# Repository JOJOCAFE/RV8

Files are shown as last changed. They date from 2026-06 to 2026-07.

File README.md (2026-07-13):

# RV8 Project: Minimal 8-bit RISC-V Style CPU Family

Build real computers from 74HC chips. Run BASIC. Play games.

---

## The Family

| | **RV8** | **RV8-R** | **RV8-G** | **RV8-GR** |
|--|:---:|:---:|:---:|:---:|
| **Logic chips** | 28 | **49 FullHW** | **38** | **34** |
| **Total** | 31 | 53 | 40 | 36 |
| **MIPS @5MHz** | 1.25 | 1.0 | **2.5** | **0.33*** |
| **ISA** | Full target, not frozen | FullHW RV8-style surface | Full (35) | 18 instr |
| **Microcode** | Yes | Yes | **No** | **No** |
| **AND/OR/XOR** | ✅ | ✅ | ✅ | XOR only |
| **64K address** | ✅ | ✅ | ✅ | ✅ |
| **ROM-first boot** | ✅ | ✅ | ✅ | **✅** |
| **Games** | ✅ | ✅ | ✅ | ✅ |
| **Verilog verified** | ⚠️ behavioral only / benches need cleanup | ⚠️ old-map RTL pass; frozen-map pending | ⬜ | **✅** |

\* RV8-GR: official student baseline is 1 MHz breadboard. 0.33 MIPS @ 1 MHz.

---

## Which to build?

| Priority | Build |
|---|---|
| **Learn microcode / experimental reference** | **RV8** (28 chips target, not build-ready) |
| **Full RV8-style ISA with real TTL paths** | **RV8-R FullHW** (49 logic chips, KiCad/RTL proof pending) |
| **Full ISA + no microcode concept** | **RV8-G** (38 logic chips, no active folder) |
| **Student-friendly no-microcode build** | **RV8GR** (34 logic chips) |

### RV8GR Student Baseline

RV8GR is the active physical-build target.

- 34 logic chips + ROM + RAM = 36 packages.
- Components package mapping checked: 36 board packages resolve to 16
  board-used part types, all backed by current Components definitions and
  package-local test records.
- No microcode ROM.
- No hardware IRQ vector; IRQ is a polling latch only.
- Every instruction uses T0, T1, T2.
- Build one module, test it, then continue.
- Start with `RV8GR/doc/labs/README.md` for student labs.
- Use `RV8GR/doc/01_wiring_guide.md` as the official pin-level source.
- Latest lab/doc pass keeps U34 as the 74HC541 IRL-to-IBUS immediate buffer,
  ROM as `ROM1`, and RAM as `RAM1`.
- Physical speed/signoff is still blocked until real voltage, clock,
  bus-deadband, memory float/write timing, and scope evidence are logged.

### RV8 vs RV8-R Analysis

| Area | RV8 | RV8-R |
|---|-----|---|
| Current role | Exploratory microcoded reference | FullHW full-ISA TTL path candidate |
| Chip-count confidence | ⚠️ Docs disagree between 27/28/31 package claims | ✅ FullHW count documented as 49 logic / 53 total |
| ISA confidence | ⚠️ Full 35-instruction target, but generator contains simplified/skipped operations | ✅ FullHW gives real paths for ALU logic, stack, IRQ, and IRET; `SRL` remains software macro |
| Verification | ⚠️ Behavioral Verilog exists; microcode benches need cleanup before claiming pass | ⚠️ FullHW docs updated; RTL/testbench/microcode generator migration pending |
| Microcode tools | ⚠️ Generator exists but has simplified branch/addressing/logic paths | ⚠️ Existing generator is legacy 14-bit; FullHW needs 15-bit direct-control generator |
| Wiring | ⚠️ Pin-level guide exists but is tied to stale chip-count/control assumptions | ✅ FullHW wiring paths documented; Programmer/RV8-Bus pin audit still required |
| Build readiness | Not ready for student physical build | Not ready for physical build until KiCad/ERC and sim proof |

**Decision:** keep RV8 as a learning/reference branch, but do not present it as proven. Use RV8-R FullHW when the goal is to make the full RV8-style ISA real in TTL, and use RV8GR when the goal is a student-buildable physical CPU today.

---

## Project Structure

```
RV8/
├── RV8/            ← 28-chip target, hardware regs, microcode, IRQ (exploratory)
├── RV8R/           ← 49-chip FullHW target, RAM regs, microcode, IRQ (full RV8-style hardware)
├── RV8GR/          ← active 34-logic-chip student baseline, labs, wiring, sim, RTL
├── Programmer/     ← ESP32 board; per-CPU bus/pin audit required
├── Old_Design/     ← Archived
├── Reference/      ← Gigatron, SAP-1, Nand2Tetris
└── README.md
```

`RV8-G` is retained as a documented concept/history item, not as an active
folder in this checkout.

---

## Shared Across All

- **RV8-Bus**: 40-pin system bus target (A[15:0] + D[7:0] + CLK + /WR + /RD + /IRQ + /SLOT)
- **Programmer**: ESP32-WROOM-32 + TXS0108E (flash + terminal); compatibility must be checked per CPU wiring guide
- **Registers**: Variant-specific RAM window. RV8R freezes `r0-r7` at `$FFF8-$FFFF`; RV8GR uses its own data-page model.
- **RISC-V naming**: ADD, SUB, LB, SB, BEQ, J

---

## Status

| | RV8 | RV8-R | RV8-G | RV8-GR |
|--|:---:|:---:|:---:|:---:|
| Instruction trace | ✅ | ✅ | ⬜ | ✅ |
| Verilog | ⚠️ benches need cleanup | ⚠️ old-map RTL passed; FullHW RTL pending | ⬜ | ✅ (behavioral + chip-level TBs, 512 opcode sweep) |
| Wiring guide (pin-level) | ⚠️ stale assumptions | ✅ FullHW paths documented | ⬜ | ✅ |
| Module guide (Thai) | ✅ | ⬜ | ⬜ | ✅ |
| ISA reference | ⚠️ target ISA, not fully proven | ✅ FullHW encoding + hardware paths | ⬜ | ✅ |
| Assembler | ⬜ | ⬜ | ⬜ | ✅ (page-safe) |
| Test ROM | ⬜ | ⬜ | ⬜ | ✅ |
| Hardware Labs | ⬜ | ⬜ | ⬜ | ✅ (14 labs + student baseline contract) |
| KiCad modules | ⬜ | ⬜ | ⬜ | ✅ (6 modules) |
| Student build guardrails | ⬜ | ⬜ | ⬜ | ✅ |
| Components package mapping | ⬜ | ⬜ | ⬜ | ✅ (36 packages -> 16 part types) |
| Programmer | ⚠️ needs bus/pin audit | ⚠️ needs bus/pin audit | ⚠️ needs bus/pin audit | ✅ |
| Physical build | ⬜ | ⬜ | ⬜ | ⬜ |

### Latest RV8GR Checkpoint

As of 2026-07-12, RV8GR release gates fail hard on behavioral Verilog or
wiring mismatches. The full external Components run passes the 16 part-type,
36-package audit and the whole-system virtual fault screen with no pin-truth,
edge-polarity, bus-contention, or propagation-deadband findings. Hardware
timing claims still require physical measurements on the real board.

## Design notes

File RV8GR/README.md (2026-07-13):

# RV8-GR — No Microcode, Full 64K, IRQ (Stable)

**34 logic chips + ROM + RAM = 36 packages. Verilog verified.**

---

## Student Baseline Contract

This is the build target for RV8GR. Do not add future features while
building the baseline CPU.

- **34 logic chips + ROM + RAM = 36 packages**
- **No microcode ROM**
- **No hardware IRQ vector**: IRQ is a polling latch only
- **Every instruction is 3 phases**: T0 fetch opcode, T1 fetch operand, T2 execute
- **Only one IBUS driver may be active at a time**
- **Only one DBUS driver may be active at a time**
- **Build one module, test it, then continue**

Recommended reading order:

| Role | Start here | Use for |
|---|---|---|
| Student | `doc/labs/README.md` | Lab-by-lab physical build |
| Teacher | `doc/build_plan/01_student_incremental_build_plan.md` | Supervised stage plan |
| Wiring | `doc/01_wiring_guide.md` | Official pin-level source of truth |
| Debug | `doc/05_debug_plan.md` | Probe points and fault tracing |
| KiCad | `doc/06_kicad_modules.md` | Schematic sheet/module split |
| CPU logic test | `doc/08_cpu_logical_test_protocol.md` | Virtual CPU behavior and program regression |
| Equivalence | `doc/11_four_model_equivalence.md` | Why two Python sims and two Verilog models must agree |
| Doc audit | `doc/12_doc_integrity_audit.md` | Integrity check of every doc file against Python/Verilog truth |
| BASIC ROM test | `doc/13_basic_min_rom.md` | B-011 phase 1 BASIC-style ROM smoke test |

---

## Specs

| Spec | Value |
|---|---|
| Logic chips | 34 (74HC series, DIP) |
| Total packages | 36 (34 logic + ROM + RAM) |
| ISA | 18 instructions |
| Clock | 1 MHz breadboard baseline; 5 MHz PCB-only measured experiment |
| Speed | 333K instr/sec @ 1 MHz |
| Gate count | ~1,260 (logic only, excl. ROM/RAM) |
| Address | 64KB (ROM $0000-$7FFF, RAM $8000-$FFFF) |
| Bus | RV8-Bus 40-pin (A16+D8+control) |
| Registers | 8 in RAM ($8000-$8007 via DP=$80) |
| ALU | ADD, SUB, XOR |
| Jump | 16-bit (Page Register) |
| Execute RAM | Yes (PC ≥ $8000) |
| IRQ | v1.0: polling latch; hardware vector is future/unfrozen |

---

## ISA (18 instructions)

```
$00  NOP         $01  J addr       $02  BEQ addr
$04  SB addr     $08  EI           $10  ADDI imm
$18  ADD rs      $20  SETPG imm    $28  SETPG_R rs
$30  LI imm      $38  LB rs        $40  SETDP imm
$48  DI           $70  XORI imm    $78  XOR rs
$82  BNE addr    $90  SUBI imm     $98  SUB rs
```

Encoding: `[7]SUB [6]XOR [5]MUX [4]AC_WR [3]SRC [2]STR [1]BR [0]JMP`

Note: `$48 DI` is encoded as one of the 18 mnemonics, but is reserved/inert in v1.0; IE clears only on reset.

Assembler pseudo-instructions such as `NOT` do not add hardware opcodes. `NOT`
emits `XORI $FF` and is covered by Python and Verilog ROM tests.

---

## BOM — Complete Order List

### Logic (34 packages)

| Part | Qty | Package | Notes | Status |
|---|:---:|:---:|---|:---:|
| 74HC161 | 4 | 16DIP | PC counter | ✅ |
| 74HC574 | 5 | 20DIP | IR, AC, PG, DP | ✅ |
| 74HC245 | 1 | 20DIP | Bus buffer | ✅ |
| 74HC164 | 1 | 14DIP | Ring counter | ✅ |
| 74HC283 | 2 | 16DIP | Adder | ✅ |
| 74HC86 | 3 | 14DIP | XOR | ✅ |
| 74HC541 | 2 | 20DIP | AC buffer + IRL immediate buffer | ✅ |
| 74HC157 | 8 | 16DIP | Muxes | ✅ |
| 74HC74 | 2 | 14DIP | Z flag, IRQ | ✅ |
| 74HC688 | 1 | 20DIP | Zero detect | ✅ |
| 74HC04 | 1 | 14DIP | Inverters | ✅ |
| 74HC32 | 1 | 14DIP | OR gates | ✅ |
| 74HC00 | 2 | 14DIP | NAND gates | ✅ |
| 74HC21 | 1 | 14DIP | SETDP decode | ✅ |

### Memory

| Part | Qty | Notes | Status |
|---|:---:|---|:---:|
| AT28C256-70 or SST39SF010A-70 | 1 | ROM 32KB, 70ns | waiting |
| 62256-70 (or AS6C62256) | 1 | RAM 32KB, 70ns | waiting |

### Clock & Reset

| Part | Qty | Notes | Status |
|---|:---:|---|:---:|
| 1 MHz 5V CMOS oscillator module | 1 | Baseline breadboard clock | waiting |
| 5 MHz 5V CMOS oscillator module | optional | PCB/wire-wrap experiment only | waiting |
| 74HC14 Schmitt inverter | 1 | Clock/reset buffering | waiting |
| 10kΩ resistor | 1 | Reset pull-up | waiting |
| 10µF capacitor | 1 | Reset RC | waiting |
| Push button (NO) | 1 | Reset button | waiting |

### Passives & Debug

| Part | Qty | Notes | Status |
|---|:---:|---|:---:|
| 100nF capacitor (ceramic) | 35 | Bypass (1 per chip) | waiting |
| 10µF capacitor | 2 | Power filter | waiting |
| 330Ω resistor | 8 | LED current limit | waiting |
| LED 3mm green | 8 | Bus probe | waiting |
| LED 3mm red | 1 | Power | waiting |
| DIP switch 8-bit | 1 | Debug input | waiting |

### Breadboard & Wiring

| Part | Qty | Notes |
|---|:---:|---|
| Full-size breadboard (830pt) | 5 | Layout below |
| Jumper wire kit (M-M) | 1 | 65pc assorted |
| 22AWG solid wire (6 colors) | 1 set | Bus wiring |
| 40-pin IDC socket + ribbon | 1 | RV8-Bus |
| USB 5V breadboard PSU | 1 | Power supply |

---

## Breadboard Layout (5 boards)

```
Board 1: TIMING          Board 2: MEMORY         Board 3: ALU
┌──────────────────┐    ┌──────────────────┐    ┌──────────────────┐
│ U8  U24          │    │ U15 U16 U29 U30 │    │ U5 U6 U34 U14  │
│ U1  U2  U3  U4  │    │ ROM         RAM  │    │ U19 U20         │
│ Osc     Reset    │    │ U7               │    │ U12 U13         │
└──────────────────┘    └──────────────────┘    │ U10 U11         │
  6 chips                 7 chips               └──────────────────┘
                                                  9 chips

Board 4: CONTROL         Board 5: BUS + DEBUG
┌──────────────────┐    ┌──────────────────┐
│ U17 U18 U9      │    │ 40-pin IDC       │
│ U21 U22 U23     │    │ 8× LED probe     │
│ U25 U26 U27 U28│    │ DIP switch       │
│ U31 U32 U33     │    │ Power rails      │
└──────────────────┘    └──────────────────┘
  12 chips                Debug tools
```

### Wiring Color Convention

| Color | Signal |
|---|---|
| Red | VCC (+5V) |
| Black | GND |
| Yellow | DBUS D[7:0] |
| Blue | IBUS IB[7:0] |
| Green | ABUS A[15:0] |
| White | Control |
| Orange | Clock/Timing |

---

## Verification

Run these checks before using the docs for a build session. Python checks are
the student-friendly first pass because they catch wiring and behavior errors
without requiring HDL tools:

```bash
cd RV8GR

python3 -B sim/chip_sim.py
# ALL 8 CPU TESTS PASSED

python3 -B sim/components_chip_sim.py
# ALL 8 COMPONENTS-BACKED CPU TESTS PASSED

python3 -B sim/test_cpu_logical_protocol.py
# protocol unittest suite passes on both Python CPU simulators

python3 -B sim/test_basic_min.py
# B-011 BASIC-style ROM smoke passes on both Python CPU simulators

python3 -B tools/check_python_verilog_equivalence.py
# both Python CPU simulators match both Verilog CPU models on all_isa_equivalence.asm

python3 -B sim/verify_wiring.py
# ALL WIRING VERIFIED

python3 -B sim/soft_debug.py
# ALL TESTS PASSED

python3 -B tools/test_rv8gr_asm.py
# 11 passed

python3 -B sim/chips/test_chips.py
# ALL 14 CHIP TYPES VERIFIED

python3 -B sim/verify_components.py
# RV8GR Components verification passed: 16 part types, 36 packages
```

To verify against the current external Components library rather than the
vendored compatibility snapshot:

```bash
cd RV8GR
COMPONENTS_ROOT=/home/jo/kiro/Components python3 -B sim/verify_components.py
# RV8GR Components verification passed: 16 part types, 36 packages
```

Run the reusable Components virtual physical checker from the Components repo.
This checks the RV8GR whole-system virtual circuit for pin mistakes, active-low
mistakes, unsafe output-output wiring, and documented timing/noise risks:

```bash
cd /home/jo/kiro/Components
PYTHONPATH=python python3 -B -m chiplib.cli circuit-faults examples/circuits/RV8GR_WholeSystemChipLevelVirtual/circuit.json
# pass: no pin-truth, edge-polarity, output-contention, or deadband findings
```

This virtual check passed against the current external Components checkout on
2026-07-12. It is a model-level gate only; it does not replace physical-board
measurements for reset release, bus turnaround, memory timing, or voltage
margin.

Use Verilog as the secondary HDL/RTL comparison path:

```bash
cd RV8GR
COMPONENTS_ROOT=/home/jo/kiro/Components tools/run_all_verilog_tb.sh
# behavioral, opcode sweep, SETDP, task, IRQ, chip-level, and dual-compare
# benches pass; detected behavioral mismatches exit nonzero
```

The behavioral `rtl/rv8gr_cpu.v` benches are only a comparison path. RV8GR
Verilog signoff must include the TTL-chip system:

- `rtl/rv8gr_chip_level.v` is the chip-level netlist.
- `tools/run_chip_level_verilog.sh` and
  `tools/run_chip_level_full_verilog.sh` compile it with the Components
  `ttl_74hc*`, `62256`, and `at28c256` Verilog models.
- `tools/run_dual_verilog_compare.sh` runs `rv8gr_cpu.v` and
  `rv8gr_chip_level.v` on the same ROM program and compares architectural
  checkpoints: `PC`, `AC`, `Z`, `PG`, `DP`, `IE`, `IRQ_FF`, and key RAM
  writes. This dual bench covers every frozen ISA command at least once,
  including jump/branch, ALU, memory, page/data-page control, and IRQ polling.
- `programs/all_isa_equivalence.asm` is the shared all-ISA source for this
  comparison. Verilog assembles it to `.memh`; Python assembles the same source
  in memory through `tools/check_python_verilog_equivalence.py`.
- `tb_rv8gr_dual_compare.v` exports `VERILOG_CHECKPOINT` lines, and
  `tools/check_python_verilog_equivalence.py` verifies both Python CPU sims
  match that checkpoint stream, final state, and RAM checkpoints.
- `sim/components_chip_sim.py` is a Components-backed adapter runner for the
  same RV8GR Python CPU logic, not a separate net-level Python CPU algorithm.
- Do not replace this signoff with an optimized gate/behavioral model.

Generated Verilog artifacts default to `/tmp/rv8gr-verilog`. Set
`RV8GR_BUILD_DIR=/path/to/output` if you need a different generated-output
directory.

Virtual checks, Python simulation, and Verilog comparison are not physical
signoff. Physical signoff still requires the real board to show correct power
rails, reset, clock, bus ownership, ROM/RAM behavior, a 1 MHz baseline
full-system run, burn-in stability, and timing evidence from probes or a logic
analyzer. A 5 MHz result is optional PCB-only experiment evidence, never a
replacement for the 1 MHz breadboard baseline.

---

## Files

```
RV8GR/
├── rtl/
│   └── rv8gr_cpu.v             Verilog (all tests pass)
├── tb/
│   ├── tb_rv8gr_full.v         Full ISA testbench (127 cycles)
│   ├── tb_rv8gr_irq.v          IRQ testbench (6 tests)
│   ├── tb_rv8gr_tasks.v        Milestone tests
│   └── tb_rv8gr_asm.v          Assembled binary loader
├── tools/
│   ├── rv8gr_asm.py            Assembler
│   └── test_rv8gr_asm.py       Assembler tests
├── programs/
│   ├── test_all.asm            Full ISA test
│   ├── test_isa.asm            ISA subset test
│   ├── testrom.asm             Test ROM image
│   └── countdown.asm           Demo program
├── sim/
│   └── gate_sim.py             Python gate-level simulation
└── doc/
    ├── 00_design_isa.md        Design + ISA reference
    ├── 01_wiring_guide.md      SOURCE OF TRUTH (wiring)
    ├── 02_instruction_trace.md Pin-level traces
    ├── 03_bank_switch.md       Memory expansion
    ├── 04_understand_by_module.md  Thai tutorial
    ├── 05_debug_plan.md        Physical build debug steps
    ├── 06_kicad_modules.md     KiCad sheet/module split
    ├── 07_real_build_timing_log.md  Physical evidence log
    ├── 08_cpu_logical_test_protocol.md  CPU logical verification
    ├── 09_future_upgrades.md   Future-only feature parking lot
    ├── 10_netlist.md           Text netlist
    ├── 11_four_model_equivalence.md Student equivalence guide
    └── 12_doc_integrity_audit.md Maintainer doc audit
```

---

## Status

| Item | Status |
|---|:---:|
| Wiring guide (pin-level) | ✅ |
| Verilog (full ISA + IRQ) | ✅ |
| Assembler (Python) | ✅ |
| Test ROM (.bin) | ✅ |
| BOM (parts list) | ✅ |
| Programmer tools | ✅ |
| Physical build | ⬜ |

---

## Roadmap

| # | Task | Status |
|:-:|---|:---:|
| 1 | Assembler | ✅ |
| 2 | Test ROM | ✅ |
| 3 | Parts list | ✅ |
| 4 | Design sign-off | ✅ |
| 5 | Programmer tools | ✅ |
| 6 | Gate-level simulator | ✅ |
| 7 | Breadboard layout plan | ✅ |
| 8 | Order parts | ⬜ |
| 9 | Physical build (1 MHz) | ⬜ |
| 10 | Verify at 1-2 MHz | ⬜ |
| 11 | BASIC interpreter | ⬜ |
| 12 | Simple game | ⬜ |

### Task 6: Gate-Level Simulator ✅

All 36 chips simulated pin-by-pin. 8 CPU tests + 11K wiring checks pass.

```
sim/
├── chips/__init__.py       — 34 logic chip models + ROM/RAM
├── chips/test_chips.py     — 141 test vectors (14 chip types)
├── chip_sim.py             — Full CPU simulation + timing analysis
├── soft_debug.py           — High-level trace (4 tests)
├── gate_sim.py             — Simplified educational sim
├── verify_wiring.py        — Pin-level wiring checker (11K+ checks)
├── wiring.py               — 247 pin connections (01_wiring_guide)
└── sim_lab/lab01-14.py     — 14 step-by-step labs
```

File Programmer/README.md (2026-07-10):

# Programmer Board — ESP32-WROOM-32

**One board, two modes**: program ROM via RV8-Bus (in-system) OR via ZIF socket (standalone).

---

## Overview

```
                                           ┌─────────────────────┐
                                      ┌──→ │ RV8-Bus (40-pin)    │ → CPU Board
                                      │    └─────────────────────┘
PC ←USB→ [ESP32] ←→ [TXS ×2] ←→ [595 ×2]┤
                                      │    ┌─────────────────────┐
                                      └──→ │ AT28C256 (ZIF 28)   │ → ถอดไปเสียบบอร์ด
                                           └─────────────────────┘

Use ONE at a time: Bus cable OR ROM in ZIF (never both!)
```

---

## Two Modes

### Mode A: ZIF Direct (program bare ROM chip)

1. ❌ Disconnect Bus cable
2. Insert ROM into ZIF socket → lock
3. `python3 tools/rv8flash.py -w program.bin`
4. `python3 tools/rv8flash.py -v program.bin`
5. Remove ROM → plug into CPU board

### Mode B: RV8-Bus (program in-system)

1. ❌ ZIF empty (no ROM inserted)
2. Connect Bus cable to CPU board
3. Switch → PROG: `python3 tools/rv8flash.py -w program.bin`
4. Switch → RUN: `python3 tools/rv8term.py` (terminal)

---

## Hardware

| Part | Qty | Function |
|---|:---:|---|
| ESP32-WROOM-32 | 1 | Controller (USB-serial, GPIO) |
| TXS0108E module | 2 | Level shift 3.3V ↔ 5V |
| 74HC595 | 2 | Shift register → address A[14:0] |
| ZIF socket 28-pin | 1 | Insert/remove ROM |
| 40-pin IDC header | 1 | RV8-Bus connector |
| SPDT switch | 1 | PROG/RUN mode |
| 10K resistors | 3 | Pull-ups (/CE, /OE, TXS OE) |
| 100nF caps | 7 | Bypass |

---

## Bus Pinout (matches RV8GR)

```
pin 1-16:  A[0:15]
pin 17-24: D[0:7]
pin 25:    CLK
pin 26:    /RST
pin 27:    /WR
pin 28:    /RD
pin 29:    /IRQ
pin 30:    /SLOT1
pin 39:    VCC
pin 40:    GND
```

---

## Files

```
Programmer/
├── KICAD/              ← KiCad project (schematic + PCB)
├── RV8Programmer.pdf   ← schematic PDF export
├── RV8Programmer.svg   ← schematic SVG export
├── schematic.md        ← pin-level wiring (Thai, matches KiCad)
├── firmware/
│   ├── firmware.ino    ← ESP32 Arduino firmware
│   └── bootloader.asm  ← ROM bootloader (for RAM-boot mode)
└── tools/
    ├── rv8flash.py     ← flash/verify ROM
    ├── rv8term.py      ← UART terminal (RUN mode)
    └── rv8ram-boot.py  ← upload to RAM via bootloader
```

---

## Software Commands

```bash
# Flash ROM
python3 tools/rv8flash.py -w program.bin
python3 tools/rv8flash.py program program.bin --base 0x0000

# Verify ROM
python3 tools/rv8flash.py -v program.bin
python3 tools/rv8flash.py verify program.bin --base 0x0000

# Terminal (RUN mode)
python3 tools/rv8term.py

# Upload to RAM (requires bootloader in ROM)
python3 tools/rv8ram-boot.py program.bin
```

## Field Test Protocol

Before using the Programmer on real RV8GR hardware, run the field procedure in
`FIELD_TEST_PROTOCOL.md`. The current virtual preflight is 51 mock tests:

```bash
python3 -B tools/test_rv8flash.py
python3 -B tools/test_rv8term.py
python3 -B tools/test_rv8ram-boot.py
```

The field protocol separates ZIF Direct testing from RV8-Bus in-system testing
and records the evidence needed to close B-012.

---

## Safety

| ⚠️ Never connect BOTH Bus cable AND ROM in ZIF at the same time! |
|:---:|
| Data bus fight → chip damage |

During normal CPU runtime, ROM `/WE` must stay inactive. The Programmer may own
the ROM write path only in PROG mode with the CPU stopped, or when a bare ROM is
installed in the ZIF socket.

AT28C256 note: current firmware performs normal byte write cycles. Use ROM chips
with software data protection disabled, or add/enable an SDP unlock sequence
before relying on protected AT28C256 parts.

---

## Status

- ✅ KiCad schematic (verified, GPIO 16↔17 swap applied)
- ✅ Firmware (matches schematic pin assignments)
- ✅ Tools (protocol matches firmware)
- ✅ Schematic doc (Thai, Bus + ZIF, matches KiCad)
- ✅ Virtual preflight defined (51 mock tests passing on 2026-07-10)
- ⬜ Field-test evidence (see `FIELD_TEST_PROTOCOL.md`)
- ⬜ Physical build
- ⬜ PCB fabrication

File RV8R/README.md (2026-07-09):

# RV8-R — Minimal RISC-V with RAM Registers

**FullHW target: 49 logic chips. RV8-style ISA. 8 registers in RAM. Microcode ROM. 5 MHz.**

---

## Specs

| Spec | Value |
|---|---|
| Logic chips | 49 FullHW target |
| Total packages | 53 FullHW target (+ 2 microcode ROM + 1 program ROM + 1 RAM) |
| ISA | RV8-style full hardware surface; `SRL` remains software macro, `LUI` assembler pre-shift |
| Registers | 8 in RAM at `$FFF8-$FFFF` |
| Reset PC | `$0000` |
| Boot source | Program ROM first (`$0000-$7FFF`) |
| Clock | 5 MHz |
| Cycles/instr | 4-6 average |
| MIPS | 0.8-1.25 |
| Address space | 64KB (32K ROM + 32K RAM) |
| Execute from RAM | ✅ optional at `$8000-$FFFF` after ROM boot |
| Microcode | 2× ROM, 15-bit address with IRQ bank and 4-bit step |
| ALU | ADD, SUB, AND, OR, XOR, SLL, SLT/SLTI via carry/borrow path |
| Standalone boot | ✅ reset clears PC to `$0000`, first fetch is ROM |
| Programmable ISA | ✅ (change microcode ROM) |
| Interrupts | ✅ `/IRQ`, `EI`, `DI`, `IRET`, fixed vector `$7F00` in frozen architecture |
| Target | BASIC + video games |

---

## Roadmap (RV8-GR style)

| # | Task | Status |
|:-:|---|:---:|
| 1 | Architecture design | ✅ |
| 2 | ISA encoding (2-byte) | ✅ |
| 3 | Microcode format + control word | ✅ Frozen 15-bit address / 16-bit direct-control contract |
| 4 | Chip list + pin wiring | ✅ real FullHW paths documented; KiCad proof pending |
| 5 | Verilog model | ⚠️ needs migration to frozen ROM-low/RAM-high map |
| 6 | Testbench | ⚠️ old `$8000` reset map passed; frozen map test pending |
| 7 | Assembler (Python) | ⬜ |
| 8 | Microcode generator (Python) | ⚠️ legacy 14-bit prototype; FullHW 15-bit generator pending |
| 9 | Gate-level simulation (sim_lab) | ⬜ |
| 10 | Documentation (Thai tutorial) | ⬜ |
| 11 | Programmer integration | ⬜ needs RV8-Bus pin audit |
| 12 | Physical build | ⬜ |
| 13 | BASIC interpreter | ⬜ |
| 14 | Video game | ⬜ |

Task details are tracked in `doc/03_fullhw_task_plan.md`.

---

## Architecture (Prototype)

```
┌──────────────┐     ┌──────────────┐
│ Microcode ROM│     │ Program ROM  │
│ AT28C256     │     │ AT28C256     │
│ 70ns         │     │ 70ns         │
│              │     │              │
│ Addr={op,stp}│     │ Addr=PC      │
│ Data=ctrl_wd │     │ Data=instr   │
└──────┬───────┘     └──────┬───────┘
       │ control word        │ instruction
       ▼                     ▼
┌────────────────────────────────────┐
│              CPU Datapath           │
│                                    │
│  PC(161×4) → Addr Mux → ABUS      │
│  DBUS ←→ RAM(CY7C199) ← registers │
│  IR(574) ← DBUS                   │
│  ALU(283+86) ← IBUS               │
│  Step(161) → Microcode addr        │
└────────────────────────────────────┘
```

### Memory Map

```
Reset PC = $0000. The CPU always boots from Program ROM first.

$0000-$7FFF  Program ROM (boot, monitor, BASIC, game cartridge)
$7F00-$7FFF  ROM monitor / IRQ handler area
$8000-$FEFF  RAM data, buffers, optional RAM-loaded program
$FF00-$FFF5  RAM stack / fast page
$FFF6-$FFF7  RAM IRQ saved PC low/high
$FFF8-$FFFF  RAM registers r0-r7
```

### Microcode ROM Address

```
Address[14:0] = {irq_active, flag_C, flag_Z, step[3:0], opcode[7:0]}
Data[15:0] = direct control word from two microcode ROMs
```

### Key Design Decisions

1. **Registers in RAM** — saves 8 chips (no 574×8), costs 1-2 extra cycles
2. **3 ROM chips** — two microcode ROMs plus one program ROM (no time-mux needed)
3. **Same RAM as RV8-GR** — 62256 or CY7C199 (pin-compatible)
4. **RV8-Bus-like structure** — Programmer reuse is not frozen until pin audit
5. **ROM-first standalone boot** — reset clears PC to `$0000`; ROM occupies the lower half like RV8GR
6. **RV8-style ISA** — real FullHW paths for the full target surface; `SRL` stays a software macro
7. **Microcode in ROM** — programmable ISA, just swap ROM chip

### Chip List (FullHW Target)

| Module | Chips | Type |
|---|:-----:|---|
| PC + step | 5 | 4× 74HC161 PC, 1× 74HC161 step[3:0] |
| IR/latches/registers | 7 | opcode, operand, ALU_B, result, address low/high, halt |
| ALU arithmetic/logic | 12 | add/sub, AND, OR, XOR, result mux |
| Address/PC routing | 14 | address-source muxes, ABUS muxes, PC-to-IBUS buffers |
| Bus/memory bridge | 1 | 74HC245 |
| Flags/IRQ/SYS/gates | 10 | flags, IE/IRQ, SYS decode, r0 guard, enable gates |
| **Logic total** | **49** | |
| Microcode ROM | 2 | AT28C256-70 / SST39SF010 |
| Program ROM | 1 | AT28C256-70 |
| RAM | 1 | CY7C199-15PC (or 62256-70) |
| **Grand total** | **53 packages** | |

---

## Comparison

| | RV8 | **RV8-R** | RV8-GR |
|--|:---:|:---:|:---:|
| Logic chips | 27 | **49 FullHW** | 33 |
| Total packages | 31 | **53 FullHW** | 35 |
| ISA | 35 (RISC-V) | **RV8-style subset/prototype** | 18 (custom) |
| Registers | 8 hardware | **8 in high RAM** | 1 (AC) |
| Microcode | ✅ (Flash) | **✅ (ROM)** | ❌ |
| Clock | 5 MHz | **5 MHz** | 5 MHz |
| MIPS | 1.0-1.4 | **0.8-1.25** | 1.67 |
| Programmable ISA | ✅ | **✅** | ❌ |
| ROM-first boot | ✅ | **✅** | ✅ |
| BASIC + Games | ✅ | **✅** | ✅ |
| Fewest chips? | ❌ | ❌ FullHW favors real full-ISA paths | ❌ |

---

## Status

- ✅ Architecture concept and ISA encoding drafted
- ⚠️ Behavioral Verilog core + IRQ test passed on the previous `$8000` reset map; RTL/testbench migration to this frozen map is pending
- ⚠️ Legacy microcode generator still uses 14-bit prototype output; FullHW needs a 15-bit direct-control generator
- ✅ FullHW control word is frozen in `doc/00_design.md`; safe default is `0x028D`
- ✅ FullHW chip/pin paths are now concrete in `doc/02_wiring_guide.md`
- ⚠️ Chip count is now 49 logic / 53 packages for the full-ISA hardware path
- ✅ `SLT`, `SLTI`, `PUSH`, `POP`, IRQ, and IRET have real hardware paths in FullHW; RTL/KiCad proof is pending
- ⬜ Assembler, pin-level final wiring, gate-level sim, Programmer pin audit, Thai tutorial, and physical build

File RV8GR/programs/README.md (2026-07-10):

# RV8GR Example Programs

These examples are source-only `.asm` programs for the current RV8GR assembler.
They avoid unsupported pseudo devices and use only the existing accumulator,
RAM/register aliases, page registers, branches, and memory-mapped load/store.

Assemble from `RV8GR/`:

```bash
python3 tools/rv8gr_asm.py programs/blink.asm -o /tmp/rv8gr-blink.bin
python3 tools/rv8gr_asm.py programs/counter.asm -o /tmp/rv8gr-counter.bin
python3 tools/rv8gr_asm.py programs/echo.asm -o /tmp/rv8gr-echo.bin
python3 tools/rv8gr_asm.py programs/basic_min.asm -o /tmp/rv8gr-basic-min.bin
```

## Programs

| File | Purpose | Notes |
|---|---|---|
| `blink.asm` | Alternates `$55` and `$AA` on memory-mapped output `$FF10`. | Requires an external device on I/O slot 1 to make the pattern visible; otherwise it still exercises `SETDP`, `SB`, and branch delays. |
| `counter.asm` | Counts from `$00` to `$0F`, mirrors each value to RAM `$8010`, and writes the same value to `$FF10`. | Final count `$10` is stored at RAM `$8011` before halt. |
| `echo.asm` | Closest supported echo equivalent: seeds a RAM input buffer and copies it to a RAM output buffer. | RV8GR v1.0 has no UART instruction or indirect indexed addressing, so the copy is intentionally fixed-size and unrolled. |
| `basic_min.asm` | B-011 phase 1 BASIC-style ROM runtime smoke. | Non-interactive by design: writes PRINT transcript `1,2,3` to RAM `$8040-$8042`, pass marker `$42` to `$8043`, and mirrors PRINT values to `$FF10`. |

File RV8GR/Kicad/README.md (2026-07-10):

# RV8GR KiCad Project

Generated on 2026-07-09

## Files

| File | Description |
|---|---|
| RV8GR.kicad_pro | Project file |
| RV8GR.kicad_sch | Top-level schematic |
| CLK_RST.kicad_sch | Clock, Reset, Ring Counter (U8) |
| PC.kicad_sch | Program Counter (U1-U4) |
| ADDR_MEM.kicad_sch | Address Mux + ROM + RAM (U15-U16, U29-U30) |
| IR_BUF.kicad_sch | Instruction Register + Bus Buffers (U5-U7, U14, U34) |
| ALU_AC.kicad_sch | ALU + Accumulator + Z Flag (U9-U22) |
| CTRL.kicad_sch | Control Logic (U23-U28, U31-U33) |
| RV8GR.net | Current KiCad netlist generated from `gen_kicad.py` |
| RV8GR-CPU-paul.EDF | Current-baseline EDIF/EDF netlist generated from `gen_kicad.py` |
| RV8GR-CPU-paul.pdf | Current-baseline merged KiCad PDF export |

## Chip Summary

| Module | Chips | Count |
|---|---|---|
| CLK_RST | U8 (74HC164) | 1 |
| PC | U1-U4 (74HC161) | 4 |
| ADDR_MEM | U15, U16, U29, U30 (74HC157) + ROM + RAM | 6 |
| IR_BUF | U5, U6 (74HC574), U7 (74HC245), U14, U34 (74HC541) | 5 |
| ALU_AC | U9 (574), U10-U11 (283), U12-U13 (86), U17-U20 (157), U21 (74), U22 (688) | 11 |
| CTRL | U23 (574), U24 (04), U25 (32), U26-U27 (00), U28 (86), U31 (74), U32 (574), U33 (21) | 9 |
| **Total** | | **36** |

## ERC Status

`kicad-cli sch erc RV8GR.kicad_sch` currently reports 57 errors. They are all
expected dangling-label issues for this generated top-level scaffold:

1. **Unconnected pins** - All symbol pins need explicit net labels or wire connections
2. **Hierarchical label mismatch** - Top-level sheet symbols need to be created with matching pins
3. **Missing connections** - Internal wiring between chips not yet drawn

## Next Steps

To complete the schematic:

1. **Add hierarchical sheet symbols** on the top-level schematic
2. **Add net labels** to all chip pins according to the wiring guide
3. **Connect power pins** (VCC/GND) to power symbols
4. **Add bypass capacitors** near each chip's power pins
5. **Create the RV8-Bus connector** (40-pin IDC header)
6. **Run ERC again** and fix remaining issues

## Net Names (from wiring guide)

### Buses
- IBUS[7:0] - Internal data bus
- DBUS[7:0] - Memory data bus
- ABUS[15:0] - Address bus

### Control Signals
- CLK, /RST - System clock and reset
- T0, T1, T2 - Phase timing
- PC_INC, /PC_LD - Program counter control
- /ADDR_MODE - Address multiplexer select (LOW=data address, HIGH=PC)
- ACC_CLK - Accumulator clock
- /IRL_OE, /AC_BUF, BUF_OE_N, WR_DIR - Bus control

### Register Outputs
- PC[15:0] - Program counter
- IRL[7:0] - Instruction register low (operand)
- PG[7:0] - Page register
- DP[7:0] - Data page register
- AC[7:0] - Accumulator
- Z_flag - Zero flag

## Reference

See `doc/06_kicad_modules.md` for the six-sheet module split and
`doc/01_wiring_guide.md` for complete pin-level wiring truth.

## Current PDF/EDF Files

`RV8GR-CPU-paul.pdf` and `RV8GR-CPU-paul.EDF` now follow the current RV8GR
source-of-truth netlist: `U34` is the 74HC541 IRL-to-IBUS immediate buffer,
and memory is named `ROM1` and `RAM1`.

Regenerate the single-page top-level PDF from this directory with:

```bash
kicad-cli sch export pdf --black-and-white --output RV8GR-CPU-paul.pdf RV8GR.kicad_sch
```

The committed PDF is a merged export of the top-level page plus generated
module sheets.

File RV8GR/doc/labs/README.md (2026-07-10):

# RV8-GR Hardware Labs — สร้าง CPU จากศูนย์

**14 Lab sheets สำหรับน้อง ม.ต้น — ต่อวงจรทีละขั้น จนได้ CPU ที่ทำงานจริง**

---

## วิธีใช้

1. ทำทีละ Lab **ตามลำดับ** (ห้ามข้าม!)
2. ทุก Lab มี: อุปกรณ์ → ต่อวงจร → ทดสอบ → ✅ ผ่านแล้วค่อยไป Lab ถัดไป
3. ใช้ single-step clock (กดปุ่ม) ทดสอบ ก่อนใส่ oscillator module
4. ดู LED เพื่อเช็คว่าถูก

ใช้คู่กับเอกสารหลักเหล่านี้:

| เอกสาร | ใช้ทำอะไร |
|---|---|
| `../04_understand_by_module.md` | เข้าใจว่าแต่ละ module ทำหน้าที่อะไร |
| `../05_debug_plan.md` | ไล่ debug ตามจุดวัดและอาการเสีย |
| `../06_kicad_modules.md` | เทียบ Lab กับแผ่น KiCad/module |
| `../07_real_build_timing_log.md` | บันทึกผลวัดไฟ, clock, edge, bus race, propagation delay |
| `../build_plan/01_student_incremental_build_plan.md` | แผนครู/พี่เลี้ยงสำหรับ build ทีละ stage |

## ข้อตกลงของ baseline

- สร้างเฉพาะ baseline: 34 logic chips + ROM + RAM.
- ไม่มี microcode.
- ไม่มี hardware IRQ vector.
- IRQ เป็น polling latch เท่านั้น.
- ถ้าต่อสายทดลองชั่วคราวใน Lab ใด ต้องถอดออกก่อนต่อ Lab ถัดไป.

ถ้าอยากเพิ่ม feature เช่น hardware vector, ROM bank, RETI ให้ทำหลังจาก Lab
14 ผ่านแล้วเท่านั้น และต้องแยกเป็น upgrade document.

---

## Lab List

| Lab | ชื่อ | ชิป | ทดสอบอะไร |
|:---:|---|:---:|---|
| 01 | [ไฟเลี้ยง + นาฬิกา](lab01_power_clock.md) | — | VCC/GND, กดปุ่ม clock |
| 02 | [Ring Counter](lab02_ring_counter.md) | U8, U24 | T0→T1→T2 วน |
| 03 | [Program Counter](lab03_pc_counter.md) | U1-U4 | นับ 0,1,2,3... |
| 04 | [Address Mux](lab04_address_mux.md) | U15-U16, U29-U30 | เลือก PC หรือ IRL |
| 05 | [ROM อ่านค่า](lab05_rom_buffer.md) | ROM, U7 | อ่าน byte จาก ROM |
| 06 | [IR Latch](lab06_ir_latch.md) | U5, U6, U34 | จำคำสั่ง + เตรียม immediate buffer |
| 07 | [Adder/Subtractor](lab07_alu.md) | U10-U13 | บวก ลบ 8 บิต |
| 08 | [AC + Mux = Full ALU](lab08_accumulator.md) | U17-U20, U9, U14 | AC + XOR op |
| 09 | [Z Flag](lab09_z_flag.md) | U21, U22 | ตรวจจับ AC=0 |
| 10 | [Branch/Jump](lab10_branch_jump.md) | U24-U28 | J, BEQ, BNE |
| 11 | [Page Register](lab11_page_register.md) | U23 | SETPG + jump 16 บิต |
| 12 | [RAM + Data Page](lab12_ram_datapage.md) | 62256, U32, U33 | SB, LB |
| 13 | [Full System](lab13_full_system.md) | ทุกตัว | รันโปรแกรมจริง! |
| 14 | [IRQ + RV8-Bus](lab14_irq_bus.md) | U31, 40-pin IDC | Interrupt + bus |

---

## Chip Checklist (34 logic + ROM + RAM = 36 packages)

| Lab | ชิป | หน้าที่ |
|:---:|---|---|
| 01 | — | ไฟเลี้ยง + clock |
| 02 | U8 (74HC164), U24 (74HC04) | Ring counter T0/T1/T2 |
| 03 | U1-U4 (74HC161 ×4) | PC counter 16-bit |
| 04 | U15-U16, U29-U30 (74HC157 ×4) | Address mux |
| 05 | AT28C256 (ROM), U7 (74HC245) | Program ROM + bus buffer |
| 06 | U5, U6 (74HC574 ×2), U34 (74HC541) | IR latch + IRL immediate buffer |
| 07 | U10-U11 (74HC283 ×2), U12-U13 (74HC86 ×2) | Adder + B-invert |
| 08 | U9 (74HC574), U14 (74HC541), U17-U20 (74HC157 ×4) | AC + mux (Full ALU) |
| 09 | U21 (74HC74), U22 (74HC688) | Z flag |
| 10 | U25 (74HC32), U26-U27 (74HC00 ×2), U28 (74HC86) | Branch/Jump logic |
| 11 | U23 (74HC574) | Page register |
| 12 | 62256-70 (RAM), U32 (74HC574), U33 (74HC21) | RAM + data page |
| 13 | — (connect all) | Full integration |
| 14 | U31 (74HC74) | IRQ + RV8-Bus |

---

## ความสัมพันธ์กับ Debug Plan

Labs 01-14 ตรงกับ **ขั้นที่ 1-14** ใน `../05_debug_plan.md` ทุกประการ
และ map เข้ากับ module ใน `../06_kicad_modules.md`.

หลัง Lab 13-14 ผ่านบนบอร์ดจริง ให้บันทึกหลักฐาน timing/voltage ใน
`../07_real_build_timing_log.md` ก่อนถือว่า physical build ผ่านสมบูรณ์.

---

## เสร็จแล้วทำอะไรต่อ?

1. 🧪 ทดสอบทุก 18 คำสั่งด้วย test ROM
2. 📺 ต่อ 7-segment / LED array ที่ I/O slot
3. 🎮 เขียนเกม (นับเลข, ไฟวิ่ง, reaction timer)
4. 💻 ต่อ UART ผ่าน /SLOT1
5. รัน BASIC interpreter

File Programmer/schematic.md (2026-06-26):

# RV8 Programmer — Combined Schematic (Bus + Direct ROM)

**แนวคิด**: บอร์ดเดียว ใช้ได้ 2 แบบ — เสียบสาย Bus ไปยัง CPU board หรือเสียบ ROM ลง ZIF
**กฎ**: ใช้ทีละอย่าง — เสียบ Bus cable หรือ เสียบ ROM ใน ZIF (ไม่ใช้พร้อมกัน)

**KiCad project**: `KICAD/RV8Programmer.kicad_sch`
**PDF export**: `RV8Programmer.pdf`

---

## ภาพรวมระบบ

```
                                              ┌─────────────────────┐
                                         ┌──→ │  RV8-Bus (40-pin)   │ → CPU Board
                                         │    └─────────────────────┘
                                         │
PC ←USB→ [ESP32] ←→ [TXS ×2] ←→ [595 ×2]┤
                                         │
                                         │    ┌─────────────────────┐
                                         └──→ │  AT28C256 (ZIF 28)  │ → ถอดไปเสียบบอร์ด
                                              └─────────────────────┘

          เลือกใช้ทีละอย่าง: เสียบสาย Bus  หรือ  เสียบ ROM ใน ZIF
```

---

## 1. Power & Ground

```
ESP32 (3V3) ───→ TXS0108E ×2: V_A (พิน 1)
                 TXS0108E ×2: OE (พิน 10) — pull-up R1=10K เข้า 3.3V

ESP32 (5V)  ───→ TXS0108E ×2: V_B (พิน 20)
                 74HC595 ×2: VCC (พิน 16)
                 AT28C256: VCC (พิน 28)
                 Bus header: pin 39 (VCC)

ESP32 (GND) ───→ ทุก IC GND
                 AT28C256: GND (พิน 14)
                 Bus header: pin 40 (GND)
```

---

## 2. Control Signals (TXS0108E #2 = U4)

```
[ ESP32 ]         [ TXS #2 (U4) ]              [ ปลายทาง ×2 ]

GPIO 23 ──→ A1 ←═══→ B1 ──→ 595 #1 SER (พิน 14)
GPIO 18 ──→ A2 ←═══→ B2 ──→ 595 ×2 SRCLK (พิน 11)
GPIO 19 ──→ A3 ←═══→ B3 ──→ 595 ×2 RCLK (พิน 12)

GPIO 4  ──→ A4 ←═══→ B4 ──┬→ Bus pin 26 (/RST)
                           └→ ZIF ROM พิน 20 (/CE)

GPIO 16 ──→ A5 ←═══→ B5 ──┬→ Bus pin 27 (/WR)      ← ⚡ SWAP จาก KiCad เดิม
                           └→ ZIF ROM พิน 27 (/WE)

GPIO 17 ──→ A6 ←═══→ B6 ──┬→ Bus pin 28 (/RD)      ← ⚡ SWAP จาก KiCad เดิม
                           └→ ZIF ROM พิน 22 (/OE)

(A7/B7, A8/B8 ไม่ใช้)
```

### Pull-ups ที่ ZIF ROM (ป้องกัน glitch ตอน ESP32 boot)

```
R2 (10K): ZIF /OE (พิน 22) pull-up → +5V
R3 (10K): ZIF /CE (พิน 20) pull-up → +5V
```

---

## 3. Address Bus (74HC595 ×2 → Bus + ZIF)

```
📌 74HC595 ขาพิเศษ:
- พิน 10 (/SRCLR) → VCC
- พิน 13 (/OE)    → GND

📌 Daisy Chain:
- 595 #1 (U2) พิน 9 (QH') → 595 #2 (U3) พิน 14 (SER)

📌 595 #1 (U2) → A[7:0]:
  พิน 15 (QA) ──┬→ Bus pin 1  (A0)  └→ ZIF ROM พิน 10 (A0)
  พิน 1  (QB) ──┬→ Bus pin 2  (A1)  └→ ZIF ROM พิน 9  (A1)
  พิน 2  (QC) ──┬→ Bus pin 3  (A2)  └→ ZIF ROM พิน 8  (A2)
  พิน 3  (QD) ──┬→ Bus pin 4  (A3)  └→ ZIF ROM พิน 7  (A3)
  พิน 4  (QE) ──┬→ Bus pin 5  (A4)  └→ ZIF ROM พิน 6  (A4)
  พิน 5  (QF) ──┬→ Bus pin 6  (A5)  └→ ZIF ROM พิน 5  (A5)
  พิน 6  (QG) ──┬→ Bus pin 7  (A6)  └→ ZIF ROM พิน 4  (A6)
  พิน 7  (QH) ──┬→ Bus pin 8  (A7)  └→ ZIF ROM พิน 3  (A7)

📌 595 #2 (U3) → A[14:8]:
  พิน 15 (QA) ──┬→ Bus pin 9  (A8)  └→ ZIF ROM พิน 25 (A8)
  พิน 1  (QB) ──┬→ Bus pin 10 (A9)  └→ ZIF ROM พิน 24 (A9)
  พิน 2  (QC) ──┬→ Bus pin 11 (A10) └→ ZIF ROM พิน 21 (A10)
  พิน 3  (QD) ──┬→ Bus pin 12 (A11) └→ ZIF ROM พิน 23 (A11)
  พิน 4  (QE) ──┬→ Bus pin 13 (A12) └→ ZIF ROM พิน 2  (A12)
  พิน 5  (QF) ──┬→ Bus pin 14 (A13) └→ ZIF ROM พิน 26 (A13)
  พิน 6  (QG) ──┬→ Bus pin 15 (A14) └→ ZIF ROM พิน 1  (A14)
  พิน 7  (QH) ──  (ไม่ใช้)
```

---

## 4. Data Bus (TXS0108E #1 = U5 → Bus + ZIF)

```
[ ESP32 ]        [ TXS #1 (U5) ]         [ Bus + ZIF ]

GPIO 13 ──→ A1 ←═══→ B1 ──┬→ Bus pin 17 (D0)  └→ ZIF ROM พิน 11 (D0)
GPIO 12 ──→ A2 ←═══→ B2 ──┬→ Bus pin 18 (D1)  └→ ZIF ROM พิน 12 (D1)
GPIO 14 ──→ A3 ←═══→ B3 ──┬→ Bus pin 19 (D2)  └→ ZIF ROM พิน 13 (D2)
GPIO 27 ──→ A4 ←═══→ B4 ──┬→ Bus pin 20 (D3)  └→ ZIF ROM พิน 15 (D3)
GPIO 26 ──→ A5 ←═══→ B5 ──┬→ Bus pin 21 (D4)  └→ ZIF ROM พิน 16 (D4)
GPIO 25 ──→ A6 ←═══→ B6 ──┬→ Bus pin 22 (D5)  └→ ZIF ROM พิน 17 (D5)
GPIO 33 ──→ A7 ←═══→ B7 ──┬→ Bus pin 23 (D6)  └→ ZIF ROM พิน 18 (D6)
GPIO 32 ──→ A8 ←═══→ B8 ──┬→ Bus pin 24 (D7)  └→ ZIF ROM พิน 19 (D7)
```

---

## 5. Bus-only Signals (Input for RUN mode)

```
Bus pin 30 (/SLOT1) ──→ ESP32 GPIO 34
Bus pin 28 (/RD)    ──→ ESP32 GPIO 35  (sense)
Bus pin 27 (/WR)    ──→ ESP32 GPIO 36  (sense)
MODE switch         ──→ ESP32 GPIO 39  (LOW=PROG, HIGH=RUN)
```

เมื่อใช้ ZIF (ไม่ได้เสียบ Bus): GPIO 34/35/36 ลอย (input-only, ไม่มีผล)
GPIO 39: ต่อ pull-down 10K → GND (ค้าง PROG mode) หรือ ใช้สวิตช์เหมือนเดิม

---

## 6. Bypass Capacitors (C 104 = 0.1µF)

| Ref | IC |
|-----|-----|
| C1 | 74HC595 #1 (U2) |
| C2 | 74HC595 #2 (U3) |
| C3 | TXS0108E #1 (U5) — V_B side |
| C4 | TXS0108E #2 (U4) — V_A side |
| C5 | TXS0108E #2 (U4) — V_B side |
| C6 | TXS0108E #1 (U5) — V_A side |
| C7 | AT28C256 (U1) |

**รวม 7 ตัว**

---

## 7. BOM

| Part | Qty | หน้าที่ |
|---|:---:|---|
| ESP32-WROOM-32 | 1 | สมองหลัก |
| TXS0108E module | 2 | Level shift 3.3V↔5V |
| 74HC595 | 2 | Shift register → address |
| AT28C256 | (ใส่ใน ZIF เวลาใช้) | ROM |
| ZIF socket 28-pin wide | 1 | ใส่/ถอด ROM |
| 40-pin IDC header | 1 | Bus connector |
| 40-pin ribbon cable | 1 | ไป CPU board |
| R1 (10K) | 1 | TXS OE pull-up |
| R2 (10K) | 1 | ZIF /OE pull-up |
| R3 (10K) | 1 | ZIF /CE pull-up |
| C1-C7 (100nF) | 7 | Bypass |
| SPDT switch | 1 | PROG/RUN (Bus mode) |
| USB cable | 1 | PC → ESP32 |

---

## 8. ESP32 GPIO Summary

| GPIO | Function | Dir | ปลายทาง |
|:----:|---|:---:|---|
| 23 | SR_DATA | OUT | 595 SER |
| 18 | SR_CLK | OUT | 595 SRCLK |
| 19 | SR_LATCH | OUT | 595 RCLK |
| 4 | /RST + /CE | OUT | Bus /RST & ZIF /CE |
| 16 | /WR + /WE | OUT in PROG, released in RUN | Bus /WR & ZIF /WE |
| 17 | /RD + /OE | OUT in PROG, released in RUN | Bus /RD & ZIF /OE |
| 13 | D0 | BIDIR | Bus D0 & ZIF D0 |
| 12 | D1 | BIDIR | Bus D1 & ZIF D1 |
| 14 | D2 | BIDIR | Bus D2 & ZIF D2 |
| 27 | D3 | BIDIR | Bus D3 & ZIF D3 |
| 26 | D4 | BIDIR | Bus D4 & ZIF D4 |
| 25 | D5 | BIDIR | Bus D5 & ZIF D5 |
| 33 | D6 | BIDIR | Bus D6 & ZIF D6 |
| 32 | D7 | BIDIR | Bus D7 & ZIF D7 |
| 34 | /SLOT1 | IN | Bus pin 30 (RUN mode) |
| 35 | /RD sense | IN | Bus pin 28 (RUN mode) |
| 36 | /WR sense | IN | Bus pin 27 (RUN mode) |
| 39 | MODE | IN | Switch (PROG/RUN) |

**Total: 18 GPIO**

---

## 9. วิธีใช้

### ใช้กับ ZIF (โปรแกรม ROM เปล่า)

1. ❌ ถอดสาย Bus ออก (ถ้ามี)
2. เสียบ ROM ลง ZIF → ล็อค
3. สวิตช์ → PROG (หรือ ground GPIO 39)
4. `python3 rv8flash.py -w program.bin`
5. `python3 rv8flash.py -v program.bin`
6. ปลดล็อค ZIF → ถอด ROM ไปเสียบ CPU board

### ใช้กับ Bus (โปรแกรม in-system)

1. ❌ ZIF ว่าง (ไม่เสียบ ROM)
2. เสียบสาย Bus ไป CPU board
3. สวิตช์ → PROG → flash
4. สวิตช์ → RUN → terminal (`rv8term.py`)

---

## 10. ทำไมปลอดภัย (ไม่ conflict)

| สถานการณ์ | เกิดอะไร |
|---|---|
| ZIF มี ROM + Bus ไม่ได้เสียบ | Bus header ลอย, ไม่มีอะไรขับสาย ✅ |
| Bus เสียบ + ZIF ว่าง | ZIF ไม่มี chip, /CE pull-up HIGH, ไม่ตอบ ✅ |
| ⚠️ ทั้ง 2 เสียบพร้อมกัน | **ห้าม!** data bus fight → ชิปพัง |

---

*ตรงกับ KiCad schematic หลัง swap GPIO 16↔17*
*Firmware ไม่ต้องแก้*
*เขียนสำหรับน้อง ๆ ม.ต้น — ถ้าติดตรงไหนถามพี่ได้เลย!*

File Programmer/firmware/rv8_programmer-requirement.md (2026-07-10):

# ESP32 Programmer Firmware — Requirements

**Target**: ESP32-WROOM-32 with Arduino framework
**File**: `firmware.ino` (single file)
**Purpose**: Flash/read/verify ROM on CPU board via RV8-Bus

---

## Connection

```
PC ←USB→ ESP32 ←TXS0108E×2→ RV8-Bus (40-pin) → ROM on target board
```

Two scenarios:
- **A (bare ROM)**: ROM wired directly to bus connector
- **B (full CPU)**: Hold /RST to stop CPU, then access ROM via bus

---

## Pin Configuration

```cpp
// Data bus D[7:0] (via TXS0108E #2 → Bus pin 17-24)
const uint8_t DATA_PINS[] = {13, 12, 14, 27, 26, 25, 33, 32};

// Address via 74HC595 ×2 (via TXS0108E #1 → Bus pin 1-16)
#define PIN_SR_DATA   23   // SER
#define PIN_SR_CLK    18   // SRCLK
#define PIN_SR_LATCH  19   // RCLK

// Control (via TXS0108E #1 → RV8-Bus)
#define PIN_nRST  4    // → Bus pin 26 (/RST)
#define PIN_nWR   16   // → Bus pin 27 (/WR)
#define PIN_nRD_O 17   // → Bus pin 28 (/RD, output in PROG mode)

// Input (from RV8-Bus, RUN mode sensing)
#define PIN_nSLOT1 34  // ← Bus pin 30
#define PIN_nRD_S  35  // ← Bus pin 28
#define PIN_nWR_S  36  // ← Bus pin 27
#define PIN_MODE   39  // PROG/RUN switch

#define SERIAL_BAUD 115200
```

---

## Protocol (PROG mode)

| PC → ESP32 | ESP32 → PC | Notes |
|---|---|---|
| `?` | `Connected\n` | Connection check |
| `F` + len_hi + len_lo | `K\n`, then receive data, then `D\n` | Flash ROM |
| `V` | 32768 raw bytes | Read entire ROM |
| `R` | `K\n` | Pulse /RST |

### Flash sequence
1. PC sends `F` + 2-byte big-endian length
2. ESP32 replies `K\n` (ready)
3. PC sends `length` bytes
4. ESP32 writes each byte: set address (595), set data, pulse /WR
5. ESP32 replies `D\n` (done)

### Read sequence
1. PC sends `V`
2. ESP32 reads 32768 bytes: set address, pulse /RD, read data bus
3. ESP32 sends all 32768 bytes raw

---

## ROM Access via Bus

**Write**: A15=0 (595 bit15) → ROM /CE active. In PROG mode only, pulse /WR
so ROM latches data.
**Read**: A15=0 → ROM /CE active. Pulse /RD → ROM outputs data (/OE).
**CPU isolation**: /RST=LOW keeps CPU in reset, tri-states its bus drivers.
**Runtime rule**: during normal CPU runtime, ROM /WE must stay inactive. The
Programmer write path owns ROM /WE only while intentionally programming.

---

## Modes

| Mode | PIN_MODE | Behavior |
|---|---|---|
| PROG | LOW | Serial commands, drives bus |
| RUN | HIGH | Releases bus, UART bridge via /SLOT1 |

### PROG mode
- `/RST` held LOW (CPU stopped)
- `/RD_O` set as OUTPUT (drives ROM /OE)
- Responds to serial protocol commands

### RUN mode
- `/RST` released HIGH (CPU runs)
- `/WR` set as INPUT (CPU drives /WR)
- `/RD_O` set as INPUT (CPU drives /RD)
- Listens for `/SLOT1` activity for UART bridging

---

## Error Responses

| Response | Meaning |
|---|---|
| `K\n` | ACK / success |
| `D\n` | Operation complete |
| `E:timeout\n` | Serial timeout waiting for data |
| `E:len\n` | Invalid length (0 or >32768) |

---

## Timing

| Parameter | Value |
|---|---|
| Baud rate | 115200 |
| /WR pulse | 1 µs |
| /RD setup | 1 µs (before reading data bus) |
| Page write delay | 10 ms (every 64 bytes) |
| Boot delay | ~2s (ESP32 prints boot messages) |

---

## Post-Coding Checklist

- [x] Single file `firmware.ino`
- [x] Pin config at top
- [x] 74HC595 shift register for A[14:0] (A15 always 0)
- [x] Data bus bidirectional (set input for read, output for write)
- [x] `?` → `Connected\n`
- [x] `F` → ACK + receive + done
- [x] `V` → drives /RD per byte, sends 32KB
- [x] `R` → pulse /RST
- [x] MODE switch selects PROG/RUN
- [x] RUN mode releases /WR and /RD_O as inputs
- [x] PROG mode reclaims /RD_O as output
- [x] Compiles clean (286KB)
- [x] 51 Python mock tests pass across flash, terminal, and RAM boot tools

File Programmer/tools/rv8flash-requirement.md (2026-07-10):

# rv8flash.py — Requirements

**Purpose**: Flash, read, and verify AT28C256 ROM via ESP32 Programmer on RV8-Bus
**Platform**: Python 3.6+ with `pyserial`
**Usage**: `python3 rv8flash.py [options]`

---

## VirtualESP32 Board Definition

```python
class VirtualESP32:
    NAME = "RV8 Programmer ESP32"
    BAUD_RATE = 115200
    TIMEOUT = 5

    DATA_PINS = [13, 12, 14, 27, 26, 25, 33, 32]  # D0-D7, TXS#2 → Bus pin 17-24
    SR_DATA_PIN = 23   # SER
    SR_CLK_PIN = 18    # SRCLK
    SR_LATCH_PIN = 19  # RCLK

    # Control signals (via TXS0108E #1 → RV8-Bus)
    PIN_nRST = 4       # → Bus pin 26 (/RST)
    PIN_nWR = 16       # → Bus pin 27 (/WR)
    PIN_nRD_O = 17     # → Bus pin 28 (/RD, output in PROG mode)

    # Input-only pins (from RV8-Bus)
    PIN_nSLOT = 34     # ← Bus pin 30 (/SLOT1)
    PIN_nRD = 35       # ← Bus pin 28 (/RD sense)
    PIN_nWR_S = 36     # ← Bus pin 27 (/WR sense)
    PIN_MODE = 39      # PROG/RUN switch
```

---

## CLI Options

| Option | Description |
|---|---|
| `-h` | Show help |
| `-pl` | List available ports |
| `-p N` | Use port N (default: 0) |
| `-c` | Check connection and exit |
| `-w FILE` | Write FILE to ROM |
| `-r FILE` | Read ROM to FILE |
| `-v FILE` | Verify ROM against FILE |
| `program FILE --base 0x0000` | RV8GR documented alias for write |
| `verify FILE --base 0x0000` | RV8GR documented alias for verify |
| `--base ADDR` | Base address compatibility option; current firmware supports only `0x0000` |
| `-d` | Debug (show serial traffic) |
| `-q` | Quiet (minimal output) |
| `-t N` | Retry N times (default: 3) |
| `-R` | Pulse /RST after flash |

---

## Serial Protocol

| PC → ESP32 | ESP32 → PC | Notes |
|---|---|---|
| `?` | `Connected\n` | Connection check |
| `F` + len_hi + len_lo | `K\n` (ACK), receive data, `D\n` | Flash |
| `V` | 32768 raw bytes | Read ROM |
| `R` | `K\n` | Pulse /RST |

---

## Output Examples

```bash
$ python3 rv8flash.py -c
Port: /dev/ttyUSB0 @ 115200 baud
Programmer: Connected

$ python3 rv8flash.py -w testrom.bin
Port: /dev/ttyUSB0 @ 115200 baud
Programmer: Connected
Flashing testrom.bin (32768 bytes)...
[██████████] 100%
Done. 32768 bytes written.

$ python3 rv8flash.py -v testrom.bin
Port: /dev/ttyUSB0 @ 115200 baud
Programmer: Connected
Verifying...
[██████████] 100%
Verified

$ python3 rv8flash.py program testrom.bin --base 0x0000
# same as -w testrom.bin
```

---

## Error Handling

| Exit | Meaning |
|:----:|---|
| 0 | Success |
| 1 | Error (message printed to stderr) |

Errors: no port, programmer not responding, timeout, file not found, file too large (>32KB), verify mismatch.
Nonzero `--base` is rejected because the current serial protocol always starts
at ROM address `$0000`.

AT28C256 note: current firmware performs normal byte write cycles. Use chips with
software data protection disabled, or add/enable an SDP unlock sequence before
relying on protected parts.

---

## Boot Delay

ESP32 resets when serial port opens (DTR). Tool waits 2s + drains buffer before sending commands.

---

## File Structure

```
tools/
├── rv8flash.py              # Implementation
├── test_rv8flash.py         # 19 tests (all passing)
└── rv8flash-requirement.md  # This document
```

---

## Checklist ✅

- [x] VirtualESP32 at top (bus-based pins)
- [x] SerialPort context manager with boot delay
- [x] Connection check (`?` → `Connected\n`)
- [x] Flash (`F` + len + data → `K\n` + `D\n`)
- [x] Read (`V` → 32768 bytes)
- [x] Verify (read + compare)
- [x] Port + baud display before operations
- [x] RV8GR `program/verify --base 0x0000` compatibility aliases

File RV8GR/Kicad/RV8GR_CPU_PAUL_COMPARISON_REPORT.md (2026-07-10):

# RV8GR KiCad vs Original Paul PDF Comparison Report

Date: 2026-07-09

Update: `RV8GR-CPU-paul.pdf` has since been regenerated from the current KiCad
schematic sheets. The mismatch notes below describe the original Paul PDF
before that rewrite.

## Scope

Compared:

- Original reference PDF: `RV8GR-CPU-paul.pdf` before the rewrite
- Updated PDF file: `RV8GR-CPU-paul.pdf`
- Updated EDIF/EDF file: `RV8GR-CPU-paul.EDF`
- Current generated KiCad source: `RV8GR.kicad_pro`, `RV8GR.kicad_sch`, `RV8GR.net`, and module sheets
- Current source-of-truth docs: `../doc/01_wiring_guide.md` and `../doc/10_netlist.md`

## Method

- Extracted PDF text with `pdftotext -layout`.
- Rendered the PDF page and visually checked the schematic.
- Parsed `RV8GR.net` component references and values.
- Searched current KiCad/doc files for matching designators, bus names, and chip values.

Limit: `RV8GR-CPU-paul.pdf` is a graphical schematic print, not a KiCad netlist. This report can confirm visible designator/value/name mismatches, but it cannot prove every drawn wire connection automatically.

## Summary

The current generated KiCad project did **not** fully match the original
`RV8GR-CPU-paul.pdf`.

The largest mismatch is design intent/version: Paul's PDF appears to be a one-page schematic using memory designators `U34` and `U35`, while the current RV8GR generated KiCad/netlist follows the newer 34-logic-chip baseline where `U34` is a 74HC541 IRL-to-IBUS immediate buffer and memory parts are named `ROM1` and `RAM1`.

`RV8GR-CPU-paul.EDF` has been regenerated from `gen_kicad.py` so it now follows
the current RV8GR baseline, not the older PDF designators.

`RV8GR-CPU-paul.pdf` has also been regenerated with `kicad-cli sch export pdf`
from the current KiCad schematic sheets, so the current file is a
current-baseline KiCad PDF export rather than the older Paul one-page
schematic.

## Confirmed Matches

| Area | Match |
|---|---|
| Core PC counters | PDF uses U1-U4 74HC161; current KiCad uses U1-U4 74HC161 |
| IR registers | PDF uses U5/U6 74HC574; current KiCad uses U5/U6 74HC574 |
| Bus transceiver | PDF uses U7 74HC245; current KiCad uses U7 74HC245 |
| Ring counter | PDF uses U8 74HC164; current KiCad uses U8 74HC164 |
| Accumulator | PDF uses U9 74HC574; current KiCad uses U9 74HC574 |
| Adders/XOR/muxes | PDF uses 74HC283/74HC86/74HC157 blocks; current KiCad uses the same families for U10-U20 |
| Z detect | PDF uses U21 74HC74 and U22 74HC688; current KiCad uses U21 74HC74 and U22 74HC688 |
| Page/Data page registers | PDF uses U23/U32 74HC574; current KiCad uses U23/U32 74HC574 |
| Control glue | PDF uses U24 74HC04, U25 74HC32, U28 74HC86, U33 74HC21; current KiCad uses the same designators/families |
| Bus names | PDF visibly uses address/data/internal-style buses such as `A[0..15]`, `D[0..7]`, `I[0..7]`, `AC[0..7]`, `DP[0..7]`; current KiCad/netlist has equivalent ABUS, DBUS, IBUS, AC, DP nets |

## Confirmed Mismatches

| # | Area | PDF `RV8GR-CPU-paul.pdf` | Current KiCad/netlist | Impact |
|---|---|---|---|---|
| 1 | U34 designator | `U34` is the 28C256 ROM | `U34` is 74HC541 IRL-to-IBUS immediate buffer | Major designator conflict. A BOM or wiring guide using U34 from the PDF will not match current RV8GR docs/netlist. |
| 2 | RAM designator | `U35` is 62256 RAM | RAM is `RAM1`; no `U35` component exists | Major designator conflict. |
| 3 | ROM designator | ROM is `U34` and value text is `28C256` | ROM is `ROM1` and value is `AT28C256` | Same part family intent, different reference naming. |
| 4 | Immediate buffer | No visible separate U34 74HC541 immediate buffer in the PDF | Current design has U34 74HC541 controlled by `/IRL_OE` and connected IRL -> IBUS | Major baseline-version mismatch. Current RV8GR uses U34 to avoid immediate/IBUS ownership ambiguity. |
| 5 | RV8-Bus connector | PDF has `P1` labeled RV8Bus with A0-A15, D0-D7, CLK/RST/WRn/RDn/IRQn/SLT pins | Current generated KiCad netlist has no `P1` component; RV8-Bus pins are documented in `doc/10_netlist.md` but not instantiated in `RV8GR.net` | Schematic capture mismatch. A physical KiCad schematic should add P1 if it is meant to match the PDF. |
| 6 | NAND family label | PDF labels several NAND gates as `74AHC00` | Current KiCad uses `74HC00` for U26/U27 | Family mismatch. Check whether Paul intended AHC for timing or this is a symbol/library label choice. |
| 7 | Control signal naming | PDF uses names such as `IRLoe`, `ACbuff`, `BUFFoeN`, `WRDIR`/`WRDIRn`, `WRn`, `RDn`, `IRQn` | Current docs/netlist use `/IRL_OE`, `/AC_BUF`, `BUF_OE_N`, `WR_DIR`, `/WR`, `/RD`, `/IRQ` | Naming mismatch only if electrical polarity is equivalent. Needs a net-name mapping table before manual schematic reconciliation. |
| 8 | Schematic organization | PDF is a complete one-page schematic with symbols and drawn wiring | Current generated KiCad top sheet is a generated scaffold/global-label view plus separate module sheets and machine-readable netlist | Form mismatch. Current KiCad is not a hand-drawn one-page schematic matching Paul’s PDF layout. |

## Current KiCad Netlist Facts

Parsed from `RV8GR.net`:

- Nets: 159
- Components/packages: 36
- Pin connections: 598
- `P1`: absent
- `U34`: 74HC541
- `U35`: absent
- `ROM1`: AT28C256
- `RAM1`: 62256
- `U26`: 74HC00
- `U27`: 74HC00

## Recommended Fix Path

Choose one direction before editing KiCad:

1. **Keep current RV8GR baseline as source of truth**
   Treat Paul’s PDF as an older/reference schematic. Keep `U34 = 74HC541`, `ROM1`, `RAM1`, and add a clear note that the PDF is not pin/designator-compatible with current RV8GR.

2. **Make KiCad visually match Paul’s PDF**
   Rename current `U34` immediate buffer to a new logic designator, rename memory to `U34`/`U35`, instantiate `P1`, and update every doc/netlist/sim/RTL reference. This is a large migration and risks breaking the current verified 34-logic-chip baseline.

3. **Create a compatibility mapping sheet**
   Keep current netlist naming, but add a manual `PDF_TO_CURRENT_KICAD_MAP.md` that maps PDF names (`I[0..7]`, `WRn`, `U34 ROM`, `U35 RAM`, `P1`) to current RV8GR names (`IBUS`, `/WR`, `ROM1`, `RAM1`, documented RV8-Bus pins).

## Recommendation

Use option 1 or 3. The current RV8GR docs, simulator, chip-level Verilog, and netlist have already converged on the newer baseline with `U34` as the immediate buffer. Reverting to Paul’s PDF designators would require a broad renumbering pass and fresh verification.

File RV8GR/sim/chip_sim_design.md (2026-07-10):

# RV8-GR Gate-Level Simulator — Design Document

## Purpose

Pin-accurate simulation of 34 logic chips plus ROM/RAM. Verify wiring from 01_wiring_guide.md.
Probe any pin like attaching an LED. Step one clock at a time.

The Python simulator is the preferred cross-check for RV8GR system behavior.
Use it before the shared Verilog component models when checking chip behavior,
pin wiring, bus ownership, instruction execution, and propagation-delay timing.
Use Verilog as a secondary HDL-equivalence path or when the task is explicitly
about RTL/FPGA-oriented verification.

---

## Architecture

```
┌─────────────┐     ┌──────────┐     ┌──────────┐
│  Chip Class │────▶│  Wire    │────▶│ Simulator│
│  (per type) │     │  Net     │     │  Engine  │
└─────────────┘     └──────────┘     └──────────┘
```

---

## Chip Base Class

```python
class Chip:
    """Base class for all 74HC chips."""
    def __init__(self, name: str, pin_count: int):
        self.name = name                    # e.g. "U5"
        self.pins = [None] * (pin_count+1)  # pins[1..N], index 0 unused
        self.pin_names = {}                 # {pin_num: "name"}

    def set_pin(self, pin: int, value: int):
        """Set input pin value (0 or 1 for single bit, 0-255 for bus)."""

    def get_pin(self, pin: int) -> int:
        """Read output pin value."""

    def update(self):
        """Recalculate outputs from inputs (combinational)."""

    def clock_edge(self):
        """Handle rising edge (for sequential chips)."""
```

---

## Chip Types

### Sequential (edge-triggered)

| Class | Chip | Instances | Key Behavior |
|---|---|---|---|
| HC574 | 74HC574 | U5,U6,U9,U23,U32 | 8-bit D latch, rising edge CLK, /OE |
| HC161 | 74HC161 | U1,U2,U3,U4 | 4-bit counter, sync load, enable |
| HC164 | 74HC164 | U8 | 8-bit shift register, serial in |
| HC74 | 74HC74 | U21,U31 | Dual D flip-flop, /PR, /CLR |

### Combinational (instant propagation)

| Class | Chip | Instances | Key Behavior |
|---|---|---|---|
| HC245 | 74HC245 | U7 | 8-bit bidirectional buffer, DIR, /OE |
| HC541 | 74HC541 | U14 | 8-bit buffer, /OE1, /OE2 |
| HC283 | 74HC283 | U10,U11 | 4-bit full adder, Cin, Cout |
| HC86 | 74HC86 | U12,U13,U28 | Quad 2-input XOR |
| HC157 | 74HC157 | U15-U20,U29,U30 | Quad 2-to-1 mux, SEL, /E |
| HC688 | 74HC688 | U22 | 8-bit comparator, /OE, /P=Q |
| HC04 | 74HC04 | U24 | Hex inverter |
| HC32 | 74HC32 | U25 | Quad 2-input OR |
| HC00 | 74HC00 | U26,U27 | Quad 2-input NAND |
| HC21 | 74HC21 | U33 | Dual 4-input AND |

### Memory

| Class | Chip | Instances | Key Behavior |
|---|---|---|---|
| ROM | AT28C256 | ROM | 32KB read, /CE, /OE |
| RAM | 62256 | RAM | 32KB read/write, /CE, /OE, /WE |

---

## Bus Architecture (matches 01_wiring_guide)

### Note: "Bus" = shared wires, not physical backplane

In 01_wiring_guide, DBUS/IBUS/ABUS are **naming conventions** for groups of wires
that connect multiple chip pins together. They are NOT a separate bus backplane.

In the simulator, a "bus" is simply a **set of wire nets** that multiple chips share.
The tristate logic determines which chip drives the shared wires at any given time.

### Wire Groups (named as buses for clarity)

```
DBUS[7:0]  — 8 wires shared between: ROM data pins, RAM data pins, U7 A-side pins
IBUS[7:0]  — 8 wires shared between: U7 B-side, U6 Q*, U14 Y*, U12/U13 A, U5 D, U23 D, U32 D
ABUS[15:0] — 16 wires from mux outputs (U15/U16/U29/U30 Y) to ROM/RAM address pins
```

### Simulation Model: Shared Wire with Tristate

```python
class SharedWire:
    """A wire that multiple chip pins connect to.
    Only one chip may drive it at a time (tristate control).
    Others are high-impedance (reading).
    """
    def __init__(self, name: str):
        self.name = name
        self.value = 0          # current logic level on the wire
        self.drivers = {}       # {chip_pin: (value, output_enabled)}

    def drive(self, chip_pin: str, value: int, output_enabled: bool):
        """Chip asserts or releases the wire."""
        self.drivers[chip_pin] = (value, output_enabled)

    def resolve(self) -> int:
        """Determine wire value from active driver(s)."""
        active = [(k, v) for k, (v, en) in self.drivers.items() if en]
        if len(active) == 0:
            return 0  # no driver = floating (pulled low or undefined)
        if len(active) == 1:
            self.value = active[0][1]
            return self.value
        # Multiple drivers = BUS CONFLICT (hardware damage risk!)
        raise BusConflictError(
            f"Wire {self.name}: conflict between {[k for k,v in active]}")
```

### IBUS — 8 shared wires with 3 tristate drivers

```python
# Each IBUS0-IBUS7 is a SharedWire
# Connected pins (from 01_wiring_guide):
#
# IBUS0 wire connects to: U7-2, U34-18, U14-18, U12-1, U23-2, U5-2, U6-2, U32-2
#   Drivers (tristate):
#     U7-2   enabled when BUF_OE_N=0 (U24-12=0) — reads from DBUS
#     U34-18 enabled when /IRL_OE=0 (U26-3=0) — immediate operand
#     U14-18 enabled when /AC_BUF=0 (U26-8=0) — AC value for store
#   Readers (always connected, high-impedance input):
#     U12-1, U23-2, U5-2, U6-2, U32-2
```

### DBUS — 8 shared wires

```python
# D0 wire connects to: ROM-D0, RAM-D0, U7-18
#   Drivers:
#     ROM-D0  enabled when ROM /CE=0 and /OE=0 (A15=0)
#     RAM-D0  enabled when RAM /CE=0 and /OE=0 and /WE=1 (A15=1, read)
#     U7-18   enabled when DIR=1 and BUF_OE_N=0 (write from IBUS to DBUS)
```

### ABUS — 16 wires (single driver, no tristate)

```python
# A0 wire: driven by U15-4 (mux output, always active)
# A15 wire: driven by U30-12 (mux output, always active)
# No tristate needed — mux always drives
```

### In the simulator

```python
class WireGroup:
    """Group of SharedWire instances (convenience for 8/16-bit buses)."""
    def __init__(self, prefix: str, width: int):
        self.wires = [SharedWire(f"{prefix}{i}") for i in range(width)]

    def read(self) -> int:
        """Read all wires as integer value."""
        val = 0
        for i, w in enumerate(self.wires):
            val |= (w.resolve() & 1) << i
        return val

    def drive_byte(self, chip: str, value: int, enabled: bool):
        """Drive all 8 wires from one chip."""
        for i, w in enumerate(self.wires):
            w.drive(chip, (value >> i) & 1, enabled)
```

---

## Wire Net

```python
class Net:
    """A named wire connecting chip pins."""
    def __init__(self, name: str):
        self.name = name
        self.value = 0          # current logic level
        self.driver = None      # (chip, pin) that drives this net
        self.listeners = []     # [(chip, pin), ...] that read this net
```

---

## Simulator Engine

```python
class Simulator:
    def __init__(self):
        self.chips = {}         # {"U5": Chip, "U6": Chip, ...}
        self.nets = {}          # {"T0": Net, "IBUS0": Net, ...}
        self.clock = 0

    def wire(self, net_name: str, driver: tuple, listeners: list):
        """Connect driver (chip,pin) to listeners [(chip,pin), ...]"""

    def step(self):
        """One clock cycle: propagate combinational, then clock edge."""

    def probe(self, chip_name: str, pin: int) -> int:
        """Read a pin value (like LED)."""

    def probe_bus(self, net_prefix: str, width: int) -> int:
        """Read multi-bit bus (e.g. 'IBUS', 8)."""

    def inject(self, chip_name: str, pin: int, value: int):
        """Force a pin value (like DIP switch)."""
```

---

## Simulation Loop

```python
def step(self):
    # 1. Drive clock HIGH
    self.nets['CLK'].value = 1

    # 2. Sequential chips latch on rising edge
    for chip in self.sequential_chips:
        chip.clock_edge()

    # 3. Propagate combinational (iterate until stable)
    for _ in range(10):  # max iterations
        changed = False
        for chip in self.combinational_chips:
            old = chip.outputs()
            chip.update()
            if chip.outputs() != old:
                changed = True
        if not changed:
            break

    # 4. Update all nets from chip outputs
    self.propagate_nets()
    self.clock += 1
```

---

## Wiring (from 01_wiring_guide.md)

Wiring defined as connection list:

```python
def wire_cpu(sim):
    # CLK → U1-2, U2-2, U3-2, U4-2, U8-8
    sim.wire('CLK', source=('OSC', 1), sinks=[
        ('U1', 2), ('U2', 2), ('U3', 2), ('U4', 2), ('U8', 8)
    ])

    # T0 (U8-3) → U5-11, U25-4, U24-1
    sim.wire('T0', source=('U8', 3), sinks=[
        ('U5', 11), ('U25', 4), ('U24', 1)
    ])

    # IBUS0: U7-2, U34-18*, U14-18*, U12-1, U23-2, U5-2, U6-2, U32-2
    sim.wire('IBUS0', source=None, sinks=[  # tristate - multiple potential drivers
        ('U7', 2), ('U34', 18), ('U14', 18),
        ('U12', 1), ('U23', 2), ('U5', 2), ('U6', 2), ('U32', 2)
    ])
    # ... (all connections from 01_wiring_guide.md)
```

---

## Probe Interface

```python
# Probe like LED
sim.probe('U9', 19)          # AC bit 0
sim.probe_bus('AC', 8)       # Full AC value

# Probe bus
sim.probe_bus('ABUS', 16)    # Address bus
sim.probe_bus('DBUS', 8)     # Data bus
sim.probe_bus('IBUS', 8)     # Internal bus

# Inject like DIP switch
sim.inject('ROM', 'data', 0x30)  # Force ROM output
```

---

## Test Strategy

```python
# Step 1: Power on, check reset state
sim.reset()
assert sim.probe_bus('PC', 16) == 0x0000
assert sim.probe('U8', 3) == 1  # T0

# Step 2: Single step, check ROM fetch
sim.step()
assert sim.probe_bus('ABUS', 16) == 0x0000
assert sim.probe_bus('DBUS', 8) == rom_data[0]

# Step 3: Verify each instruction type
```

---

## Timing Analysis (auto-calculated by propagation engine)

The simulator tracks cumulative delay along each signal path per phase.
After each instruction, it reports:

```python
class TimingReport:
    """Generated after each instruction execution."""
    def __init__(self):
        self.paths = {}          # {path_name: total_delay_ns}
        self.longest_path = ""   # name of critical path
        self.longest_delay = 0   # ns
        self.max_safe_freq = 0   # MHz (= 1000 / longest_delay)

    def add_path(self, name, chips_in_path):
        """Sum propagation delays along a chip chain."""
        total = sum(chip.prop_delay for chip in chips_in_path)
        self.paths[name] = total
        if total > self.longest_delay:
            self.longest_delay = total
            self.longest_path = name
        self.max_safe_freq = 1000.0 / self.longest_delay if self.longest_delay > 0 else 999

    def report(self):
        print(f"  Critical path: {self.longest_path} = {self.longest_delay}ns")
        print(f"  Max safe clock: {self.max_safe_freq:.1f} MHz")
        print(f"  At 5 MHz (200ns): margin = {200 - self.longest_delay}ns")
```

### Pre-calculated Critical Paths

| Path | Chips | Delay | Max Clock |
|---|---|:-----:|:---:|
| ALU (8-bit add) | XOR→U10→U11→Mux | 103ns | 9.7 MHz |
| Fetch (ROM) | Mux→ROM→U7 | 100ns | 10.0 MHz |
| Branch decide | XOR→NAND→NAND→NAND | 51ns | 19.6 MHz |
| Store | NAND→U14→U7 | 36ns | 27.8 MHz |

**System max = 9.7 MHz** (limited by ALU 8-bit carry propagation)

---

## File Structure (actual)

```
sim/
├── chip_sim.py             # Gate-level CPU sim + 8 tests
├── soft_debug.py           # High-level trace sim + 4 tests
├── gate_sim.py             # Simplified gate model (educational)
├── verify_wiring.py        # Wiring correctness checker
├── wiring.py               # 247 pin connections from 01_wiring_guide
├── chips/
│   ├── __init__.py         # 34 logic chip classes plus ROM/RAM models
│   └── test_chips.py       # Unit tests for each chip type (141 vectors)
├── sim_lab/
│   ├── __init__.py         # Lab index
│   └── lab01-14_*.py       # Per-lab simulation scripts
└── chip_sim_design.md      # This document
```

---

## Implementation Order

1. `base.py` — Chip, Net, Simulator classes
2. `sequential.py` — HC574 first (most used)
3. `combinational.py` — HC04, HC00, HC32, HC86 first (simple gates)
4. `memory.py` — ROM, RAM
5. `wiring.py` — Connect everything per 01_wiring_guide
6. `chip_sim.py` — Main entry point + tests

---

## Acceptance Criteria

- [x] All 34 logic chip objects plus ROM/RAM created with correct pin count
- [x] All pins wired according to 01_wiring_guide.md (247 connections)
- [x] `LI $42` executes correctly (3 clocks)
- [x] `ADDI $05` gives correct AC
- [x] `SB` writes RAM correctly
- [x] `SETDP + LB` reads correct page
- [x] Probe any pin returns correct value
- [x] Step-by-step matches soft_debug.py output
- [x] Critical path timing reported per instruction
- [x] Max safe clock speed calculated automatically (9.7 MHz)
- [x] verify_wiring.py passes clean (11K+ checks)

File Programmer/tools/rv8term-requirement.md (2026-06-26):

# rv8term.py — Requirements

**Purpose**: Terminal bridge — send/receive bytes between PC and RV8 CPU via I/O slot
**Platform**: Python 3.6+ with `pyserial`
**Usage**: `python3 rv8term.py [options]`

---

## VirtualESP32 Board Definition

```python
class VirtualESP32:
    NAME = "RV8 Programmer ESP32"
    BAUD_RATE = 115200
    TIMEOUT = 5

    DATA_PINS = [13, 12, 14, 27, 26, 25, 33, 32]  # D0-D7, TXS#2 → Bus pin 17-24
    SR_DATA_PIN = 23   # SER
    SR_CLK_PIN = 18    # SRCLK
    SR_LATCH_PIN = 19  # RCLK

    # Control signals (via TXS0108E #1 → RV8-Bus)
    PIN_nRST = 4       # → Bus pin 26 (/RST)
    PIN_nWR = 16       # → Bus pin 27 (/WR)
    PIN_nRD_O = 17     # → Bus pin 28 (/RD, output in PROG mode)

    # Input-only pins (from RV8-Bus)
    PIN_nSLOT = 34     # ← Bus pin 30 (/SLOT1)
    PIN_nRD = 35       # ← Bus pin 28 (/RD sense)
    PIN_nWR_S = 36     # ← Bus pin 27 (/WR sense)
    PIN_MODE = 39      # PROG/RUN switch
```

---

## CLI Options

| Option | Description |
|---|---|
| `-h` | Show help |
| `-pl` | List available ports |
| `-p N` | Use port N (default: 0) |
| `-c` | Check connection and exit |
| `-b N` | Baud rate (default: 115200) |
| `-d` | Debug (show serial traffic) |
| `-q` | Quiet (no banner) |

---

## Behavior

1. Open serial port (2s boot delay + buffer drain)
2. If `-c`: send `?`, expect `Connected\n`, print status, and exit. Use this only with the board in PROG mode.
3. Otherwise enter terminal mode directly with the board switched to RUN: bidirectional byte bridge (PC ↔ CPU via /SLOT1)
4. Ctrl+C to exit

---

## Output Examples

```bash
$ python3 rv8term.py -c
Port: /dev/ttyUSB0 @ 115200 baud
Programmer: Connected

$ python3 rv8term.py
Port: /dev/ttyUSB0 @ 115200 baud
Terminal mode. Press Ctrl+C to exit.
---
RV8 BASIC 1.0
> 

$ python3 rv8term.py -b 9600
Port: /dev/ttyUSB0 @ 9600 baud
Terminal mode. Press Ctrl+C to exit.
---
```

---

## Error Handling

| Exit | Meaning |
|:----:|---|
| 0 | Normal exit (Ctrl+C) |
| 1 | Error (no port, not responding, timeout) |

---

## Boot Delay

ESP32 resets when serial port opens (DTR). Tool waits 2s + drains buffer before either running the PROG-mode `-c` check or entering terminal mode.

---

## File Structure

```
tools/
├── rv8term.py              # Implementation
├── test_rv8term.py         # 15 tests (all passing)
└── rv8term-requirement.md  # This document
```

---

## Checklist ✅

- [x] VirtualESP32 at top (bus-based pins)
- [x] SerialPort context manager with boot delay
- [x] Optional PROG-mode connection check (`-c`, `?` → `Connected\n`)
- [x] `-c` option (check and exit)
- [x] Port + baud display before operations
- [x] Terminal mode (bidirectional bridge)
- [x] Ctrl+C to exit cleanly
- [x] Follows rv8flash.py patterns
- [x] 15/15 tests passing

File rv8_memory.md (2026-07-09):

# RV8 Project — Memory

**Last updated**: 2026-06-26

## Focus: RV8GR student build + RV8-R FullHW investigation

### Active folders:
- `RV8GR/` — active CPU design (33 logic + ROM + RAM = 36 packages, student baseline contract, labs, Verilog benches, gate-level sim passing)
- `Programmer/` — ESP32 board (dual ZIF/RV8-Bus mode, firmware+tools verified, 36 current tests)
- `RV8/` — microcode variant (28 chips, Verilog 8/8, reference)
- `RV8R/` — FullHW RAM-register variant (49 logic + 4 ROM/RAM = 53 packages, full RV8-style TTL hardware path, RTL/KiCad/generator migration pending)
- `RV8G/` — full ISA no-microcode variant (38 chips, concept)

### Current version: v4.2

### What was done today (2026-06-26):
1. Added RV8GR student build guardrails:
   - Student Baseline Contract in README and build plan
   - clear reading order for students, teachers, debug, wiring, and KiCad work
   - temporary-wire removal checkpoints in the incremental build plan
   - probe-point map in the physical debug plan
   - future-only warnings for hardware IRQ vectoring and ROM banking
2. Cleaned RV8GR generated artifacts:
   - removed VCD/VVP traces, Python caches, and Zone.Identifier metadata
   - updated `.gitignore` for `*.pyc` and `*:Zone.Identifier*`
3. Verified RV8GR:
   - assembler tests: 11 pass
   - Python chip sim: 8 CPU tests pass
   - wiring verifier: all wiring verified
   - RTL benches: full, IRQ, SETDP, tasks, assembler ROM, opcode sweep all pass
   - opcode sweep: 512 cases pass

4. Hardened Programmer/RV8GR integration:
   - confirmed dual ZIF-direct and RV8-Bus in-system programming paths
   - fixed RUN-mode bus release and terminal handshake boundary
   - added RV8GR `program/verify --base 0x0000` CLI aliases
   - regenerated Programmer KiCad PDF/SVG exports with KiCad 10.0.4
   - documented ROM `/WE -> /WR` final wiring and AT28C256 SDP limitation
5. Verified integration:
   - Programmer tests: 36 pass
   - RV8GR wiring verifier: all wiring verified
   - RV8GR assembler tests: 11 pass
6. Promoted RV8-R to FullHW:
   - old 19-chip reduced sketch is now legacy design history
   - FullHW target is 49 logic chips + 2 microcode ROM + 1 program ROM + 1 RAM = 53 packages
   - full-ISA hardware paths are real in docs for PC load/save, ALU logic, register addressing, fast page, stack, IRQ entry, and IRET
   - control is now 16-bit direct-control microcode with 15-bit address `{IRQ_ACTIVE,C,Z,step[3:0],opcode[7:0]}`
   - existing `RV8R/tools/microcode_gen.py` is legacy 14-bit prototype; FullHW generator, RTL, and KiCad proof are pending

### Key design facts:
#### RV8GR student baseline
- 33 logic chips + ROM + RAM = 36 packages
- 18 instructions, 3-cycle (T0/T1/T2), no microcode
- Clock: 1 MHz breadboard (official), 4 MHz PCB
- Horizontal control: opcode = control word directly
- IRQ is polling-only in V2; no hardware vector
- ISA frozen, design signed off, ready for physical build

#### RV8-R FullHW investigation
- 49 logic chips + 4 ROM/RAM packages = 53 total
- ROM-low boot: Program ROM `$0000-$7FFF`, RAM `$8000-$FFFF`
- registers live in high RAM at `$FFF8-$FFFF`
- fast page is `$FF00+imm8`, with `$FFF6-$FFFF` reserved for IRQ save slots and registers
- FullHW uses 2 microcode ROMs, 16-bit direct-control word, 15-bit microcode address
- `SRL` remains software macro; `LUI` is assembler pre-shift
- not ready for physical build until FullHW microcode generator, RTL/testbench, KiCad/ERC, and Programmer/RV8-Bus pin audit are done

### RV8-Bus pinout (40-pin):
```
pin 1-16: A[0:15], pin 17-24: D[0:7]
pin 25: CLK, pin 26: /RST, pin 27: /WR, pin 28: /RD
pin 29: /IRQ, pin 30: /SLOT1, pin 31: /SLOT2, pin 32: T2
pin 39: VCC, pin 40: GND
```

### Programmer board:
- ESP32-WROOM-32 + 2× TXS0108E + 2× 74HC595
- Dual mode, use exactly one at a time:
  - ZIF direct: insert bare AT28C256 in Programmer ZIF, disconnect RV8-Bus
  - RV8-Bus in-system: leave ZIF empty, connect Programmer to RV8GR bus, hold CPU reset during flash
- GPIO: 23(SR_DATA), 18(SR_CLK), 19(SR_LATCH), 4(/RST), 16(/WR), 17(/RD)
- Data: GPIO {13,12,14,27,26,25,33,32} = D[7:0]
- RUN mode releases `/WR` and `/RD`; `rv8term.py` terminal mode does not use the PROG-only `?` handshake
- `rv8flash.py` accepts both legacy flags and RV8GR aliases: `program FILE --base 0x0000`, `verify FILE --base 0x0000`
- AT28C256 caveat: current firmware performs normal byte write cycles; use SDP-disabled chips or add SDP unlock support before protected parts

### Next steps:
- Build RV8GR physically from `RV8GR/doc/labs/README.md`
- Use `RV8GR/doc/06_debug_plan.md` probe map during bring-up
- Create KiCad schematics from `RV8GR/doc/10_kicad_modules.md` (6 sheets)
- Order parts for physical build
- RV8-R FullHW task list is now `RV8R/doc/03_fullhw_task_plan.md`
- RV8-R FullHW immediate task: freeze the exact 16-bit direct-control word before writing the 15-bit microcode generator
- RV8-R FullHW next sequence: control word -> microcode generator -> RTL/testbench -> KiCad/ERC -> Programmer/RV8-Bus audit

### Resume update (2026-07-09):
- Obsolete `RV8GR-V1/` reference snapshot was removed; use `RV8GR/` as the only RV8GR folder.
- RV8-R FullHW Task 1 is done: the 16-bit direct-control word is frozen in `RV8R/doc/00_design.md` and mirrored in `RV8R/doc/02_wiring_guide.md`.
- Frozen safe default word is `0x028D`.
- Next immediate task is now Task 2: replace `RV8R/tools/microcode_gen.py` with the 15-bit address / 16-bit output FullHW generator.
- The new generator must emit the safe default for unused states and reject illegal IBUS owner combinations.

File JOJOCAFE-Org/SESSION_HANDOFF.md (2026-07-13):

# Session Handoff

Updated: 2026-07-12

## Current State

- RV8 `team-setup` is clean and pushed through `1351bf9 Document RV8GR release
  gate checkpoint`; the preceding `3dc9c38` makes behavioral Verilog and
  `sim/verify_wiring.py` fail nonzero on detected mismatches.
- Components `main` is clean and pushed through `498f684 Save team skills
  checkpoint`.
- The current external Components run passes `sim/verify_components.py` for 16
  part types and 36 packages, and the whole-system virtual fault screen has no
  pin-truth, edge-polarity, output-contention, or deadband findings.
- Reset is now explicit everywhere: U8 is `000` while `/RST` is LOW; the first
  active clock after reset release establishes T0 and begins opcode fetch.
- B-007 remains non-physical. Start physical Stage 1 next: board/BOM check,
  ROM programming verification, rails, reset/clock capture, then 100 manual
  T0/T1/T2 ticks recorded in `RV8GR/doc/07_real_build_timing_log.md`.
- B-010 example ASM programs are implemented and assembler-verified.
- B-011 is phase 1 only: `RV8GR/programs/basic_min.asm` is a BASIC-style ROM
  smoke test with `sim/test_basic_min.py`; it is not an interactive BASIC
  interpreter yet.
- Components remote: `git@github.com:JOJOCAFE/Components.git`, branch `main`.
- RV8 remote: `git@github.com:JOJOCAFE/RV8.git`, branch `team-setup`.
- RV8 team/skill updates are in this repo under `JOJOCAFE-Org/`; current work merges the latest Components skill/status into the RV8 team operating docs.
- RV8GR verification tooling now writes Verilog `.vvp/.vcd` artifacts to `RV8GR_BUILD_DIR` or `/tmp/rv8gr-verilog`, so source folders stay clean while testbenches still support manual local VCD names.
- RV8GR Python chip behavior tests now run from repo root with `python3 -B RV8GR/sim/chips/test_chips.py`.
- RV8GR now separates CPU logical tests from Components virtual physical tests. CPU logic is documented in `RV8GR/doc/08_cpu_logical_test_protocol.md`; Components remains responsible for pin/bus/edge/delay/noise screens.
- `RV8GR/doc/11_four_model_equivalence.md` is the student-facing guide explaining why RV8GR has two Python sims, two Verilog models, and one shared all-ISA equivalence source.
- `RV8GR/doc/12_doc_integrity_audit.md` records the doc-by-doc integrity pass against Python/Verilog truth. No packaged doc zip is used for now; Markdown files remain the source of truth.
- `RV8GR/doc/00_design_isa.md`, `02_instruction_trace.md`, `03_bank_switch.md`, and `04_understand_by_module.md` were carefully checked and corrected against the wiring guide, chip-level Verilog, Python sims, and four-model equivalence stream.
- RV8 team skills were refreshed so future agents preserve current v1.0 truth: 36 packages, 18 instructions, `SETDP`, ROM `/WE` runtime-inactive, `DI` inert, polling IRQ only, `/IRQ` release/rising-edge latch, and student docs derived from `00_design_isa.md` + `01_wiring_guide.md`.
- `RV8GR/sim/components_chip_sim.py` is the standalone Components-backed Python CPU runner using vendored `chiplib` chip definitions.
- `RV8GR/sim/test_cpu_logical_protocol.py` is the executable protocol test suite. It assembles directed CPU programs and scoreboards both `CPUSim` and `ComponentsCPUSim`.
- RV8GR Verilog signoff rule: behavioral `rtl/rv8gr_cpu.v` benches are comparison only. Shipping confidence must include `rtl/rv8gr_chip_level.v` compiled with Components TTL-chip Verilog models (`ttl_74hc*`, `62256`, `at28c256`) through the chip-level runner scripts.
- `RV8GR/tools/run_dual_verilog_compare.sh` is now part of signoff. It runs behavioral and chip-level Verilog together on `RV8GR/programs/all_isa_equivalence.asm` and scoreboards `PC`, `AC`, `Z`, `PG`, `DP`, `IE`, `IRQ_FF`, and key RAM writes. The current dual run covers every frozen ISA command at least once.
- `RV8GR/tb/tb_rv8gr_dual_compare.v` exports `VERILOG_CHECKPOINT` lines. `RV8GR/tools/check_python_verilog_equivalence.py` assembles the same `all_isa_equivalence.asm` source and verifies both Python CPU sims (`CPUSim`, `ComponentsCPUSim`) match the 55-checkpoint Verilog stream, final state, and RAM checkpoints.
- Programmer B-012 is prepared for field testing in `Programmer/FIELD_TEST_PROTOCOL.md`. Current virtual preflight is 51 mock tests across `rv8flash`, `rv8term`, and `rv8ram-boot`; physical ZIF Direct and RV8-Bus evidence is still required before B-012 is DONE.
- `Programmer/KICAD/.history` is clean at its nested `master` checkout.
- `RV8GR/doc/07_real_build_timing_log.md` is now part of the saved RV8GR physical timing/bus-race/edge/propagation-delay protocol. Use it during real build evidence capture and mirror reusable chip/circuit findings into Components.
- Current RV8GR baseline sync pass fixed ROM map wording, U34 immediate-buffer
  ownership, `/ADDR_MODE` polarity notes, buildable oscillator-module clock
  wording, canonical BOM quantities, DI inert status, and ROM `/WE` ownership
  checks stayed consistent with CPU-runtime inactive/programmer-only ownership.
- `NOT` is now an assembler pseudo-instruction only. It emits `XORI $FF` and is
  covered by assembler, Python, and Verilog ROM tests through
  `RV8GR/tb/tb_rv8gr_not.v`.
- `RV8GR/rtl/rv8gr_cpu.v` now has explicit `` `timescale 1ns/1ps``; the previous
  Icarus Verilog timescale warnings are gone.

## Components Library Facts

- Shared library path: `/home/jo/kiro/Components`.
- Python package path: `/home/jo/kiro/Components/python`.
- Student guide: `/home/jo/kiro/Components/docs/STUDENT_GUIDE.md`.
- Service/CLI/API contract: `/home/jo/kiro/Components/docs/SERVICE_CONTRACT.md`.
- Python simulator uses DIP-style pin number/name access and propagation-delay scheduling.
- `StimulusController` default channels: 64 inputs (`IN0..IN63`) and 8 clocks (`CLK0..CLK7`).
- Clock stimulus is physical-pin and edge aware:
  - default rising edge
  - 74HC73 and 74HC112 use falling-edge `CP`
  - 74HC74 sections, 74HC595 `SRCLK`/`RCLK`, and 74HC593 `RCK`/`CCK` are pin-specific
- `chiplib.loader` preloads `.bin`, Intel HEX, or text-hex data into ROM/RAM `.data`.
- Python and Verilog component behavior must remain compatible.
- Python schematic backend now supports buses, pull-up/pull-down style normal states, probes/test logic, simple JSON-friendly schematics, and netlist/Verilog export paths for RV8GR-style chip-level work.
- Virtual physical checker command:
  `PYTHONPATH=python python3 -B -m chiplib.cli circuit-faults examples/circuits/RV8GR_WholeSystemChipLevelVirtual/circuit.json`
- Checker focus: pin-number/name/active-low mistakes, unsafe output-output wiring, missing edge polarity statements, and timing/noise risk on shared or stress nets.
- Virtual R/C and delay-noise checks are early-risk instruments; physical build still needs real voltage, frequency, wiring, scope/logic-analyzer, and timing evidence.

## Verification Evidence

Last green checks:

```sh
cd /home/jo/kiro/RV8
python3 -B RV8GR/sim/chip_sim.py
python3 -B RV8GR/sim/components_chip_sim.py
python3 -B RV8GR/sim/test_cpu_logical_protocol.py
python3 -B RV8GR/sim/test_basic_min.py
python3 -B RV8GR/tools/check_python_verilog_equivalence.py
python3 -B RV8GR/sim/verify_wiring.py
python3 -B RV8GR/sim/soft_debug.py
python3 -B RV8GR/tools/test_rv8gr_asm.py
python3 -B RV8GR/sim/chips/test_chips.py
python3 -B RV8GR/sim/verify_components.py
python3 -B Programmer/tools/test_rv8flash.py
python3 -B Programmer/tools/test_rv8term.py
python3 -B Programmer/tools/test_rv8ram-boot.py
cd /home/jo/kiro/RV8/RV8GR
tools/run_dual_verilog_compare.sh
tools/run_all_verilog_tb.sh

cd /home/jo/kiro/Components
PYTHONPATH=python python3 -B -m chiplib.cli validate examples/circuits/nand.json
PYTHONPATH=python python3 -B -m chiplib.cli run examples/circuits/nand.json
PYTHONPATH=python python3 -B -m chiplib.cli circuit-faults examples/circuits/RV8GR_WholeSystemChipLevelVirtual/circuit.json
PYTHONPATH=python python3 -B -m chiplib.api --stdio
PYTHONPATH=python python3 -B -m tests.test_cli
PYTHONPATH=python python3 -B -m tests.test_api
PYTHONPATH=python python3 -B -m tests.test_contracts
git diff --check
```

Expected pass markers:

- RV8GR Python, chip behavior, Components package coverage, behavioral Verilog benches, TTL-chip Components Verilog system benches, and all-ISA dual Verilog scoreboard pass.
- Current four-model equivalence marker: `Verilog checkpoint stream: 55 checkpoints`; both Python sims match Verilog checkpoints, final state, and RAM checkpoints.
- CLI/API tests pass.
- `circuit-faults` accepts the RV8GR whole-system virtual circuit with zero pin, bus-contention, edge-polarity, or propagation-delay/deadband findings.
- `git diff --check` reports no whitespace errors.

## Next Session

1. Start RV8GR physical Stage 1: board/BOM photo, ROM program-and-verify
   transcript, rail/decoupling check, reset/clock scope capture, and 100 manual
   ring-counter ticks. Record each result in `RV8GR/doc/07_real_build_timing_log.md`.
2. Keep physical B-007 blocked until hardware photos/logs/test output exist; cite the non-physical report separately.
3. Use B-010 example ASM programs for ROM/programmer prep once the physical ROM workflow is ready.
4. Treat B-011 as a test ROM only until RV8-Bus I/O and a runtime model are chosen.
5. When Programmer hardware exists, execute `Programmer/FIELD_TEST_PROTOCOL.md` and record command transcripts, readback hashes, and PROG/RUN bus-release evidence.
6. Continue remaining Components full-catalog mappings only after checking module ports and pin docs.
7. Keep RV8GR physical-build docs and lab scripts aligned with `RV8GR/doc/01_wiring_guide.md`.
8. When editing student docs, keep them explanatory: do not let `04_understand_by_module.md` override `00_design_isa.md` or `01_wiring_guide.md`; mention bus contention, active-low polarity, edge-trigger timing, and physical-vs-virtual limits explicitly.
9. Use Components schematic backend and `circuit-faults` as the reusable Python-first path for future UI/block/JSON/netlist work.
10. When chip behavior changes, verify with Components Python tests first, run Verilog smoke tests and `tools/run_dual_verilog_compare.sh` when RTL behavior is touched, and rerun virtual physical checks before circuit/system signoff.
11. Later Components task: review chip JSON/component definition output for student readability and document system wiring commands.
12. For RV8, do not stage unrelated dirty files unless Jo explicitly asks.

## Known Follow-Ups

- `74HC150` and `74HC260` were removed from the active Components catalog because manufacturer-verified HC-family DIP evidence was not available.
- SST39SF010A Python/Verilog write-trigger semantics are aligned for the simplified flash model: write occurs on the falling edge of `/WE` while selected with `/OE` high.
- RV8GR KiCad project files were kept under `RV8GR/Kicad/`; accidental root report/output files and duplicate `XCPU (1).pdf` were removed.
- `RV8GR/.gitignore` now ignores generated KiCad local artifacts such as `.kicad_prl`, backup folders, lock files, reports, EDF output, and Python cache.
- RV8GR canonical folder is `RV8GR/`; `RV8GR-V2/` was renamed and docs/tool paths were cleaned.
- Top-level `README.md` now treats `RV8-G` as a concept/history item, not an active folder in this checkout.
- Do not stage unrelated RV8 dirty files unless Jo explicitly asks.

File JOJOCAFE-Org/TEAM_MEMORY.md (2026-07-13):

# Team Memory

Shared knowledge for all agents. Update when significant facts change.

## Project: RV8 CPU Family

- **Ownership**: Team JOJOCAFE owns the entire RV8 project
- **Main focus**: RV8-GR (34 logic chips, architecture frozen v1.0)
- Target: minimal 8-bit CPUs students can build on breadboards
- Language: Thai docs, English code/comments
- Repository: /home/jo/kiro/RV8

## Variants (all under our care)

| Variant | Status | Priority |
|---|---|---|
| RV8-GR | **Active focus** — frozen, ready for physical build | 🔴 Now |
| RV8-R FullHW | Queued — 49 logic / 53 total packages, full RV8-style ISA hardware path | 🟢 Future |
| RV8-G | Concept/history — full ISA, no microcode, 38 logic chips, no active folder | 🟢 Future |
| RV8 | Reference/exploratory only | 🟢 Archive |

## Architecture Quick Reference

- 8-bit data, 16-bit address, 64KB (ROM $0000-$7FFF, RAM $8000-$FFFF)
- Accumulator-based, 18 instructions, 3-cycle (T0/T1/T2)
- Horizontal control: opcode byte = control word, no decoder
- Encoding: [7]SUB [6]XOR [5]MUX [4]AC_WR [3]SRC [2]STR [1]BR [0]JMP
- Chips: 34 logic (U1-U34) + AT28C256 ROM + 62256 RAM
- Clock: 1 MHz breadboard signoff; 2 MHz optional breadboard stress; 5 MHz
  optional PCB-only experiment

## Verification Status

- Verilog: aggregate behavioral/chip-level suite passes, including 512-opcode
  sweep and 55-checkpoint dual comparison; behavioral mismatch paths fail hard
- External Components: 16 part types / 36 packages and whole-system virtual
  fault screen pass with zero findings
- Gate-level: chip_sim.py 8/8, soft_debug.py 4/4
- Physical: NOT YET BUILT

## File Paths (source of truth)

| What | Where |
|---|---|
| ISA + design | `doc/00_design_isa.md` |
| Wiring (pin-level) | `doc/01_wiring_guide.md` |
| Verilog CPU | `rtl/rv8gr_cpu.v` |
| Testbenches | `tb/tb_rv8gr_*.v` |
| Gate sim | `sim/chip_sim.py` |
| Assembler | `tools/rv8gr_asm.py` |
| Labs (Thai) | `doc/labs/` |

## Shared Components Library

- Local path: `/home/jo/kiro/Components`
- GitHub: `git@github.com:JOJOCAFE/Components.git`
- Branch: `main`
- Initial pushed commit: `f674250 Initial shared component library`
- Latest known pushed commit: `498f684 Save team skills checkpoint`
- Contents: canonical chip definitions, reusable 74HC Verilog models, memory models, DIP/PDIP pinout docs, circuit libraries, student docs, CLI/API contract docs, smoke tests, virtual physical-system checkers, and retained manufacturer datasheet evidence.
- Python library: `/home/jo/kiro/Components/python`, pin-level DIP-style chip models, ROM/RAM image loader, 64 input stimulus channels (`IN0..IN63`), 8 clocks (`CLK0..CLK7`), propagation-delay simulation, edge-aware clock dispatch, JSON-friendly schematics, buses, pull defaults, probes/test logic, netlist generation, Verilog export, and CLI/API workflows.
- Student guide: `/home/jo/kiro/Components/docs/STUDENT_GUIDE.md` explains Components for CLI and API use.
- Responsibility: Pim routes; Bank owns package/service/circuit-library boundaries and virtual checker architecture; Ohm owns physical pinout, DIP package evidence, and breadboard realism; Mint owns reusable Verilog models/tests and RTL edge compatibility; Bam owns Python backend, CLI/API, schematic JSON, and virtual test instruments; Fern verifies package evidence, source references, tests, bus-race/timing/edge proofs, and release confidence; Noon owns beginner clarity, student examples, and learner-facing docs.
- `74HC150` and `74HC260` were removed from the active Components catalog because no manufacturer-verified HC-family DIP evidence was available.
- Rule: pinout docs are physical wiring artifacts; do not create pin tables from memory. Require manufacturer datasheet evidence and explicit DIP/PDIP or equivalent through-hole package proof.
- Rule: Python and Verilog component behavior must remain compatible for observable controls, output polarity, tri-state behavior, async controls, memory behavior, and rising/falling clock edges.
- Python schematic backend supports buses, pull-up/pull-down style default states, probes/test logic, JSON-friendly script mapping, netlist generation, and Verilog export for chip-level workflows.
- SST39SF010A Python/Verilog write-trigger semantics are aligned: the simplified flash model writes on the falling edge of `/WE` while selected with `/OE` high.
- Virtual physical checker command:
  `PYTHONPATH=python python3 -B -m chiplib.cli circuit-faults examples/circuits/RV8GR_WholeSystemChipLevelVirtual/circuit.json`
- The checker must catch four common AI/circuit mistakes before circuit/system-level work: wrong pin number/name/active-low marker; output-output wiring without bus/enable proof; missing positive/negative or rising/falling edge statement for edge-sensitive chips; and shared-bus or stress-net timing without R/C, delay-noise, setup/hold, float, or deadband coverage.
- Virtual R/C and delay-noise components are test instruments for finding risk early. They do not replace physical voltage, frequency, scope/logic-analyzer, or breadboard wiring tests at 4.5 V, 5.0 V, 5.5 V and target clock rates.
- Future Components lane: review chip JSON/component definition output for student readability and document the system wiring commands used by Components.

### Datasheet Access Notes

- Prefer direct manufacturer PDFs when they prove the required package.
- Use AllDatasheet only as locator/download helper when direct manufacturer access is hard.
- AllDatasheet reliable route: search `https://www.alldatasheet.com/view.jsp?Searchword=<part>`, open exact result, open `/datasheet-pdf/view/<id>/<maker>/<part>.html`, parse the PDF.js iframe `file=` URL ending in `/datasheet.pdf`, download it, and confirm `%PDF`.
- Alternate AllDatasheet route: open `/datasheet-pdf/download/<id>/<maker>/<part>.html`, parse the visible 5-digit code and hidden `tmpinfo1aa`, POST `innum=<code>&tmpinfo1aa=<token>`, then confirm `%PDF`.
- Keep only the final cited manufacturer PDF in `Components/source`; remove failed downloads, duplicates, HTML dumps, and `Zone.Identifier` files.

## Current Sprint

- [ ] Order parts for physical build
- [ ] Build labs 01-14 on breadboard (1 MHz)
- [ ] Write example programs (.asm collection)

## Queued Projects

- RV8-R FullHW: 49 logic / 53 total packages, full RV8-style ISA hardware path
- RV8-G: 38 logic chips, full ISA, no microcode concept/history item

## Critical Rules (all agents must know)

- RV8GR baseline is 34 logic chips + ROM + RAM = 36 packages. No additions without architect approval.
- 64 forbidden opcodes: (opcode & $0C) == $0C (SRC+STR bus fight)
- A15 chip select: ROM active when A15=0, RAM active when A15=1
- Architecture frozen v1.0 — no design changes until physical build validates
- Shared component pinouts must cite manufacturer sources and DIP/PDIP evidence before breadboard use.
- Shared Components simulator backend must remain frontend-agnostic for future JS/web or Python UI use.
- RV8GR virtual physical checks must run before treating Components-derived chip/circuit/system behavior as ready for physical build steps.

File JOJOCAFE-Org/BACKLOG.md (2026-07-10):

# Project Backlog

Last updated: 2026-07-10

## Priority Legend
- 🔴 P0 — Must do now (blocks physical build)
- 🟠 P1 — Should do this sprint
- 🟡 P2 — Next sprint
- 🟢 P3 — Queued / future

---

## 🔴 P0 — Physical Build (RV8-GR)

| # | Task | Owner | Status |
|---|---|---|---|
| B-001 | Order parts (BOM finalized) | Boss (Jo) | ⬜ TODO |
| B-002 | Build Lab 01-03 on breadboard (clock, reset, ROM) | Ohm + Noon | ⬜ TODO |
| B-003 | Build Lab 04-07 (fetch, AC, ALU, store) | Ohm | ⬜ TODO |
| B-004 | Build Lab 08-10 (branch, jump, Z-flag) | Ohm | ⬜ TODO |
| B-005 | Build Lab 11-14 (SETDP, IRQ, full integration) | Ohm | ⬜ TODO |
| B-006 | Flash test ROM via Programmer board | Bam + Ohm | ⬜ TODO |
| B-007 | Run full ISA test on physical hardware | Fern | ⛔ BLOCKED — non-physical report available; hardware evidence still required |

## 🟠 P1 — Sprint Support

| # | Task | Owner | Status |
|---|---|---|---|
| B-010 | Write example .asm programs (blink, counter, echo) | Bam | ✅ DONE — assembler-verified |
| B-011 | Write BASIC interpreter ROM (minimal) | Bam | 🟡 PHASE 1 — `programs/basic_min.asm` runtime smoke + Python regression; interactive interpreter needs I/O/runtime design |
| B-012 | Programmer field test protocol and hardware evidence | Bam + Fern | 🟡 READY FOR FIELD TEST — 51 mock tests pass; physical evidence required |
| B-013 | Gate-level sim: add remaining .bin coverage | Mint + Fern | ✅ DONE — replaced by all-ISA dual Verilog scoreboard plus existing opcode sweep |
| B-014 | Update wiring guide if physical build reveals discrepancies | Ohm + Noon | ⬜ TODO |

## 🟡 P2 — Post-Build / Polish

| # | Task | Owner | Status |
|---|---|---|---|
| B-020 | PCB layout (4 MHz version) | Ohm | ⬜ TODO |
| B-021 | RV8-Bus connector finalization | Bank + Ohm | ⬜ TODO |
| B-022 | Video/photo documentation of physical build | Noon | ⬜ TODO |
| B-023 | Student workshop dry run (labs 01-14) | Noon + Pim | ⬜ TODO |
| B-024 | Game ROM (simple Snake or Pong) | Bam | ⬜ TODO |

## 🟢 P3 — Future Projects

| # | Task | Owner | Status |
|---|---|---|---|
| B-030 | RV8-R FullHW architecture continuation (49 logic / 53 total packages) | Bank | ⬜ TODO |
| B-031 | RV8-R microcode generator (15-bit direct-control) | Mint + Bank | ⬜ TODO |
| B-032 | RV8-R Verilog model + testbenches | Mint + Fern | ⬜ TODO |
| B-033 | RV8-G architecture exploration (38 chips, no microcode) | Bank | ⬜ TODO |
| B-034 | KiCad schematic for RV8-R | Ohm | ⬜ TODO |

---

## Completed

| # | Task | Completed | By |
|---|---|---|-----|
| — | Architecture frozen v1.0 | 2026-06-14 | Bank |
| — | Programmer design finalized | 2026-06-14 | Ohm |
| — | 14 hardware labs written | 2026-06-15 | Noon |
| — | 5 Verilog TBs pass + 512-opcode sweep | 2026-06-14 | Mint + Fern |
| — | Gate-level sim 8/8 pass | 2026-06-14 | Mint |
| — | Assembler (page-safe, 18 opcodes + macros) | 2026-06-14 | Bam |
| — | Memory map swap (ROM $0000, RAM $8000) | 2026-06-15 | Bank |
| B-010 | Example ASM programs: blink, counter, echo | 2026-07-09 | Bam + Fern |
| B-013 | All-ISA dual Verilog scoreboard: behavioral vs TTL chip-level | 2026-07-10 | Mint + Fern |

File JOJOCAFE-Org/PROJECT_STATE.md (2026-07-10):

# Project State

## Owner: Team JOJOCAFE-Org

The team owns the entire RV8 project. All variants, all deliverables.

## Active Target: RV8-GR (Student Baseline)

- **Status**: Architecture frozen v1.0 — ready for physical build
- **Chips**: 34 logic + ROM + RAM = 36 packages
- **ISA**: 18 instructions (17 + SETDP), all verified
- **Verification**: behavioral + chip-level Verilog TBs pass, all-ISA dual Verilog scoreboard pass, 512-opcode sweep, gate-level sim 8/8
- **ROM tests**: `NOT` pseudo-instruction ROM test and B-011 `basic_min.asm`
  BASIC-style smoke ROM pass in current regression
- **Labs**: 14 hardware labs written (Thai, middle school level)
- **Clock**: 1 MHz breadboard target

## Current Sprint & Backlog

- **Backlog**: see `BACKLOG.md` (19 items, prioritized P0-P3)
- **Sprint 1**: see `SPRINT.md` (Physical Build Kickoff, individual task lists)

### Sprint 1 Summary
- [ ] Order parts for physical build
- [ ] Build Labs 01-14 on breadboard (sequential, verify each)
- [ ] Flash test ROM via Programmer
- [x] Write example .asm programs (B-010 implemented and assembler-verified)
- [x] B-011 phase 1 BASIC-style ROM smoke test implemented
- [ ] Full ISA test on physical hardware (B-007 blocked until hardware evidence exists; non-physical report available)

## Next Projects (queued)

- RV8-R FullHW: 49 logic chips / 53 total packages, full RV8-style ISA investigation path
- RV8-G: 38 logic chips, full ISA, no microcode concept/history item

## Recent Decisions

| Date | Decision | By |
|---|---|----|
| 2026-07-09 | Shared Components repo created and pushed to `git@github.com:JOJOCAFE/Components.git`; component-library skill added for agent ownership and datasheet workflow | Pim |
| 2026-07-09 | Components Python simulator added/updated with DIP pin models, ROM/RAM image loading, 64 input stimulus channels, 8 clocks, and edge-aware clock dispatch; pushed through `f4ea985` | Pim |
| 2026-07-09 | Components Python schematic backend, buses, pull defaults, probes/test logic, netlist, and Verilog export path added; pushed through `6bc7ee0` | Pim |
| 2026-07-09 | RV8GR canonical rename/docs/labs cleanup and top-level README status fixes pushed through `1470963` | Pim |
| 2026-07-09 | B-010 example ASM programs implemented and assembler-verified; B-007 non-physical verification report available while physical B-007 remains blocked for hardware evidence; Components netlist mappings verified and pushed through `a2ee62c` | Pim |
| 2026-07-10 | Components latest student guide, CLI/API contract, `circuit-faults` virtual physical checker, and future student-friendly chip JSON/wiring-command lane merged into RV8 team operating docs; Components pushed through `87bcfdc` | Pim |
| 2026-07-10 | RV8GR all-ISA dual Verilog scoreboard added; behavioral `rv8gr_cpu.v` and chip-level `rv8gr_chip_level.v` now compare `PC`, `AC`, `Z`, `PG`, `DP`, `IE`, `IRQ_FF`, and key RAM writes; pushed through `622e41a` | Pim |
| 2026-07-10 | RV8GR source-of-truth doc pass completed for design ISA, instruction trace, bank switch, and module-understanding docs; team skills refreshed to prevent stale IRQ/DI/bus/ROM assumptions; packaged doc zip removed for now | Pim |
| 2026-07-11 | RV8GR baseline sync and test-ROM checkpoint: U34/BOM/clock docs aligned, `NOT` pseudo-instruction covered by Python/Verilog ROM tests, B-011 phase 1 BASIC-style ROM smoke added, and Verilog timescale warnings removed | Pim |
| 2026-06-15 | Memory map swapped: ROM $0000-$7FFF, RAM $8000-$FFFF | architect |
| 2026-06-14 | Architecture frozen v1.0 — no more changes until physical build | architect |
| 2026-06-14 | Programmer design finalized (ESP32 + TXS0108E + 74HC595) | hw-coder |

## Known Issues

No RV8-GR design blockers. Physical B-007 verification is blocked until
hardware evidence exists; a non-physical B-007 verification report is available.
Non-physical Verilog confidence now includes the all-ISA dual scoreboard, but
that still does not replace measured physical build evidence.
B-011 is currently a non-interactive test ROM only; a real BASIC interpreter
still needs an RV8-Bus I/O device and runtime model decision.
Shared Components removed `74hc150` and `74hc260`
from the active catalog because manufacturer-verified HC-family DIP evidence
was not available.

Shared Components known follow-ups:

- Keep Components Python schematic backend compatible with future UI/block/JSON editing and RV8GR chip-level netlist/Verilog export.
- Components student guide and virtual physical checker handoff is verified and pushed through `87bcfdc`.
- Use `circuit-faults` before treating Components-derived RV8GR chip/circuit/system behavior as ready for physical build steps.
- Later Components cleanup: review chip JSON/component definition output for student readability and document system wiring commands.
- SST39SF010A Python/Verilog write-trigger semantics are now aligned for the simplified flash model: write occurs on the falling edge of `/WE` while selected with `/OE` high.

Documentation follow-ups:

- Treat `RV8GR/doc/00_design_isa.md` and `RV8GR/doc/01_wiring_guide.md` as source of truth. `04_understand_by_module.md` is a student explanation only.
- Do not use `RV8GR/doc/RV8GR-Doc.zip` for now; keep Markdown docs as the live source of truth.

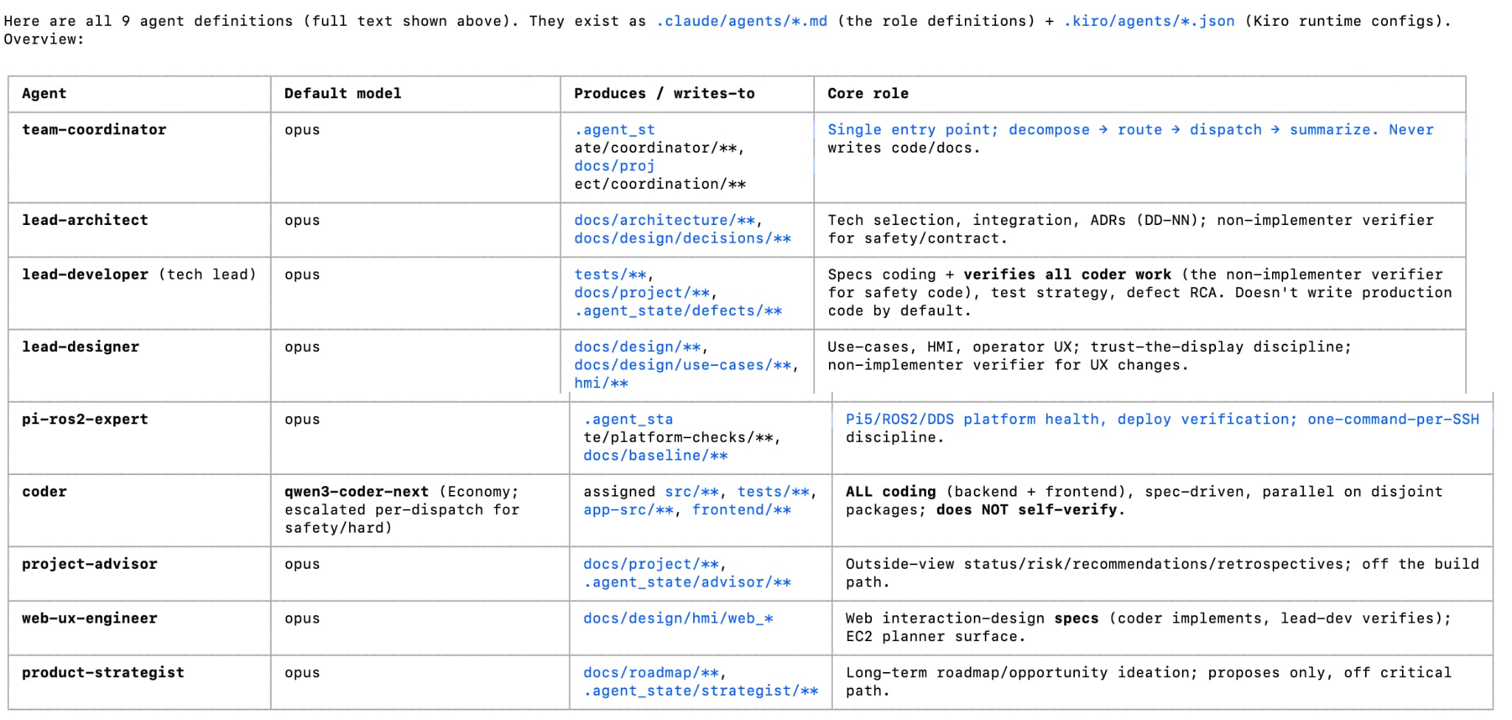
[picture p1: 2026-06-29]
AIRole.jpg

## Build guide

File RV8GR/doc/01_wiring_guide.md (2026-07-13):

# RV8-GR — Wiring Guide (Official)

**34 logic chips + ROM + RAM = 36 packages. Source of truth for physical build.**

---

## Memory Map

```
$0000-$7EFF  ROM application area
$7F00-$7FFF  ROM reserved/available page  ## ********* For Future Use in Rom Switch*##
$8000-$FEFF  RAM application/register/data area (registers at $8000-$8007)
$FF00-$FF0F  RAM (available; future vector area)
$FF10-$FF1F  I/O Slot 1 (/SLOT1 on bus)
$FF20-$FF2F  I/O Slot 2 (/SLOT2 on bus)
$FF30-$FFFF  RAM: available
Reset → $0000
```

> 📌 **Boot Requirements (first 3 instructions in ROM):**
>
> ```asm
> $0000: SETDP $80       ; DP → RAM (registers at $8000-$8007)
> $0002: SETPG $00       ; PG → page 0 (safe jumps)
> $0004: LI $00          ; AC = 0, Z = 1
> ```
>
> Why: PG, DP, AC have no hardware reset (74HC574 has no /CLR pin).
> These 3 instructions don't use SRC/STR, so random DP/PG values are harmless.
>
> **DP ranges:** $80-$FF = RAM (read/write) · $00-$7F = ROM (read only, SB ignored)

---

## Timing Note — Official Clock Target: 1 MHz

### Summary

| Clock | ROM | Status |
|:-----:|:---:|:---:|
| **1 MHz** | 70ns or 150ns | ✅ **Official target** — works with any ROM |
| 2 MHz | 70ns | ✅ Achievable on short-wire breadboard |
| 5 MHz | 70ns | ⚠️ PCB only (experimental) |

### The Worst Case: Fetch After Memory-Access Instruction

After LB/SB/ADD/SUB/XOR/SETPG_R (/ADDR_MODE=0 during T2), the address mux switches from {DP,IRL} back to PC at the T2→T0 boundary. ROM then needs access time before U5 can latch valid data.

**Timing chain** (worst case — fetch after LB/SB):
```
T2→T0 edge (ring counter shifts)
  → /ADDR_MODE returns HIGH (U26 propagation: ~15ns)
    → Mux switches to PC (U15/U29 propagation: ~15ns)
      → ROM sees new address (access time: 70-150ns)
        → U7 buffer (12ns)
          → Data valid on IBUS
            → U5 latches at NEXT T0 rising edge
```

**Time available** = one full clock period (T0 phase duration):

| Clock | Phase period | Worst path (150ns ROM) | Margin |
|:-----:|:---:|:---:|:---:|
| 1 MHz | 1000ns | 15+15+150+12 = 192ns | **+808ns ✅** |
| 2 MHz | 500ns | 192ns | **+308ns ✅** |
| 5 MHz | 200ns | 192ns | **+8ns ⚠️** |

**Why 1 MHz is completely safe**: Even with 150ns ROM + breadboard stray capacitance (~50ns extra), total worst path ≈ 242ns. At 1 MHz each phase is 1000ns — over 700ns margin.

**Why 5 MHz is risky**: 200ns per phase, worst path 192ns on paper. Zero margin for breadboard capacitance. PCB-only.

### Critical Path: ALU (separate concern)

The ALU path (IR → XOR → Adder → AC mux → AC setup) is internal to T2 and does NOT involve ROM timing:

| Stage | Chip | Typ ns |
|---|---|:---:|
| XOR B-mux | 74HC157 | 15 |
| XOR array | 74HC86 | 12 |
| Adder 8-bit ripple | 74HC283 ×2 | 40 |
| AC input mux | 74HC157 | 15 |
| AC setup time | 74HC574 | 10 |
| **Total** | | **~92ns** |

This fits easily within 1 phase at 1 MHz (1000ns).

### Critical Timing Paths (PCB v1.1 Reference)

| Path | Chips | Typ ns | Critical? |
|---|---|:---:|:---:|
| ROM → U7 → U5 (fetch) | ROM + 74HC245 + 74HC574 | 70+12+5 = 87 | **Yes** |
| RAM → U7 → AC (load) | RAM + 74HC245 + mux + 574 | 70+12+15+5 = 102 | **Yes** |
| IR → ALU → AC (execute) | 74HC157+86+283×2+157+574 | 15+12+40+15+5 = 87 | **Yes** |
| Z → Branch → PC (BEQ) | 74HC86 + 00 + 161 | 12+12+15 = 39 | Medium |
| PG → PC load (J) | 74HC574 → 161 D-inputs | 0 (static) | Low |
| DP → Addr mux (SRC) | 74HC574 → 157 | 0+15 = 15 | Low |

> 📌 **PCB layout priority**: Place ROM/RAM/U7/U5 close together (fetch path).
> ALU cluster (U12-U13, U10-U11, U17-U18, U9) as second priority.
> Branch logic (U21, U28, U26) is fast — placement less critical.

### Conclusion

**1 MHz = no timing risk.** Use AT28C256-70ns or even 150ns ROM.
Start breadboard at 1 MHz. Test up to 2 MHz if desired. 5 MHz = PCB/wire-wrap only.

> 📌 **ROM/RAM recommendation: 70ns** (AT28C256-70, 62256-70 or CY7C199-15)
> This gives maximum headroom for future clock increase.
> 150ns parts work fine at 1-2 MHz.

### Master Timing Table (one instruction = 3 phases)

| Phase | Action | Signals Asserted | Data Flow |
|:-----:|---|---|---|
| T0 | Fetch opcode | PC_INC=1, U5 CLK↑ | PC→ABUS→ROM→DBUS→U7→IBUS→U5 |
| T1 | Fetch operand | PC_INC=1, U6 CLK↑ | PC→ABUS→ROM→DBUS→U7→IBUS→U6 |
| T2 | Execute | (depends on instruction) | See below |

**T2 actions by instruction type:**

| Type | Key Signals at T2 | What happens |
|---|---|---|
| ADDI/SUBI | ACC_CLK↑, /IRL_OE=LOW | U34 drives IRL→IBUS→XOR→Adder→mux→AC |
| ADD/SUB/LB | ACC_CLK↑, /ADDR_MODE=LOW | IRL→ABUS→RAM→DBUS→U7→IBUS→ALU→AC |
| XORI | ACC_CLK↑, /IRL_OE=LOW | U34 drives IRL→IBUS→XOR(with AC)→mux→AC |
| LI | ACC_CLK↑, /IRL_OE=LOW | U34 drives IRL→IBUS→XOR(pass)→mux→AC |
| SB | /AC_BUF=LOW, /ADDR_MODE=LOW | AC→U14→IBUS→U7→DBUS→RAM |
| J/BEQ/BNE | /PC_LD=LOW | {PG,IRL}→PC D-inputs→PC loads |
| SETPG | PG_CLK↑ | IBUS→U23 (PG register) |
| SETDP | DP_Load↑ | IBUS→U32 (DP register) |
| EI | EI_decode↑ | U31 IE=1 |
| DI | no v1.0 state change | Software marker; reset clears IE |
| NOP | (nothing) | PC already incremented |

**Key rule**: Only ONE IBUS driver active at T2:
- SRC=0, STR=0 → U34 (immediate from IRL)
- SRC=1 → U7 (RAM data)
- STR=1 → U14 (AC value for store)

### T0/T1/T2 Timing Diagram

```
CLK     __|‾‾|__|‾‾|__|‾‾|__|‾‾|__|‾‾|__|‾‾|__|‾‾|__|‾‾|__|‾‾|__
         1    2    3    4    5    6    7    8    9

T0      ‾‾‾|___________________________________|‾‾‾‾‾‾‾‾‾‾‾‾‾‾‾‾‾
T1      ‾‾‾‾‾‾‾‾‾‾‾‾|_________________________|‾‾‾‾‾‾‾‾‾‾‾‾‾‾‾‾‾
T2      ‾‾‾‾‾‾‾‾‾‾‾‾‾‾‾‾‾‾‾‾‾‾‾|_____________|‾‾‾‾‾‾‾‾‾‾‾‾‾‾‾‾‾
              ↑fetch op    ↑fetch imm    ↑execute
              U5 CLK       U6 CLK        ACC_CLK/PG_CLK/DP_Load
```

(Ring counter U8: shift register cycles T0→T1→T2→T0)

### Bus Ownership (who drives DBUS/IBUS per phase)

| Phase | ABUS driven by | DBUS driven by | IBUS driven by |
|:-----:|:---:|:---:|:---:|
| T0 | PC (U1-U4 via mux) | ROM (data out) | U7 (DBUS→IBUS) |
| T1 | PC (U1-U4 via mux) | ROM (data out) | U7 (DBUS→IBUS) |
| T2, SRC=0 STR=0 | PC (unchanged) | ROM (stale) | **U34** (IRL→IBUS) |
| T2, SRC=1 | DP:IRL (via mux) | RAM (data out) | **U7** (DBUS→IBUS) |
| T2, STR=1 | DP:IRL (via mux) | **U7** (IBUS→DBUS) | **U14** (AC→IBUS) |

Note: During T2+STR, U7 reverses direction (WR_DIR=1) to write DBUS from IBUS.

### Reset & Standalone Boot (boots from ROM at $0000)

**Circuit**: RC (10kΩ + 10µF) → 74HC14 Schmitt → /RST LOW ~100ms at power-on.

**Wiring**:
```
U1 (PC 0-3):   /CLR ← /RST,   /LD ← /PC_LD (U26-11)
U2 (PC 4-7):   /CLR ← /RST,   /LD ← /PC_LD (U26-11)
U3 (PC 8-11):  /CLR ← /RST,   /LD ← /PC_LD (U26-11)
U4 (PC 12-15): /CLR ← /RST,   /LD ← /PC_LD (U26-11)
U8:  /CLR ← /RST
U31: /CLR1,/CLR2 ← /RST
```

**How it works**:
1. Power on: /RST=LOW for ~100ms (RC circuit)
2. U1-U4: /CLR=LOW → PC[15:0] = $0000 (async, immediate)
3. /RST releases → normal mode. PC = $0000 ✅
4. CPU fetches first instruction from ROM!

**Normal jump operation**: /PC_LD=LOW → loads {PG, IRL} into PC.
U3-U4 D-inputs connect to PG (U23 outputs).

**FINAL DECISION for v1.0:**

```
U1-U4: ALL /CLR ← /RST, ALL /LD ← /PC_LD (standard, no diodes)
PC resets to $0000. ROM is at $0000-$7FFF. Boots directly from ROM.
TRUE standalone boot supported — no Programmer needed at power-on.
```

**Register states after reset:**

| Register | Value | How |
|---|:-----:|-----|
| PC | $0000 | /CLR resets all counters to 0 |
| PG | ? | 74HC574 has no /CLR — indeterminate |
| DP | ? | 74HC574 has no /CLR — indeterminate |
| AC | ? | 74HC574 has no /CLR — indeterminate |
| Z | ? | 74HC74 /CLR not connected to /RST |
| IE | 0 | /CLR ← /RST |
| IRQ_FF | 0 | /CLR ← /RST |

> 📌 **Standalone boot is native in v1.0.**
> PC resets to $0000 which is in ROM space. No boot stub needed.
> While reset is asserted U8 is cleared to `000`. The first active clock after
> reset release establishes T0 and begins the first ROM opcode fetch; the
> instruction completes after its normal T0, T1, T2 sequence.

> 📌 **PG, DP, AC are indeterminate at power-on** (74HC574 has no /CLR).
> Boot sequence handles this — see "Boot Requirements" above.
> No hardware fix needed (74HC273 resets to $00, but we need DP=$80).
> - ต้องการ DP=$80 (bit7=1) → ต้อง preset ซึ่งซับซ้อนเกิน
> - Software init (`SETDP $80`) ง่ายกว่า + ไม่เพิ่ม hardware

### Placement Notes (breadboard)

```
U21 (Z flag) and U22 (comparator): place adjacent — minimize /PR wire length.
U10-U11 (adder): place adjacent — carry chain is timing-critical.
U12-U13 (XOR) near U10-U11: minimize ALU path delay.
U5-U6 (IR) near ROM/U7: minimize fetch path delay.
Bypass caps: one per chip, as close to VCC/GND pins as possible.
```

---

## RV8-Bus (40-pin System Bus)

CPU board ↔ Expansion/Programmer ผ่าน 40-pin IDC connector

```
┌──────────────────────────────────────────────────────────┐
│                   RV8-Bus (40 pins)                        │
├──────────────────────────────────────────────────────────┤
│ Pin  Signal    Dir   │ Pin  Signal    Dir                 │
│  1   A0        out   │  2   A1        out                 │
│  3   A2        out   │  4   A3        out                 │
│  5   A4        out   │  6   A5        out                 │
│  7   A6        out   │  8   A7        out                 │
│  9   A8        out   │ 10   A9        out                 │
│ 11   A10       out   │ 12   A11       out                 │
│ 13   A12       out   │ 14   A13       out                 │
│ 15   A14       out   │ 16   A15       out                 │
│ 17   D0        bidir │ 18   D1        bidir               │
│ 19   D2        bidir │ 20   D3        bidir               │
│ 21   D4        bidir │ 22   D5        bidir               │
│ 23   D6        bidir │ 24   D7        bidir               │
│ 25   CLK       out   │ 26   /RST      out                 │
│ 27   /WR       out   │ 28   /RD       out                 │
│ 29   /IRQ      in    │ 30   /SLOT1    out                 │
│ 31   /SLOT2    out   │ 32   T2        out                 │
│ 33   A15       out   │ 34   (reserved)                    │
│ 35   (reserved)      │ 36   (reserved)                    │
│ 37   (reserved)      │ 38   (reserved)                    │
│ 39   VCC (+5V)       │ 40   GND                           │
└──────────────────────────────────────────────────────────┘
```

### Signal Description

| Pin | Signal | Dir | Source | Description |
|:---:|---|:---:|---|---|
| 1-16 | A[15:0] | out | Addr Mux | 16-bit address bus |
| 17-24 | D[7:0] | bidir | U7/ROM/RAM | 8-bit data bus |
| 25 | CLK | out | Oscillator | System clock (1 MHz breadboard target; 5 MHz PCB-only experiment) |
| 26 | /RST | out | RC+button | Active-low reset |
| 27 | /WR | out | /AC_BUF (U26-8) | Write strobe (LOW during T2+STORE) |
| 28 | /RD | out | /T2 or fetch | Read strobe |
| 29 | /IRQ | in | Peripheral | Active-low IRQ request; U31 latches on release/rising edge |
| 30 | /SLOT1 | out | Address decode | I/O slot 1 select |
| 31 | /SLOT2 | out | Address decode | I/O slot 2 select |
| 32 | T2 | out | U8-5 | Execute phase (for expansion timing) |
| 33 | A15 | out | U30-12 | Duplicate for chip select |
| 39 | VCC | — | Power | +5V |
| 40 | GND | — | Power | Ground |

### Bus Timing

```
        ┌───┐   ┌───┐   ┌───┐   ┌───┐
CLK:  ──┘   └───┘   └───┘   └───┘   └──
        T0       T1       T2       T0
A[15:0]: ←── PC ──→←── PC ──→←─ IRL ─→←── PC ──→
D[7:0]:  ←─ ctrl ─→←─ oper ─→←─ data ─→←─ ctrl ─→
/WR:   ─────────────────────┐       ┌───────────
                             └───────┘ (T2+STORE only)
```

---

## Virtual Internal Net Names

These names are wiring labels for the existing physical nets. They do not add
chips or extra buses. Use them on the schematic and breadboard labels so every
module can be wired and debugged without tracing long source/destination notes.

### External RV8-Bus vs Internal Nets

| Name | Scope | Meaning |
|---|---|---|
| RV8_A0..RV8_A15 | 40-pin connector | External address pins. Same physical nets as `ABUS0..ABUS15`. |
| RV8_D0..RV8_D7 | 40-pin connector | External data pins. Same physical nets as `DBUS0..DBUS7`. |
| RV8_CLK, RV8_/RST, RV8_/WR, RV8_/RD, RV8_/IRQ | 40-pin connector | External control pins. |
| PC0..PC15 | CPU internal | Program counter register outputs. |
| IRL0..IRL7 | CPU internal | Operand register outputs from U6. Also feed PC load and address mux. |
| PG0..PG7 | CPU internal | Code page register outputs from U23. Feed PC high load inputs. |
| DP0..DP7 | CPU internal | Data page register outputs from U32. Feed address mux high A inputs. |
| AC0..AC7 | CPU internal | Accumulator outputs from U9. Feed ALU, zero detect, and U14 store buffer. |
| IBUS0..IBUS7 | CPU internal | Internal data bus. Used for instruction fetch, immediates, ALU input, SETPG/SETDP, and store source. |
| DBUS0..DBUS7 | Memory/RV8-Bus | Memory data bus shared by ROM, RAM, U7, and RV8 data pins. |
| ABUS0..ABUS15 | Memory/RV8-Bus | Address mux outputs shared by ROM, RAM, decode, and RV8 address pins. |
| SUM0..SUM7 | CPU internal | 74HC283 adder outputs. |
| XOR_Y0..XOR_Y7 | CPU internal | XOR array outputs. |

Naming rules:
- Bit 0 is always the least significant bit.
- A leading `/` means active-low (`/RST`, `/PC_LD`, `/IRL_OE`).
- A `_N` suffix also means active-low when `/` is awkward in labels (`BUF_OE_N`).
- A `*` after a pin in the bus tables means that chip only drives the bus when
  its output enable is active.

---

## Virtual Internal Buses

### DBUS0..DBUS7 — Memory/RV8 Data Bus

DBUS is the real bidirectional memory data bus. It is also exported as RV8-Bus
pins 17-24 (`RV8_D0..RV8_D7`).

```
DBUS0 ←→ ROM D0, RAM D0, U7-18, RV8_D0 (pin 17)
DBUS1 ←→ ROM D1, RAM D1, U7-17, RV8_D1 (pin 18)
DBUS2 ←→ ROM D2, RAM D2, U7-16, RV8_D2 (pin 19)
DBUS3 ←→ ROM D3, RAM D3, U7-15, RV8_D3 (pin 20)
DBUS4 ←→ ROM D4, RAM D4, U7-14, RV8_D4 (pin 21)
DBUS5 ←→ ROM D5, RAM D5, U7-13, RV8_D5 (pin 22)
DBUS6 ←→ ROM D6, RAM D6, U7-12, RV8_D6 (pin 23)
DBUS7 ←→ ROM D7, RAM D7, U7-11, RV8_D7 (pin 24)
```

### IBUS0..IBUS7 — CPU Internal Data Bus

Drivers (tri-state, only one active in normal operation):
- U7 drives `DBUS -> IBUS` during fetch/load/read paths.
- U34 drives `IRL -> IBUS` for immediate/operand execution paths.
- U14 drives `AC -> IBUS` only during store.

```
IBUS0 ←→ U7-2, U34-18*, U14-18*, U12-1,  U23-2, U32-2, U5-2, U6-2
IBUS1 ←→ U7-3, U34-17*, U14-17*, U12-4,  U23-3, U32-3, U5-3, U6-3
IBUS2 ←→ U7-4, U34-16*, U14-16*, U12-9,  U23-4, U32-4, U5-4, U6-4
IBUS3 ←→ U7-5, U34-15*, U14-15*, U12-12, U23-5, U32-5, U5-5, U6-5
IBUS4 ←→ U7-6, U34-14*, U14-14*, U13-1,  U23-6, U32-6, U5-6, U6-6
IBUS5 ←→ U7-7, U34-13*, U14-13*, U13-4,  U23-7, U32-7, U5-7, U6-7
IBUS6 ←→ U7-8, U34-12*, U14-12*, U13-9,  U23-8, U32-8, U5-8, U6-8
IBUS7 ←→ U7-9, U34-11*, U14-11*, U13-12, U23-9, U32-9, U5-9, U6-9
```

### ABUS0..ABUS15 — Address Mux Output Bus

ABUS is the final address after the PC/IRL/DP muxes. It is also exported as
RV8-Bus pins 1-16 and duplicated on pin 33 for `ABUS15`.

```
ABUS0  ← U15-4     ABUS8  ← U29-4
ABUS1  ← U15-7     ABUS9  ← U29-7
ABUS2  ← U15-9     ABUS10 ← U29-9
ABUS3  ← U15-12    ABUS11 ← U29-12
ABUS4  ← U16-4     ABUS12 ← U30-4
ABUS5  ← U16-7     ABUS13 ← U30-7
ABUS6  ← U16-9     ABUS14 ← U30-9
ABUS7  ← U16-12    ABUS15 ← U30-12
```

### Register Output Nets

```
PC0..PC15   ← U1-U4 Q outputs
IRL0..IRL7 ← U6 Q outputs
PG0..PG7   ← U23 Q outputs
DP0..DP7   ← U32 Q outputs
AC0..AC7   ← U9 Q outputs
SUM0..SUM7 ← U10-U11 sum outputs
XOR_Y0..7  ← U12-U13 XOR outputs
```

---

## Critical Nets Summary

Key control signals — source chip/pin and all destinations. Verify these first during debug.

| Signal | Source | Destinations |
|---|---|---|
| PC_INC | U25-6 (T0 OR T1) | U1-7, U1-10, U2-7, U3-7, U4-7 (ENP/ENT) |
| /PC_LD | U26-11 | U1-9, U2-9, U3-9, U4-9 (/LD) |
| ACC_CLK | U27-11 (NAND T2,AC_WR) | U9-11 (AC CLK), U21-3 (Z CLK) |
| ADDR_REQ | U25-3 (SRC OR STR) | U26-4 |
| /ADDR_MODE | U26-6 (NAND ADDR_REQ,T2) | U15-1, U16-1, U29-1, U30-1, U26-2, U33-4 |
| BUF_OE_N | U24-12 (NOT /IRL_OE) | U7-19 (/OE) |
| WR_DIR | U28-8 (XOR gate) | U7-1 (DIR), ROM /OE |
| /AC_BUF | U26-8 (NAND T2,STR) | U14-1, U14-19 (/OE), RAM /WE |
| /IRL_OE | U26-3 (NAND T2,/ADDR_MODE) | U34-1, U34-19, U24-13 |
| DP_Load | U33-6 (AND gate 1) | U32-11 (CLK) |
| PG_CLK | U25-11 (/T2 OR /PG_cond) | U23-11 (CLK) |
| /RST | Reset circuit (RC+Schmitt) | U1-1, U2-1, U3-1, U4-1, U8-9, U31-1, U31-13 |
| CLK | Oscillator | U1-2, U2-2, U3-2, U4-2, U8-8, RV8_CLK |

> 📌 If a signal is wrong, check: (1) source chip output, (2) each destination pin, (3) solder/wire continuity.
> These 12 nets account for >80% of debug issues on breadboard builds.

---

## Chip Pin Wiring

### U1-U2 74HC161 — PC Low (bits 0-7)

```
U1: PC bits 0-3
U1-1  (/CLR) ← /RST          U1-2  (CLK)  ← CLK
U1-3  (D0)   ← IRL0          U1-4  (D1)   ← IRL1
U1-5  (D2)   ← IRL2          U1-6  (D3)   ← IRL3
U1-7  (ENP)  ← PC_INC (U25-6)
U1-8  (GND)  → GND
U1-9  (/LD)  ← /PC_LD (U26-11)
U1-10 (ENT)  ← PC_INC (U25-6)
U1-11 (QD)   → PC3 → U15-14
U1-12 (QC)   → PC2 → U15-11
U1-13 (QB)   → PC1 → U15-5
U1-14 (QA)   → PC0 → U15-2
U1-15 (RCO)  → U2-10
U1-16 (VCC)  → VCC

U2: PC bits 4-7
U2-1  (/CLR) ← /RST          U2-2  (CLK)  ← CLK
U2-3  (D0)   ← IRL4          U2-4  (D1)   ← IRL5
U2-5  (D2)   ← IRL6          U2-6  (D3)   ← IRL7
U2-7  (ENP)  ← PC_INC (U25-6)
U2-8  (GND)  → GND
U2-9  (/LD)  ← /PC_LD (U26-11)
U2-10 (ENT)  ← U1-15 (RCO)
U2-11 (QD)   → PC7 → U16-14
U2-12 (QC)   → PC6 → U16-11
U2-13 (QB)   → PC5 → U16-5
U2-14 (QA)   → PC4 → U16-2
U2-15 (RCO)  → U3-10
U2-16 (VCC)  → VCC
```

### U3-U4 74HC161 — PC High (bits 8-15)

```
U3: PC bits 8-11
U3-1  (/CLR) ← /RST          U3-2  (CLK)  ← CLK
U3-3  (D0)   ← PG0           U3-4  (D1)   ← PG1
U3-5  (D2)   ← PG2           U3-6  (D3)   ← PG3
U3-7  (ENP)  ← PC_INC (U25-6)
U3-8  (GND)  → GND
U3-9  (/LD)  ← /PC_LD (U26-11)
U3-10 (ENT)  ← U2-15 (RCO)
U3-11 (QD)   → PC11 → U29-14
U3-12 (QC)   → PC10 → U29-11
U3-13 (QB)   → PC9  → U29-5
U3-14 (QA)   → PC8  → U29-2
U3-15 (RCO)  → U4-10
U3-16 (VCC)  → VCC

U4: PC bits 12-15
U4-1  (/CLR) ← /RST          U4-2  (CLK)  ← CLK
U4-3  (D0)   ← PG4           U4-4  (D1)   ← PG5
U4-5  (D2)   ← PG6           U4-6  (D3)   ← PG7
U4-7  (ENP)  ← PC_INC (U25-6)
U4-8  (GND)  → GND
U4-9  (/LD)  ← /PC_LD (U26-11)
U4-10 (ENT)  ← U3-15 (RCO)
U4-11 (QD)   → PC15 → U30-14
U4-12 (QC)   → PC14 → U30-11
U4-13 (QB)   → PC13 → U30-5
U4-14 (QA)   → PC12 → U30-2
U4-15 (RCO)  → NC
U4-16 (VCC)  → VCC
```

### U5 74HC574 — IR_HIGH (Control Byte)

```
U5-1  (/OE) → GND
U5-2  (D1)  ← IBUS0           U5-3  (D2)  ← IBUS1
U5-4  (D3)  ← IBUS2           U5-5  (D4)  ← IBUS3
U5-6  (D5)  ← IBUS4           U5-7  (D6)  ← IBUS5
U5-8  (D7)  ← IBUS6           U5-9  (D8)  ← IBUS7
U5-10 (GND) → GND
U5-11 (CLK) ← T0 (U8-3)
U5-12 (Q8)  → ALU_SUB (bit7)
U5-13 (Q7)  → XOR_MODE (bit6)
U5-14 (Q6)  → MUX_SEL (bit5)
U5-15 (Q5)  → AC_WR (bit4)
U5-16 (Q4)  → SOURCE_TYPE (bit3)
U5-17 (Q3)  → STORE (bit2)
U5-18 (Q2)  → BRANCH (bit1)
U5-19 (Q1)  → JUMP (bit0)
U5-20 (VCC) → VCC
```

### U6 74HC574 — IR_LOW (Operand)

```
U6-1  (/OE) → GND (IRL outputs always available to PC load and address/U34 inputs)
U6-2  (D1)  ← IBUS0           U6-3  (D2)  ← IBUS1
U6-4  (D3)  ← IBUS2           U6-5  (D4)  ← IBUS3
U6-6  (D5)  ← IBUS4           U6-7  (D6)  ← IBUS5
U6-8  (D7)  ← IBUS6           U6-9  (D8)  ← IBUS7
U6-10 (GND) → GND
U6-11 (CLK) ← T1 (U8-4)
U6-12 (Q8)  → IRL7 → U16-14, U2-6, U34-9
U6-13 (Q7)  → IRL6 → U16-11, U2-5, U34-8
U6-14 (Q6)  → IRL5 → U16-5,  U2-4, U34-7
U6-15 (Q5)  → IRL4 → U16-2,  U2-3, U34-6
U6-16 (Q4)  → IRL3 → U15-14, U1-6, U34-5
U6-17 (Q3)  → IRL2 → U15-11, U1-5, U34-4
U6-18 (Q2)  → IRL1 → U15-5,  U1-4, U34-3
U6-19 (Q1)  → IRL0 → U15-2,  U1-3, U34-2
U6-20 (VCC) → VCC
```

### U34 74HC541 — IRL-to-IBUS Immediate Buffer

```
U34-1  (/OE1) ← /IRL_OE (U26-3)
U34-2  (A1)   ← IRL0           U34-18 (Y1) → IBUS0
U34-3  (A2)   ← IRL1           U34-17 (Y2) → IBUS1
U34-4  (A3)   ← IRL2           U34-16 (Y3) → IBUS2
U34-5  (A4)   ← IRL3           U34-15 (Y4) → IBUS3
U34-6  (A5)   ← IRL4           U34-14 (Y5) → IBUS4
U34-7  (A6)   ← IRL5           U34-13 (Y6) → IBUS5
U34-8  (A7)   ← IRL6           U34-12 (Y7) → IBUS6
U34-9  (A8)   ← IRL7           U34-11 (Y8) → IBUS7
U34-10 (GND)  → GND
U34-19 (/OE2) ← /IRL_OE (U26-3)
U34-20 (VCC)  → VCC
```

### U7 74HC245 — Bus Buffer (DBUS↔IBUS)

```
U7-1  (DIR) ← WR_DIR (U28-8)
U7-2  (A1)  ←→ IBUS0          U7-18 (B1)  ←→ DBUS0
U7-3  (A2)  ←→ IBUS1          U7-17 (B2)  ←→ DBUS1
U7-4  (A3)  ←→ IBUS2          U7-16 (B3)  ←→ DBUS2
U7-5  (A4)  ←→ IBUS3          U7-15 (B4)  ←→ DBUS3
U7-6  (A5)  ←→ IBUS4          U7-14 (B5)  ←→ DBUS4
U7-7  (A6)  ←→ IBUS5          U7-13 (B6)  ←→ DBUS5
U7-8  (A7)  ←→ IBUS6          U7-12 (B7)  ←→ DBUS6
U7-9  (A8)  ←→ IBUS7          U7-11 (B8)  ←→ DBUS7
U7-10 (GND) → GND
U7-19 (/OE) ← BUF_OE_N (U24-12)
U7-20 (VCC) → VCC

Direction (real 74HC245 datasheet):
  DIR=0 (WR_DIR=0): B→A = DBUS→IBUS (READ)
  DIR=1 (WR_DIR=1): A→B = IBUS→DBUS (WRITE/STORE)
```

### U8 74HC164 — Ring Counter (T0/T1/T2)

```
U8-1  (A)    ← NOT(Q0) (U24-2)
U8-2  (B)    ← NOT(Q1) (U24-4)
U8-3  (Q0)   → T0
U8-4  (Q1)   → T1
U8-5  (Q2)   → T2
U8-6  (Q3)   → NC
U8-7  (GND)  → GND
U8-8  (CLK)  ← CLK
U8-9  (/CLR) ← /RST
U8-10..13    → NC
U8-14 (VCC)  → VCC
```

### U9 74HC574 — Accumulator

```
U9-1  (/OE) → GND
U9-2  (D1)  ← U17-4 (Y0)     U9-3  (D2)  ← U17-7 (Y1)
U9-4  (D3)  ← U17-9 (Y2)     U9-5  (D4)  ← U17-12 (Y3)
U9-6  (D5)  ← U18-4 (Y4)     U9-7  (D6)  ← U18-7 (Y5)
U9-8  (D7)  ← U18-9 (Y6)     U9-9  (D8)  ← U18-12 (Y7)
U9-10 (GND) → GND
U9-11 (CLK) ← ACC_CLK (U27-11)
U9-12 (Q8)  → AC7 → U11-12, U20-13, U14-9, U22-17
U9-13 (Q7)  → AC6 → U11-14, U20-10, U14-8, U22-15
U9-14 (Q6)  → AC5 → U11-3, U20-6, U14-7, U22-13
U9-15 (Q5)  → AC4 → U11-5, U20-3, U14-6, U22-11
U9-16 (Q4)  → AC3 → U10-12, U19-13, U14-5, U22-8
U9-17 (Q3)  → AC2 → U10-14, U19-10, U14-4, U22-6
U9-18 (Q2)  → AC1 → U10-3, U19-6, U14-3, U22-4
U9-19 (Q1)  → AC0 → U10-5, U19-3, U14-2, U22-2
U9-20 (VCC) → VCC
```

### U10-U11 74HC283 — ALU Adder

```
U10: bits 0-3
U10-5 (A0) ← AC0    U10-6 (B0) ← XOR_Y0 (U12-3)
U10-3 (A1) ← AC1    U10-2 (B1) ← XOR_Y1 (U12-6)
U10-14(A2) ← AC2    U10-15(B2) ← XOR_Y2 (U12-8)
U10-12(A3) ← AC3    U10-11(B3) ← XOR_Y3 (U12-11)
U10-7 (Cin) ← ALU_SUB (U5-12)
U10-4 (S0) → SUM0 → U17-2     U10-1 (S1) → SUM1 → U17-5
U10-13(S2) → SUM2 → U17-11    U10-10(S3) → SUM3 → U17-14
U10-9 (Cout) → U11-7
U10-8 (GND) → GND   U10-16(VCC) → VCC

U11: bits 4-7
U11-5 (A0) ← AC4    U11-6 (B0) ← XOR_Y4 (U13-3)
U11-3 (A1) ← AC5    U11-2 (B1) ← XOR_Y5 (U13-6)
U11-14(A2) ← AC6    U11-15(B2) ← XOR_Y6 (U13-8)
U11-12(A3) ← AC7    U11-11(B3) ← XOR_Y7 (U13-11)
U11-7 (Cin) ← U10-9 (Cout)
U11-4 (S0) → SUM4 → U18-2     U11-1 (S1) → SUM5 → U18-5
U11-13(S2) → SUM6 → U18-11    U11-10(S3) → SUM7 → U18-14
U11-9 (Cout) → NC
U11-8 (GND) → GND   U11-16(VCC) → VCC
```

### U12-U13 74HC86 — XOR Array

```
U12: bits 0-3 (A=IBUS, B=mux output)
U12-1 (A1) ← IBUS0  U12-2 (B1) ← U19-4    U12-3 (Y1) → XOR_Y0 → U10-6, U17-3
U12-4 (A2) ← IBUS1  U12-5 (B2) ← U19-7    U12-6 (Y2) → XOR_Y1 → U10-2, U17-6
U12-9 (A3) ← IBUS2  U12-10(B3) ← U19-9    U12-8 (Y3) → XOR_Y2 → U10-15, U17-10
U12-12(A4) ← IBUS3  U12-13(B4) ← U19-12   U12-11(Y4) → XOR_Y3 → U10-11, U17-13
U12-7 (GND) → GND   U12-14(VCC) → VCC

U13: bits 4-7
U13-1 (A1) ← IBUS4  U13-2 (B1) ← U20-4    U13-3 (Y1) → XOR_Y4 → U11-6, U18-3
U13-4 (A2) ← IBUS5  U13-5 (B2) ← U20-7    U13-6 (Y2) → XOR_Y5 → U11-2, U18-6
U13-9 (A3) ← IBUS6  U13-10(B3) ← U20-9    U13-8 (Y3) → XOR_Y6 → U11-15, U18-10
U13-12(A4) ← IBUS7  U13-13(B4) ← U20-12   U13-11(Y4) → XOR_Y7 → U11-11, U18-13
U13-7 (GND) → GND   U13-14(VCC) → VCC
```

### U14 74HC541 — AC Output Buffer

```
U14-1 (/OE1) ← /AC_BUF (U26-8)
U14-2  (A1) ← AC0    U14-18 (Y1) → IBUS0
U14-3  (A2) ← AC1    U14-17 (Y2) → IBUS1
U14-4  (A3) ← AC2    U14-16 (Y3) → IBUS2
U14-5  (A4) ← AC3    U14-15 (Y4) → IBUS3
U14-6  (A5) ← AC4    U14-14 (Y5) → IBUS4
U14-7  (A6) ← AC5    U14-13 (Y6) → IBUS5
U14-8  (A7) ← AC6    U14-12 (Y7) → IBUS6
U14-9  (A8) ← AC7    U14-11 (Y8) → IBUS7
U14-10 (GND) → GND
U14-19 (/OE2) ← /AC_BUF (U26-8)
U14-20 (VCC) → VCC
```

### U15-U16 74HC157 — Address Mux A[7:0] (PC vs IRL)

```
SEL=0: IRL, SEL=1: PC

U15-1 (SEL) ← /ADDR_MODE (U26-6)    U15-15(/E) → GND
U15-2 (1A) ← IRL0  U15-3 (1B) ← PC0    U15-4 (1Y) → ABUS0
U15-5 (2A) ← IRL1  U15-6 (2B) ← PC1    U15-7 (2Y) → ABUS1
U15-11(3A) ← IRL2  U15-10(3B) ← PC2    U15-9 (3Y) → ABUS2
U15-14(4A) ← IRL3  U15-13(4B) ← PC3    U15-12(4Y) → ABUS3
U15-8 (GND) → GND  U15-16(VCC) → VCC

U16-1 (SEL) ← /ADDR_MODE             U16-15(/E) → GND
U16-2 (1A) ← IRL4  U16-3 (1B) ← PC4    U16-4 (1Y) → ABUS4
U16-5 (2A) ← IRL5  U16-6 (2B) ← PC5    U16-7 (2Y) → ABUS5
U16-11(3A) ← IRL6  U16-10(3B) ← PC6    U16-9 (3Y) → ABUS6
U16-14(4A) ← IRL7  U16-13(4B) ← PC7    U16-12(4Y) → ABUS7
U16-8 (GND) → GND  U16-16(VCC) → VCC
```

### U17-U18 74HC157 — AC Input Mux (Adder vs XOR)

```
SEL=0: Adder SUM, SEL=1: XOR output

U17-1 (SEL) ← MUX_SEL (U5-14)      U17-15(/E) → GND
U17-2 (1A) ← SUM0   U17-3 (1B) ← XOR_Y0   U17-4 (1Y) → U9-2
U17-5 (2A) ← SUM1   U17-6 (2B) ← XOR_Y1   U17-7 (2Y) → U9-3
U17-11(3A) ← SUM2   U17-10(3B) ← XOR_Y2   U17-9 (3Y) → U9-4
U17-14(4A) ← SUM3   U17-13(4B) ← XOR_Y3   U17-12(4Y) → U9-5
U17-8 (GND) → GND   U17-16(VCC) → VCC

U18-1 (SEL) ← MUX_SEL (U5-14)      U18-15(/E) → GND
U18-2 (1A) ← SUM4   U18-3 (1B) ← XOR_Y4   U18-4 (1Y) → U9-6
U18-5 (2A) ← SUM5   U18-6 (2B) ← XOR_Y5   U18-7 (2Y) → U9-7
U18-11(3A) ← SUM6   U18-10(3B) ← XOR_Y6   U18-9 (3Y) → U9-8
U18-14(4A) ← SUM7   U18-13(4B) ← XOR_Y7   U18-12(4Y) → U9-9
U18-8 (GND) → GND   U18-16(VCC) → VCC
```

### U19-U20 74HC157 — XOR B-Input Mux (SUB vs AC)

```
SEL=0: ALU_SUB (for ADD/SUB), SEL=1: AC bits (for XOR instr)

U19-1 (SEL) ← XOR_MODE (U5-13)     U19-15(/E) → GND
U19-2 (1A) ← SUB   U19-3 (1B) ← AC0   U19-4 (1Y) → U12-2
U19-5 (2A) ← SUB   U19-6 (2B) ← AC1   U19-7 (2Y) → U12-5
U19-11(3A) ← SUB   U19-10(3B) ← AC2   U19-9 (3Y) → U12-10
U19-14(4A) ← SUB   U19-13(4B) ← AC3   U19-12(4Y) → U12-13
U19-8 (GND) → GND  U19-16(VCC) → VCC

U20-1 (SEL) ← XOR_MODE (U5-13)     U20-15(/E) → GND
U20-2 (1A) ← SUB   U20-3 (1B) ← AC4   U20-4 (1Y) → U13-2
U20-5 (2A) ← SUB   U20-6 (2B) ← AC5   U20-7 (2Y) → U13-5
U20-11(3A) ← SUB   U20-10(3B) ← AC6   U20-9 (3Y) → U13-10
U20-14(4A) ← SUB   U20-13(4B) ← AC7   U20-12(4Y) → U13-13
U20-8 (GND) → GND  U20-16(VCC) → VCC
```

### U21 74HC74 — Z Flag

```
U21-1 (/CLR1) → VCC
U21-2 (D1)    → GND
U21-3 (CLK1)  ← ACC_CLK (U27-11)
U21-4 (/PR1)  ← U22-19 (/P=Q)
U21-5 (Q1)    → Z_flag → U28-1
U21-6 (/Q1)   → NC
U21-7 (GND)   → GND
U21-8 (/Q2)   → NC
U21-9 (Q2)    → NC
U21-10(/PR2)  → VCC
U21-11(CLK2)  → GND
U21-12(D2)    → GND
U21-13(/CLR2) → VCC
U21-14(VCC)   → VCC
```

> 📌 **Z flag uses async preset** — U22 /P=Q drives U21 /PR.
> Place U21 and U22 physically adjacent on breadboard (minimize wire delay).
> Works reliably at 1 MHz. For PCB v2.0: consider synchronous Z update.

### U22 74HC688 — Zero Detect

```
U22-1 (/OE) → GND
U22-2 (P0) ← AC0   U22-3 (Q0) → GND
U22-4 (P1) ← AC1   U22-5 (Q1) → GND
U22-6 (P2) ← AC2   U22-7 (Q2) → GND
U22-8 (P3) ← AC3   U22-9 (Q3) → GND
U22-10(GND) → GND
U22-11(P4) ← AC4   U22-12(Q4) → GND
U22-13(P5) ← AC5   U22-14(Q5) → GND
U22-15(P6) ← AC6   U22-16(Q6) → GND
U22-17(P7) ← AC7   U22-18(Q7) → GND
U22-19(/P=Q) → U21-4
U22-20(VCC) → VCC
```

### U23 74HC574 — Page Register

> 📌 **74HC574 = positive-edge triggered.** U23/U32 latch data on CLK **rising edge** (LOW→HIGH).
> Do NOT treat CLK as active-low enable. PG_CLK and DP_Load must provide a clean LOW→HIGH transition.

**PG_CLK timing (SETPG instruction):**
```
         T0       T1       T2       T0 (next)
CLK   __|‾‾|__|‾‾|__|‾‾|__|‾‾|__
T2    ____________|‾‾‾‾‾‾|________
PG_cond __________| HIGH |________   (MUX_SEL=1 AND /AC_WR=1)
/T2   ‾‾‾‾‾‾‾‾‾‾‾‾|_____|‾‾‾‾‾‾‾
/PG_cond ‾‾‾‾‾‾‾‾‾‾|_____|‾‾‾‾‾‾‾
PG_CLK ‾‾‾‾‾‾‾‾‾‾‾‾|_____|‾‾‾‾‾‾‾   = /T2 OR /PG_cond
                           ↑
                     RISING EDGE = U23 latches IBUS!
```
PG_CLK = HIGH normally. Goes LOW only during T2 of SETPG. Returns HIGH at T2→T0 transition = latch point.

PG_CLK truth table:

| T2 | PG_cond (MUX & /AC_WR) | /T2 | /PG_cond | PG_CLK (/T2 OR /PG_cond) | Edge? |
|:--:|:---:|:---:|:---:|:---:|:-----:|
| 0 | X | 1 | X | 1 | — |
| 1 | 0 | 0 | 1 | 1 | — |
| 1 | 1 (SETPG!) | 0 | 0 | **0** | — |
| 0 (T2 ends) | 1→0 | 1 | 0→1 | **1** | **↑ LATCH!** |

```
U23-1 (/OE) → GND
U23-2 (D1) ← IBUS0   U23-3 (D2) ← IBUS1
U23-4 (D3) ← IBUS2   U23-5 (D4) ← IBUS3
U23-6 (D5) ← IBUS4   U23-7 (D6) ← IBUS5
U23-8 (D7) ← IBUS6   U23-9 (D8) ← IBUS7
U23-10(GND) → GND
U23-11(CLK) ← PG_CLK (U25-11)
U23-12(Q8) → PG7 → U4-6     U23-13(Q7) → PG6 → U4-5
U23-14(Q6) → PG5 → U4-4     U23-15(Q5) → PG4 → U4-3
U23-16(Q4) → PG3 → U3-6     U23-17(Q3) → PG2 → U3-5
U23-18(Q2) → PG1 → U3-4     U23-19(Q1) → PG0 → U3-3
U23-20(VCC) → VCC
```

### U24 74HC04 — Inverters

```
U24-1 (1A) ← T0 (U8-3)         U24-2 (1Y) → NOT(Q0) → U8-1
U24-3 (2A) ← T1 (U8-4)         U24-4 (2Y) → NOT(Q1) → U8-2
U24-5 (3A) ← ABUS15            U24-6 (3Y) → /A15 → RAM /CE
U24-7 (GND) → GND
U24-9 (4A) ← JUMP (U5-19)      U24-8 (4Y) → /JUMP → U27-4
U24-11(5A) ← AC_WR (U5-15)     U24-10(5Y) → /AC_WR → U27-10
U24-13(6A) ← /IRL_OE (U26-3)   U24-12(6Y) → BUF_OE_N → U7-19
U24-14(VCC) → VCC
```

### U25 74HC32 — OR Gates

```
U25-1 (1A) ← SRC (U5-16)   U25-2 (1B) ← STR (U5-17)   U25-3 (1Y) → ADDR_REQ
U25-4 (2A) ← T0 (U8-3)     U25-5 (2B) ← T1 (U8-4)     U25-6 (2Y) → PC_INC
U25-7 (GND) → GND
U25 gate 3 spare: tie U25-9 and U25-10 to GND; U25-8 → NC
U25-12(4A) ← /T2 (U28-6)   U25-13(4B) ← /PG_cond(U27-8) U25-11(4Y) → PG_CLK → U23-11
U25-14(VCC) → VCC
```

### U26 74HC00 — NAND #1

```
Gate A: /IRL_OE = NAND(T2, /ADDR_MODE)
U26-1 ← T2 (U8-5)   U26-2 ← /ADDR_MODE (U26-6)   U26-3 → /IRL_OE → U34-1/19, U24-13

Gate B: /ADDR_MODE = NAND(ADDR_REQ, T2)
U26-4 ← ADDR_REQ (U25-3)   U26-5 ← T2 (U8-5)   U26-6 → /ADDR_MODE → U15/16/29/30-1, U26-2, U33-4

Gate C: /AC_BUF = NAND(T2, STORE)
U26-9 ← T2 (U8-5)   U26-10 ← STR (U5-17)   U26-8 → /AC_BUF → U14-1/19, RAM /WE, U28-9

Gate D: /PC_LD = NAND(T2, PC_LOAD_COND)
U26-12 ← T2 (U8-5)   U26-13 ← PC_LOAD_COND (U27-6)   U26-11 → /PC_LD → U1-9..U4-9

U26-7 (GND) → GND   U26-14(VCC) → VCC
```

### U27 74HC00 — NAND #2

```
Gate A: /BR_TAKEN = NAND(BRANCH, Z_match)
U27-1 ← BR (U5-18)   U27-2 ← Z_match (U28-3)   U27-3 → /BR_TAKEN → U27-5

Gate B: PC_LOAD_COND = NAND(/JUMP, /BR_TAKEN) = JUMP OR BR_TAKEN
U27-4 ← /JUMP (U24-8)   U27-5 ← /BR_TAKEN (U27-3)   U27-6 → PC_LOAD_COND → U26-13

Gate C: /PG_cond = NAND(MUX_SEL, /AC_WR)
U27-9 ← MUX (U5-14)   U27-10 ← /AC_WR (U24-10)   U27-8 → /PG_cond → U25-12

Gate D: ACC_CLK = NAND(T2, AC_WR)
U27-12 ← T2 (U8-5)   U27-13 ← AC_WR (U5-15)   U27-11 → ACC_CLK → U9-11, U21-3

U27-7 (GND) → GND   U27-14(VCC) → VCC
```

### U28 74HC86 — XOR (Misc)

```
Gate A: Z_match = Z_flag XOR ALU_SUB
U28-1 ← Z_flag (U21-5)   U28-2 ← SUB (U5-12)   U28-3 → Z_match → U27-2

Gate B: /T2 = T2 XOR 1 = NOT(T2)
U28-4 ← T2 (U8-5)   U28-5 → VCC   U28-6 → /T2 → U25-11

Gate C: WR_DIR = /AC_BUF XOR 1 = NOT(/AC_BUF)
U28-9 ← /AC_BUF (U26-8)   U28-10 → VCC   U28-8 → WR_DIR → U7-1, ROM /OE

Gate D: /XOR_MODE = XOR_MODE XOR 1 = NOT(XOR_MODE)
U28-12 ← XOR_MODE (U5-13)   U28-13 ← VCC   U28-11 → /XOR_MODE → U33-12

U28-7 (GND) → GND   U28-14(VCC) → VCC
```

### U29-U30 74HC157 — Address Mux A[15:8] (PC high vs Data Page)

```
SEL=0: Data Page Register (U32 Q outputs), SEL=1: PC high

U29-1 (SEL) ← /ADDR_MODE        U29-15(/E) → GND
U29-2 (1A) ← DP0    U29-3 (1B) ← PC8    U29-4 (1Y) → ABUS8
U29-5 (2A) ← DP1    U29-6 (2B) ← PC9    U29-7 (2Y) → ABUS9
U29-11(3A) ← DP2    U29-10(3B) ← PC10   U29-9 (3Y) → ABUS10
U29-14(4A) ← DP3    U29-13(4B) ← PC11   U29-12(4Y) → ABUS11
U29-8 (GND) → GND   U29-16(VCC) → VCC

U30-1 (SEL) ← /ADDR_MODE        U30-15(/E) → GND
U30-2 (1A) ← DP4    U30-3 (1B) ← PC12   U30-4 (1Y) → ABUS12
U30-5 (2A) ← DP5    U30-6 (2B) ← PC13   U30-7 (2Y) → ABUS13
U30-11(3A) ← DP6    U30-10(3B) ← PC14   U30-9 (3Y) → ABUS14
U30-14(4A) ← DP7    U30-13(4B) ← PC15   U30-12(4Y) → ABUS15 → ROM /CE, U24-5, RV8_A15
U30-8 (GND) → GND   U30-16(VCC) → VCC
```

### U31 74HC74 — IRQ Latch + IE Flag (v1.0 Polling)

```
FF-A: IE flag (Interrupt Enable)
U31-1 (/CLR1) ← /RST (clear on reset → IE=0 at boot)
U31-2 (D1)    → VCC (D=1 always)
U31-3 (CLK1)  ← EI_decode (U33-8, rising edge sets IE=1)
U31-4 (/PR1)  → VCC
U31-5 (Q1)    → IE flag → LED
U31-6 (/Q1)   → NC

FF-B: IRQ latch
U31-7 (GND)   → GND
U31-8 (/Q2)   → NC
U31-9 (Q2)    → IRQ_FF → LED/test point; optional external /SLOT device may expose it to software
U31-10(/PR2)  → VCC
U31-11(CLK2)  ← /IRQ (external, active-low from peripheral)
U31-12(D2)    → VCC (D=1 always)
U31-13(/CLR2) ← /RST (clear on reset)
U31-14(VCC)   → VCC
```

> 📌 **IRQ latches on /IRQ rising edge** (device releases line).
> v1.0 uses level-triggered protocol: device holds /IRQ LOW until software acknowledges.
> For edge-detect: add inverter on /IRQ input (future option).

### v1.0 IRQ Operation: Software Polling

```
1. External device pulls /IRQ LOW, then releases it HIGH → IRQ_FF = 1 on the rising edge
2. Main loop reads IRQ_FF only if an external /SLOT status device exposes it
3. If IRQ_FF=1 AND IE=1: branch to handler subroutine
4. Handler processes event (IRQ_FF remains set until /RST in v1.0)
5. Software ignores further events unless it intentionally calls `EI` again

No hardware vector. No PC forcing. No bus override.
No IRQ_ack gate needed. No extra chips beyond U31+U33.
v1.0: IRQ_FF cleared only by /RST. Hardware vector/ack is not part of v1.0.
```

### Future Upgrade: Hardware Vector $FF00 (not frozen)

```
Do not build this from the v1.0 wiring guide.

Required functions:
- PC input mux: normal {PG,IRL} vs vector constant $FF00
- /PC_LD assertion during IRQ acknowledge
- Safe IRQ_ack generation: T2 AND IE AND IRQ_FF AND NOT(PC_LOAD_COND)
- Active-low clear generation for U31 if auto-clear is kept
- Timing review for conflicts with branch/jump and reset
```

> 📌 **$FF00 is in RAM** — a future hardware vector may jump here.
> Must load ISR code before enabling hardware interrupts:
> `SETDP $FF` → write ISR via SB → `SETDP $80` → enable.
> v1.0 (polling) does not jump to $FF00 automatically.

### EI Decode (v1.0)

```
EI opcode = $08 = 00001000 (SRC=1, XOR=0, AC_WR=0)

EI_decode: U33 gate 2 (74HC21, 4-input AND)
  U33-9  ← T2 (U8-5)
  U33-10 ← SRC (U5-16)
  U33-12 ← /XOR_MODE (U28-11)
  U33-13 ← /AC_WR (U24-10)
  U33-8  → EI_decode → U31-3 (CLK1, rising edge sets IE=1)

IE_D:
  U31-2 (D1) ← VCC

Decode safety check (only $08 clocks IE):
  $08: SRC=1, XOR=0, AC_WR=0 → T2 & 1 & 1 & 1 = 1 ✅
  $18: SRC=1, XOR=0, AC_WR=1 → /AC_WR=0 → blocked ✅
  $38: SRC=1, XOR=0, AC_WR=1 → /AC_WR=0 → blocked ✅
  $48: SRC=1, XOR=1, AC_WR=0 → /XOR=0 → blocked ✅
  $78: SRC=1, XOR=1, AC_WR=1 → both blocked ✅

DI ($48) has no v1.0 hardware effect. IE clears only via `/RST`.
```

---

### U32 74HC574 — Data Page Register

```
U32-1 (/OE) → GND
U32-2 (D1) ← IBUS0   U32-3 (D2) ← IBUS1
U32-4 (D3) ← IBUS2   U32-5 (D4) ← IBUS3
U32-6 (D5) ← IBUS4   U32-7 (D6) ← IBUS5
U32-8 (D7) ← IBUS6   U32-9 (D8) ← IBUS7
U32-10(GND) → GND
U32-11(CLK) ← DP_Load (decode: T2 AND SETDP)
U32-12(Q8) → DP7 → U30-14 (ABUS15 A-input: when DP7=1, ABUS15=1 → selects RAM)
U32-13(Q7) → DP6 → U30-11 (ABUS14 A-input)
U32-14(Q6) → DP5 → U30-5 (ABUS13 A-input)
U32-15(Q5) → DP4 → U30-2 (ABUS12 A-input)
U32-16(Q4) → DP3 → U29-14 (ABUS11 A-input)
U32-17(Q3) → DP2 → U29-11 (ABUS10 A-input)
U32-18(Q2) → DP1 → U29-5 (ABUS9 A-input)
U32-19(Q1) → DP0 → U29-2 (ABUS8 A-input)
U32-20(VCC) → VCC
```

### U33 74HC21 — SETDP Decode (dual 4-input AND)

```
U33-1  (1A) ← T2 (U8-5)
U33-2  (1B) ← XOR_MODE (U5-13)
U33-3  (NC)
U33-4  (1C) ← /ADDR_MODE (U26-6)
U33-5  (1D) ← /AC_WR (U24-10)
U33-6  (1Y) → DP_Load → U32-11
U33-7  (GND) → GND
U33-8  (2Y) → EI_decode → U31-3
U33-9  (2A) ← T2 (U8-5)
U33-10 (2B) ← SRC (U5-16)
U33-11 (NC)
U33-12 (2C) ← /XOR_MODE (U28-11)
U33-13 (2D) ← /AC_WR (U24-10)
U33-14 (VCC) → VCC
```

Decode verification:
| Opcode | T2 | XOR | /ADDR | /AC_WR | DP_Load |
|:---:|:--:|:---:|:-----:|:---:|:---:|
| SETDP $40 | 1 | 1 | 1 | 1 | **1** ✓ |
| DI $48 | 1 | 1 | 0 | 1 | 0 ✓ |
| XORI $70 | 1 | 1 | 1 | 0 | 0 ✓ |
| SETPG $20 | 1 | 0 | 1 | 1 | 0 ✓ |
| $C0 (SUB+XOR) | 1 | 1 | 1 | 1 | **1** (= SETDP alias, harmless) |

Note: $C0 triggers DP_Load but is equivalent to SETDP (SUB bit has no effect when AC_WR=0).

---

## ROM & RAM

```
ROM (AT28C256 / SST39SF010A)
  A[0:7]  ← ABUS0..ABUS7
  A[8:14] ← ABUS8..ABUS14
  D[0:7]  → DBUS0..DBUS7
  /CE     ← ABUS15
  /OE     ← WR_DIR (U28-8; disables ROM output during CPU store)
  /WE     → VCC during CPU runtime (inactive)

Runtime rule: CPU STORE never writes ROM. The structural chip-level Verilog
ties ROM `/WE` inactive, and the physical build should hold the ROM write pin
HIGH during normal CPU operation. A programmer may drive ROM `/WE` only when it
has explicit ownership of the ROM/programmer path and the CPU is stopped.
SETDP <$80 + LB = read from ROM (lookup tables, safe).
SETDP <$80 + SB = no ROM write in normal CPU runtime.

RAM (62256)
  A[0:7]  ← ABUS0..ABUS7
  A[8:14] ← ABUS8..ABUS14
  D[0:7]  ←→ DBUS0..DBUS7
  /CE     ← /A15 (U24-6)
  /OE     → GND (output always enabled when /CE active)
  /WE     ← /AC_BUF (U26-8)
```

> 📌 **RAM output permanently enabled** — relies on mutually-exclusive chip selects.
> ABUS15=0 → ROM /CE=LOW (ROM drives DBUS). ABUS15=1 → RAM /CE=LOW (RAM drives DBUS).
> No bus fight possible as long as A15 decode is correct.
> During STORE: RAM /WE=LOW disables output drivers automatically (62256 datasheet).

---

## Control Signal Summary

| Signal | Source | Destinations | Active |
|---|---|---|:---:|
| CLK | Oscillator | U1-2, U2-2, U3-2, U4-2, U8-8 | ↑edge |
| /RST | RC+button | U1-1, U2-1, U3-1, U4-1, U8-9, U31-1, U31-13 | LOW |
| T0 | U8-3 | U5-11, U25-4, U24-1 | HIGH |
| T1 | U8-4 | U6-11, U25-5, U24-3 | HIGH |
| T2 | U8-5 | U26-1, U26-9, U26-12, U27-12, U28-4, U33-1, U33-9 | HIGH |
| ALU_SUB | U5-12 | U10-7, U19-2/5/11/14, U20-2/5/11/14, U28-2 | HIGH |
| XOR_MODE | U5-13 | U19-1, U20-1, U33-2, U28-12 | HIGH |
| MUX_SEL | U5-14 | U17-1, U18-1, U27-9 | HIGH |
| AC_WR | U5-15 | U24-11, U27-13 | HIGH |
| SRC | U5-16 | U25-1, U33-10 | HIGH |
| STR | U5-17 | U25-2, U26-10 | HIGH |
| BR | U5-18 | U27-1 | HIGH |
| JMP | U5-19 | U24-9 | HIGH |
| ADDR_REQ | U25-3 | U26-4 | HIGH when SRC or STR |
| /ADDR_MODE | U26-6 | U15-1, U16-1, U29-1, U30-1, U26-2, U33-4 | LOW selects data address |
| PC_INC | U25-6 | U1-7/10, U2-7, U3-7, U4-7 | HIGH |
| /PC_LD | U26-11 | U1-9, U2-9, U3-9, U4-9 | LOW |
| /AC_BUF | U26-8 | U14-1/19, RAM /WE, U28-9 | LOW |
| ACC_CLK | U27-11 | U9-11, U21-3 | ↑edge |
| BUF_OE_N | U24-12 | U7-19 | LOW enables U7 |
| WR_DIR | U28-8 | U7-1, ROM /OE | HIGH=write and ROM output disabled |
| A15 | U30-12 | ROM /CE, U24-5 | — |
| PG_CLK | U25-11 | U23-11 | ↑edge |
| DP_Load | U33-6 | U32-11 | ↑edge |
| EI_decode | U33-8 | U31-3 | ↑edge |

---

## Power

| Package | VCC | GND | Bypass |
|---|:---:|:---:|:---:|
| 74HC161 (U1-U4) | 16 | 8 | 100nF |
| 74HC574 (U5,U6,U9,U23,U32) | 20 | 10 | 100nF |
| 74HC21 (U33) | 14 | 7 | 100nF |
| 74HC245 (U7) | 20 | 10 | 100nF |
| 74HC164 (U8) | 14 | 7 | 100nF |
| 74HC283 (U10-U11) | 16 | 8 | 100nF |
| 74HC86 (U12,U13,U28) | 14 | 7 | 100nF |
| 74HC541 (U14,U34) | 20 | 10 | 100nF |
| 74HC157 (U15-U20,U29-U30) | 16 | 8 | 100nF |
| 74HC74 (U21,U31) | 14 | 7 | 100nF |
| 74HC688 (U22) | 20 | 10 | 100nF |
| 74HC04 (U24) | 14 | 7 | 100nF |
| 74HC32 (U25) | 14 | 7 | 100nF |
| 74HC00 (U26-U27) | 14 | 7 | 100nF |

---

## Forbidden Bus States

The following states must NEVER occur — they cause electrical bus contention:

| Bus | Conflict | Prevention |
|-----|---|---|
| IBUS | U34 + U14 driving simultaneously | /IRL_OE and /AC_BUF mutually exclusive (NAND gates) |
| IBUS | U7 + U14 driving simultaneously | Not a conflict in store: U14 drives IBUS, U7 is DIR=write and drives DBUS |
| IBUS | U34 + U7 driving simultaneously | /IRL_OE=0 only when /ADDR_MODE=1 (immediate); U7 enabled during fetch/load when U34 is disabled |
| DBUS | ROM + U7(write) simultaneously | ROM /OE=WR_DIR disables ROM output during CPU store |
| DBUS | RAM + U7(write) simultaneously | RAM /WE=0 disables RAM output automatically |
| chip select | ROM + RAM both /CE=0 | Impossible: ROM /CE=A15, RAM /CE=/A15 (complementary) |

If any of these occur during debug → check /ADDR_MODE, BUF_OE_N, WR_DIR, or ABUS15 decode.

---

## Revision History

| Version | Date | Changes |
|:---:|:----:|---|
| v1.0 | 2026-06-15 | Initial freeze. 34 logic + ROM + RAM. 18 instructions. 1 MHz target. Software polling IRQ. |
| v1.1 | (reserved) | Optional software IRQ_FF clear via I/O, if wanted |
| v2.0 | (future) | Hardware vector/save-PC/RTI after full logic design |

---

## Appendix A: IRQ Hardware Vector (v2.0 — FUTURE)

> **NOT part of v1.0 build.** Requires +2-3 chips beyond the 36-package design.

### Hardware Save-PC (v2.0 concept)

During IRQ-ack, a v2.0 CPU would:
1. Write PC[7:0] to RAM[$800E]
2. Write PC[15:8] to RAM[$800F]
3. Force PC = $FF00

```
Cycle 1 — Save PC low:
  Force /ADDR_MODE=0, address=$0E, DP=$80
  Force AC buffer to drive PC[7:0] onto IBUS (override U14 input)
  RAM /WE pulse → RAM[$800E] = PC[7:0]

Cycle 2 — Save PC high:
  Force address=$0F, DP=$80
  Drive PC[15:8] onto IBUS
  RAM /WE pulse → RAM[$800F] = PC[15:8]
```

**Required chips**: 74HC157 ×2 (PC mux) + additional state logic.
Not included in v1.0 BOM.

---

## Appendix B: Canonical Opcode → Control Bits Table

| Hex | Mnemonic | SUB | XOR | MUX | AC_WR | SRC | STR | BR | JMP |
|:---:|---|:---:|:---:|:---:|:-----:|:---:|:---:|:--:|:---:|
| $00 | NOP | 0 | 0 | 0 | 0 | 0 | 0 | 0 | 0 |
| $01 | J | 0 | 0 | 0 | 0 | 0 | 0 | 0 | 1 |
| $02 | BEQ | 0 | 0 | 0 | 0 | 0 | 0 | 1 | 0 |
| $04 | SB | 0 | 0 | 0 | 0 | 0 | 1 | 0 | 0 |
| $08 | EI | 0 | 0 | 0 | 0 | 1 | 0 | 0 | 0 |
| $10 | ADDI | 0 | 0 | 0 | 1 | 0 | 0 | 0 | 0 |
| $18 | ADD | 0 | 0 | 0 | 1 | 1 | 0 | 0 | 0 |
| $20 | SETPG | 0 | 0 | 1 | 0 | 0 | 0 | 0 | 0 |
| $28 | SETPG_R  | 0 | 0 | 1 | 0 | 1 | 0 | 0 | 0 |
| $30 | LI | 0 | 0 | 1 | 1 | 0 | 0 | 0 | 0 |
| $38 | LB | 0 | 0 | 1 | 1 | 1 | 0 | 0 | 0 |
| $40 | SETDP | 0 | 1 | 0 | 0 | 0 | 0 | 0 | 0 |
| $48 | DI | 0 | 1 | 0 | 0 | 1 | 0 | 0 | 0 |
| $70 | XORI | 0 | 1 | 1 | 1 | 0 | 0 | 0 | 0 |
| $78 | XOR | 0 | 1 | 1 | 1 | 1 | 0 | 0 | 0 |
| $82 | BNE | 1 | 0 | 0 | 0 | 0 | 0 | 1 | 0 |
| $90 | SUBI | 1 | 0 | 0 | 1 | 0 | 0 | 0 | 0 |
| $98 | SUB | 1 | 0 | 0 | 1 | 1 | 0 | 0 | 0 |

**Alias**: $C0 = SETDP (SUB bit ignored by U33 decode)

**Reserved**: Any opcode with SRC+STR both set (bit3+bit2 = 11) is store-dominant and electrically safe, but not part of the ISA.
Pattern: `(opcode & $0C) == $0C` → 64 reserved mixed opcodes.

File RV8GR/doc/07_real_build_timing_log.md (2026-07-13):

# RV8GR Real Build Timing Log

Purpose: record timing, bus-race, edge-trigger, and propagation-delay findings
from the physical RV8GR build. This file is the main CPU project record. If a
finding changes reusable chip/circuit proof, mirror it into
`/home/jo/kiro/Components`.

This file is an **evidence log**, not a build tutorial and not a wiring source:

- Use `01_wiring_guide.md` for official pin-level wiring and timing estimates.
- Use `05_debug_plan.md` for the student-facing step-by-step physical tests.
- Use `08_cpu_logical_test_protocol.md` and `11_four_model_equivalence.md` for
  virtual CPU logic signoff.
- Use this file to record measured real-board results, failures, fixes, and
  retest evidence.

Keep this file separate from the debug plan. Merging real build entries into the
student debug instructions would make the instructions noisy and would make it
harder to see which physical board actually passed which test.

## Current Rule

Do not accept a whole-system hardware result until these four hazards are
checked at the relevant build stage:

1. Timing margin
2. Bus racing
3. Positive/negative edge trigger behavior
4. Propagation delay into the destination latch or control input

Software simulation can prepare the test. Physical timing signoff needs real
evidence from the build.

## Required Evidence Matrix

Record these conditions when each stage is ready for timing qualification:

| Condition | Required evidence |
|---|---|
| 100-tick push switch | One clean state advance per press; no skipped T-state |
| 50 kHz | Slow electronic clock pass before MHz testing |
| 1 MHz | Official target pass |
| 2 MHz | Breadboard stress pass/fail with notes |
| 5 MHz | PCB/short-wire experiment only; record as pass/fail, not baseline |
| 4.5 V | Low-voltage margin observation |
| 5.0 V | Nominal-voltage result |
| 5.5 V | High-voltage margin observation |

For each voltage/frequency run, record at least: build stage, clock source,
observed pass/fail state, worst suspicious signal, instrument used, and any
change made before rerun.

## Build Stage Checklist

### 1. Clock, Reset, And Ring Counter

- Signals: `CLK`, `/RST`, `T0`, `T1`, `T2`
- Edge focus: one clean active clock edge per step. While `/RST` is LOW, U8
  must read `000`; reset release must not double-trigger, and the first active
  clock after release must establish T0 (`001`).
- Bus-race focus: none yet.
- Propagation focus: ring feedback settles before the next active clock.
- Pass evidence: one-hot `T0/T1/T2` for at least 100 ticks.
- If failed, update: `doc/05_debug_plan.md`, lab 01/02 docs, KiCad clock/reset
  wiring, and Components `RV8GR_ResetClockBringup` or `RV8GR_RingCounter`.

### 2. Program Counter And Branch/Jump Load

- Signals: `CLK`, `/RST`, `PC_INC`, `/PC_LD`, `PC0..PC15`, `PG0..PG7`,
  `IRL0..IRL7`
- Edge focus: `74HC161` samples on the expected clock edge; `/PC_LD` is active
  LOW before that edge.
- Bus-race focus: none, unless PC outputs fight address mux wiring.
- Propagation focus: branch/jump control to `/PC_LD`; RCO cascade to the next
  nibble.
- Pass evidence: count, hold, load, BEQ/BNE/J all happen on the correct edge.
- If failed, update: `doc/01_wiring_guide.md`, lab 03/10 docs, RTL/KiCad if
  wiring changed, and Components `RV8GR_PC16` or `RV8GR_BranchJumpControl`.

### 3. ROM/RAM, DBUS, IBUS, And Address Mux

- Signals: `ABUS0..15`, `A15`, ROM `/CE`, ROM `/OE`, RAM `/CE`, RAM `/OE` or
  `/WE`, `U7 /OE`, `U7 DIR`, `IBUS0..7`, `DBUS0..7`
- Edge focus: memory read data is stable before the destination latch edge.
- Bus-race focus: ROM, RAM, U7, U14, and U34 must never create two active
  drivers on the same bus.
- Propagation focus: address mux to chip select, memory output to DBUS, U7 to
  IBUS.
- Pass evidence: no overlap between old bus driver disable and new driver
  enable; selected memory speed grade is recorded.
- If failed, update: `doc/01_wiring_guide.md`, lab 04/05/12 docs, KiCad, RTL
  if generated wiring changed, and Components `RV8GR_AddressMux16`,
  `RV8GR_BusOwnership`, `RV8GR_RomDbusRead`, `RV8GR_StorePath`, or
  `RV8GR_DataPageMemory`.

### 4. Instruction Register, ALU, AC, And Z

- Signals: `T0`, `T1`, `T2`, `/IRL_OE`, `ACC_CLK`, `AC0..7`, `Z_flag`,
  ALU intermediate outputs if available
- Edge focus: U5 captures only on T0, U6 only on T1, AC/Z only on `ACC_CLK`.
- Bus-race focus: U34, U7, and U14 are mutually exclusive IBUS drivers.
- Propagation focus: IBUS/AC through XOR, adders, mux, then AC setup; AC to Z
  settle before branch use.
- Pass evidence: LI/ADDI/SUBI/XORI and branch-after-Z tests pass by
  single-step.
- If failed, update: `doc/01_wiring_guide.md`, lab 06-09 docs, RTL/KiCad if
  wiring changed, and Components `RV8GR_InstructionLatch` or
  `RV8GR_AluAccumulator`.

### 5. Page Registers, Store/Load, And Full System

- Signals: `PG_CLK`, `DP_Load`, `/ADDR_MODE`, `/AC_BUF`, `WR_DIR`, RAM `/WE`,
  `PC`, `AC`, `PG`, `DP`
- Edge focus: SETPG and SETDP latch on the intended edge only; store `/WE`
  happens after data is valid.
- Bus-race focus: store direction must disable ROM/RAM output before U7 writes
  DBUS.
- Propagation focus: page register output to jump target; store data to RAM
  setup before `/WE`; RAM read to AC setup.
- Pass evidence: boot sequence, Lab 13 `$AA` marker, RAM read/write marker,
  and page jump marker all pass.
- If failed, update: `doc/02_instruction_trace.md`, lab 11-13 docs, RTL/KiCad
  if wiring changed, and Components `RV8GR_PageDataRegisters`,
  `RV8GR_PageJumpTrace`, `RV8GR_StoreLoadBranchTrace`, or relevant lower-level
  package.

### 6. IRQ And RV8-Bus

- Signals: `EI_decode`, `/IRQ`, `IE`, `IRQ_FF`, RV8-Bus `CLK`, `/RST`, `/WR`,
  `/IRQ`, address/data pins
- Edge focus: EI rising sets IE; `/IRQ` LOW holds; `/IRQ` release HIGH latches
  IRQ_FF.
- Bus-race focus: external RV8-Bus devices must not drive DBUS while CPU or
  memory drives it.
- Propagation focus: IRQ_FF is visible for polling/debug, but v1.0 has no PC
  force path.
- Pass evidence: IRQ LED/latch behavior passes and PC does not auto-jump.
- If failed, update: lab 14 docs, bus wiring docs, KiCad, and Components
  `RV8GR_IRQLatch` or `RV8GR_InterruptTrace`.

## Bug / Change Entry Template

```text
Date:
Build stage:
Hazard: timing_margin | bus_race | edge_trigger_polarity | propagation_delay
Module/circuit:
Signal(s):
Voltage:
Clock/frequency:
Instrument:
Expected:
Observed:
Root cause:
Fix in RV8GR:
Fix in Components:
Verification rerun:
Remaining risk:
```

## Entries

Add newest entries below this line.

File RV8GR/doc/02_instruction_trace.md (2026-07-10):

# RV8-GR — Instruction Trace (Golden Debug Trace)

**Pin-level traces for key instructions. Based on 01_wiring_guide.md (36 packages).**

Use this file when single-stepping the real CPU or comparing simulator logs.
It is not the ISA source of truth; `00_design_isa.md` owns the architecture and
`01_wiring_guide.md` owns physical pin wiring. This file shows what students
should expect to see on buses, control lines, and LEDs during important
instructions.

---

## Trace 1: ADDI $05 ($10, $05) — AC=$10 → AC=$15

### T0: Fetch control byte
```
ABUS = PC = $0000, ROM /CE=0, DBUS=$10
U7 enabled (DIR=0, D→IB), IBUS=$10
U5 latches $10 on T0 edge → AC_WR=1, rest=0
PC → $0001
```

### T1: Fetch operand
```
ABUS = $0001, ROM outputs $05, IBUS=$05
U6 latches $05 on T1 edge
PC → $0002
```

### T2: Execute
```
/IRL_OE = NAND(1,1)=0 → U34 drives IBUS=$05
XOR_MODE=0 → XOR B-mux=SUB=0 → XOR out = $05 XOR $00 = $05
Adder: AC($10) + XOR($05) + Cin(0) = $15
MUX_SEL=0 → AC mux = adder = $15
ACC_CLK = NAND(T2=1, AC_WR=1) = 0 during T2
At T2→T0 edge: ACC_CLK rises → U9 latches $15 and U21 updates Z
```
**Result: AC = $15 ✓**

---

## Trace 2: SB $03 ($04, $03) — RAM[$03] = AC

### T2: Execute (AC=$AA)
```
IR=$04: STR=1, /ADDR_MODE=0
Addr mux = IRL=$03, A[15:8]=DP=$80 → addr=$8003
A15=1 → /A15=0 → RAM selected
/AC_BUF = NAND(T2=1, STR=1) = 0 → U14 drives IBUS=AC=$AA
WR_DIR = NOT(0) = 1 → U7 DIR=1 (IB→D)
DBUS=$AA, RAM /WE=0 → RAM[$8003]=$AA
```
**Result: RAM[$8003] = $AA ✓**

---

## Trace 3: XORI $55 ($70, $55) — AC=$FF → AC=$AA

### T2: Execute
```
IR=$70: XOR_MODE=1, MUX_SEL=1, AC_WR=1
/IRL_OE=0 → IBUS=$55
XOR_MODE=1 → XOR B-mux=AC=$FF
XOR: $55 ^ $FF = $AA
MUX_SEL=1 → AC mux = XOR output = $AA
At T2→T0 edge: ACC_CLK rises → AC latches $AA
```
**Result: AC = $AA ✓**

---

## Trace 4: BEQ $20 ($02, $20) — Z=1, branch taken

### T2: Execute
```
IR=$02: BR=1, JMP=0
Z_match = Z_flag(1) XOR SUB(0) = 1
/BR_TAKEN = NAND(BR=1, Z_match=1) = 0
PC_LOAD_COND = NAND(/JUMP=1, /BR_TAKEN=0) = 1
/PC_LD = NAND(T2=1, 1) = 0 → PC loads
PC D[7:0]=IRL=$20, D[15:8]=PG=$00 → PC=$0020
```
**Result: PC = $0020 ✓**

---

## Trace 5: SETPG $90 ($20, $90) — PG=$90

### T2: Execute
```
IR=$20: MUX_SEL=1, AC_WR=0
/IRL_OE=0 → IBUS=$90
/PG_cond = NAND(MUX_SEL=1, /AC_WR=1) = 0
PG_CLK = OR(/T2=0, /PG_cond=0) = 0
At T2→T0 edge: PG_CLK rises → U23 latches $90
```
**Result: PG = $90 ✓**

---

## Trace 6: J $00 ($01, $00) — PC=$9000

### T2: Execute (PG=$90)
```
IR=$01: JMP=1
/JUMP = NOT(1) = 0
PC_LOAD_COND = NAND(0, x) = 1
/PC_LD = NAND(1, 1) = 0 → PC loads
PC = {PG=$90, IRL=$00} = $9000
```
**Result: PC = $9000 ✓**

---

## Trace 7: LB $03 ($38, $03) — AC=RAM[$8003]

### T2: Execute (RAM[$8003]=$AA)
```
IR=$38: MUX_SEL=1, AC_WR=1, SRC=1
/ADDR_MODE=0 → addr mux=IRL=$03, A[15:8]=DP=$80
A15=1 → /A15=0 → RAM selected
BUF_OE_N=0 → U7 enabled (DBUS→IBUS)
U7 reads RAM → IBUS=$AA
XOR_MODE=0 → XOR out = IBUS = $AA
MUX_SEL=1 → AC mux = XOR out = $AA
At T2→T0 edge: ACC_CLK rises → AC latches $AA
```
**Result: AC = $AA ✓**

---

## Trace 8: SETDP $80 ($40, $80) — DP=$80

### T2: Execute
```
IR=$40: XOR_MODE=1, MUX_SEL=0, AC_WR=0, SRC=0, STR=0
ADDR_REQ = SRC|STR = 0
/IRL_OE = NAND(T2=1, /ADDR_MODE=1) = 0 → U34 drives IBUS=$80
DP_Load = T2(1) AND XOR_MODE(1) AND /ADDR_MODE(1) AND /AC_WR(1) = 1
At T2 start: DP_Load rises after U33 delay → U32 latches $80 on rising edge

Bus: ABUS=PC, IBUS=U34($80), DBUS=ROM(stale)
Check: ✓ PG_CLK stays HIGH (MUX=0) ✓ AC unchanged (AC_WR=0)
```
**Result: DP = $80 ✓**

---

## Trace 9: BNE $20 ($82, $20) — Z=0, branch taken

### T2: Execute
```
IR=$82: SUB=1, BR=1, JMP=0, AC_WR=0, SRC=0, STR=0
Z_match = Z_flag(0) XOR SUB(1) = 1
/BR_TAKEN = NAND(BR=1, Z_match=1) = 0
PC_LOAD_COND = NAND(/JUMP=1, /BR_TAKEN=0) = 1
/PC_LD = NAND(T2=1, 1) = 0 → PC loads
PC = {PG=$00, IRL=$20} = $0020

Bus: ABUS=PC, IBUS=U34($20), DBUS=ROM(stale)
Check: ✓ Same hardware as BEQ — SUB bit flips Z_match polarity
```
**Result: PC = $0020 ✓ (BNE reuses BEQ hardware via Z XOR SUB)**

---

## Trace 10: Mixed Opcode $0C — Store-Dominant Bus Direction

### T2: Execute (hypothetical — opcode $0C has SRC=1, STR=1)
```
IR=$0C: SRC=1, STR=1, /ADDR_MODE=0
Addr mux = {DP,IRL} → ABUS = data address
/AC_BUF = NAND(T2=1, STR=1) = 0 → U14 drives IBUS = AC

U7 /OE = BUF_OE_N = 0 → U7 enabled
WR_DIR=1 → U7 direction is IBUS→DBUS
ROM /OE=WR_DIR=1 → ROM output tri-stated during write direction

Result: U14 drives IBUS, U7 writes that value to DBUS, RAM write proceeds if A15=1
No bus contention. Store executes. RAM gets AC value.
```
**Result: Store path is electrically safe ✓**

> 📌 64 opcodes where (opcode & $0C) == $0C are reserved — none are in the ISA.
> Store direction is deterministic even if executed accidentally.

---

## Trace 11: Boot Sequence (SETDP $80 → SETPG $00 → LI $00)

Power-on state: PC=$0000, PG=??, DP=??, AC=??, Z=??

### Instruction 1: SETDP $80 ($40, $80) at $0000
```
T0: PC=$0000, ABUS=$0000, A15=0 → ROM selected
    DBUS=$40, U7→IBUS=$40, U5 latches $40. PC→$0001
T1: PC=$0001, DBUS=$80, U6 latches $80. PC→$0002
T2: IR=$40: XOR_MODE=1, /ADDR_MODE=1, AC_WR=0
    /IRL_OE=0 → U34 drives IBUS=$80
    DP_Load rises after U33 delay near T2 start → U32 latches $80
    ✓ ABUS=PC (no data access) — DP=?? is harmless
```
**Result: DP = $80 ✓ (RAM page selected for registers)**

### Instruction 2: SETPG $00 ($20, $00) at $0002
```
T0: PC=$0002, DBUS=$20, U5 latches $20. PC→$0003
T1: PC=$0003, DBUS=$00, U6 latches $00. PC→$0004
T2: IR=$20: MUX_SEL=1, AC_WR=0, /ADDR_MODE=1
    /IRL_OE=0 → IBUS=$00
    PG_CLK: 0→1 at T2→T0 edge → U23 latches $00
    ✓ ABUS=PC — PG=?? is harmless (no jump yet)
```
**Result: PG = $00 ✓ (page 0 for safe jumps)**

### Instruction 3: LI $00 ($30, $00) at $0004
```
T0: PC=$0004, DBUS=$30, U5 latches $30. PC→$0005
T1: PC=$0005, DBUS=$00, U6 latches $00. PC→$0006
T2: IR=$30: MUX_SEL=1, AC_WR=1, XOR_MODE=0
    /IRL_OE=0 → IBUS=$00
    XOR out = $00 XOR $00 = $00
    MUX_SEL=1 → AC mux = XOR out = $00
    ACC_CLK rises at T2→T0 edge → AC=$00, Z=1
```
**Result: AC=$00, Z=1 ✓ (all architectural state now defined)**

> 📌 After 3 instructions (9 clocks): PC=$0006, DP=$80, PG=$00, AC=$00, Z=1.
> Safe to use SRC/STR/J/BEQ from this point onward.

---

## Summary

| # | Instruction | Opcode | Key Signal | Result |
|:-:|---|:---:|---|---|
| 1 | ADDI | $10 | AC_WR, adder | AC = AC + imm |
| 2 | SB | $04 | STR, /AC_BUF, WR_DIR | RAM ← AC |
| 3 | XORI | $70 | XOR_MODE, MUX_SEL | AC = AC ^ imm |
| 4 | BEQ | $02 | BR, Z_match, /PC_LD | PC loads if Z=1 |
| 5 | SETPG | $20 | MUX_SEL, PG_CLK | PG ← IBUS |
| 6 | J | $01 | JMP, /PC_LD | PC = {PG, addr} |
| 7 | LB | $38 | SRC, /ADDR_MODE, BUF_OE_N | AC = RAM[{DP,rs}] |
| 8 | SETDP | $40 | XOR_MODE, DP_Load | DP ← operand |
| 9 | BNE | $82 | SUB, BR, Z_match | PC loads if Z=0 |
| 10 | Mixed SRC+STR | $0C | WR_DIR=1, ROM /OE=1 | Store wins, no conflict |
| 11 | Boot Seq | $40→$20→$30 | DP_Load, PG_CLK, AC_WR | All state defined |

All 11 traces verified pin-by-pin against 01_wiring_guide.md. ✓

---

## Bus Ownership Quick Reference

| Trace | ABUS | IBUS driver | DBUS driver |
|:-----:|:----:|:---:|:---:|
| ADDI (T2) | PC | U34 (immediate) | ROM (stale) |
| SB (T2) | {DP,IRL} | U14 (AC) | U7 (write) |
| XORI (T2) | PC | U34 (immediate) | ROM (stale) |
| BEQ (T2) | PC | U34 (immediate) | ROM (stale) |
| SETPG (T2) | PC | U34 (immediate) | ROM (stale) |
| J (T2) | PC | U34 (immediate) | ROM (stale) |
| LB (T2) | {DP,IRL} | U7 (RAM read) | RAM |
| SETDP (T2) | PC | U34 (immediate) | ROM (stale) |
| BNE (T2) | PC | U34 (immediate) | ROM (stale) |
| Mixed SRC+STR (T2) | {DP,IRL} | U14 (AC) | U7 (write), ROM disabled |
| Boot: SETDP (T2) | PC | U34 (immediate) | ROM (stale) |
| Boot: SETPG (T2) | PC | U34 (immediate) | ROM (stale) |
| Boot: LI (T2) | PC | U34 (immediate) | ROM (stale) |

---

## Golden Trace (Regression Reference)

Program: `LI $42 → ADDI $01 → SUBI $43 → BEQ target`

ROM contents: `$30 $42 $10 $01 $90 $43 $02 $08`

All simulators must produce this exact output (after boot: DP=$80, PG=$00, AC=$00, Z=1):

```
Cycle  Phase  PC    ABUS  IRH  IRL  Mnemonic  AC  Z  PG  DP  Notes
-----  -----  ----  ----  ---  ---  --------  --  -  --  --  -----
1      T0     0000  0000  30   --   --        00  1  00  80  fetch ctrl
2      T1     0001  0001  30   42   --        00  1  00  80  fetch operand
3      T2     0002  0002  30   42   LI        42  0  00  80  AC=$42
4      T0     0002  0002  10   --   --        42  0  00  80  fetch ctrl
5      T1     0003  0003  10   01   --        42  0  00  80  fetch operand
6      T2     0004  0004  10   01   ADDI      43  0  00  80  AC=$42+$01=$43
7      T0     0004  0004  90   --   --        43  0  00  80  fetch ctrl
8      T1     0005  0005  90   43   --        43  0  00  80  fetch operand
9      T2     0006  0006  90   43   SUBI      00  1  00  80  AC=$43-$43=$00
10     T0     0006  0006  02   --   --        00  1  00  80  fetch ctrl
11     T1     0007  0007  02   08   --        00  1  00  80  fetch operand
12     T2     0008  0008  02   08   BEQ       00  1  00  80  Z=1→branch taken, PC=$0008
```

**Expected final state**: PC=$0008, AC=$00, Z=1, PG=$00, DP=$80

> 📌 Any simulator or testbench that does NOT produce this exact sequence has a bug.
> Use this as the first regression check after any code change.

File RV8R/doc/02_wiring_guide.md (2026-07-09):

{
// ═══════════════════════════════════════════════════════════════
// RV8-R CPU — WiringGuide (Bus-Centric, draft)
// FullHW revision: 49 logic chips + 4 ROM/RAM packages = 53 packages
// = RV8 minus hardware registers, registers live in RAM $FFF8-$FFFF
//
// RV8-style 35-slot programmer ISA surface
// Native/macro/prototype status is defined in doc/00_design.md
// Full ISA pin trace status: REAL HARDWARE PATHS DEFINED; RTL/KiCad proof pending
// Microcode address includes IRQ_ACTIVE + flags + step[3:0] + opcode
// Reset PC = $0000: Program ROM boots first, high RAM holds registers/data
// Fewer chips: no 8× register 574s, no 2× decode 138s
//
// TWO BUSES:
//   RV8-Bus (external 40-pin): A[15:0] + D[7:0] → ROM, RAM
//   IBUS (internal 8-bit): ALU, IR, result latch, bus buffer
// ═══════════════════════════════════════════════════════════════

Project: RV8-R,

RV8_Bus:{
    "A[15:0]": "PC (fetch) or address latches (register/memory access)",
    "D[7:0]":  "ROM/RAM ↔ U12 (245) ↔ IBUS",
    "/RD":     "from microcode",
    "/WR":     "from microcode",
    "/IRQ":    "external active-low interrupt request into U22 IRQ_PENDING latch",
    pinout:    "Same 40-pin as all RV8 variants"
},

IBUS:{
    width: 8,
    drivers: [
        "U2 (IR operand, /OE controlled)",
        "U12 (245 bus buffer, read mode)",
        "U15 (ALU result latch, /OE controlled)"
    ],
    consumers: [
        "U1 (IR opcode, CLK=IR_CLK)",
        "U2 (IR operand, CLK=OPR_CLK)",
        "U3 (ALU B latch, CLK=ALUB_CLK)",
        "U10 (addr latch low, CLK=ADDR_LO_CLK)",
        "U11 (addr latch high, CLK=ADDR_HI_CLK)",
        "U12 (245 bus buffer, write mode)",
        "U6-U7 (XOR → adder B inputs)"
    ],
    rule: "One driver at a time (microcode controls /OE and BUF_OE)"
},

Legacy_19Chip_Sketch_Do_Not_Build:{
    note:"Kept only to show the old low-chip idea. It does not meet the full ISA. Build from FullHW_Part below.",
    // ═══════════════════════════════════════════
    // IR — 74HC574 ×2 (U1-U2)
    // ═══════════════════════════════════════════

    U1:{type:74HC574, bus:IBUS, function:"IR opcode",
        1:GND, 11:IR_CLK, "2-9":IBUS, "12-19":"→Flash addr A[7:0]",
        10:GND, 20:VCC},
    // /OE=GND (always outputs to Flash address)

    U2:{type:74HC574, bus:IBUS, function:"IR operand (also drives IBUS for immediate)",
        1:OPR_OE, 11:OPR_CLK, "2-9":IBUS, "12-19":"IBUS + addr_mux(U18)",
        10:GND, 20:VCC},
    // /OE controlled by microcode (drives IBUS when loading ALU B with immediate)

    // ═══════════════════════════════════════════
    // ALU — 74HC574 + 74HC283 ×2 + 74HC86 ×2 + 74HC574 (U3-U7, U15)
    // ═══════════════════════════════════════════

    U3:{type:74HC574, bus:IBUS, function:"ALU B latch",
        1:VCC, 11:ALUB_CLK, "2-9":IBUS, "12-19":"→U6-U7 XOR A inputs",
        10:GND, 20:VCC},
    // /OE=VCC (never drives IBUS). Outputs → XOR chips.

    U4:{type:74HC283, bus:internal, function:"ALU adder low nibble",
        5:"IBUS0", 3:"IBUS1", 14:"IBUS2", 12:"IBUS3",
        6:"U6.Y0", 2:"U6.Y1", 15:"U6.Y2", 11:"U6.Y3",
        7:ALU_SUB, 9:"→U5.C0",
        4:"S0→U15.D0", 1:"S1→U15.D1", 13:"S2→U15.D2", 10:"S3→U15.D3",
        8:GND, 16:VCC},
    // A inputs from IBUS (register value from RAM during execute)
    // B inputs from XOR output (operand or register, inverted for SUB)

    U5:{type:74HC283, bus:internal, function:"ALU adder high nibble",
        5:"IBUS4", 3:"IBUS5", 14:"IBUS6", 12:"IBUS7",
        6:"U7.Y0", 2:"U7.Y1", 15:"U7.Y2", 11:"U7.Y3",
        7:"U4.C4", 9:"CARRY_OUT→U14.D2",
        4:"S4→U15.D4", 1:"S5→U15.D5", 13:"S6→U15.D6", 10:"S7→U15.D7",
        8:GND, 16:VCC},

    U6:{type:74HC86, bus:internal, function:"XOR low (SUB invert bits 0-3)",
        1:"U3.Q0", 2:ALU_SUB, 3:"→U4.B1",
        4:"U3.Q1", 5:ALU_SUB, 6:"→U4.B2",
        9:"U3.Q2", 10:ALU_SUB, 8:"→U4.B3",
        12:"U3.Q3", 13:ALU_SUB, 11:"→U4.B4",
        7:GND, 14:VCC},

    U7:{type:74HC86, bus:internal, function:"XOR high (SUB invert bits 4-7)",
        1:"U3.Q4", 2:ALU_SUB, 3:"→U5.B1",
        4:"U3.Q5", 5:ALU_SUB, 6:"→U5.B2",
        9:"U3.Q6", 10:ALU_SUB, 8:"→U5.B3",
        12:"U3.Q7", 13:ALU_SUB, 11:"→U5.B4",
        7:GND, 14:VCC},

    U15:{type:74HC574, bus:IBUS, function:"ALU result latch (drives IBUS for write-back)",
        1:ALUR_OE, 11:ALUR_CLK, "2-9":"adder S[7:0]", "12-19":IBUS,
        10:GND, 20:VCC},
    // /OE=ALUR_OE (drives IBUS when writing result to RAM)
    // CLK=ALUR_CLK (latches adder output)

    // ═══════════════════════════════════════════
    // PC — 74HC574 ×2 (U8-U9) — has /OE
    // ═══════════════════════════════════════════

    U8:{type:74HC574, bus:RV8_Bus_addr, function:"PC low (A[7:0] during fetch)",
        1:PC_ADDR_n, 11:PC_LO_CLK, "2-9":"ALU_R (from U15)", "12-19":"A[7:0]",
        10:GND, 20:VCC},
    // /OE=PC_ADDR_n (LOW during fetch, HIGH during data access)

    U9:{type:74HC574, bus:RV8_Bus_addr, function:"PC high (A[15:8] during fetch)",
        1:PC_ADDR_n, 11:PC_HI_CLK, "2-9":"ALU_R (from U15)", "12-19":"A[15:8]",
        10:GND, 20:VCC},

    // ═══════════════════════════════════════════
    // ADDRESS LATCHES — 74HC574 ×2 (U10-U11)
    // ═══════════════════════════════════════════

    U10:{type:74HC574, bus:RV8_Bus_addr, function:"Addr latch low (A[7:0] during data access)",
        1:PC_ADDR, 11:ADDR_LO_CLK,
        "2-4":"from U18 mux (normal addr bits or opcode[2:0])",
        "5-9":"from U18/force network (normal addr bits or VCC for $FFF8-$FFFF)",
        "12-19":"A[7:0]",
        10:GND, 20:VCC},
    // /OE=PC_ADDR (LOW during data access, HIGH during fetch)
    // D inputs from U18/force network: normal address or $F8+opcode[2:0] for register access

    U11:{type:74HC574, bus:RV8_Bus_addr, function:"Addr latch high (A[15:8] during data access)",
        1:PC_ADDR, 11:ADDR_HI_CLK, "2-9":"IBUS or $FF force in REG_ADDR_MODE", "12-19":"A[15:8]",
        10:GND, 20:VCC},

    // ═══════════════════════════════════════════
    // REGISTER ADDRESS MUX / FORCE NETWORK — 74HC157 (U18)
    // Selects normal memory address vs forced $FFF8+reg address
    // ═══════════════════════════════════════════

    U18:{type:74HC157, bus:internal, function:"Addr latch input mux/force (normal addr vs $FFF8+reg)",
        1:REG_ADDR_MODE,
        2:"IBUS0", 3:"U1.Q0 (opcode bit 0)", 4:"→U10.D0",
        5:"IBUS1", 6:"U1.Q1 (opcode bit 1)", 7:"→U10.D1",
        11:"IBUS2", 10:"U1.Q2 (opcode bit 2)", 9:"→U10.D2",
        14:"IBUS3", 13:VCC, 12:"→U10.D3",
        8:GND, 15:GND, 16:VCC},
    // S=REG_ADDR_MODE: 0=normal address, 1=register address $FFF8+opcode[2:0]
    // B inputs: opcode[2:0] for bits 0-2, VCC for bit 3. Remaining low-byte bits and high byte
    // must be forced high in REG_ADDR_MODE. This is the frozen concept; pin-level proof pending.

    // ═══════════════════════════════════════════
    // BUS BUFFER — 74HC245 (U12)
    // ═══════════════════════════════════════════

    U12:{type:74HC245, bus:both, function:"Bridge: IBUS ↔ RV8-Bus D[7:0]",
        1:BUF_DIR, 19:BUF_OE_n, "2-9":IBUS, "11-18":"D[7:0]",
        10:GND, 20:VCC},

    // ═══════════════════════════════════════════
    // CONTROL — Flash ×2 + step counter + flags + IRQ
    // ═══════════════════════════════════════════

    U13:{type:SST39SF010A, bus:control, function:"Microcode Flash #1 (low byte)",
        "addr":"IRQ_ACTIVE + flag_C + flag_Z + step[2:0] + opcode[7:0] = 14 bits",
        "data":"D[7:0] = BUF_OE, BUF_DIR, PC_ADDR, ADDR_CLK, PC_INC, IR_CLK, OPR_CLK, STEP_RST"},

    U17:{type:SST39SF010A, bus:control, function:"Microcode Flash #2 (high byte)",
        "addr":"same as U13",
        "data":"D[7:0] = REG_ADDR_MODE, ALUB_CLK, ALUR_CLK, ALUR_OE, ALU_SUB, FLAGS_CLK, PC_LOAD, ADDR_HI_CLK"},

    U14:{type:74HC74, bus:control, function:"Flags (Z, C)",
        "FF1":"D=alu_zero, CLK=FLAGS_CLK, Q=flag_z → Flash addr",
        "FF2":"D=carry_out, CLK=FLAGS_CLK, Q=flag_c → Flash addr",
        1:"/RST", 7:GND, 13:"/RST", 14:VCC},

    U22:{type:74HC74, bus:control, function:"Interrupt state (IE, IRQ_PENDING)",
        "FF1":"IE: set by SYS 2/EI, clear by SYS 3/DI or IRQ_ACK or /RST, Q=IE",
        "FF2":"IRQ_PENDING: clocked by falling /IRQ, clear by IRQ_ACK or /RST",
        "IRQ_ACTIVE":"IE AND IRQ_PENDING → Flash addr A13",
        "entry":"save PC to RAM[$FFF6/$FFF7], clear IE+IRQ_PENDING, PC=$7F00",
        1:"/RST", 7:GND, 13:"/RST", 14:VCC},

    U16:{type:74HC161, bus:control, function:"Step counter",
        2:CLK, 1:STEP_RST_n, "Q[2:0]":"→Flash addr A[10:8]",
        7:VCC, 10:VCC, 8:GND, 16:VCC},

    // ═══════════════════════════════════════════
    // MEMORY
    // ═══════════════════════════════════════════

    ROM:{type:AT28C256, bus:RV8_Bus, function:"Program ROM",
        "range":"$0000-$7FFF, first fetch after reset",
        "/CE":"A15 active-low select for lower 32KB", "/OE":"/RD", "/WE":VCC},
    RAM:{type:62256, bus:RV8_Bus, function:"RAM (registers $FFF8-$FFFF + data)",
        "range":"$8000-$FFFF, high RAM",
        "/CE":"NOT(A15) active-low select for upper 32KB", "/OE":"/RD", "/WE":"/WR"},

    // ═══════════════════════════════════════════
    // SUPPORT
    // ═══════════════════════════════════════════
    OSC:{type:"Crystal 5MHz", output:CLK},
    R1:{type:"10K", 1:VCC, 2:"/RST"},
    SW:{type:"Pushbutton", 1:"/RST", 2:GND},
    C1:{type:"100nF", 1:"/RST", 2:GND},

    RV8_Bus_connector:{type:"40-pin IDC", pinout:"Same as all RV8 variants"}
},

// ═══════════════════════════════════════════════════════════════
// FULLHW PART LIST — REAL FULL-ISA HARDWARE PATHS
// ═══════════════════════════════════════════════════════════════

FullHW_Part:{
    goal:"Make every RV8-R ISA feature a real TTL path, even if chip count rises.",
    package_count:{
        logic:49,
        memory:4,
        total:53,
        note:"2x AT28C256/SST39SF010 microcode ROM + 1x AT28C256 program ROM + 1x 62256 RAM are counted as memory/program packages."
    },

    buses:{
        IBUS:"internal 8-bit data bus: one active driver only",
        ABUS:"external 16-bit address bus to Program ROM and RAM",
        DBUS:"external 8-bit memory data bus",
        PCQ:"16-bit PC counter outputs",
        ARQ:"16-bit address register outputs",
        ALU_A:"IBUS direct into ALU A inputs",
        ALU_B:"U3 ALU_B latch outputs",
        ALU_R:"selected ALU result into U15"
    },

    pc_real:{
        U8_U11:"4x74HC161, 16-bit PC counter, Q=PCQ[15:0]",
        pins:"CLK=CPU_CLK, /CLR=/RST so reset PC=$0000, ENP/ENT=PC_INC, /LOAD=PC_LOAD_n, D[15:0]=ARQ[15:0]",
        fetch:"PCQ drives ABUS through U40-U43 when ADDR_OWNER=PC",
        branch_jump_irq_iret:"microcode first loads ARQ with target, then asserts PC_LOAD_n low for one clock",
        pc_to_ibus:"U44 drives PC_LO to IBUS, U45 drives PC_HI to IBUS for JAL and IRQ save"
    },

    address_real:{
        U20_U21:"2x74HC574 address registers, Q=ARQ[15:0]",
        U30_U37:"8x74HC157 two-stage address-source muxes feeding U20/U21 D[15:0]",
        source_00:"NORMAL: IBUS byte into selected low/high address register",
        source_01:"REG: $FFF8 + REG_SEL, where REG_SEL can be rd, rs, or r7",
        source_10:"FAST/IRQ: $FF00 + OPR for LBfp/SBfp, or $FFF6/$FFF7 for IRQ save/IRET",
        source_11:"VECTOR/CONST: $7F00 IRQ vector, $0000 reset/test, or PC_HI:ALU_LO for same-page relative branch",
        abus_select:"U40-U43 4x74HC157 select ABUS = PCQ or ARQ; no tri-state fight on address bus"
    },

    alu_real:{
        U3:"74HC574 ALU_B latch, D=IBUS, Q=ALU_B",
        U4_U5:"2x74HC283 adder, A=IBUS, B=ALU_B xor SUB, C0=ALU_CIN",
        U6_U7:"2x74HC86 B invert bank for SUB/SBC-style operations",
        U50_U51:"2x74HC08 AND result, Y=IBUS & ALU_B",
        U52_U53:"2x74HC32 OR result, Y=IBUS | ALU_B",
        U54_U55:"2x74HC86 XOR result, Y=IBUS ^ ALU_B",
        U56_U59:"4x74HC157 ALU result mux, selects ADD/SUB, AND, OR, XOR into U15.D[7:0]",
        U15:"74HC574 ALU result latch, Q drives IBUS only when ALUR_OE_n=0",
        constants:"U60 74HC244 drives $00 or $01 to IBUS for SLT/SLTI writeback and zero-B loads",
        sign_extend:"U61 74HC244 drives sext(OPR[4:0]) to IBUS for branch and off(rs) address math"
    },

    memory_real:{
        U12:"74HC245 bridge, IBUS <-> DBUS, BUF_DIR selects read/write, BUF_OE_n enables",
        ROM:"AT28C256 Program ROM, /CE=A15 active-low, /OE=/RD, /WE=VCC, range $0000-$7FFF",
        RAM:"62256 SRAM, /CE=NOT(A15) active-low, /OE=/RD, /WE=/WR, range $8000-$FFFF",
        fast_page:"LBfp/SBfp force address $FF00+OPR; $FFF6-$FFFF reserved by software and control tests",
        registers:"REG address source forces $FFF8+reg for r0-r7",
        r0_guard:"U62 gates RAM_WE off when REG_WRITE and REG_SEL=000"
    },

    control_real:{
        U13_U17:"2x AT28C256/SST39SF010 microcode ROMs, 16-bit direct control word",
        microcode_address:"{IRQ_ACTIVE, flag_C, flag_Z, step[3:0], opcode[7:0]} = 15 bits, exactly fills 32KB",
        frozen_control_word:{
            default_safe:"0x028D",
            "bit0":"BUF_OE_n, active low, enables U12",
            "bit1":"BUF_DIR, 0=DBUS to IBUS read, 1=IBUS to DBUS write",
            "bit2":"OPR_OE_n, active low, enables U2 operand onto IBUS",
            "bit3":"ALUR_OE_n, active low, enables U15 ALU result onto IBUS",
            "bit4":"ALUB_CLK, active high clock, loads U3 from IBUS",
            "bit5":"ALUR_CLK, active high clock, loads U15 from selected ALU result",
            "bit6":"FLAGS_CLK, active high clock, loads Z/C flags",
            "bit7":"RAM_WE_n, active low, writes RAM when guards allow it",
            "bit8":"PC_INC, active high clock enable for the PC counters",
            "bit9":"PC_LOAD_n, active low load for the PC counters from ARQ",
            "bit10":"AR_LO_CLK, active high clock for address low register",
            "bit11":"AR_HI_CLK, active high clock for address high register",
            "bits12_13":"ADDR_SRC: 00=NORMAL, 01=REG $FFF8+REG_SEL, 10=FAST/IRQ, 11=VECTOR/PC",
            "bits14_15":"ALU_SEL: 00=ADD/SUB, 01=AND, 10=OR, 11=XOR"
        },
        derived_controls:"IR_CLK, OPR_CLK, /RD, /WR, STEP_RST, ALU_SUB, ALU_CIN, CONST_OE, SEXT_OE, PC_LO_OE, PC_HI_OE, REG_SEL, SYS_EI, SYS_DI, SYS_IRET, IRQ_ACK, and HALT_SET are deterministic decode from opcode/operand/flags/step plus the control word; they are not extra ROM output bits",
        bus_rule:"IBUS may have exactly one owner: U12 memory read, U2 operand, U15 ALU result, U60 constant, U61 sign extension, U44 PC low, or U45 PC high",
        U16:"74HC161 step counter uses Q[3:0], allowing 16 micro-steps so PUSH/POP are real",
        U14:"74HC74 flags, Z and C/borrow latch into microcode address",
        U63:"74HC138 SYS decoder enabled only for opcode class SYS and OPR[2:0]",
        U22:"74HC74 IE and IRQ_PENDING",
        U64:"74HC74 HALT latch; SYS 1 sets HALT, /RST clears it, HALT gates CPU_CLK",
        misc:"U65-U66 74HC00/74HC08 gates for IRQ_ACTIVE, IRQ_ACK, IE_SET, IE_CLR, RAM_WE guard, mutually-exclusive bus enables"
    },

    real_feature_paths:[
        "Fetch: PCQ -> ABUS -> ROM -> DBUS -> U12 -> IBUS -> U1/U2",
        "Register read/write: address mux forces $FFF8+rd/rs/r7 -> RAM -> U12 -> IBUS, and U15 -> IBUS -> U12 -> RAM for writeback",
        "ALU ADD/SUB/AND/OR/XOR/SLL: RAM or OPR -> ALU_B; RAM[rd] on IBUS -> ALU_A; selected result -> U15 -> RAM[rd]",
        "SLT/SLTI: subtract sets C/borrow; next micro-step writes $01 or $00 from U60 to RAM[rd]",
        "LB/SB off(rs): RAM[rs] + sext(off5) -> AR_LO, AR_HI policy from microcode -> RAM data transfer",
        "LBfp/SBfp: address mux forces $FF00+OPR -> RAM data transfer",
        "PUSH/POP: REG_SEL=r7 reads/writes SP at $FFFF; ALU +/-1 updates SP; AR uses SP address; data moves through U12",
        "BEQ/BNE/BLT/BGE/J: compare or unconditional path computes same-page PC_LO target in ALU, loads AR={PC_HI,target_lo}, then PC_LOAD",
        "JAL: PC_LO from U44 -> RAM[rd], then same-page relative target through AR -> PC_LOAD",
        "JALR/RET: RAM[rs] -> AR_LO, PC_HI -> AR_HI, PC_LOAD; JALR is same-page indirect by hardware contract",
        "IRQ entry: U44/U45 write PC_LO/PC_HI to $FFF6/$FFF7, address mux loads AR=$7F00, PC_LOAD, IRQ_ACK clears pending and IE",
        "IRET: RAM[$FFF6] -> AR_LO, RAM[$FFF7] -> AR_HI, PC_LOAD, IE_SET"
    ]
},

// ═══════════════════════════════════════════════════════════════
// FULL ISA PIN TRACE
// ═══════════════════════════════════════════════════════════════
//
// Purpose:
//   Preserve the old 19-chip failure trace so we remember why FullHW was added.
//   Do not use this legacy block for schematic capture; use FullHW_Part above.

Legacy_19Chip_Blocker_Trace:{
    verdict:"SUPERSEDED: old 19-chip sketch is blocked; FullHW_Part above replaces it with real hardware",

    chip_pin_audit:[
        {
            chip:"U1 74HC574 opcode IR",
            pins:"2-9=IBUS in, 11=IR_CLK, 12-19=opcode out, 1=/OE tied active",
            trace:"Fetch opcode; opcode[7:0] feeds microcode address; opcode[2:0] is rd for register address.",
            status:"PASS for opcode fetch and rd visibility"
        },
        {
            chip:"U2 74HC574 operand IR",
            pins:"2-9=IBUS in, 11=OPR_CLK, 12-19=operand out, 1=OPR_OE",
            trace:"Immediate/offset byte; may drive IBUS for immediate ALU input.",
            status:"PARTIAL: operand[7:5] source-register path to the address-force network is not pinned"
        },
        {
            chip:"U3 74HC574 ALU B latch",
            pins:"2-9=IBUS in, 11=ALUB_CLK, 12-19=B operand out, 1=/OE disabled",
            trace:"Holds immediate or source register for ADD/SUB/address math.",
            status:"PASS for ADD/SUB/SLL/address-add"
        },
        {
            chip:"U4/U5 74HC283 adders",
            pins:"A inputs=IBUS[7:0], B inputs=U6/U7 outputs, C0=ALU_SUB or carry-in, S[7:0]=U15.D",
            trace:"ADD, SUB, SLL, address add, PC relative add if PC path exists.",
            status:"PARTIAL: no proven carry-in control for SLT/SLTI and no PC-to-ALU path is pinned"
        },
        {
            chip:"U6/U7 74HC86 XOR bank",
            pins:"one input=U3.Q, other input=ALU_SUB, output=adder B",
            trace:"Inverts B for SUB.",
            status:"BLOCKED: this is not enough for ISA XOR; AND/OR are also physically missing"
        },
        {
            chip:"U8/U9 PC registers",
            pins:"current guide says 74HC574, 1=PC_ADDR_n, 11=PC_CLK, 12-19=A bus",
            trace:"Fetch address, PC increment, branch/jump target, IRQ vector, IRET restore.",
            status:"BLOCKED: docs elsewhere say 74HC161 PC; current 574 wiring has no complete increment/reset/load/save path"
        },
        {
            chip:"U10/U11 address latches",
            pins:"1=PC_ADDR, 11=ADDR_LO/HI_CLK, 12-19=A bus",
            trace:"Data memory address, register window address, fast-page address, IRQ save slots.",
            status:"BLOCKED: full A[15:0] source selection is not pinned"
        },
        {
            chip:"U12 74HC245 data bridge",
            pins:"1=BUF_DIR, 19=BUF_OE_n, 2-9=IBUS, 11-18=D bus",
            trace:"ROM/RAM read to IBUS and IBUS write to RAM.",
            status:"PASS if microcode guarantees U2, U12, and U15 are mutually exclusive IBUS drivers"
        },
        {
            chip:"U13/U17 microcode ROM outputs",
            pins:"addr={IRQ_ACTIVE,C,Z,step[2:0],opcode[7:0]}, data=control",
            trace:"Generates all step control signals.",
            status:"BLOCKED: guide mixes an 8-bit group-encoded control word with two direct-control ROM bytes"
        },
        {
            chip:"U14 74HC74 flags",
            pins:"D=zero/carry, CLK=FLAGS_CLK, Q=flag_z/flag_c to microcode address",
            trace:"BEQ/BNE and unsigned BLT/BGE/SLT decision source.",
            status:"PARTIAL: Z is straightforward; C/borrow convention for BLT/BGE/SLT must be frozen and tested"
        },
        {
            chip:"U16 74HC161 step counter",
            pins:"2=CLK, 1=STEP_RST_n, Q[2:0]=microcode address A[10:8]",
            trace:"Instruction sequencing.",
            status:"PASS for up to 8 micro-steps; instructions listed as 9 cycles need proof or a wider step sequence"
        },
        {
            chip:"U18 74HC157 register-address mux",
            pins:"1=REG_ADDR_MODE, selected low-nibble inputs go to U10.D[3:0]",
            trace:"Generate RAM register address $FFF8+reg.",
            status:"BLOCKED: one 157 only handles 4 bits; A[7:4] and A[15:8] force/mux path is not pin-proven"
        },
        {
            chip:"U22 74HC74 interrupt state",
            pins:"IE FF and IRQ_PENDING FF",
            trace:"EI, DI, IRQ latch, IRQ_ACTIVE to microcode A13.",
            status:"BLOCKED: SYS set/clear pins, IRQ edge polarity, IRQ_ACK clear, and IRET re-enable path are not pinned"
        }
    ],

    isa_feature_trace:[
        {
            feature:"Fetch/reset",
            required_path:"/RST -> PC=$0000; PC -> A[15:0]; ROM -> D bus -> U12 -> IBUS -> U1/U2",
            status:"BLOCKED by PC implementation conflict"
        },
        {
            feature:"LI/ADDI/SUBI/SLL and ADD/SUB",
            required_path:"U2 or RAM[reg] -> IBUS -> U3/adder -> U15 -> IBUS -> U12 -> RAM[$FFF8+rd]",
            status:"PARTIAL: path exists conceptually, but register address force and PC/fetch must be fixed"
        },
        {
            feature:"AND/OR/XOR/NOT",
            required_path:"A and B must feed real logic gates and an ALU result mux before U15",
            status:"BLOCKED: current physical ALU only routes adder result"
        },
        {
            feature:"SLT/SLTI/BLT/BGE",
            required_path:"subtract -> C/borrow flag -> microcode conditional write 0/1 or branch",
            status:"BLOCKED until carry-in/borrow convention and constant 0/1 write path are pinned"
        },
        {
            feature:"LB/SB off(rs)",
            required_path:"RAM[$FFF8+rs] -> ALU A; sign-extend off5 -> ALU B; result -> ADDR; RAM read/write",
            status:"BLOCKED: sign extension and address-high behavior are not pin-proven"
        },
        {
            feature:"LBfp/SBfp",
            required_path:"frozen memory map needs RAM fast-page address $FF00+imm8, with $FFF6-$FFFF reserved",
            status:"BLOCKED: fast-page high-byte force and reserved-slot protection are not pin-proven"
        },
        {
            feature:"PUSH/POP and LBsp/SBsp",
            required_path:"r7 SP at $FFFF -> increment/decrement -> write back SP -> use SP as address",
            status:"BLOCKED: needs SP update, address latch, and stack-page policy proof"
        },
        {
            feature:"BEQ/BNE/J",
            required_path:"compare registers or unconditional path -> PC += signed offset",
            status:"BLOCKED until PC add/load path is pinned"
        },
        {
            feature:"JAL/JALR/RET",
            required_path:"save PC low to rd; load PC from relative target or register/page target",
            status:"BLOCKED: no complete PC save/load/high-byte path"
        },
        {
            feature:"SYS NOP/HLT/EI/DI/IRET",
            required_path:"operand subdecode controls halt, U22, and PC restore from $FFF6/$FFF7",
            status:"BLOCKED except NOP; HLT gate, EI/DI pins, and IRET PC restore are not pinned"
        },
        {
            feature:"IRQ entry",
            required_path:"IRQ_ACTIVE -> save PC_LO/HI to RAM[$FFF6/$FFF7] -> PC=$7F00 -> clear IRQ state",
            status:"BLOCKED: no PC-to-data path, fixed IRQ save-address path, or vector-load path is pinned"
        }
    ],

    required_fixes_before_build:[
        "Freeze PC hardware: choose either 4x74HC161 counter PC with a real address mux/buffer, or 2x74HC574 ALU-loaded PC with a proven PC increment/reset/read path. Update all docs to one choice.",
        "Freeze control style: either keep 8-bit group-encoded control and add a decoder table, or document two direct-control ROM bytes. Do not mix both.",
        "Add or remove physical ALU logic ops. Full ISA needs AND/OR/XOR result generation and a result mux; otherwise reduce ISA to ADD/SUB/SLL plus macros.",
        "Replace the partial U18 address mux with a full address-source network for normal address, register $FFF8+reg, fast page, IRQ save slots, and vector/PC load support.",
        "Resolve fast-page hardware: with ROM at $0000-$7FFF, LBfp/SBfp must generate $FF00+imm8 and protect reserved $FFF6-$FFFF.",
        "Pin PC save/restore: JAL, IRQ entry, and IRET need PC low/high paths to and from RAM.",
        "Pin U22 interrupt controls: EI set, DI clear, IRQ edge capture, IRQ_ACK clear, and IRET re-enable.",
        "After fixes, regenerate this trace as PASS/PARTIAL/BLOCKED and only then produce KiCad-ready pin tables."
    ]
},

// ═══════════════════════════════════════════════════════════════
// VERIFICATION
// ═══════════════════════════════════════════════════════════════
//
// Bus conflicts: REAL FULLHW OWNERSHIP DEFINED
//   IBUS drivers: U2(OPR), U12(memory read), U15(ALU result), U44/U45(PC byte),
//                 U60(constant), U61(sign-extend). Microcode must assert only one.
//   ABUS source: U40-U43 select PCQ or ARQ; PC and AR never directly share ABUS.
//   DBUS source: ROM/RAM during read, U12 during write. ROM /WE is tied inactive.
//
// Register access path (real FullHW):
//   Read: ADDR_SRC=REG forces $FFF8+reg_id through U30-U37 into AR, U40-U43 select ARQ
//         → RAM outputs register value → U12 → IBUS → adder A
//   Write: U15 (result) drives IBUS → U12 → RAM[register addr] via /WR pulse
//   Status: real hardware path defined; KiCad/ERC and sim proof pending
//
// PC increment: U8-U11 74HC161 PC counts when PC_INC is asserted during fetch.
// Reset/boot: PC clears to $0000, so A15=0 selects Program ROM for the first fetch.
// RAM remains at $8000-$FFFF for data, optional RAM-loaded code, stack, IRQ save slots, and $FFF8-$FFFF registers.
//
// CHIP COUNT: FullHW target
//   Logic: 49 packages
//   Memory/control ROM: 2 microcode ROM + 1 program ROM + 1 RAM = 4 packages
//   Total: 53 packages
}

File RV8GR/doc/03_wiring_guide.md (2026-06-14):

# RV8-GR — Wiring Guide (Official)

**33 logic chips + ROM + RAM = 35 packages. Source of truth for physical build.**

---

## Memory Map

```
$0000-$7FFF  RAM 32KB (registers $00-$07, data, executable)
$8000-$FEFF  ROM 32KB (bankable to 128KB)
$FF00-$FF0F  ROM: IRQ vector + ISR entry
$FF10-$FF1F  I/O Slot 1 (/SLOT1 on bus)
$FF20-$FF2F  I/O Slot 2 (/SLOT2 on bus)
$FF30-$FFFF  ROM: ISR code
Reset → $8000
```

---

## Timing Note (Critical for ROM Selection)

**U5/U6 latch on rising edge of T0/T1** (= CLK edge that creates the phase).

ROM access window depends on when ADDR_MODE returns to 0 (PC on ABUS):

| Previous Instruction | ADDR_MODE during T2 | ROM access time available |
|---|:---:|:---:|
| LI, ADDI, SUBI, XORI, J, BEQ, BNE, SETPG, SETDP, EI, DI, NOP | 0 (PC on ABUS) | T2 + prop delay = ~115ns |
| LB, ADD, SUB, XOR, SETPG_R, SB | 1 (IRL on ABUS) | prop delay only = ~15ns ❌ |

**Issue**: After a data-access instruction (SRC=1 or STR=1), the address mux switches from IRL back to PC at T2→T0 transition. ROM then needs 150ns from new address — but U5 latches ~15ns later!

**Resolution**: The PC address was already on ABUS during T0+T1 of the CURRENT instruction. The ROM at that address was read and latched into U5/U6. For the NEXT instruction, PC has been incremented and the NEW address appears only after T2→T0 switch.

**Actually the correct model**: 
- U5 latches at T0↑ = captures data that ROM output during PREVIOUS T2/T0 overlap
- The design relies on: PC doesn't change during T2 (PC_INC=0), so ROM address stays valid

**Safe ROM timing**:
- AT28C256-150ns: works if ADDR_MODE=0 during previous T2 (most cases)
- After LB/SB/ADD/SUB/XOR: address switches late → may need extra cycle or faster ROM

**Recommendation**: Use **70ns ROM/RAM** + start at **5 MHz**.
70ns parts work reliably at 5 MHz (130ns margin).
Use 5 MHz crystal for the physical build.

---

## RV8-Bus (40-pin System Bus)

CPU board ↔ Expansion/Programmer ผ่าน 40-pin IDC connector

```
┌──────────────────────────────────────────────────────────┐
│                   RV8-Bus (40 pins)                        │
├──────────────────────────────────────────────────────────┤
│ Pin  Signal    Dir   │ Pin  Signal    Dir                 │
│  1   A0        out   │  2   A1        out                 │
│  3   A2        out   │  4   A3        out                 │
│  5   A4        out   │  6   A5        out                 │
│  7   A6        out   │  8   A7        out                 │
│  9   A8        out   │ 10   A9        out                 │
│ 11   A10       out   │ 12   A11       out                 │
│ 13   A12       out   │ 14   A13       out                 │
│ 15   A14       out   │ 16   A15       out                 │
│ 17   D0        bidir │ 18   D1        bidir               │
│ 19   D2        bidir │ 20   D3        bidir               │
│ 21   D4        bidir │ 22   D5        bidir               │
│ 23   D6        bidir │ 24   D7        bidir               │
│ 25   CLK       out   │ 26   /RST      out                 │
│ 27   /WR       out   │ 28   /RD       out                 │
│ 29   /IRQ      in    │ 30   /SLOT1    out                 │
│ 31   /SLOT2    out   │ 32   T2        out                 │
│ 33   A15       out   │ 34   (reserved)                    │
│ 35   (reserved)      │ 36   (reserved)                    │
│ 37   (reserved)      │ 38   (reserved)                    │
│ 39   VCC (+5V)       │ 40   GND                           │
└──────────────────────────────────────────────────────────┘
```

### Signal Description

| Pin | Signal | Dir | Source | Description |
|:---:|---|:---:|---|---|
| 1-16 | A[15:0] | out | Addr Mux | 16-bit address bus |
| 17-24 | D[7:0] | bidir | U7/ROM/RAM | 8-bit data bus |
| 25 | CLK | out | Oscillator | System clock (5 MHz) |
| 26 | /RST | out | RC+button | Active-low reset |
| 27 | /WR | out | /AC_BUF (U26-8) | Write strobe (LOW during T2+STORE) |
| 28 | /RD | out | /T2 or fetch | Read strobe |
| 29 | /IRQ | in | Peripheral | Interrupt request (falling edge) |
| 30 | /SLOT1 | out | Address decode | I/O slot 1 select |
| 31 | /SLOT2 | out | Address decode | I/O slot 2 select |
| 32 | T2 | out | U8-5 | Execute phase (for expansion timing) |
| 33 | A15 | out | U30-12 | Duplicate for chip select |
| 39 | VCC | — | Power | +5V |
| 40 | GND | — | Power | Ground |

### Bus Timing

```
        ┌───┐   ┌───┐   ┌───┐   ┌───┐
CLK:  ──┘   └───┘   └───┘   └───┘   └──
        T0       T1       T2       T0
A[15:0]: ←── PC ──→←── PC ──→←─ IRL ─→←── PC ──→
D[7:0]:  ←─ ctrl ─→←─ oper ─→←─ data ─→←─ ctrl ─→
/WR:   ─────────────────────┐       ┌───────────
                             └───────┘ (T2+STORE only)
```

---

## Buses

### DBUS — External Data Bus (D0-D7)

```
D0 ←→ ROM D0, RAM D0, U7-18
D1 ←→ ROM D1, RAM D1, U7-17
D2 ←→ ROM D2, RAM D2, U7-16
D3 ←→ ROM D3, RAM D3, U7-15
D4 ←→ ROM D4, RAM D4, U7-14
D5 ←→ ROM D5, RAM D5, U7-13
D6 ←→ ROM D6, RAM D6, U7-12
D7 ←→ ROM D7, RAM D7, U7-11
```

### IBUS — Internal Bus (IB0-IB7)

Drivers (tristate, only ONE active at T2):
- U7: ROM/RAM data (fetch or register read)
- U6: IRL immediate (SRC=0, STR=0)
- U14: AC value (STR=1)

```
IB0 ←→ U7-2, U6-19*, U14-18*, U12-1, U23-2, U5-2
IB1 ←→ U7-3, U6-18*, U14-17*, U12-4, U23-3, U5-3
IB2 ←→ U7-4, U6-17*, U14-16*, U12-9, U23-4, U5-4
IB3 ←→ U7-5, U6-16*, U14-15*, U12-12, U23-5, U5-5
IB4 ←→ U7-6, U6-15*, U14-14*, U13-1, U23-6, U5-6
IB5 ←→ U7-7, U6-14*, U14-13*, U13-4, U23-7, U5-7
IB6 ←→ U7-8, U6-13*, U14-12*, U13-9, U23-8, U5-8
IB7 ←→ U7-9, U6-12*, U14-11*, U13-12, U23-9, U5-9
```

### ABUS — Address Bus (A0-A15)

```
A0  ← U15-4     A8  ← U29-4
A1  ← U15-7     A9  ← U29-7
A2  ← U15-9     A10 ← U29-9
A3  ← U15-12    A11 ← U29-12
A4  ← U16-4     A12 ← U30-4
A5  ← U16-7     A13 ← U30-7
A6  ← U16-9     A14 ← U30-9
A7  ← U16-12    A15 ← U30-12
```

---

## Chip Pin Wiring

### U1-U2 74HC161 — PC Low (bits 0-7)

```
U1: PC bits 0-3
U1-1  (/CLR) ← /RST          U1-2  (CLK)  ← CLK
U1-3  (D0)   ← IRL0 (U6-19)  U1-4  (D1)   ← IRL1 (U6-18)
U1-5  (D2)   ← IRL2 (U6-17)  U1-6  (D3)   ← IRL3 (U6-16)
U1-7  (ENP)  ← PC_INC (U25-6)
U1-8  (GND)  → GND
U1-9  (/LD)  ← /PC_LD (U26-11)
U1-10 (ENT)  ← PC_INC (U25-6)
U1-11 (QD)   → PC3 → U15-14
U1-12 (QC)   → PC2 → U15-11
U1-13 (QB)   → PC1 → U15-5
U1-14 (QA)   → PC0 → U15-2
U1-15 (RCO)  → U2-10
U1-16 (VCC)  → VCC

U2: PC bits 4-7
U2-1  (/CLR) ← /RST          U2-2  (CLK)  ← CLK
U2-3  (D0)   ← IRL4 (U6-15)  U2-4  (D1)   ← IRL5 (U6-14)
U2-5  (D2)   ← IRL6 (U6-13)  U2-6  (D3)   ← IRL7 (U6-12)
U2-7  (ENP)  ← PC_INC (U25-6)
U2-8  (GND)  → GND
U2-9  (/LD)  ← /PC_LD (U26-11)
U2-10 (ENT)  ← U1-15 (RCO)
U2-11 (QD)   → PC7 → U16-14
U2-12 (QC)   → PC6 → U16-11
U2-13 (QB)   → PC5 → U16-5
U2-14 (QA)   → PC4 → U16-2
U2-15 (RCO)  → U3-10
U2-16 (VCC)  → VCC
```

### U3-U4 74HC161 — PC High (bits 8-15)

```
U3: PC bits 8-11
U3-1  (/CLR) ← /RST          U3-2  (CLK)  ← CLK
U3-3  (D0)   ← PG0 (U23-19)  U3-4  (D1)   ← PG1 (U23-18)
U3-5  (D2)   ← PG2 (U23-17)  U3-6  (D3)   ← PG3 (U23-16)
U3-7  (ENP)  ← PC_INC (U25-6)
U3-8  (GND)  → GND
U3-9  (/LD)  ← /PC_LD (U26-11)
U3-10 (ENT)  ← U2-15 (RCO)
U3-11 (QD)   → PC11 → U29-14
U3-12 (QC)   → PC10 → U29-11
U3-13 (QB)   → PC9  → U29-5
U3-14 (QA)   → PC8  → U29-2
U3-15 (RCO)  → U4-10
U3-16 (VCC)  → VCC

U4: PC bits 12-15
U4-1  (/CLR) ← /RST          U4-2  (CLK)  ← CLK
U4-3  (D0)   ← PG4 (U23-15)  U4-4  (D1)   ← PG5 (U23-14)
U4-5  (D2)   ← PG6 (U23-13)  U4-6  (D3)   ← PG7 (U23-12)
U4-7  (ENP)  ← PC_INC (U25-6)
U4-8  (GND)  → GND
U4-9  (/LD)  ← /PC_LD (U26-11)
U4-10 (ENT)  ← U3-15 (RCO)
U4-11 (QD)   → PC15 → U30-14
U4-12 (QC)   → PC14 → U30-11
U4-13 (QB)   → PC13 → U30-5
U4-14 (QA)   → PC12 → U30-2
U4-15 (RCO)  → NC
U4-16 (VCC)  → VCC
```

### U5 74HC574 — IR_HIGH (Control Byte)

```
U5-1  (/OE) → GND
U5-2  (D1)  ← IB0             U5-3  (D2)  ← IB1
U5-4  (D3)  ← IB2             U5-5  (D4)  ← IB3
U5-6  (D5)  ← IB4             U5-7  (D6)  ← IB5
U5-8  (D7)  ← IB6             U5-9  (D8)  ← IB7
U5-10 (GND) → GND
U5-11 (CLK) ← T0 (U8-3)
U5-12 (Q8)  → ALU_SUB (bit7)
U5-13 (Q7)  → XOR_MODE (bit6)
U5-14 (Q6)  → MUX_SEL (bit5)
U5-15 (Q5)  → AC_WR (bit4)
U5-16 (Q4)  → SOURCE_TYPE (bit3)
U5-17 (Q3)  → STORE (bit2)
U5-18 (Q2)  → BRANCH (bit1)
U5-19 (Q1)  → JUMP (bit0)
U5-20 (VCC) → VCC
```

### U6 74HC574 — IR_LOW (Operand)

```
U6-1  (/OE) ← /IRL_OE (U26-3)
U6-2  (D1)  ← IB0             U6-3  (D2)  ← IB1
U6-4  (D3)  ← IB2             U6-5  (D4)  ← IB3
U6-6  (D5)  ← IB4             U6-7  (D6)  ← IB5
U6-8  (D7)  ← IB6             U6-9  (D8)  ← IB7
U6-10 (GND) → GND
U6-11 (CLK) ← T1 (U8-4)
U6-12 (Q8)  → IRL7 → U16-13, U2-6, IB7*
U6-13 (Q7)  → IRL6 → U16-10, U2-5, IB6*
U6-14 (Q6)  → IRL5 → U16-6, U2-4, IB5*
U6-15 (Q5)  → IRL4 → U16-3, U2-3, IB4*
U6-16 (Q4)  → IRL3 → U15-13, U1-6, IB3*
U6-17 (Q3)  → IRL2 → U15-10, U1-5, IB2*
U6-18 (Q2)  → IRL1 → U15-6, U1-4, IB1*
U6-19 (Q1)  → IRL0 → U15-3, U1-3, IB0*
U6-20 (VCC) → VCC
```

### U7 74HC245 — Bus Buffer (DBUS↔IBUS)

```
U7-1  (DIR) ← WR_DIR (U28-8)
U7-2  (A1)  ←→ IB0            U7-18 (B1)  ←→ D0
U7-3  (A2)  ←→ IB1            U7-17 (B2)  ←→ D1
U7-4  (A3)  ←→ IB2            U7-16 (B3)  ←→ D2
U7-5  (A4)  ←→ IB3            U7-15 (B4)  ←→ D3
U7-6  (A5)  ←→ IB4            U7-14 (B5)  ←→ D4
U7-7  (A6)  ←→ IB5            U7-13 (B6)  ←→ D5
U7-8  (A7)  ←→ IB6            U7-12 (B7)  ←→ D6
U7-9  (A8)  ←→ IB7            U7-11 (B8)  ←→ D7
U7-10 (GND) → GND
U7-19 (/OE) ← BUF_OE_SAFE (U25-8)
U7-20 (VCC) → VCC

Direction (real 74HC245 datasheet):
  DIR=0 (WR_DIR=0): B→A = DBUS→IBUS (READ)
  DIR=1 (WR_DIR=1): A→B = IBUS→DBUS (WRITE/STORE)
```

### U8 74HC164 — Ring Counter (T0/T1/T2)

```
U8-1  (A)    ← NOT(Q0) (U24-2)
U8-2  (B)    ← NOT(Q1) (U24-4)
U8-3  (Q0)   → T0
U8-4  (Q1)   → T1
U8-5  (Q2)   → T2
U8-6  (Q3)   → NC
U8-7  (GND)  → GND
U8-8  (CLK)  ← CLK
U8-9  (/CLR) ← /RST
U8-10..13    → NC
U8-14 (VCC)  → VCC
```

### U9 74HC574 — Accumulator

```
U9-1  (/OE) → GND
U9-2  (D1)  ← U17-4 (Y0)     U9-3  (D2)  ← U17-7 (Y1)
U9-4  (D3)  ← U17-9 (Y2)     U9-5  (D4)  ← U17-12 (Y3)
U9-6  (D5)  ← U18-4 (Y4)     U9-7  (D6)  ← U18-7 (Y5)
U9-8  (D7)  ← U18-9 (Y6)     U9-9  (D8)  ← U18-12 (Y7)
U9-10 (GND) → GND
U9-11 (CLK) ← Acc_Load_N (U27-11)
U9-12 (Q8)  → AC7 → U11-12, U20-13, U14-9, U22-18
U9-13 (Q7)  → AC6 → U11-14, U20-10, U14-8, U22-16
U9-14 (Q6)  → AC5 → U11-3, U20-6, U14-7, U22-14
U9-15 (Q5)  → AC4 → U11-5, U20-3, U14-6, U22-12
U9-16 (Q4)  → AC3 → U10-12, U19-13, U14-5, U22-8
U9-17 (Q3)  → AC2 → U10-14, U19-10, U14-4, U22-6
U9-18 (Q2)  → AC1 → U10-3, U19-6, U14-3, U22-4
U9-19 (Q1)  → AC0 → U10-5, U19-3, U14-2, U22-2
U9-20 (VCC) → VCC
```

### U10-U11 74HC283 — ALU Adder

```
U10: bits 0-3
U10-5 (A0) ← AC0    U10-6 (B0) ← XOR_Y0 (U12-3)
U10-3 (A1) ← AC1    U10-2 (B1) ← XOR_Y1 (U12-6)
U10-14(A2) ← AC2    U10-15(B2) ← XOR_Y2 (U12-8)
U10-12(A3) ← AC3    U10-11(B3) ← XOR_Y3 (U12-11)
U10-7 (Cin) ← ALU_SUB (U5-12)
U10-4 (S0) → SUM0 → U17-2     U10-1 (S1) → SUM1 → U17-5
U10-13(S2) → SUM2 → U17-11    U10-10(S3) → SUM3 → U17-14
U10-9 (Cout) → U11-7
U10-8 (GND) → GND   U10-16(VCC) → VCC

U11: bits 4-7
U11-5 (A0) ← AC4    U11-6 (B0) ← XOR_Y4 (U13-3)
U11-3 (A1) ← AC5    U11-2 (B1) ← XOR_Y5 (U13-6)
U11-14(A2) ← AC6    U11-15(B2) ← XOR_Y6 (U13-8)
U11-12(A3) ← AC7    U11-11(B3) ← XOR_Y7 (U13-11)
U11-7 (Cin) ← U10-9 (Cout)
U11-4 (S0) → SUM4 → U18-2     U11-1 (S1) → SUM5 → U18-5
U11-13(S2) → SUM6 → U18-11    U11-10(S3) → SUM7 → U18-14
U11-9 (Cout) → NC
U11-8 (GND) → GND   U11-16(VCC) → VCC
```

### U12-U13 74HC86 — XOR Array

```
U12: bits 0-3 (A=IBUS, B=mux output)
U12-1 (A1) ← IB0    U12-2 (B1) ← U19-4    U12-3 (Y1) → XOR_Y0 → U10-6, U17-3
U12-4 (A2) ← IB1    U12-5 (B2) ← U19-7    U12-6 (Y2) → XOR_Y1 → U10-2, U17-6
U12-9 (A3) ← IB2    U12-10(B3) ← U19-9    U12-8 (Y3) → XOR_Y2 → U10-15, U17-10
U12-12(A4) ← IB3    U12-13(B4) ← U19-12   U12-11(Y4) → XOR_Y3 → U10-11, U17-13
U12-7 (GND) → GND   U12-14(VCC) → VCC

U13: bits 4-7
U13-1 (A1) ← IB4    U13-2 (B1) ← U20-4    U13-3 (Y1) → XOR_Y4 → U11-6, U18-3
U13-4 (A2) ← IB5    U13-5 (B2) ← U20-7    U13-6 (Y2) → XOR_Y5 → U11-2, U18-6
U13-9 (A3) ← IB6    U13-10(B3) ← U20-9    U13-8 (Y3) → XOR_Y6 → U11-15, U18-10
U13-12(A4) ← IB7    U13-13(B4) ← U20-12   U13-11(Y4) → XOR_Y7 → U11-11, U18-13
U13-7 (GND) → GND   U13-14(VCC) → VCC
```

### U14 74HC541 — AC Output Buffer

```
U14-1 (/OE1) ← /AC_BUF (U26-8)
U14-2  (A1) ← AC0    U14-18 (Y1) → IB0
U14-3  (A2) ← AC1    U14-17 (Y2) → IB1
U14-4  (A3) ← AC2    U14-16 (Y3) → IB2
U14-5  (A4) ← AC3    U14-15 (Y4) → IB3
U14-6  (A5) ← AC4    U14-14 (Y5) → IB4
U14-7  (A6) ← AC5    U14-13 (Y6) → IB5
U14-8  (A7) ← AC6    U14-12 (Y7) → IB6
U14-9  (A8) ← AC7    U14-11 (Y8) → IB7
U14-10 (GND) → GND
U14-19 (/OE2) ← /AC_BUF (U26-8)
U14-20 (VCC) → VCC
```

### U15-U16 74HC157 — Address Mux A[7:0] (PC vs IRL)

```
SEL=0: PC, SEL=1: IRL

U15-1 (SEL) ← ADDR_MODE (U25-3)    U15-15(/E) → GND
U15-2 (1A) ← PC0   U15-3 (1B) ← IRL0   U15-4 (1Y) → A0
U15-5 (2A) ← PC1   U15-6 (2B) ← IRL1   U15-7 (2Y) → A1
U15-11(3A) ← PC2   U15-10(3B) ← IRL2   U15-9 (3Y) → A2
U15-14(4A) ← PC3   U15-13(4B) ← IRL3   U15-12(4Y) → A3
U15-8 (GND) → GND  U15-16(VCC) → VCC

U16-1 (SEL) ← ADDR_MODE             U16-15(/E) → GND
U16-2 (1A) ← PC4   U16-3 (1B) ← IRL4   U16-4 (1Y) → A4
U16-5 (2A) ← PC5   U16-6 (2B) ← IRL5   U16-7 (2Y) → A5
U16-11(3A) ← PC6   U16-10(3B) ← IRL6   U16-9 (3Y) → A6
U16-14(4A) ← PC7   U16-13(4B) ← IRL7   U16-12(4Y) → A7
U16-8 (GND) → GND  U16-16(VCC) → VCC
```

### U17-U18 74HC157 — AC Input Mux (Adder vs XOR)

```
SEL=0: Adder SUM, SEL=1: XOR output

U17-1 (SEL) ← MUX_SEL (U5-14)      U17-15(/E) → GND
U17-2 (1A) ← SUM0   U17-3 (1B) ← XOR_Y0   U17-4 (1Y) → U9-2
U17-5 (2A) ← SUM1   U17-6 (2B) ← XOR_Y1   U17-7 (2Y) → U9-3
U17-11(3A) ← SUM2   U17-10(3B) ← XOR_Y2   U17-9 (3Y) → U9-4
U17-14(4A) ← SUM3   U17-13(4B) ← XOR_Y3   U17-12(4Y) → U9-5
U17-8 (GND) → GND   U17-16(VCC) → VCC

U18-1 (SEL) ← MUX_SEL (U5-14)      U18-15(/E) → GND
U18-2 (1A) ← SUM4   U18-3 (1B) ← XOR_Y4   U18-4 (1Y) → U9-6
U18-5 (2A) ← SUM5   U18-6 (2B) ← XOR_Y5   U18-7 (2Y) → U9-7
U18-11(3A) ← SUM6   U18-10(3B) ← XOR_Y6   U18-9 (3Y) → U9-8
U18-14(4A) ← SUM7   U18-13(4B) ← XOR_Y7   U18-12(4Y) → U9-9
U18-8 (GND) → GND   U18-16(VCC) → VCC
```

### U19-U20 74HC157 — XOR B-Input Mux (SUB vs AC)

```
SEL=0: ALU_SUB (for ADD/SUB), SEL=1: AC bits (for XOR instr)

U19-1 (SEL) ← XOR_MODE (U5-13)     U19-15(/E) → GND
U19-2 (1A) ← SUB   U19-3 (1B) ← AC0   U19-4 (1Y) → U12-2
U19-5 (2A) ← SUB   U19-6 (2B) ← AC1   U19-7 (2Y) → U12-5
U19-11(3A) ← SUB   U19-10(3B) ← AC2   U19-9 (3Y) → U12-10
U19-14(4A) ← SUB   U19-13(4B) ← AC3   U19-12(4Y) → U12-13
U19-8 (GND) → GND  U19-16(VCC) → VCC

U20-1 (SEL) ← XOR_MODE (U5-13)     U20-15(/E) → GND
U20-2 (1A) ← SUB   U20-3 (1B) ← AC4   U20-4 (1Y) → U13-2
U20-5 (2A) ← SUB   U20-6 (2B) ← AC5   U20-7 (2Y) → U13-5
U20-11(3A) ← SUB   U20-10(3B) ← AC6   U20-9 (3Y) → U13-10
U20-14(4A) ← SUB   U20-13(4B) ← AC7   U20-12(4Y) → U13-13
U20-8 (GND) → GND  U20-16(VCC) → VCC
```

### U21 74HC74 — Z Flag

```
U21-1 (/CLR1) → VCC
U21-2 (D1)    → GND
U21-3 (CLK1)  ← Acc_Load_N (U27-11)
U21-4 (/PR1)  ← U22-19 (/P=Q)
U21-5 (Q1)    → Z_flag → U28-1
U21-6 (/Q1)   → NC
U21-7 (GND)   → GND
U21-8..13     → FF2 unused (CLK2=GND, /PR2=VCC, /CLR2=VCC, D2=GND)
U21-14(VCC)   → VCC
```

### U22 74HC688 — Zero Detect

```
U22-1 (/OE) → GND
U22-2 (P0) ← AC0   U22-3 (Q0) → GND
U22-4 (P1) ← AC1   U22-5 (Q1) → GND
U22-6 (P2) ← AC2   U22-7 (Q2) → GND
U22-8 (P3) ← AC3   U22-9 (Q3) → GND
U22-10(GND) → GND
U22-11(Q4) → GND   U22-12(P4) ← AC4
U22-13(Q5) → GND   U22-14(P5) ← AC5
U22-15(Q6) → GND   U22-16(P6) ← AC6
U22-17(Q7) → GND   U22-18(P7) ← AC7
U22-19(/P=Q) → U21-4
U22-20(VCC) → VCC
```

### U23 74HC574 — Page Register

```
U23-1 (/OE) → GND
U23-2 (D1) ← IB0   U23-3 (D2) ← IB1
U23-4 (D3) ← IB2   U23-5 (D4) ← IB3
U23-6 (D5) ← IB4   U23-7 (D6) ← IB5
U23-8 (D7) ← IB6   U23-9 (D8) ← IB7
U23-10(GND) → GND
U23-11(CLK) ← PG_Load_N (U25-13)
U23-12(Q8) → PG7 → U4-6     U23-13(Q7) → PG6 → U4-5
U23-14(Q6) → PG5 → U4-4     U23-15(Q5) → PG4 → U4-3
U23-16(Q4) → PG3 → U3-6     U23-17(Q3) → PG2 → U3-5
U23-18(Q2) → PG1 → U3-4     U23-19(Q1) → PG0 → U3-3
U23-20(VCC) → VCC
```

### U24 74HC04 — Inverters

```
U24-1 (1A) ← T0 (U8-3)         U24-2 (1Y) → NOT(Q0) → U8-1
U24-3 (2A) ← T1 (U8-4)         U24-4 (2Y) → NOT(Q1) → U8-2
U24-5 (3A) ← A15 (U30-12)      U24-6 (3Y) → /A15 → ROM /CE
U24-7 (GND) → GND
U24-9 (4A) ← JUMP (U5-19)      U24-8 (4Y) → /JUMP → U27-4
U24-11(5A) ← AC_WR (U5-15)     U24-10(5Y) → /AC_WR → U27-10
U24-13(6A) ← /IRL_OE (U26-3)   U24-12(6Y) → BUF_OE_N → U25-9
U24-14(VCC) → VCC
```

### U25 74HC32 — OR Gates

```
U25-1 (1A) ← SRC (U5-16)   U25-2 (1B) ← STR (U5-17)   U25-3 (1Y) → ADDR_MODE
U25-4 (2A) ← T0 (U8-3)     U25-5 (2B) ← T1 (U8-4)     U25-6 (2Y) → PC_INC
U25-7 (GND) → GND
U25-9 (3A) ← BUF_OE_N (U24-12)  U25-10(3B) ← STR (U5-17)  U25-8 (3Y) → BUF_OE_SAFE → U7-19
U25-11(4A) ← /T2 (U28-6)   U25-12(4B) ← /PG_cond(U27-8) U25-13(4Y) → PG_Load_N → U23-11
U25-14(VCC) → VCC
```

### U26 74HC00 — NAND #1

```
Gate A: /IRL_OE = NAND(T2, /ADDR_MODE)
U26-1 ← T2 (U8-5)   U26-2 ← /ADDR_MODE (U26-6)   U26-3 → /IRL_OE → U6-1, U24-13

Gate B: /ADDR_MODE = NAND(ADDR_MODE, ADDR_MODE) = NOT
U26-4 ← ADDR_MODE   U26-5 ← ADDR_MODE   U26-6 → /ADDR_MODE → U26-2

Gate C: /AC_BUF = NAND(T2, STORE)
U26-9 ← T2 (U8-5)   U26-10 ← STR (U5-17)   U26-8 → /AC_BUF → U14-1/19, RAM /WE, U28-9

Gate D: /PC_LD = NAND(T2, PC_LOAD_COND)
U26-12 ← T2 (U8-5)   U26-13 ← PC_LOAD_COND (U27-6)   U26-11 → /PC_LD → U1-9..U4-9

U26-7 (GND) → GND   U26-14(VCC) → VCC
```

### U27 74HC00 — NAND #2

```
Gate A: /BR_TAKEN = NAND(BRANCH, Z_match)
U27-1 ← BR (U5-18)   U27-2 ← Z_match (U28-3)   U27-3 → /BR_TAKEN → U27-5

Gate B: PC_LOAD_COND = NAND(/JUMP, /BR_TAKEN) = JUMP OR BR_TAKEN
U27-4 ← /JUMP (U24-8)   U27-5 ← /BR_TAKEN (U27-3)   U27-6 → PC_LOAD_COND → U26-13

Gate C: /PG_cond = NAND(MUX_SEL, /AC_WR)
U27-9 ← MUX (U5-14)   U27-10 ← /AC_WR (U24-10)   U27-8 → /PG_cond → U25-12

Gate D: Acc_Load_N = NAND(T2, AC_WR)
U27-12 ← T2 (U8-5)   U27-13 ← AC_WR (U5-15)   U27-11 → Acc_Load_N → U9-11, U21-3

U27-7 (GND) → GND   U27-14(VCC) → VCC
```

### U28 74HC86 — XOR (Misc)

```
Gate A: Z_match = Z_flag XOR ALU_SUB
U28-1 ← Z_flag (U21-5)   U28-2 ← SUB (U5-12)   U28-3 → Z_match → U27-2

Gate B: /T2 = T2 XOR 1 = NOT(T2)
U28-4 ← T2 (U8-5)   U28-5 → VCC   U28-6 → /T2 → U25-11

Gate C: WR_DIR = /AC_BUF XOR 1 = NOT(/AC_BUF)
U28-9 ← /AC_BUF (U26-8)   U28-10 → VCC   U28-8 → WR_DIR → U7-1

Gate D: spare
U28-12 → NC   U28-13 → NC   U28-11 → NC

U28-7 (GND) → GND   U28-14(VCC) → VCC
```

### U29-U30 74HC157 — Address Mux A[15:8] (PC high vs Data Page)

```
SEL=0: PC high, SEL=1: Data Page Register (U32 Q outputs)

U29-1 (SEL) ← ADDR_MODE        U29-15(/E) → GND
U29-2 (1A) ← PC8    U29-3 (1B) ← DP0 (U32-19)   U29-4 (1Y) → A8
U29-5 (2A) ← PC9    U29-6 (2B) ← DP1 (U32-18)   U29-7 (2Y) → A9
U29-11(3A) ← PC10   U29-10(3B) ← DP2 (U32-17)   U29-9 (3Y) → A10
U29-14(4A) ← PC11   U29-13(4B) ← DP3 (U32-16)   U29-12(4Y) → A11
U29-8 (GND) → GND   U29-16(VCC) → VCC

U30-1 (SEL) ← ADDR_MODE        U30-15(/E) → GND
U30-2 (1A) ← PC12   U30-3 (1B) ← DP4 (U32-15)   U30-4 (1Y) → A12
U30-5 (2A) ← PC13   U30-6 (2B) ← DP5 (U32-14)   U30-7 (2Y) → A13
U30-11(3A) ← PC14   U30-10(3B) ← DP6 (U32-13)   U30-9 (3Y) → A14
U30-14(4A) ← PC15   U30-13(4B) ← DP7 (U32-12)    U30-12(4Y) → A15 → RAM /CE, U24-5
U30-8 (GND) → GND   U30-16(VCC) → VCC
```

### U31 74HC74 — IRQ (IE_FF + IRQ_FF)

```
FF-A: IE flag
U31-1 (/CLR1) ← DI_decode OR IRQ_ack
U31-2 (D1)    → VCC
U31-3 (CLK1)  ← EI_decode (T2 AND ir_high=$08)
U31-4 (/PR1)  → VCC
U31-5 (Q1)    → IE → IRQ-ack gate
U31-6 (/Q1)   → NC

FF-B: IRQ latch
U31-7 (GND)   → GND
U31-8 (/CLR2) ← IRQ_ack
U31-9 (D2)    → VCC
U31-10(CLK2)  ← /IRQ (external, falling edge)
U31-11(/PR2)  → VCC
U31-12(Q2)    → IRQ_FF → IRQ-ack gate
U31-13(/Q2)   → NC
U31-14(VCC)   → VCC

IRQ_ack = T2 AND IE(U31-5) AND IRQ_FF(U31-12) AND NOT(PC_LOAD_COND(U27-6))
// NOT(PC_LOAD_COND) = NOT( JMP | (BR & Z_match) )
// = CPU is NOT jumping/branching this cycle
// ≠ /PC_LD signal (which is NAND(T2, PC_LOAD_COND))
// IRQ_ack uses the raw combinational PC_LOAD_COND, inverted
On ack: force PG=$FF, IRL=$00, assert /PC_LD → PC=$FF00, clear IE+IRQ_FF
PC save: software (v1.0) or hardware (v2.0, see IRQ Save-PC section below)
```

---

### U32 74HC574 — Data Page Register

```
U32-1 (/OE) → GND
U32-2 (D1) ← IB0   U32-3 (D2) ← IB1
U32-4 (D3) ← IB2   U32-5 (D4) ← IB3
U32-6 (D5) ← IB4   U32-7 (D6) ← IB5
U32-8 (D7) ← IB6   U32-9 (D8) ← IB7
U32-10(GND) → GND
U32-11(CLK) ← DP_Load (decode: T2 AND SETDP)
U32-12(Q8) → DP7 → U30-13 (A15 B-input, enables ROM read)
U32-13(Q7) → DP6 → U30-10 (A14 B-input)
U32-14(Q6) → DP5 → U30-6 (A13 B-input)
U32-15(Q5) → DP4 → U30-3 (A12 B-input)
U32-16(Q4) → DP3 → U29-13 (A11 B-input)
U32-17(Q3) → DP2 → U29-10 (A10 B-input)
U32-18(Q2) → DP1 → U29-6 (A9 B-input)
U32-19(Q1) → DP0 → U29-3 (A8 B-input)
U32-20(VCC) → VCC

### U33 74HC21 — SETDP Decode (dual 4-input AND)

```
U33-1  (1A) ← T2 (U8-5)
U33-2  (1B) ← XOR_MODE (U5-13)
U33-3  (NC)
U33-4  (1C) ← /ADDR_MODE (U26-6)
U33-5  (1D) ← /AC_WR (U24-10)
U33-6  (1Y) → DP_Load → U32-11
U33-7  (GND) → GND
U33-8  (2Y) → NC
U33-9  (2A) → VCC (unused gate, tie inputs high)
U33-10 (2B) → VCC
U33-11 (NC)
U33-12 (2C) → VCC
U33-13 (2D) → VCC
U33-14 (VCC) → VCC
```

Decode verification:
| Opcode | T2 | XOR | /ADDR | /AC_WR | DP_Load |
|:------:|:--:|:---:|:-----:|:------:|:-------:|
| SETDP $40 | 1 | 1 | 1 | 1 | **1** ✓ |
| DI $48 | 1 | 1 | 0 | 1 | 0 ✓ |
| XORI $70 | 1 | 1 | 1 | 0 | 0 ✓ |
| SETPG $20 | 1 | 0 | 1 | 1 | 0 ✓ |
| $C0 (SUB+XOR) | 1 | 1 | 1 | 1 | **1** (= SETDP alias, harmless) |

Note: $C0 triggers DP_Load but is equivalent to SETDP (SUB bit has no effect when AC_WR=0).

---

### IRQ Save-PC Logic (Pin-Level)

During IRQ-ack, CPU must:
1. Write PC[7:0] to RAM[$0E]
2. Write PC[15:8] to RAM[$0F]
3. Force PC = $FF00

**Implementation**: IRQ-ack reuses existing STORE path with forced address.

```
IRQ_ack = T2(U8-5) AND IRQ_FF(U31-12) AND IE(U31-5) AND NOT(PC_LOAD_COND(U27-6))

Note: NOT(PC_LOAD_COND) means the instruction is NOT a jump/branch.
This is NOT the same as /PC_LD (which = NAND(T2, PC_LOAD_COND)).
IRQ_ack needs the raw PC_LOAD_COND inverted:
  PC_LOAD_COND=0 → NOT=1 → IRQ can fire
  PC_LOAD_COND=1 → NOT=0 → IRQ deferred (jump in progress)

During IRQ-ack (extra 2 cycles inserted by hardware):

Cycle 1 — Save PC low:
  Force ADDR_MODE=1, address=$0E
  Force AC buffer to drive PC[7:0] onto IBUS (override U14 input)
  RAM /WE pulse → RAM[$0E] = PC[7:0]

Cycle 2 — Save PC high:
  Force address=$0F
  Drive PC[15:8] onto IBUS
  RAM /WE pulse → RAM[$0F] = PC[15:8]

Then:
  Force page_reg = $FF, ir_low = $00
  Assert /PC_LD → PC loads $FF00
  Clear IE (U31 /CLR1)
  Clear IRQ_FF (U31 /CLR2)
```

**Hardware complexity note**:
The IRQ save-PC requires additional multiplexing to:
- Drive PC bytes onto IBUS (normally only AC goes to IBUS via U14)
- Force address $0E/$0F (normally IRL provides address)

**Options for physical build**:

| Approach | Extra Chips | Complexity |
|----------|:-----------:|:----------:|
| A: Software save (ISR reads PC from known location) | 0 | Simple |
| B: Dedicated save circuit (mux PC onto bus) | 2-3 chips | Complex |
| C: Use return address register (like CALL) | 1 chip | Medium |

**Recommended for v1.0 build: Option A (software ISR)**

In practice, the Verilog model handles save-PC in behavioral code.
For physical build v1.0, the ISR at $FF00 can use a fixed return point
or the programmer can store return address before enabling interrupts.

Future v2.0: Add dedicated PC-save hardware if needed.

Note: A15 from U32 bit 7 → allows data access to both ROM and RAM (full 64KB).

---

## ROM & RAM

```
ROM (AT28C256 / SST39SF010A)
  A[0:7]  ← ABUS A[0:7]
  A[8:14] ← ABUS A[8:14]
  D[0:7]  → DBUS
  /CE     ← /A15 (U24-6)
  /OE     → GND
  /WE     → VCC

RAM (62256)
  A[0:7]  ← ABUS A[0:7]
  A[8:14] ← ABUS A[8:14]
  D[0:7]  ←→ DBUS
  /CE     ← A15 (U30-12)
  /OE     → GND
  /WE     ← /AC_BUF (U26-8)
```

---

## Control Signal Summary

| Signal | Source | Destinations |
|--------|--------|-------------|
| CLK | Oscillator | U1-2, U2-2, U3-2, U4-2, U8-8 |
| /RST | RC+button | U1-1, U2-1, U3-1, U4-1, U8-9 |
| T0 | U8-3 | U5-11, U25-4, U24-1 |
| T1 | U8-4 | U6-11, U25-5, U24-3 |
| T2 | U8-5 | U26-1, U26-9, U26-12, U27-12, U28-4 |
| ALU_SUB | U5-12 | U10-7, U19-2/5/11/14, U20-2/5/11/14, U28-2 |
| XOR_MODE | U5-13 | U19-1, U20-1 |
| MUX_SEL | U5-14 | U17-1, U18-1, U27-9 |
| AC_WR | U5-15 | U24-11, U27-13 |
| SRC | U5-16 | U25-1 |
| STR | U5-17 | U25-2, U26-10 |
| BR | U5-18 | U25-10, U27-1 |
| JMP | U5-19 | U24-9, U25-9 |
| ADDR_MODE | U25-3 | U15-1, U16-1, U29-1, U30-1, U26-4/5 |
| PC_INC | U25-6 | U1-7/10, U2-7, U3-7, U4-7 |
| /PC_LD | U26-11 | U1-9, U2-9, U3-9, U4-9 |
| /AC_BUF | U26-8 | U14-1/19, RAM /WE, U28-9 |
| Acc_Load_N | U27-11 | U9-11, U21-3 |
| BUF_OE_N | U24-12 | U25-9 |
| BUF_OE_SAFE | U25-8 | U7-19 |
| WR_DIR | U28-8 | U7-1 |
| A15 | U30-12 | RAM /CE, U24-5 |
| PG_Load_N | U25-13 | U23-11 |
| DP_Load | U33-6 | U32-11 |

---

## Power

| Package | VCC | GND | Bypass |
|---------|:---:|:---:|:------:|
| 74HC161 (U1-U4) | 16 | 8 | 100nF |
| 74HC574 (U5,U6,U9,U23,U32) | 20 | 10 | 100nF |
| 74HC21 (U33) | 14 | 7 | 100nF |
| 74HC245 (U7) | 20 | 10 | 100nF |
| 74HC164 (U8) | 14 | 7 | 100nF |
| 74HC283 (U10-U11) | 16 | 8 | 100nF |
| 74HC86 (U12,U13,U28) | 14 | 7 | 100nF |
| 74HC541 (U14) | 20 | 10 | 100nF |
| 74HC157 (U15-U20,U29-U30) | 16 | 8 | 100nF |
| 74HC74 (U21,U31) | 14 | 7 | 100nF |
| 74HC688 (U22) | 20 | 10 | 100nF |
| 74HC04 (U24) | 14 | 7 | 100nF |
| 74HC32 (U25) | 14 | 7 | 100nF |
| 74HC00 (U26-U27) | 14 | 7 | 100nF |

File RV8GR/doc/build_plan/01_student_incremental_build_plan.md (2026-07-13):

# RV8-GR Student Incremental Build Plan

Build the CPU in small modules. Test each module before adding the next one.
The goal is to reduce mistakes: fewer chips powered at once, fewer wires to
debug, and one clear pass condition per stage.

This plan follows the v1.0 34-logic-chip wiring guide:
- IRQ is polling-only. No hardware vector.
- DI has no hardware effect.
- U7 `/OE` is `BUF_OE_N` from U24-12.
- ROM `/OE` is `WR_DIR` from U28-8.
- U31 IRQ latch uses Q2 on U31-9 and `/IRQ` clock on U31-11.

Use this document with:
- `doc/01_wiring_guide.md` for exact pin wiring.
- `doc/05_debug_plan.md` for deeper fault checks.
- `doc/06_kicad_modules.md` for KiCad sheet/module names.
- `doc/07_real_build_timing_log.md` for voltage, clock, bus-race, edge, and
  propagation-delay evidence after the staged build works.
- `doc/build_plan/02_student_worksheet.md` for student-facing stage cards.

Recommended software checks before a class or build session:

```bash
cd /home/jo/kiro/RV8/RV8GR
python3 -B sim/chip_sim.py
python3 -B sim/verify_wiring.py
python3 -B sim/soft_debug.py
python3 -B tools/test_rv8gr_asm.py
python3 -B sim/chips/test_chips.py
python3 -B sim/verify_components.py

cd /home/jo/kiro/Components
PYTHONPATH=python python3 -B -m chiplib.cli circuit-faults examples/circuits/RV8GR_WholeSystemChipLevelVirtual/circuit.json
```

These are virtual checks. They help find model, wiring-table, pin, active-low,
and bus-owner mistakes before students touch hardware. They do not replace
physical signoff on the real build.

---

## Student Baseline Contract

Build only this baseline before attempting any upgrade:

- 34 logic chips + ROM + RAM = 36 packages.
- No microcode ROM.
- No hardware IRQ vector.
- Every instruction uses T0, T1, T2.
- Only one IBUS driver may be active.
- Only one DBUS driver may be active.
- Each stage must pass before the next stage starts.

Future features such as hardware IRQ vectoring, ROM banking hardware, RETI,
and automatic PC save/restore are not part of this build plan.

---

## Build Rules

1. Build only one stage at a time.
2. Add power and 100nF bypass capacitor to every IC as soon as it is placed.
3. Keep a slow single-step clock until the full system test passes.
4. Put LEDs on the signal listed in each stage.
5. Do not continue if the stage does not pass.
6. When a stage fails, check power, ground, pin numbers, then signal polarity.

Recommended debug tools:
- 8 LED probe board for buses.
- 1 LED for single control signals.
- Logic probe or multimeter.
- Single-step clock button with debounce.
- Known ROM bytes for tests.

---

## Stage 0: Power, Clock, Reset

**Chips added**: none of the CPU logic yet.

**Build**
- 5V power rails.
- Ground rails.
- Reset circuit generating `/RST`.
- Single-step clock or slow 555 clock.
- LED on `CLK`.

**Test**
- VCC is 4.8V to 5.2V at the far end of the breadboard.
- GND continuity is good everywhere.
- Press clock once: exactly one pulse.
- Press reset: `/RST` goes LOW, then returns HIGH.

**Pass**
- Clock is clean.
- Reset is clean.
- No chips are hot.

**Do not continue if**
- Clock bounces.
- VCC drops below 4.8V.
- Reset floats.

---

## Stage 1: Ring Counter

**Chips added**: U8, U24 gates 1-2.

**Chip count in this stage**: 2 packages placed, but U24 is shared later.

**Build**
- U8 74HC164.
- U24 gates:
  - U24-1 <- T0, U24-2 -> U8-1.
  - U24-3 <- T1, U24-4 -> U8-2.
- U8-8 <- CLK.
- U8-9 <- `/RST`.
- LEDs on:
  - T0 = U8-3.
  - T1 = U8-4.
  - T2 = U8-5.

**Test**
- Reset.
- Single-step clock.

**Expected**
```text
Reset asserted: T0=0 T1=0 T2=0
Clock 1 after reset release: T0=1 T1=0 T2=0
Clock 2: T0=0 T1=1 T2=0
Clock 3: T0=0 T1=0 T2=1
Clock 4: T0=1 T1=0 T2=0
```

**Pass**
- T0, T1, T2 rotate cleanly and repeat.

**Common mistakes**
- U24 inverter inputs/outputs swapped.
- U8 A/B inputs not both connected to feedback.
- Clock bounce makes the ring skip states.

---

## Stage 2: Program Counter Low Byte

**Chips added**: U1, U2.

**Total logic chips now**: 4 packages placed including U8/U24.

**Build**
- U1-U2 74HC161.
- U1-2, U2-2 <- CLK.
- U1-1, U2-1 <- `/RST`.
- Temporarily tie `PC_INC` HIGH for this isolated test:
  - U1-7, U1-10, U2-7 <- VCC.
- U2-10 <- U1-15.
- Tie `/LD` HIGH for count test:
  - U1-9, U2-9 <- VCC.
- LEDs on PC0-PC7:
  - U1 QA-QD = PC0-PC3.
  - U2 QA-QD = PC4-PC7.

**Test**
- Reset.
- Single-step 20 clocks.

**Expected**
```text
Reset: PC low = $00
Clock 1: $01
Clock 2: $02
...
Clock 15: $0F
Clock 16: $10
```

**Pass**
- U1 counts 0-15.
- U2 increments when U1 rolls over.

**Before continuing**
- Remove temporary VCC from `PC_INC`.
- Later `PC_INC` will come from U25-6.

**Remove temporary wiring**
- `PC_INC=HIGH` test jumper.
- `/LD=HIGH` test jumper.

---

## Stage 3: Full Program Counter

**Chips added**: U3, U4.

**Total logic chips now**: 6 packages placed.

**Build**
- U3-U4 74HC161.
- U3-2, U4-2 <- CLK.
- U3-1, U4-1 <- `/RST`.
- U3-10 <- U2-15.
- U4-10 <- U3-15.
- Temporarily tie:
  - U3-7, U4-7 <- VCC.
  - U3-9, U4-9 <- VCC.
- LEDs on at least PC0-PC7. If possible also PC8-PC15.

**Test**
- Reset.
- Step enough clocks to prove carry moves upward.

**Pass**
- PC counts upward without stuck bits.
- Reset always returns PC to `$0000`.

**Do not continue if**
- A bit is inverted or swapped.
- U2/U3/U4 never receive carry.

---

## Stage 4: Address Mux Low Byte

**Chips added**: U15, U16.

**Total logic chips now**: 8 packages placed.

**Build**
- U15-U16 74HC157.
- U15/U16 `SEL` temporarily switchable:
  - `/ADDR_MODE=1`: PC low.
  - `/ADDR_MODE=0`: IRL low test value from DIP switches.
- U15/U16 `/E` -> GND.
- LEDs on A0-A7.

**Test**
- With `/ADDR_MODE=1`, A0-A7 follow PC0-PC7.
- With `/ADDR_MODE=0`, A0-A7 follow DIP-switch IRL0-IRL7.

**Pass**
- All 8 address bits follow the selected source.

**Common mistakes**
- 74HC157 A/B inputs reversed.
- Output pins 4,7,9,12 confused with input pins.

---

## Stage 5: Address Mux High Byte

**Chips added**: U29, U30.

**Total logic chips now**: 10 packages placed.

**Build**
- U29-U30 74HC157.
- `SEL` tied to same temporary `/ADDR_MODE` as Stage 4.
- A input = temporary DP0-DP7 from DIP switches.
- B input = PC8-PC15.
- U30-12 is A15.
- LED on A15 at minimum. Better: LEDs on A8-A15.

**Test**
- `/ADDR_MODE=1`: A8-A15 follow PC high.
- `/ADDR_MODE=0`: A8-A15 follow DIP-switch DP.
- Set DP=$80: A15 should be HIGH.
- Set DP=$00: A15 should be LOW.

**Pass**
- High address mux selects PC or DP correctly.
- A15 is correct.

**Remove temporary wiring**
- Temporary `SEL` switch when real `/ADDR_MODE` is connected in Stage 9.
- Temporary DP DIP-switch wires when real DP outputs are connected in Stage 16.

---

## Stage 6: ROM Read

**Chips added**: ROM.

**Total packages now**: 10 logic + ROM.

**Build**
- ROM address A0-A14 <- ABUS A0-A14.
- ROM D0-D7 -> DBUS.
- ROM `/CE` <- A15.
- ROM `/OE` temporarily -> GND for this isolated fetch test.
- ROM `/WE` -> HIGH during CPU runtime. Connect the programmer write path only
  when the CPU is held reset in PROG isolation.

**Test ROM bytes**
```text
$0000 = $30
$0001 = $42
$0002 = $01
$0003 = $00
```

**Test**
- PC=$0000, A15=0: DBUS should be `$30`.
- PC=$0001: DBUS should be `$42`.
- Force A15=1: ROM output should be off.

**Pass**
- DBUS shows the programmed bytes.

**Before full CPU wiring**
- Remove the temporary ROM `/OE` to GND wire and connect ROM `/OE` to
  `WR_DIR` from U28-8.
- This is required so ROM turns off during STORE direction.

**Remove temporary wiring**
- ROM `/OE` to GND test wire before STORE testing.

---

## Stage 7: U7 Bus Bridge

**Chips added**: U7.

**Total logic chips now**: 11 + ROM.

**Build**
- U7 74HC245.
- Physical wiring:
  - U7 A side pins 2-9 -> IBUS.
  - U7 B side pins 18-11 -> DBUS.
- U7-1 DIR <- temporary switch for now.
- U7-19 `/OE` <- temporary switch for now.

**Test Read Direction**
- Set U7-1 DIR=0.
- Set U7-19 `/OE`=0.
- ROM drives DBUS.
- IBUS should equal ROM byte.

**Test Disabled**
- Set U7-19 `/OE`=1.
- IBUS should not be driven by U7.

**Pass**
- U7 passes DBUS to IBUS when enabled and DIR=0.
- U7 releases bus when `/OE`=1.

**Remove temporary wiring**
- U7-1 temporary DIR switch before connecting `WR_DIR`.
- U7-19 temporary `/OE` switch before connecting `BUF_OE_N`.

**Common mistakes**
- A/B sides swapped.
- DIR polarity misunderstood:
  - Real 74HC245 with A=IBUS and B=DBUS:
  - DIR=0 means B->A, DBUS->IBUS.
  - DIR=1 means A->B, IBUS->DBUS.

---

## Stage 8: Instruction Registers

**Chips added**: U5, U6.

**Total logic chips now**: 13 + ROM.

**Build**
- U5 74HC574 IR_HIGH.
- U6 74HC574 IR_LOW.
- U5/U6 D inputs <- IBUS.
- U5 CLK <- T0.
- U6 CLK <- T1.
- U5 `/OE` -> GND.
- U6 `/OE` -> GND. Use LEDs/probes on IRL outputs when testing operand latch.

**Test**
- ROM at `$0000=$30`, `$0001=$42`.
- Reset PC.
- Clock T0: U5 should latch `$30`.
- Clock T1: U6 should latch `$42`.

**Expected U5 outputs for `$30`**
```text
MUX_SEL=1
AC_WR=1
all others 0
```

**Pass**
- U5 holds control byte.
- U6 holds operand byte.
- PC advanced twice.

**Remove temporary wiring**
- Temporary LEDs/probes on IRL outputs after U34 is added.

---

## Stage 9: Basic Control for Fetch and Immediate

**Chips added**: U34, U25 gate 1-2, U26 gate 1-2, U24 gate 6.

**Total packages now**: U24/U25/U26 are added, but some gates remain unused.

**Build**
- U25-1 <- SRC, U25-2 <- STR, U25-3 -> ADDR_REQ.
- U25-4 <- T0, U25-5 <- T1, U25-6 -> PC_INC.
- U26 gate 2 makes `/ADDR_MODE`.
- U26 gate 1 makes `/IRL_OE`.
- U24 gate 6 makes `BUF_OE_N`.
- U34 74HC541 immediate buffer:
  - A inputs <- IRL0-IRL7.
  - Y outputs -> IBUS0-IBUS7.
  - `/OE1` and `/OE2` <- `/IRL_OE`.
- Connect:
  - PC_INC -> U1/U2/U3/U4 enable pins.
  - /ADDR_MODE -> U15/U16/U29/U30 SEL.
  - `/IRL_OE` -> U34-1 and U34-19.
  - `BUF_OE_N` -> U7-19.

**Test**
- During T0 and T1:
  - PC_INC=1.
  - U7-19 LOW.
  - U34-1/19 HIGH.
- During T2 immediate instruction:
  - PC_INC=0.
  - U7-19 HIGH.
  - U34-1/19 LOW.

**Pass**
- Fetch path and immediate path alternate correctly.

**Remove temporary wiring**
- Any remaining manual `PC_INC`, `/ADDR_MODE`, `/IRL_OE`, or `BUF_OE_N`
  controls. These are now generated by U24/U25/U26.

---

## Stage 10: ALU Core

**Chips added**: U10, U11, U12, U13, U19, U20.

**Total logic chips now**: about 21 + ROM.

**Build**
- U19/U20 choose XOR B input:
  - XOR_MODE=0: ALU_SUB copied to all B bits.
  - XOR_MODE=1: AC bits.
- U12/U13 XOR IBUS with selected B.
- U10/U11 add AC + XOR result + ALU_SUB.

**Isolated Tests**
- Set AC=$10, IBUS=$05, ALU_SUB=0, XOR_MODE=0:
  - sum should be `$15`.
- Set AC=$10, IBUS=$05, ALU_SUB=1, XOR_MODE=0:
  - subtract path should compute `$0B`.
- Set AC=$AA, IBUS=$0F, XOR_MODE=1:
  - XOR output should be `$A5`.

**Pass**
- Low nibble and high nibble both correct.
- Carry from U10 to U11 works.

---

## Stage 11: AC Mux and Accumulator

**Chips added**: U17, U18, U9.

**Total logic chips now**: about 24 + ROM.

**Build**
- U17/U18 select adder sum or XOR output.
- U9 latches mux output.
- U9 CLK will later be ACC_CLK. For isolated test use manual pulse.
- U9 `/OE` -> GND.

**Test LI-like Path**
- Put `$42` on IBUS.
- MUX_SEL=1.
- XOR_MODE=0.
- ALU_SUB=0.
- Pulse U9 CLK.
- AC should become `$42`.

**Test ADDI-like Path**
- AC=`$42`.
- IBUS=`$01`.
- MUX_SEL=0.
- Pulse U9 CLK.
- AC should become `$43`.

**Pass**
- AC changes only when clocked.
- Mux select works.

**Remove temporary wiring**
- Manual U9 clock pulse before connecting `ACC_CLK` in the integrated CPU.

---

## Stage 12: AC Output Buffer and Store Direction

**Chips added**: U14 if not already placed with IR_BUF.

**Build**
- U14 inputs <- AC0-AC7.
- U14 outputs -> IBUS.
- U14 `/OE1` and `/OE2` <- `/AC_BUF`.
- U7 DIR <- WR_DIR.
- ROM `/OE` <- WR_DIR.

**Test Store Contract**
- Force T2 store condition:
  - `/AC_BUF=0`.
  - WR_DIR=1.
  - `BUF_OE_N=0`.
- Check:
  - U14 drives IBUS.
  - U7-19 LOW.
  - U7-1 HIGH.
  - DBUS equals AC.
  - ROM `/OE` HIGH.

**Pass**
- Store drives AC to DBUS.
- ROM is off during store direction.

**Do not continue if**
- U7-19 is HIGH during store.
- ROM `/OE` stays LOW during store.

---

## Stage 13: Z Flag

**Chips added**: U21, U22.

**Total logic chips now**: about 26 + ROM.

**Build**
- U22 compares AC with zero.
- U22-19 `/P=Q` -> U21-4 `/PR1`.
- U21-3 CLK <- ACC_CLK.
- U21-2 D1 -> GND.
- U21-1 `/CLR1` -> VCC.
- U21-5 -> Z_flag LED.
- U21 FF2 unused:
  - U21-8 `/Q2` NC.
  - U21-9 Q2 NC.
  - U21-10 `/PR2` VCC.
  - U21-11 CLK2 GND.
  - U21-12 D2 GND.
  - U21-13 `/CLR2` VCC.

**Test**
- Load AC=`$01`: Z LED off.
- Load AC=`$00`: Z LED on.
- Repeat `$01`, `$00` to prove it toggles.

**Pass**
- Z follows whether AC is zero after AC updates.

---

## Stage 14: Branch and Jump Control

**Chips added**: U27, U28 gates, remaining U24 gates.

**Build**
- U28 gate 1: Z_match = Z_flag XOR ALU_SUB.
- U24 gate 4: `/JMP`.
- U27 gate 1: `/BR_TAKEN`.
- U27 gate 2: PC_LOAD_COND.
- U26 gate 4: `/PC_LD`.
- Connect `/PC_LD` to U1-U4 pin 9.

**Test J**
- Set JMP=1.
- During T2, `/PC_LD` should go LOW.

**Test BEQ**
- BR=1, ALU_SUB=0.
- Z=1: `/PC_LD` LOW.
- Z=0: `/PC_LD` HIGH.

**Test BNE**
- BR=1, ALU_SUB=1.
- Z=0: `/PC_LD` LOW.
- Z=1: `/PC_LD` HIGH.

**Pass**
- Jump/branch never loads PC outside T2.

**Remove temporary wiring**
- Any manual `/PC_LD`, `JMP`, `BR`, `ALU_SUB`, or `Z` test forcing wires
  before running ROM tests.

---

## Stage 15: Page Register

**Chips added**: U23.

**Build**
- U23 D inputs <- IBUS.
- U23 Q outputs -> U3/U4 D inputs.
- U27 gate 3 makes `/PG_cond`.
- U28 gate 2 makes `/T2`.
- U25 gate 4 makes PG_CLK.
- U23 CLK <- PG_CLK.
- U23 `/OE` -> GND.

**Test**
- Execute or force SETPG `$90`.
- PG LEDs should show `$90`.
- Execute J `$00`.
- PC should load `$9000`.

**Pass**
- Page register holds high byte for jump target.

**Remove temporary wiring**
- Any forced `PG_CLK` or IBUS test pattern wires before full boot testing.

---

## Stage 16: RAM and Data Page

**Chips added**: RAM, U32, U33.

**Total packages now**: 34 logic + ROM + RAM if all previous stages are present.

**Build**
- RAM:
  - A0-A14 <- ABUS.
  - D0-D7 <-> DBUS.
  - `/CE` <- `/A15` from U24-6.
  - `/OE` -> GND.
  - `/WE` <- `/AC_BUF`.
- U32 Data Page:
  - D inputs <- IBUS.
  - Q outputs -> U29/U30 A inputs.
  - CLK <- DP_Load from U33-6.
  - `/OE` -> GND.
- U33 gate 1:
  - T2, XOR_MODE, `/ADDR_MODE`, `/AC_WR` -> DP_Load.

**Test SETDP**
- SETDP `$80`: DP LEDs show `$80`.
- SETDP `$90`: DP LEDs show `$90`.

**Test RAM**
- SETDP `$80`.
- LI `$AA`.
- SB `$10`.
- LB `$10`.
- AC should be `$AA`.

**Test ROM Read via DP**
- SETDP `$00`.
- LB `$00`.
- AC should equal ROM byte at `$0000`.

**Pass**
- RAM read/write works.
- ROM read through data access works.
- SB to ROM page does not corrupt ROM and does not cause DBUS fight because ROM
  `/WE` is inactive during normal CPU runtime.

**Remove temporary wiring**
- Any forced `DP_Load`, DP DIP input, RAM `/WE`, or RAM `/OE` test controls
  that bypass the official control signals.

---

## Stage 17: EI and IRQ Polling Latch

**Chips added**: U31, U33 gate 2.

**Build**
- U33 gate 2 makes EI_decode:
  - U33-9 <- T2.
  - U33-10 <- SRC.
  - U33-12 <- `/XOR_MODE`.
  - U33-13 <- `/AC_WR`.
  - U33-8 -> U31-3.
- U31 FF1 IE:
  - U31-1 `/CLR1` <- `/RST`.
  - U31-2 D1 -> VCC.
  - U31-3 CLK1 <- EI_decode.
  - U31-4 `/PR1` -> VCC.
  - U31-5 Q1 -> IE LED.
- U31 FF2 IRQ_FF:
  - U31-8 `/Q2` -> NC.
  - U31-9 Q2 -> IRQ_FF LED.
  - U31-10 `/PR2` -> VCC.
  - U31-11 CLK2 <- `/IRQ`.
  - U31-12 D2 -> VCC.
  - U31-13 `/CLR2` <- `/RST`.

**Test**
- Reset: IE LED off, IRQ_FF LED off.
- Execute EI `$08`: IE LED on.
- Execute DI `$48`: IE LED unchanged.
- Pull `/IRQ` low, then release it HIGH: IRQ_FF LED on.
- Continue clocking: PC does not jump automatically.
- Reset: both LEDs off.

**Pass**
- IRQ is a sticky polling latch.
- No hardware vector behavior exists.

**Do not add**
- No PC force path.
- No `$FF00` vector mux.
- No IRQ acknowledge/clear circuit.

---

## Stage 18: RV8-Bus Connector

**Chips added**: connector only.

**Build**
- A0-A15 to bus pins 1-16.
- D0-D7 to bus pins 17-24.
- CLK to pin 25.
- `/RST` to pin 26.
- `/WR` = `/AC_BUF` to pin 27.
- `/RD` informational to pin 28.
- `/IRQ` from bus pin 29 to U31-11.
- T2 to pin 32.
- VCC pin 39, GND pin 40.

**Test**
- Clock appears on bus pin 25.
- Reset appears on pin 26.
- STORE produces LOW pulse on pin 27.
- Pull `/IRQ` low then release: IRQ_FF LED latches.

**Pass**
- Bus does not disturb CPU operation.

**Do not add**
- No expansion card may drive DBUS unless it is selected and the CPU is in a
  read phase.

---

## Stage 19: Full Boot Test

**Test ROM**
```asm
SETDP $80
SETPG $00
LI $00
J $06
```

**Expected**
- After 3 clocks: DP=`$80`.
- After 6 clocks: PG=`$00`.
- After 9 clocks: AC=`$00`, Z=1.
- After 12 clocks: PC loops at `$0006`.

**Pass**
- CPU boots without programmer intervention.
- PC, DP, PG, AC, and Z are defined.

---

## Stage 20: Full Instruction Smoke Test

Use a ROM that tests:
- LI
- ADDI
- SUBI
- BEQ
- J
- SETDP
- SETPG
- SB
- LB

**Pass condition**
- Program reaches the pass loop, not the fail loop.
- Suggested pass loop: PC=`$0010`.
- Suggested fail loop: PC=`$0012`.

---

## Physical Signoff

Use this only after every stage above has passed on the real hardware:

- VCC is 4.8V to 5.2V at the farthest chips while running.
- Record voltage evidence at 4.5V, 5.0V, and 5.5V if the supply and parts allow
  the sweep safely.
- Reset always returns PC to `$0000` and clears U8 to `000`; the first active
  clock after reset release establishes T0.
- Single-step clock advances exactly one state per press.
- No chip is hot and no bus-fight current spike is observed.
- Golden Bring-up passes at 1 MHz.
- Full Instruction Smoke Test reaches the pass loop.
- Record the 50 kHz and 1 MHz checks plus the 100-tick push-switch test. Record
  2 MHz separately only as optional breadboard stress. Record 5 MHz only as an
  optional PCB/short-wire experiment; neither is a breadboard signoff gate.
- Record bus ownership, rising/falling edge behavior, and propagation-delay
  findings in `doc/07_real_build_timing_log.md`.
- One-hour burn-in stays in the pass loop.
- Clock sweep result is recorded for this exact build.

Do not mark physical build complete from Python, Verilog, or Components virtual
checker results alone.

---

## Minimum Continue Checklist

Before moving to the next stage, write down:

```text
Stage:
Date:
Clock mode:
VCC measured:
Observed LEDs:
Temporary wires removed:
Pass/fail:
If failed, fixed what:
```

If a later stage fails, return to the last passed stage and retest it first.

---

## Quick Fault Map

| Symptom | Likely area |
|---|---|
| T0/T1/T2 skip | Clock debounce or U8/U24 feedback |
| PC does not count | PC_INC, `/RST`, CLK, 74HC161 cascade |
| ROM byte wrong | Address bit swap, ROM `/CE`, ROM image |
| U5/U6 latch wrong | U7 direction, T0/T1, IBUS wiring |
| LI works but ADDI fails | ALU path U10-U13/U17-U20 |
| ADDI works but BEQ fails | Z flag or branch logic |
| J jumps to wrong page | U23 PG wiring to U3/U4 |
| SB/LB fails | U7 store/read direction, RAM `/WE`, DP value |
| STORE causes hot chip | ROM `/OE` not tied to WR_DIR, DBUS fight |
| IRQ LED never lights after release | `/IRQ` not reaching U31-11, missing pull-up/rising edge, U31 pinout wrong |
| CPU jumps on IRQ | You accidentally built future vector logic; remove it for v1.0 |

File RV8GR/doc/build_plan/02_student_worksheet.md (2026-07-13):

# RV8-GR Student Build Worksheet

Use this beside `01_student_incremental_build_plan.md`.

The technical build plan tells the teacher exactly which pins to wire. This
worksheet tells the student what to do, what to see, and when to stop.

After all stage cards pass on the real board, the teacher records voltage,
frequency, edge, bus, and delay evidence in `../07_real_build_timing_log.md`.

Rules for every stage:
- Build only this stage.
- Add VCC, GND, and 100nF bypass capacitor before signal wires.
- Use the slow clock or push-button clock.
- Test before adding the next stage.
- If the result is wrong, stop and fix it first.

Student record:

```text
Name:
Board:
Date started:
Clock mode:
Power supply voltage:
```

---

## How To Use One Stage Card

For each stage:

```text
Goal: What this part should do.
Build: What to place and wire.
Look at: LEDs or probe points.
Expected: What you should see.
Pass: Tick only when it works.
Stop if: Do not continue until fixed.
Notes: What you changed or learned.
```

Teacher rule: do not let students continue with a guessed pass.

---

## Stage 0: Power, Clock, Reset

Goal: Make safe power, one clean clock pulse, and a reset signal.

Build:
- 5V and GND rails.
- Reset button or reset circuit.
- Slow clock button.
- LED on `CLK`.
- LED or probe on `/RST`.

Look at:
- VCC at far end of board.
- `CLK`.
- `/RST`.

Expected:
- VCC is 4.8V to 5.2V.
- One clock press gives one clock pulse.
- Reset goes LOW while pressed, then HIGH again.

Pass:
- [ ] VCC good.
- [ ] CLK clean.
- [ ] `/RST` clean.
- [ ] No chip or wire gets hot.

Stop if:
- CLK bounces.
- Reset floats.
- Power is below 4.8V.

Notes:

```text

```

---

## Stage 1: Ring Counter

Goal: Make the three CPU steps: `T0`, `T1`, `T2`.

Build:
- U8.
- U24 gates 1 and 2.
- LEDs on `T0`, `T1`, `T2`.

Look at:
- `T0 = U8-3`
- `T1 = U8-4`
- `T2 = U8-5`

Expected:

```text
Reset asserted: T0=0 T1=0 T2=0
Clock 1 after reset release: T0=1 T1=0 T2=0
Clock 2: T0=0 T1=1 T2=0
Clock 3: T0=0 T1=0 T2=1
Clock 4: T0=1 T1=0 T2=0
```

Pass:
- [ ] T0/T1/T2 rotate in order.
- [ ] No skipped state.
- [ ] Reset clears all three phase LEDs; the first active clock after reset
      release enters T0.

Stop if:
- Two LEDs are ON at the same time.
- All LEDs are OFF after clocking.
- The pattern skips.

Notes:

```text

```

---

## Stage 2: Program Counter Low Byte

Goal: Count from `$00` upward on PC low byte.

Build:
- U1 and U2.
- Temporary `PC_INC=HIGH`.
- Temporary `/LD=HIGH`.
- LEDs on PC0-PC7.

Look at:
- PC0-PC7 LEDs.

Expected:

```text
Reset: $00
Clock 1: $01
Clock 2: $02
...
Clock 15: $0F
Clock 16: $10
```

Pass:
- [ ] U1 counts 0 to 15.
- [ ] U2 changes when U1 rolls over.
- [ ] Reset returns to `$00`.

Stop if:
- Any bit is stuck.
- Count goes backward.
- Reset does not clear.

Before next stage:
- [ ] Remove temporary `PC_INC=HIGH` only when the teacher says.

Notes:

```text

```

---

## Stage 3: Full Program Counter

Goal: Make the full 16-bit PC count.

Build:
- U3 and U4.
- Carry chain from U2 to U3 to U4.
- LEDs on PC0-PC7, and PC8-PC15 if possible.

Look at:
- Low byte changes often.
- High byte changes only after carry.

Expected:
- Reset gives PC=`$0000`.
- PC counts upward.
- Carry reaches higher chips.

Pass:
- [ ] PC low byte counts.
- [ ] Carry reaches high byte.
- [ ] Reset gives `$0000`.

Stop if:
- U3 or U4 never changes.
- Bits are swapped.
- Reset only clears some chips.

Notes:

```text

```

---

## Stage 4: Address Mux Low Byte

Goal: Select address low byte from PC or test operand.

Build:
- U15 and U16.
- Temporary `SEL` switch.
- DIP switch for fake `IRL0..IRL7`.
- LEDs on `ABUS0..ABUS7`.

Look at:
- `ABUS0..ABUS7`.

Expected:
- `/ADDR_MODE=1`: ABUS follows PC low byte.
- `/ADDR_MODE=0`: ABUS follows DIP switch.

Pass:
- [ ] /ADDR_MODE=1 works.
- [ ] /ADDR_MODE=0 works.
- [ ] All 8 bits match.

Stop if:
- Output is inverted.
- A/B inputs are reversed.
- Any bit is swapped.

Notes:

```text

```

---

## Stage 5: Address Mux High Byte

Goal: Select address high byte from PC high or test data page.

Build:
- U29 and U30.
- Same temporary `SEL`.
- DIP switch for fake `DP0..DP7`.
- LED on `ABUS15`.

Look at:
- `ABUS8..ABUS15`.
- Especially `ABUS15`.

Expected:
- `/ADDR_MODE=1`: high address follows PC high.
- `/ADDR_MODE=0`, DP=`$80`: `ABUS15=1`.
- `/ADDR_MODE=0`, DP=`$00`: `ABUS15=0`.

Pass:
- [ ] High mux selects correctly.
- [ ] A15 is correct.

Stop if:
- A15 is reversed.
- DP bits are in the wrong order.

Notes:

```text

```

---

## Stage 6: ROM Read

Goal: Read known bytes from ROM onto `DBUS`.

Build:
- ROM.
- ROM address pins from `ABUS0..ABUS14`.
- ROM data pins to `DBUS0..DBUS7`.
- Temporary ROM `/OE=LOW` for this isolated test.

ROM bytes:

```text
$0000 = $30
$0001 = $42
$0002 = $01
$0003 = $00
```

Look at:
- `DBUS0..DBUS7`.

Expected:
- PC=`$0000`: DBUS=`$30`.
- PC=`$0001`: DBUS=`$42`.
- Force A15=1: ROM output off.

Pass:
- [ ] ROM byte `$30` appears.
- [ ] ROM byte `$42` appears.
- [ ] ROM turns off when not selected.

Stop if:
- DBUS is always `$00` or `$FF`.
- ROM gets hot.
- Address bits are swapped.

Before full CPU wiring:
- [ ] Remove temporary ROM `/OE=LOW`.
- [ ] Connect ROM `/OE` to `WR_DIR` before any store/RAM test.

Notes:

```text

```

---

## Stage 7: U7 Bus Bridge

Goal: Move bytes between `DBUS` and `IBUS`.

Build:
- U7.
- U7 A side to `IBUS`.
- U7 B side to `DBUS`.
- Temporary switches for DIR and `/OE`.

Look at:
- `DBUS`.
- `IBUS`.
- U7-1 DIR.
- U7-19 `/OE`.

Expected:
- DIR=0 and `/OE=0`: ROM byte on DBUS appears on IBUS.
- `/OE=1`: U7 stops driving IBUS.

Pass:
- [ ] DBUS to IBUS works.
- [ ] U7 disables correctly.

Stop if:
- A/B sides are swapped.
- DIR meaning is backwards.
- IBUS is driven when `/OE=1`.

Remember:

```text
Real wiring: A=IBUS, B=DBUS.
DIR=0 means B->A = DBUS->IBUS.
DIR=1 means A->B = IBUS->DBUS.
```

Notes:

```text

```

---

## Stage 8: Instruction Registers

Goal: Latch instruction byte and operand byte.

Build:
- U5 `IR_HIGH`.
- U6 `IR_LOW`.
- U5/U6 D inputs from `IBUS`.
- U5 clock from `T0`.
- U6 clock from `T1`.

Look at:
- U5 outputs.
- U6 outputs.
- `T0`, `T1`.

Expected with ROM `$30 $42`:
- At T0, U5 latches `$30`.
- At T1, U6 latches `$42`.

Pass:
- [ ] U5 holds `$30`.
- [ ] U6 holds `$42`.
- [ ] PC advanced two bytes.

Stop if:
- U5 and U6 latch at the wrong time.
- U34 output fights IBUS during fetch.

Notes:

```text

```

---

## Stage 9A: Fetch Control Signals

Goal: Make PC count during fetch and U7 drive during fetch.

Build:
- U25 gate 2 for `PC_INC`.
- Connect `PC_INC` to U1-U4 enable pins.
- Keep slow clock.

Look at:
- `PC_INC`.
- `T0`, `T1`, `T2`.
- U7-19.

Expected:
- T0/T1: `PC_INC=1`.
- T2: `PC_INC=0`.
- T0/T1: U7 enabled.

Pass:
- [ ] PC counts only during T0/T1.
- [ ] Fetch still reads ROM.

Stop if:
- PC counts during T2.
- PC stops counting during fetch.

Notes:

```text

```

---

## Stage 9B: Immediate vs Memory Address

Goal: Select immediate operand or data address correctly.

Build:
- U25 gate 1 for `ADDR_REQ`.
- U26 gate 2 for `/ADDR_MODE`.
- U26 gate 1 for `/IRL_OE`.
- U24 gate 6 for `BUF_OE_N`.

Look at:
- `/ADDR_MODE`.
- `/IRL_OE`.
- `BUF_OE_N`.
- U34-1/19.
- U7-19.

Expected:
- Immediate instruction: U34 drives IBUS during T2.
- Load/store instruction: address mux uses `{DP, IRL}`.
- U34 and U7 do not drive IBUS at the same time.

Pass:
- [ ] Immediate path works.
- [ ] Address mode path works.
- [ ] No two IBUS drivers fight.

Stop if:
- U34 and U7 are both enabled in T2 immediate.
- IBUS flickers randomly.

Notes:

```text

```

---

## Stage 9C: Store Direction Safety

Goal: Make store direction safe before using RAM.

Build:
- U26 gate 3 for `/AC_BUF`.
- U28 gate C for `WR_DIR`.
- Connect `BUF_OE_N` to U7-19.
- Connect `WR_DIR` to U7-1 and ROM `/OE`.

Look at:
- `/AC_BUF`.
- `WR_DIR`.
- U7-19.
- U7-1.
- ROM `/OE`.

Expected during store:
- `/AC_BUF=0`.
- U7-19 LOW.
- U7-1 HIGH.
- ROM `/OE` HIGH.

Pass:
- [ ] U7 remains enabled during store.
- [ ] U7 direction is IBUS to DBUS.
- [ ] ROM output is off during store.

Stop if:
- ROM `/OE` stays LOW during store.
- U7-19 is HIGH during store.
- Any chip gets warm during store test.

Notes:

```text

```

---

## Stage 10: ALU Core

Goal: Build ADD, SUB, and XOR math.

Build:
- U10 and U11 adders.
- U12 and U13 XOR array.
- U19 and U20 XOR B-input mux.

Look at:
- Adder sum.
- XOR output.
- Carry from U10 to U11.

Expected:
- `$10 + $05 = $15`.
- `$10 - $05 = $0B`.
- `$AA XOR $0F = $A5`.

Pass:
- [ ] ADD works.
- [ ] SUB works.
- [ ] XOR works.
- [ ] Carry chain works.

Stop if:
- Low nibble correct but high nibble wrong.
- SUB is off by one.

Notes:

```text

```

---

## Stage 11A: AC Mux and Load Immediate

Goal: Load a value into AC.

Build:
- U17 and U18 AC input mux.
- U9 accumulator.
- Manual pulse for U9 CLK during isolated test.

Look at:
- `AC0..AC7`.
- `MUX_SEL`.

Expected:
- IBUS=`$42`, MUX_SEL=1, XOR_MODE=0, ALU_SUB=0.
- Pulse AC clock.
- AC becomes `$42`.

Pass:
- [ ] AC loads `$42`.
- [ ] AC holds value after clock stops.

Stop if:
- AC changes without clock.
- AC bits are reversed.

Notes:

```text

```

---

## Stage 11B: AC Add Path

Goal: Add through the ALU and store result in AC.

Build:
- Same chips as Stage 11A.
- Use ALU output through AC mux.

Look at:
- AC.
- Adder sum.

Expected:
- Start AC=`$42`.
- IBUS=`$01`.
- MUX_SEL=0.
- Pulse AC clock.
- AC becomes `$43`.

Pass:
- [ ] ADDI-like path works.

Stop if:
- Adder output is correct but AC is wrong.
- AC mux select is backwards.

Notes:

```text

```

---
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

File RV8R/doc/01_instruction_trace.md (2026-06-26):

# RV8-R — Legacy 19-Chip Instruction Trace

**Legacy trace for `ADDI r1, 5`. The current buildable full-ISA hardware target is FullHW in `02_wiring_guide.md`; this file is retained to explain why the old 19-chip idea was not enough.**

---

## RV8-R = RV8 minus hardware registers

RV8 has: 8× 574 (registers) + 2× 138 (decode) = 10 chips for register file.
RV8-R removes these. Registers live in high RAM at `$FFF8-$FFFF`.
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

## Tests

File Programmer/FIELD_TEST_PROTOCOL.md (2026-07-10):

# RV8 Programmer Field-Test Protocol

Updated: 2026-07-10

Purpose: prove the ESP32 Programmer can safely program and verify RV8GR ROM images
before it is used as part of the full physical CPU build.

This protocol is for real hardware. The Python mock tests prove the PC-side tools
and serial protocol logic, but they do not prove voltage levels, cable wiring,
bus release, EEPROM write timing, or physical ROM protection state.

## Safety Rules

1. Use only one target path at a time:
   - ZIF Direct: bus cable disconnected.
   - RV8-Bus in-system: ZIF socket empty.
2. Power off before changing between ZIF, bus cable, PROG, and RUN setups.
3. In RV8-Bus PROG mode, the CPU must be held in reset and the Programmer owns
   A[14:0], D[7:0], `/WR`, and `/RD`.
4. In RUN mode, the Programmer must release `/WR`, `/RD`, and D[7:0] so the CPU
   owns the bus.
5. During normal CPU runtime, ROM `/WE` must stay inactive. The Programmer write
   path may drive ROM `/WE` only while the board is intentionally in PROG mode
   with the CPU stopped or while a bare ROM is in the ZIF socket.
6. Current firmware uses normal byte-write cycles. Use AT28C256 parts with
   software data protection disabled, or add SDP unlock support before relying
   on protected parts.

## Virtual Preflight

Run from repo root before touching hardware:

```sh
python3 -B Programmer/tools/test_rv8flash.py
python3 -B Programmer/tools/test_rv8term.py
python3 -B Programmer/tools/test_rv8ram-boot.py
```

Expected result on 2026-07-10: 51 total mock tests pass.

| Test file | Expected count | Purpose |
|---|---:|---|
| `test_rv8flash.py` | 19 | Flash, read, verify, CLI, serial protocol, error handling |
| `test_rv8term.py` | 17 | Terminal CLI and UART bridge behavior |
| `test_rv8ram-boot.py` | 15 | RAM boot upload and command handling |

Also run the RV8GR software/RTL signoff when the ROM image changes:

```sh
python3 -B RV8GR/tools/test_rv8gr_asm.py
python3 -B RV8GR/sim/test_cpu_logical_protocol.py
```

## Test Image

Use a small known ROM image first, then the full ISA test ROM.

Record for each image:

| Field | Value |
|---|---|
| File path | |
| File size | |
| SHA-256 | |
| Assembler command or source | |
| Expected behavior on CPU | |

## Instrument Checklist

Minimum:

- 5 V rail measurement at Programmer and CPU board.
- 3.3 V rail measurement at ESP32/TXS side.
- Continuity check for RV8-Bus pins 1-30, 39, and 40.
- Logic probe or logic analyzer on `/RST`, `/WR`, `/RD`, A0, D0, and D7.

Preferred:

- Oscilloscope capture of `/WR`, `/RD`, and one data bit during write/read.
- Current-limited bench supply for first power-up.

## Mode A: ZIF Direct Test

Use this when programming a bare AT28C256-compatible ROM in the Programmer ZIF.

1. Power off.
2. Disconnect RV8-Bus cable.
3. Insert ROM into ZIF socket, pin 1 correctly oriented, then lock ZIF.
4. Power on Programmer.
5. Confirm PC can see the serial device:

   ```sh
   python3 Programmer/tools/rv8flash.py -pl
   python3 Programmer/tools/rv8flash.py -c
   ```

6. Program the image:

   ```sh
   python3 Programmer/tools/rv8flash.py -w program.bin
   ```

7. Verify the image:

   ```sh
   python3 Programmer/tools/rv8flash.py -v program.bin
   ```

8. Read back to a new file and compare hashes:

   ```sh
   python3 Programmer/tools/rv8flash.py -r readback.bin -f
   sha256sum program.bin readback.bin
   ```

Pass condition: connection succeeds, write completes, verify passes, and readback
hash matches the input image.

## Mode B: RV8-Bus In-System Test

Use this only after the CPU ROM module is wired and checked.

1. Power off.
2. Remove any ROM from the Programmer ZIF socket.
3. Connect RV8-Bus cable to the CPU board.
4. Set switch to PROG.
5. Power on.
6. Confirm `/RST` is LOW at the CPU board before write/verify.
7. Confirm Programmer owns `/WR` and `/RD` only in PROG mode.
8. Run:

   ```sh
   python3 Programmer/tools/rv8flash.py -c
   python3 Programmer/tools/rv8flash.py -w program.bin
   python3 Programmer/tools/rv8flash.py -v program.bin
   ```

9. Power off or switch to RUN according to the board procedure.
10. Confirm `/WR`, `/RD`, and D[7:0] are released by the Programmer in RUN mode.
11. Reset the CPU and observe the expected ROM behavior.

Pass condition: the same program/verify result as ZIF Direct, plus no bus
contention signs when switching to RUN mode.

## Evidence Log

Create one log entry per field test:

| Field | Value |
|---|---|
| Date/time | |
| Operator | |
| Board revision / wiring photo link | |
| Mode | ZIF Direct / RV8-Bus |
| ROM part number | |
| ROM SDP state | disabled / unlock-supported / unknown |
| Supply voltage at board | |
| Serial port | |
| Command transcript | |
| SHA-256 input/readback | |
| Logic capture file/photo | |
| Result | PASS / FAIL |
| Failure notes / fix | |

## Failure Triage

| Symptom | First checks |
|---|---|
| No serial port | USB cable, ESP32 power, driver, `-pl` output |
| Programmer not responding | PROG/RUN switch, ESP32 boot delay, baud 115200 |
| Write timeout | ROM inserted/oriented, `/WE` path, 5 V rail, TXS OE |
| Verify mismatch | Protected AT28C256, write delay, address/data pin swap, weak cable |
| CPU fails after verified ROM | Wrong ROM image, CPU reset/run mode, ROM `/OE`, address wiring |
| Bus fight or heating | ZIF and bus both connected, RUN mode not releasing D bus, CPU not reset in PROG |

## B-012 Exit Criteria

B-012 can move from READY FOR FIELD TEST to DONE only after:

1. All 51 mock tests pass in this repo.
2. ZIF Direct field test passes with readback hash evidence.
3. RV8-Bus in-system field test passes or is explicitly deferred until the ROM
   module exists.
4. The evidence log is committed or linked from the project docs.

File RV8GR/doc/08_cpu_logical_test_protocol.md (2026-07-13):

# RV8GR CPU Logical Test Protocol

RV8GR owns CPU logical correctness: what the processor does after reset, how
instructions execute, how programs halt or pass, and whether assembler output
matches CPU behavior.

Components owns reusable chip definitions and virtual physical checks: pin
truth, bus-contention risk, edge polarity, propagation delay, R/C noise, and
package evidence.

Both are required, but they answer different questions.

For a shorter student-facing explanation of the two Python sims, two Verilog
models, and the shared all-ISA test, see `doc/11_four_model_equivalence.md`.

## Relationship To Other Test Docs

Keep this document separate. It is the maintainer protocol for virtual CPU
logic signoff, not a student lab sheet and not a physical evidence log.

| Document | Purpose |
|---|---|
| `08_cpu_logical_test_protocol.md` | Canonical CPU logic regression lanes, coverage, commands, and signoff boundary. |
| `11_four_model_equivalence.md` | Short student explanation of why two Python sims and two Verilog models must agree. |
| `05_debug_plan.md` | Physical build procedure students follow on the bench. |
| `07_real_build_timing_log.md` | Real-board voltage/frequency, timing, bus-race, edge, propagation-delay, fix, and retest evidence. |

Merging these would hide the main distinction: RV8GR owns CPU behavior, while
Components and the physical build own pin truth, bus contention, edge polarity,
delay/noise assumptions, and measured hardware evidence.

## External Practices Adapted

This protocol borrows proven verification ideas and makes them small enough for
RV8GR:

- RISC-V architectural tests use self-checking assembly tests for a Device Under
  Test, but still warn that certification tests are not complete verification:
  https://github.com/riscv/riscv-arch-test
- RISCV-DV combines directed assembly, random instruction streams, coverage, and
  co-simulation against instruction-set simulators:
  https://github.com/chipsalliance/riscv-dv
- cocotb shows the value of Python-driven virtual testbenches, direct stimulus,
  monitors, and regression reporting:
  https://docs.cocotb.org/en/stable/
- UVM standard practice separates stimulus, monitor, scoreboard, and reusable
  verification components:
  https://www.accellera.org/downloads/standards/uvm

RV8GR does not need full UVM or RISC-V tooling. It needs the same discipline:
self-checking programs, a reference model, repeatable regression commands, and
clear pass/fail signals.

## Test Lanes

| Lane | Owner | Purpose | Tool |
|---|---|---|---|
| Assembler encoding | RV8GR | Prove source maps to frozen opcodes and bad source fails loudly | `tools/test_rv8gr_asm.py` |
| CPU reference behavior | RV8GR | Prove ISA, branches, memory map, and halt behavior in fast Python | `sim/chip_sim.py` |
| Components-backed CPU behavior | RV8GR + Components | Prove the same CPU tests run while using Components chip definitions | `sim/components_chip_sim.py` |
| RTL behavioral comparison | RV8GR | Compare optimized/behavioral HDL against CPU expectations | `tools/run_all_verilog_tb.sh` behavioral benches |
| TTL-chip HDL system | RV8GR + Components | Prove chip-level Verilog netlist runs using Components TTL models | `tools/run_chip_level_*.sh` |
| Behavioral vs chip-level HDL scoreboard | RV8GR + Components | Prove both Verilog levels agree at architectural checkpoints on the same ROM image | `tools/run_dual_verilog_compare.sh` |
| Python vs Verilog equivalence | RV8GR + Components | Prove both Python CPU sims and both Verilog CPU models agree on the same all-ISA ROM source | `tools/check_python_verilog_equivalence.py` |
| Virtual physical screen | Components | Check pin truth, bus contention, edge polarity, and delay/noise assumptions | `chiplib.cli circuit-faults` |
| Physical signoff | RV8GR physical build | Prove the real breadboard works | Lab/debug plan evidence |

## Required Logical Coverage

### Boot Contract

Every virtual CPU test must begin from the v1.0 boot contract:

- PC starts at `$0000`.
- While reset is asserted, U8 is cleared to `000`; the first active clock after
  reset release establishes T0 and begins the first opcode fetch.
- IRQ latch and IE are clear after reset.
- PG, DP, AC, and Z are treated as unknown on real hardware, even if a simulator
  initializes them for convenience.
- Test ROMs must initialize architectural state before relying on it:
  `SETDP $80`, `SETPG $00`, then a known AC/Z setup such as `LI $00`.

The all-ISA equivalence fixture is an exception because it is a simulator
scoreboard fixture, not a physical boot ROM. `tb_rv8gr_dual_compare.v` forces
the same reset-visible state into both Verilog models before release, and the
Python checker starts from the simulator reset contract. Physical ROMs and
student programs must still initialize state explicitly.

### Assembler

Run:

```bash
cd RV8GR
python3 -B tools/test_rv8gr_asm.py
```

Must cover:

- All frozen opcode encodings.
- Aliases/macros: `MV`, `HLT`, `CLR`, `INC`, `DEC`, `NOT`, `SLL`, `JMP`.
- `NOT` is assembler-only and must emit `XORI $FF`; it is not a new frozen ISA opcode.
- `.org`, `.db`, labels, `hi()` and `lo()`.
- Page-safe branch and jump validation.
- Output bounds and overlap errors.
- Unsupported macro rejection.

### ISA And Program Behavior

Run:

```bash
cd RV8GR
python3 -B sim/chip_sim.py
python3 -B sim/components_chip_sim.py
python3 -B sim/test_cpu_logical_protocol.py
python3 -B sim/test_basic_min.py
```

Minimum pass cases:

- `LI`, `ADDI`, `SUBI`, `XORI`.
- `NOT` pseudo-instruction truth table, assembled through `XORI $FF`, for
  boundary values `$00`, `$01`, `$55`, `$7F`, `$80`, `$AA`, `$F0`, `$0F`, `$FF`.
- Z flag set/clear from ALU results.
- `SB` and `LB` through RAM page `$80`.
- `SETDP` reads RAM page `$90` and ROM page `$00`.
- `SETPG` plus `J` reaches another ROM page.
- `BEQ` taken when Z=1.
- Halt loop is detected as `J self`.
- The same directed programs must pass on both `CPUSim` and
  `ComponentsCPUSim`.

### Full Program Tests

Assembly programs should be self-checking: failures halt early, success reaches
a known pass loop.

Required virtual programs:

- `programs/test_isa.asm`: instruction-level ISA smoke.
- `programs/test_all.asm`: broader assembler-to-CPU behavior.
- `programs/testrom.asm`: physical/virtual golden ROM.
- `programs/test_setdp.asm`: data-page and RAM-page behavior.
- `programs/test_not.asm`: assembler pseudo-instruction ROM test for `NOT`
  (`XORI $FF`) across boundary bit patterns.
- `programs/basic_min.asm`: B-011 phase 1 BASIC-style ROM runtime smoke.

The pass condition is not "simulation ended." The pass condition is reaching
the documented pass loop with expected AC/Z/PG/PC state.

For `tb/tb_rv8gr_asm.v`, do not accept `=== ASSEMBLER TEST PASSED ===` alone.
The bench must also show that `programs/testrom.hex` was found and reaches:

```text
Halted at PC=$0084 after 187 cycles
AC=$00 Z=1 PG=$00
=== ASSEMBLER TEST PASSED ===
```

A `$readmemh` missing-file warning invalidates that run even if the bench later
prints a pass banner.

### Dual Verilog Comparison

Run:

```bash
cd RV8GR
tools/run_dual_verilog_compare.sh
python3 -B tools/check_python_verilog_equivalence.py
```

This bench runs both Verilog versions together:

- `rtl/rv8gr_cpu.v` is the behavioral/logical CPU model.
- `rtl/rv8gr_chip_level.v` is the KiCad/Components TTL-chip netlist.
- `programs/all_isa_equivalence.asm` is the single shared source for the
  all-ISA equivalence program. The Verilog runner assembles it to a temporary
  `.memh`; the Python checker assembles the same source in memory.

The behavioral model records architectural checkpoints. The chip-level model
must later reach the same checkpoints with matching `PC`, `AC`, `Z`, `PG`, `DP`,
`IE`, `IRQ_FF`, and selected RAM bytes.

The dual comparison program must cover every frozen ISA command at least once:

| Group | Commands |
|---|---|
| Baseline/control | `NOP`, `EI`, `DI` |
| Jump/branch | `J`, `BEQ`, `BNE` |
| ALU immediate | `LI`, `ADDI`, `SUBI`, `XORI` |
| ALU memory/register | `ADD`, `SUB`, `XOR`, `LB`, `SB` |
| Page/data control | `SETPG`, `SETPG_R`, `SETDP` |
| IRQ protocol | `/IRQ` release/rising edge sets `IRQ_FF`; no automatic PC vector |

A pass means the two Verilog levels agree on the tested program-level CPU
behavior. It is not a formal proof that every internal wire or delay matches
cycle-by-cycle.

The Python equivalence checker then verifies:

- `tb_rv8gr_dual_compare.v` exports the Verilog architectural checkpoints as
  `VERILOG_CHECKPOINT` lines.
- `sim/chip_sim.py` matches the exported Verilog checkpoint stream.
- `sim/components_chip_sim.py` matches the exported Verilog checkpoint stream
  while using Components `chiplib` adapters for chip objects. It is not an
  independent net-level Python CPU algorithm.
- Both Python sims also match the final Verilog architectural state and the RAM
  checkpoints used by the Verilog dual comparison.

### IRQ Logical Behavior

RV8GR v1.0 has polling IRQ only.

Required checks:

- `EI` sets IE.
- `DI` is inert in the 36-package baseline.
- `/IRQ` release/rising edge latches IRQ_FF.
- IRQ never vectors the PC automatically.
- PC is not automatically saved to RAM.

### Memory Map

Required checks:

- ROM `$0000-$7FFF` fetches and data reads work.
- RAM `$8000-$FFFF` load/store works.
- `DP=$00-$7F` reads ROM.
- `DP=$80-$FF` reads/writes RAM.
- I/O slot addresses in `$FF10-$FF2F` are logical memory-map addresses; devices
  are external and must be tested separately.

## Regression Command

Run this before saying RV8GR virtual CPU logic is current. These commands are
the current non-physical CPU verification route; their PASS output is not
physical-board evidence:

```bash
cd /home/jo/kiro/RV8/RV8GR
python3 -B tools/test_rv8gr_asm.py
python3 -B sim/chip_sim.py
python3 -B sim/components_chip_sim.py
python3 -B sim/test_cpu_logical_protocol.py
python3 -B sim/test_basic_min.py
python3 -B tools/check_python_verilog_equivalence.py
python3 -B sim/verify_wiring.py
python3 -B sim/verify_components.py
tools/run_all_verilog_tb.sh
```

Run this from the external Components checkout for the separate virtual
physical screen. It is a model-level screen, not a substitute for the measured
1 MHz breadboard baseline recorded in `07_real_build_timing_log.md`:

```bash
cd /home/jo/kiro/Components
PYTHONPATH=python python3 -B -m chiplib.cli circuit-faults examples/circuits/RV8GR_WholeSystemChipLevelVirtual/circuit.json
```

## Scoreboard Rule

Every test must have an expected architectural result:

- PC expected value or pass-loop address.
- AC expected value.
- Z expected value.
- PG and DP expected values when used.
- RAM bytes expected after stores.
- IRQ/IE expected latch state when tested.

Tests that only print text without asserting expected state are not signoff
tests.

## Future Test Expansion

Add these after the current deterministic suite stays green:

1. Program-level runner that loads `.bin` files and checks pass-loop labels from
   `.lst` files.
2. Directed instruction matrix: every opcode with representative operands,
   including boundary values `$00`, `$01`, `$7F`, `$80`, `$FE`, `$FF`.
3. Small deterministic random program generator with a Python reference model.
4. Coverage report by instruction, branch taken/not-taken, memory page, and
   halt/pass outcome.
5. Boot-loader/programmer logical tests: ROM image loads, reset starts at
   `$0000`, and programmed bytes match assembled bytes.

## Signoff Boundary

Virtual CPU logic signoff means RV8GR behaves correctly in software and HDL.
It does not mean the breadboard is physically signed off.

Physical signoff still requires measured power, reset, clock, bus ownership,
ROM/RAM behavior, burn-in, and timing evidence from the real build.

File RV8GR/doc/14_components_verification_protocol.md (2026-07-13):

# RV8GR Components Verification Protocol

Date: 2026-07-10

Purpose: one Components-side reference for RV8GR chip readiness, split-record
testing, virtual bench mapping, circuit gates, system proof, and physical
build signoff.

This file replaces the older separate RV8GR DB notes for chip-level planning,
multi-level protocol, virtual bench mapping, Batch 2 audit, and the status
report. The machine-readable companions remain:

- `RV8GR/doc/rv8gr_chip_level_readiness.json`
- `RV8GR/doc/rv8gr_virtual_bench_plan.json`
- `lib/standard/VIRTUAL_TEST_GENERATOR_CONTRACT.json`
- `examples/circuits/RV8GR_COVERAGE_INDEX.json`
- `examples/circuits/RV8GR_END_TO_END_TEST_PLAN.md`

## Current Status

| Level | Status | Evidence |
|---|---|---|
| Source/definition gate | PASS | `tests.test_db` passed |
| Chip-level behavior gate | PASS | `tests.test_generated_split_records` passed |
| Circuit-level package gate | PASS | `tests.test_lib_circuits` passed |
| Block UI/tooling gate | PASS | `tests.test_block_ui` passed |
| RV8GR whole-system Verilog gate | Recorded virtual checkpoint | Run `RV8GR/tools/run_all_verilog_tb.sh` from this checkout for current evidence; the Components end-to-end plan is a separate external artifact |
| Physical hardware signoff | BLOCKED | voltage/frequency/scope evidence still missing |

| Item | Count | Status |
|---|---:|---|
| RV8GR required chips | 18 | all listed in `RV8GR/doc/rv8gr_chip_level_readiness.json` |
| Chip split-record sets | 18 | all have truth/timing/tri-state/bus-fight/propagation records |
| RV8GR circuit packages | 22 | all indexed in `examples/circuits/RV8GR_COVERAGE_INDEX.json` |
| Indexed packages marked `Tested` | 22 | README/index/package/test checks pass |

## Required Chip Set

The machine-readable status lives in `RV8GR/doc/rv8gr_chip_level_readiness.json` and
is enforced by `tests.test_generated_split_records`.

| Part | RV8GR role | Current chip-level gate |
|---|---|---|
| `74HC00` | NAND gates for control decode and glue logic | Ready for circuit functional tests |
| `74HC04` | Inverters for active-low control and reset/clock glue | Ready for circuit functional tests |
| `74HC21` | Dual 4-input AND gates for decode and control qualification | Ready for circuit functional tests |
| `74HC32` | OR gates for control composition | Ready for circuit functional tests |
| `74HC74` | Positive-edge D flip-flops for flags, IRQ latch, and synchronous state | Ready for circuit functional tests |
| `74HC86` | XOR gates for ALU and compare/control paths | Ready for circuit functional tests |
| `74HC157` | Quad muxes for address and data path selection | Ready for circuit functional tests |
| `74HC161` | Positive-edge program counter and counter-style state | Ready for circuit functional tests |
| `74HC164` | Serial-in parallel-out ring/control sequencing support | Ready for circuit functional tests |
| `74HC245` | Bidirectional bus transceiver for shared bus isolation | Ready for circuit functional tests |
| `74HC283` | 4-bit binary adders for the ALU | Ready for circuit functional tests |
| `74HC541` | Octal buffers for unidirectional bus and visible outputs | Ready for circuit functional tests |
| `74HC574` | Positive-edge octal registers for IR, AC, page, and data-path latches | Ready for circuit functional tests |
| `74HC688` | 8-bit equality comparator for branch/page/control decisions | Ready for circuit functional tests |
| `62256` | Generic 32K x 8 SRAM-compatible RAM footprint | Ready for circuit functional tests when Samsung KM62256C-compatible SRAM is installed |
| `AS6C62256` | Alliance 32K x 8 SRAM option for RAM | Ready for circuit functional tests |
| `AT28C256` | 32K x 8 EEPROM option for program ROM | Ready for circuit functional tests |
| `SST39SF010A` | Flash ROM option for program storage | Ready for circuit functional tests |

Each part has a layered package with `definition/definition.json`, local
simulation files, symbol metadata, generated artifacts, and split test records
for truth table, timing, tri-state, bus-fight, and propagation coverage.

## Level 0: Source And Definition Gate

Required evidence for every real chip:

- local or stable manufacturer datasheet reference
- package and pinout
- active-low names and bus directions
- behavior equation or truth table
- timing/electrical rows when present in the datasheet
- explicit missing-property status when any row is not available

Pass command:

```sh
PYTHONPATH=python python3 -B -m tests.test_db
```

Virtual instruments: `InputSource`, `Probe`, `OutputAssert`.

## Level 1: Chip-Level Behavior Gate

Required split records for every RV8GR chip:

- `truth_table.json`
- `timing.json`
- `tri_state.json`
- `bus_fight.json`
- `propagation.json`

Pass command:

```sh
PYTHONPATH=python python3 -B -m tests.test_generated_split_records
```

Pass condition: all 18 RV8GR chips have all split records, every truth-table
record declares `edge_criteria`, and generated record tests pass. This is a
functional/model gate, not physical timing signoff.

Every clocked chip must identify its trigger edge and no-edge hold behavior.
Level-sensitive chips use `trigger_edge: none`. Memory chips must declare their
write/read control window and high-Z cases.

## Level 2: Circuit-Level Gate

Each `examples/circuits/RV8GR_*` package must include:

- `circuit.json`
- `README.md`
- at least one `tests/*.json` proof file
- package entry in `examples/circuits/RV8GR_COVERAGE_INDEX.json`
- executable coverage in `python/tests/test_lib_circuits.py`

Pass command:

```sh
PYTHONPATH=python python3 -B -m tests.test_lib_circuits
```

Pass condition: all indexed circuit packages are tested, all proof vectors
execute, bus conflicts are caught, and physical timing claims remain blocked
unless bench evidence exists.

## Level 3: System-Level Gate

Components-side pass commands, run from `/home/jo/kiro/Components`:

```sh
PYTHONPATH=python python3 -B -m tests.test_lib_circuits
PYTHONPATH=python python3 -B -m tests.test_db
PYTHONPATH=python python3 -B -m tests.test_generated_split_records
```

RV8GR-side whole-system command:

```sh
/home/jo/kiro/RV8/RV8GR/tools/run_all_verilog_tb.sh
```

Required RV8GR pass markers:

- `=== ASSEMBLER TEST PASSED ===`
- `=== ALL TESTS PASSED ===`
- `ALL IRQ POLLING TESTS PASSED`
- `=== OPCODE SWEEP PASSED: 512 cases`
- `=== SETDP TEST PASSED ===`
- `ALL TASK TESTS PASSED`
- `RV8GR chip-level bring-up PASS`
- `RV8GR chip-level full PASS`

Pass condition: Components proofs and RV8GR benches agree on instruction
behavior, bus ownership, reset/boot behavior, page/data behavior, and IRQ v1.0
boundaries. This is non-physical evidence only. The physical gate remains
blocked until the real board records the 1 MHz baseline and required measured
power, edge, bus-deadband, memory, and timing evidence.

## Virtual Bench Mapping

Chip-level virtual bench generation is defined by
`lib/standard/VIRTUAL_TEST_GENERATOR_CONTRACT.json`; generated RV8GR coverage lives in
`RV8GR/doc/rv8gr_virtual_bench_plan.json`.

Summary:

- RV8GR chips: 18
- Split records per chip: 5
- Total chip/record mappings: 90
- OutputAssert mappings: 90
- DelayNoise propagation-stress mappings: 18
- Required instruments all declared: true

| Split record | Virtual instruments | Generated checks |
|---|---|---|
| `truth_table` | `InputSource`, `Probe`, `OutputAssert` | drive each input vector; sample every named output; assert expected logic value |
| `timing` | `ClockSource`, `Switch`, `Probe`, `OutputAssert` | apply required clock profile; sample after declared delay; assert setup/hold or no-edge behavior |
| `tri_state` | `InputSource`, `BusProbe`, `OutputAssert` | enable output; disable output; assert high-Z when disabled |
| `bus_fight` | `BusProbe`, `OutputAssert` | force safe single-driver vector; force conflict vector; assert conflict is reported |
| `propagation` | `ClockSource`, `Probe`, `RCParasitic`, `DelayNoise`, `OutputAssert` | apply source transition; inject optional delay/noise; sample destination after timing budget; assert output still meets expectation |

Virtual benches prove model behavior and stress selected assumptions. They are
not physical signoff.

## Virtual Physical-System Fault Gate

Every chip-level, circuit-level, and whole-system virtual test must include
traps for common AI-generated hardware mistakes that can look plausible in text
but fail on a real breadboard.

| Fault class | Required virtual test | Fix method |
|---|---|---|
| Wrong physical pin number or pin name | Compare every circuit pin reference against DB pin number, pin name, direction, active-low marker, and local pinout evidence before simulation starts. | Fix the chip definition or source-backed pin map first; do not move circuit wires to hide a bad definition. |
| Output-to-output wiring with no valid bus condition | Allow direct output-to-input wiring. Allow multiple outputs only on a named bus when enable conditions prove at most one driver at a time; force a conflict vector with `BusProbe`. | Add tri-state control, buffer/transceiver direction, or output-enable sequencing so the old driver is high-Z before the new driver turns on. |
| Wrong positive/negative or rising/falling edge | For every edge-triggered part, prove the declared trigger edge captures and the opposite edge holds; reset/load priority must be explicit. | Move the signal to the correct clock phase or add an intentional inverter. Keep expected behavior tied to the datasheet edge. |
| Propagation delay or R/C delay creates bus overlap or early sampling | Use `RCParasitic` and `DelayNoise` on `CLK`, `/RST`, `IBUS`, `DBUS`, `/OE`, and `/WE`; assert positive disable-to-enable deadband and destination setup/hold margin. | Add phase separation, delay the new enable, disable the old driver earlier, shorten or buffer the net, or lower the clock until measured margin is positive. |

Pass condition: a virtual physical-system test must fail loudly for wrong pin
truth, meaningless output-output wiring, bad edge polarity, and negative delay
deadband. The report must name the fix method instead of changing the expected
result to match the bug.

## Physical Build Signoff Gate

Required physical voltage points:

- 4.5 V
- 5.0 V
- 5.5 V

Required clock profiles:

- 100 manual push-switch ticks
- 50 kHz
- 1 MHz

Optional profiles, recorded separately and never used as breadboard signoff
gates:

- 2 MHz breadboard stress
- 5 MHz PCB-only experiment

Required physical evidence:

- installed EEPROM and SRAM markings
- selected datasheet timing rows
- VCC at power entry and far IC
- clock/reset edge quality
- memory output-float deadband
- bus turn-off before turn-on deadband
- representative driver-pin and destination-pin scope captures
- breadboard R/C calibration for `CLK`, `/RST`, `IBUS`, `DBUS`, and memory
  control nets

Pass condition: the real build passes the 1 MHz breadboard baseline and its
required measurements without bus fights, bad edge triggers, timing-window
failures, or supply/edge-quality violations. Record 5 MHz separately only as
an optional PCB-only experiment.

Do not write "hardware ready" unless Level 4 passes.

## Report Rule

Every RV8GR report must separate:

- passed virtual/model evidence
- passed whole-system simulation evidence
- blocked physical evidence
- next required physical capture

## Commands

```sh
PYTHONPATH=python python3 -B -m tests.test_db
PYTHONPATH=python python3 -B -m tests.test_generated_split_records
PYTHONPATH=python python3 -B -m tests.test_lib_circuits
PYTHONPATH=python python3 -B -m tests.test_block_ui
```

Last recorded results:

- `Components DB tests passed`
- `Components generated split-record tests passed`
- `Components library circuit tests passed`
- `Components block UI tests passed`

## Next Target

Extend the same complete-set gate from the RV8GR-used chips to the rest of the
migrated IC catalog, while keeping physical hardware signoff separate from
virtual/model readiness.

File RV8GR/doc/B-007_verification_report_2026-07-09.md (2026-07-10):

# RV8GR Backlog B-007 Verification Report

Date: 2026-07-09
Workspace: `/home/jo/kiro/RV8`
Branch observed: `team-setup...origin/team-setup`
Scope: RV8GR verification/report/status only. Components were not edited.

> Historical report, not current signoff.
>
> Keep this file as the dated B-007 non-physical evidence record. For current
> CPU logical signoff, use `08_cpu_logical_test_protocol.md` and
> `11_four_model_equivalence.md`. For current physical timing/build evidence,
> use `05_debug_plan.md` and `07_real_build_timing_log.md`. For the current
> doc-by-doc source-of-truth review, use `12_doc_integrity_audit.md`.

## Summary

Status: PASS for all available non-physical RV8GR verification in this
environment.

Physical hardware status: BLOCKED. No assembled RV8GR hardware, ROM programmer
session, logic analyzer, oscilloscope, or live 1 MHz board run was available from
this environment, so no physical pass is claimed.

## Commands And Results

### Workspace discovery

Command:

```bash
git status --short --branch
```

Result:

```text
## team-setup...origin/team-setup
```

Command:

```bash
find RV8GR -maxdepth 3 -type f -name 'verify_docs.py' -o -name '*verify*.py' -o -name 'run_*.sh' | sort
```

Result:

```text
RV8GR/sim/verify_wiring.py
RV8GR/tools/run_all_verilog_tb.sh
RV8GR/tools/run_chip_level_full_verilog.sh
RV8GR/tools/run_chip_level_verilog.sh
```

Note: no `RV8GR/tools/verify_docs.py` exists in this checkout.

### Python simulator and tooling

Command:

```bash
cd /home/jo/kiro/RV8/RV8GR
python3 -B sim/chip_sim.py
```

Result: PASS. Reported `ALL 8 CPU TESTS PASSED`; worst critical path margin at
5 MHz was 97 ns and max safe clock was 9.7 MHz.

Command:

```bash
cd /home/jo/kiro/RV8/RV8GR
python3 -B sim/verify_wiring.py
```

Result: PASS. Reported `ALL WIRING VERIFIED` after LI, LI+ADDI, SB+LB,
SETDP+SB, and BEQ wiring checks.

Command:

```bash
cd /home/jo/kiro/RV8/RV8GR
python3 -B sim/soft_debug.py
```

Result: PASS. Reported `ALL SOFT DEBUG TESTS PASSED`.

Command:

```bash
cd /home/jo/kiro/RV8/RV8GR
python3 -B tools/test_rv8gr_asm.py
```

Result: PASS. Python unittest reported `Ran 11 tests` and `OK`.

Command:

```bash
cd /home/jo/kiro/RV8/RV8GR/sim
python3 -B chips/test_chips.py
```

Result: PASS. Reported `ALL 14 CHIP TYPES VERIFIED`.

### Simulation labs

Initial command:

```bash
cd /home/jo/kiro/RV8/RV8GR/sim
for f in sim_lab/lab*.py; do echo "=== $f ==="; python3 -B "$f"; done
```

Result: PARTIAL due to invocation/import path, not lab logic. Labs 01, 10, 12,
and 14 passed, while labs importing `chips` failed with:

```text
ModuleNotFoundError: No module named 'chips'
```

Corrected command:

```bash
cd /home/jo/kiro/RV8/RV8GR/sim
PYTHONPATH=. python3 -B sim_lab/lab01_power_clock.py && \
PYTHONPATH=. python3 -B sim_lab/lab02_ring_counter.py && \
PYTHONPATH=. python3 -B sim_lab/lab03_pc_counter.py && \
PYTHONPATH=. python3 -B sim_lab/lab04_address_mux.py && \
PYTHONPATH=. python3 -B sim_lab/lab05_rom_fetch.py && \
PYTHONPATH=. python3 -B sim_lab/lab06_ir_latch.py && \
PYTHONPATH=. python3 -B sim_lab/lab07_alu.py && \
PYTHONPATH=. python3 -B sim_lab/lab08_ac_mux.py && \
PYTHONPATH=. python3 -B sim_lab/lab09_z_flag.py && \
PYTHONPATH=. python3 -B sim_lab/lab10_branch_jump.py && \
PYTHONPATH=. python3 -B sim_lab/lab11_page_register.py && \
PYTHONPATH=. python3 -B sim_lab/lab12_ram_datapage.py && \
PYTHONPATH=. python3 -B sim_lab/lab13_full_system.py && \
PYTHONPATH=. python3 -B sim_lab/lab14_irq_bus.py
```

Result: PASS. Labs 01 through 14 all reported PASS.

### Verilog and chip-level HDL stack

Command:

```bash
cd /home/jo/kiro/RV8/RV8GR
tools/run_all_verilog_tb.sh
```

Result: PASS. Individual evidence:

```text
tb_rv8gr_asm: === ASSEMBLER TEST PASSED ===
tb_rv8gr_full: === ALL TESTS PASSED === (127 cycles)
tb_rv8gr_irq: ALL IRQ POLLING TESTS PASSED
tb_rv8gr_opcode_sweep: === OPCODE SWEEP PASSED: 512 cases (256 opcodes x Z=0/1) ===
tb_rv8gr_setdp: === SETDP TEST PASSED === (160 cycles)
tb_rv8gr_tasks: ALL TASK TESTS PASSED
tb_rv8gr_chip_level: RV8GR chip-level bring-up PASS
tb_rv8gr_chip_full: RV8GR chip-level full PASS
```

Icarus emitted repeated warnings that `rv8gr_cpu` has no explicit time unit or
precision. These warnings did not fail the benches.

## Physical Run Checklist

This original checklist explains why B-007 stayed physically blocked on
2026-07-09. Do not use it as the latest physical protocol. The current physical
protocol also requires voltage sweep, frequency sweep, bus-race checks,
edge-polarity checks, propagation-delay notes, and real evidence logging in
`07_real_build_timing_log.md`.

| Step | Required evidence | Pass/Fail | Notes |
|---|---|---|---|
| Confirm assembled RV8GR board revision | Board photo or revision note matching current 36-package v1.0 docs | | |
| Power rails | Scope/DMM evidence for +5 V, GND continuity, no overcurrent | | |
| Clock/reset | Scope capture for reset release and 1 MHz clock | | |
| Ring counter | T0/T1/T2 probe capture showing one-hot sequence | | |
| ROM image | Exact `.asm`, `.bin`, and ROM programmer verify transcript | | |
| Fetch cycle | Probe/logic capture for PC $0000 -> $0001 -> $0002 and IR high/low latch | | |
| Full ISA smoke | Test ROM pass condition observed at LEDs/probe points | | |
| RAM page access | SB/LB or SETDP test evidence for RAM page $80 and one non-default page | | |
| Branch/page jump | Evidence for BEQ/J/SETPG expected PC behavior | | |
| IRQ polling | Evidence that IRQ latch is poll-visible and does not vector PC automatically | | |
| Clock margin | Repeat official target at 1 MHz; optional 2 MHz stress run | | |

## Blockers

- Physical RV8GR run is blocked by unavailable hardware access from this
  environment.
- No local `RV8GR/tools/verify_docs.py` exists, so the older doc-static checker
  mentioned in prior RV8GR memory could not be run here.
- There are unrelated untracked files under `RV8GR/programs/` before this report:
  `README.md`, `blink.asm`, `counter.asm`, and `echo.asm`. They were not touched.

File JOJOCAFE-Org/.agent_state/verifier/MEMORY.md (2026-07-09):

# Verifier Memory

## Test Coverage

| Layer | Status | Command |
|---|---|---|
| Verilog full ISA | ✅ 127 cycles | `iverilog ... tb_rv8gr_full.v && vvp` |
| Verilog IRQ | ✅ pass | `tb_rv8gr_irq.v` |
| Verilog SETDP | ✅ 160 cycles | `tb_rv8gr_setdp.v` |
| Verilog opcode sweep | ✅ 512 cases | `tb_rv8gr_opcode_sweep.v` |
| Verilog chip-level | ✅ pass | `tools/run_all_verilog_tb.sh` includes chip-level bring-up and full benches |
| Gate-level sim | ✅ 8/8 | `python3 sim/chip_sim.py` |
| Soft debug | ✅ 4/4 | `python3 sim/soft_debug.py` |
| Assembler | ✅ | `python3 tools/rv8gr_asm.py` |
| Physical hardware | ⬜ not yet built | — |
| Components 74HC smoke | ✅ pass | `iverilog -g2012 -Wall -o /tmp/tb_74hc_smoke.vvp Components/74HC/*.v Components/74HC/tests/tb_74hc_smoke.v && vvp /tmp/tb_74hc_smoke.vvp` |
| Components Memory smoke | ✅ pass | `iverilog -g2012 -Wall -o /tmp/tb_memory_smoke.vvp Components/Memory/*.v Components/Memory/tests/tb_memory_smoke.v && vvp /tmp/tb_memory_smoke.vvp` |
| Components Python chip tests | ✅ pass | `cd Components/python && python3 -B -m tests.test_chips` |

## Known Hazards (all resolved in design)

1. SRC+STR bus fight → guarded by BUF_OE_SAFE
2. WR_DIR timing → gated with T2+STORE
3. Z-flag async preset → safe at ≤5MHz
4. IRQ during jump → deferred to next instruction

## Defect Log

(Empty — no defects currently open)

## Review Checklist (use for every coder submission)

- [ ] Does it compile/assemble without errors?
- [ ] Does existing test suite still pass?
- [ ] Are new tests written for the change?
- [ ] Traced signal/code path end-to-end?
- [ ] No new SRC+STR conflicts?
- [ ] Both sim layers agree?

## Component Library Verification

- Shared repo: `/home/jo/kiro/Components`, remote `git@github.com:JOJOCAFE/Components.git`.
- Verify all local `*-pin.md` PDF references resolve under `Components/source`.
- Verify any breadboard pinout has manufacturer DIP/PDIP package evidence.
- Verify `source/` has no duplicate temporary datasheets or `Zone.Identifier` files.
- Current blocked pinout placeholders are expected: `74HC/74hc150-pin.md`, `74HC/74hc260-pin.md`.
- Verify Python/Verilog compatibility when chip behavior changes: controls, output polarity, tri-state, async controls, memory semantics, and rising/falling edge behavior.
- SST39SF010A Python/Verilog simplified write-trigger behavior is aligned on falling `/WE` while selected with `/OE` high.
- Components schematic backend/probe/test-logic foundations exist; next verification should focus on JSON/block/Python round-trip and RV8GR netlist export compatibility.

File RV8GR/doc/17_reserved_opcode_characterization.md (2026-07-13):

# RV8GR Reserved / Non-ISA Opcode Characterization

`tools/characterize_reserved_opcodes.py` is the executable record for the
horizontal control bytes not allocated to the v1.0 ISA.  It does **not** call
them NOPs and does not turn their deterministic implementation behavior into
an architectural promise.

For each non-ISA control byte and each selected operand it:

1. initializes a defined CPU state with `DP=$80`, `AC=$A5`, `PG=$3C`, and a
   known RAM byte at the actual data address `$80<operand>`;
2. loads the actual two-byte program at ROM `$0000`;
3. advances through T0 fetch, T1 operand fetch, and T2 execute;
4. records PC, AC, Z, PG, DP, IE, IRQ, and the RAM target before/after;
5. compares CPUSim with the Components-backed chip adapter; and
6. writes a replayable `.bin` image and JSONL record below `/tmp`.

Run the full current corpus:

```bash
python3 tools/characterize_reserved_opcodes.py
```

The shell exit status fails on a CPUSim/ComponentsCPUSim disagreement.  This
is adapter compatibility evidence only: the two paths share the CPUSim
execution semantics, so it is not independent ISA or physical-hardware proof.
The separate RTL phase-trace and dual-RTL benches remain required evidence.

The default operands `$00` and `$5A` deliberately exercise both a neutral and
a data-page RAM-addressable operand.  The generated `summary.json` reports
the exact corpus counts, including store-dominant `SRC+STR` control bytes.

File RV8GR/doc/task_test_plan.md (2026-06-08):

# RV8-GR — Test Plan (Stable)

**Milestones from reset to full system. Matches Verilog testbenches.**

---

## Task 1: Reset

| Test | Expected |
|---|---|
| PC starts at $8000 | ✅ |
| Page Register = $80 | ✅ |
| AC = $00, Z = 1 | ✅ |
| Ring counter at T0 | ✅ |

---

## Task 2: Fetch Cycle (T0/T1/T2)
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

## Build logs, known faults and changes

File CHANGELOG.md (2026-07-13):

# RV8 Project — Changelog

## 2026-07-12 — v4.5: RV8GR Release Gate and External Components Checkpoint

### Release Gate
- Updated behavioral Verilog benches and `sim/verify_wiring.py` so detected
  mismatches exit nonzero and can block aggregate automation.

### Reset and Physical Contract
- Standardized the reset sequence: U8 is `000` while `/RST` is LOW; the first
  active clock after reset release establishes T0 and starts opcode fetch.
- Defined physical signoff clocks as 100 manual ticks, 50 kHz, and 1 MHz.
  Kept 2 MHz as optional breadboard stress and 5 MHz as an optional PCB-only
  experiment.

### Components Verification
- Re-ran RV8GR against the current external Components checkout.
- Passed the 16 part-type, 36-package audit and the RV8GR whole-system virtual
  fault screen with zero pin-truth, edge-polarity, output-contention, and
  propagation-deadband findings.
- Preserved the physical boundary: virtual results do not sign off the board.

## 2026-07-10 — v4.4: RV8GR Lab/Doc Verification and Components Mapping

### RV8GR Student Build Docs
- Rechecked the RV8GR lab sequence, build-plan docs, KiCad module guide, and
  sim-lab scripts against the current pin-level wiring source.
- Preserved the frozen student baseline: **34 logic chips + ROM + RAM = 36
  packages**, no microcode, fixed T0/T1/T2 execution, and one active bus driver
  per phase.
- Confirmed `U34` is the 74HC541 IRL-to-IBUS immediate buffer; memory parts
  remain named `ROM1` and `RAM1`.

### Components Mapping
- Cross-checked the board-to-library count boundary:
  - 36 physical RV8GR board packages
  - 16 board-used part types
  - 18 RV8GR-ready Components definitions/options when ROM/RAM alternatives
    are included
- Verified that every board-used part type has the current Components package
  layers: `definition/definition.json`, local Python and Verilog models,
  simulation/netlist JSON, DIP symbol, generated artifacts, and
  truth/timing/tri-state/bus-fight/propagation split records.

### Verification
- Components-side gates passed for DB definitions, generated split records,
  circuit packages, Python chip behavior, DB audit, and DB status.
- RV8GR lab scripts were previously re-run after the lab/doc repairs and pass
  against the current simulator behavior.

### Physical Boundary
- Physical hardware speed/signoff remains blocked until real voltage sweep,
  clock/reset edge captures, bus deadband, memory output-float/write timing,
  and scope evidence are recorded on the actual build.

## 2026-07-09 — v4.3: RV8GR Canonical Rename and Chip-Level Source

### RV8GR
- Renamed the active student baseline folder from `RV8GR-V2/` to `RV8GR/`
- Updated top-level routing docs so `RV8GR/` is the canonical 34-logic-chip, 36-package student build
- Removed the obsolete `RV8GR-V1/` reference snapshot so `RV8GR/` is the only RV8GR checkout folder

### Chip-Level Verification
- Updated chip-level Verilog, testbench, KiCad, and netlist filenames to use the canonical `rv8gr` / `RV8GR` name
- Preserved Verilog/netlist compatibility as the secondary HDL comparison path for the Python-first simulator workflow

## 2026-06-26 — v4.2: RV8-R FullHW Real Hardware Path

### RV8-R FullHW
- Promoted RV8-R from the old 19-chip reduced sketch to a **FullHW** full-ISA hardware path
- Documented **49 logic chips + 2 microcode ROM + 1 program ROM + 1 RAM = 53 packages**
- Replaced conceptual/blocker-only paths with concrete hardware routes for:
  - 16-bit PC reset, increment, load, same-page jump, IRQ vector, and IRET restore
  - full ALU `ADD`, `SUB`, `AND`, `OR`, `XOR`, `SLL`, plus `SLT`/`SLTI` through carry/borrow and `$00/$01` constant writeback
  - RAM register window at `$FFF8-$FFFF`
  - fast-page RAM access at `$FF00+imm8`
  - stack operations through `r7` as SP
  - `JAL`, `JALR`, IRQ entry, `EI`, `DI`, `HLT`, and `IRET`
- Switched RV8-R architecture docs to **15-bit microcode address** and **16-bit direct-control word**
- Marked the old 19-chip trace as legacy and retained it only as design history

### Project Status
- Top-level README now presents RV8-R FullHW as the real full RV8-style TTL path, not the fewest-chip option
- RV8GR remains the active student-friendly physical build target
- Existing RV8-R microcode generator is explicitly marked as legacy 14-bit prototype; FullHW needs a new 15-bit direct-control generator

### Verification
- Documentation consistency scan completed for stale zero-page, 19-chip, and old blocked-path claims
- RTL, KiCad/ERC, and FullHW microcode generator migration remain pending

## 2026-06-26 — v4.1: Programmer Dual-Mode RV8GR Compatibility

### Programmer
- **Programmer/firmware/firmware.ino**: RUN mode now releases both `/WR` and `/RD`; PROG mode reclaims `/WR` before ROM write cycles
- **Programmer/tools/rv8term.py**: Normal terminal mode now starts directly in RUN mode without sending the PROG-only `?` handshake; `-c` remains the explicit connection check
- **Programmer/tools/rv8flash.py**: Added RV8GR documented command aliases: `program FILE --base 0x0000` and `verify FILE --base 0x0000`; nonzero `--base` fails loudly
- **Programmer/tools/test_rv8flash.py** and **test_rv8term.py**: Added regression coverage for RV8GR CLI aliases and PROG/RUN handshake boundary
- **Programmer/README.md**, **schematic.md**, and requirement docs: Documented ZIF-direct vs RV8-Bus in-system use, never-both safety rule, and AT28C256 SDP limitation

### RV8GR Integration
- **RV8GR/doc/02_wiring_guide.md**: Clarified that ROM `/WE` connects to RV8-Bus `/WR` pin 27 for Programmer support, and that current firmware does normal byte writes unless SDP unlock is added
- **RV8GR/doc/labs/lab05_rom_buffer.md**: Separated early standalone ROM `/WE -> 5V` lab wiring from final Programmer/RV8-Bus `/WE -> /WR` wiring
- **RV8GR/doc/labs/lab13_full_system.md**, **lab14_irq_bus.md**, and **doc/06_debug_plan.md**: Updated Programmer command examples to the actual `Programmer/tools/rv8flash.py` path and RV8GR-compatible command form

### KiCad Exports
- Regenerated `Programmer/KICAD/RV8Programmer.pdf`
- Regenerated `Programmer/KICAD/RV8Programmer.svg` and `Programmer/KICAD/RV8Programmer/RV8Programmer.svg` with KiCad 10.0.4

### Verification
- `python3 -m unittest discover -s Programmer/tools -p 'test_*.py'` — 36 tests pass
- `python3 RV8GR/sim/verify_wiring.py` — all wiring verified
- `python3 RV8GR/tools/test_rv8gr_asm.py` — 11 tests pass
- Cleaned Python caches and Zone.Identifier artifacts after validation

## 2026-06-26 — v4.0: RV8GR Student Build Guardrails

### Documentation
- **RV8GR/README.md**: Added Student Baseline Contract and recommended reading order for student, teacher, debug, wiring, and KiCad paths
- **RV8GR/doc/build_plan/01_student_incremental_build_plan.md**: Added baseline contract, explicit temporary-wire removal checks, "do not add" warnings for vector/IRQ upgrade wiring, and stage checklist field for temporary wires
- **RV8GR/doc/06_debug_plan.md**: Added Baseline Boundary and Probe Point Map for clock/reset, buses, control signals, PC, PG, DP, IRQ, and latch debug
- **RV8GR/doc/labs/README.md**: Added Thai baseline rules for students
- **RV8GR/doc/04_bank_switch.md**: Marked ROM banking as future-only, not part of the student baseline
- **Top-level README.md**: Updated project routing to make RV8GR the active 34-logic-chip student baseline

### Cleanup
- **RV8GR/.gitignore**: Added rules for `*.pyc` and `*:Zone.Identifier*`
- Removed generated VCD/VVP traces, Python caches, and Windows Zone.Identifier metadata from RV8GR

### Verification
- `python3 RV8GR/tools/test_rv8gr_asm.py` — 11 tests pass
- `python3 RV8GR/sim/chip_sim.py` — 8 CPU tests pass
- `python3 RV8GR/sim/verify_wiring.py` — all wiring verified
- Icarus Verilog benches pass: full, IRQ polling, SETDP, tasks, assembler ROM, opcode sweep
- Opcode sweep: 512 cases pass

## 2026-06-21 — v3.9: KiCad Module Definitions

### Documentation
- **doc/10_kicad_modules.md**: Split 36-package CPU into 6 hierarchical KiCad sheets
  - CLK_RST (U8), PC (U1-U4), ADDR_MEM (U15/U16/U29/U30+ROM+RAM), IR_BUF (U5-U7,U14), ALU_AC (U9-U13,U17-U22), CTRL (U23-U28,U31-U33)
  - Full sheet port tables, pin-level wiring, inter-module signal names
  - Aligned with debug plan (14 steps) and hardware labs (14 labs)
  - Build/test order matches existing bring-up sequence

### Verification
- All 34 logic chips plus ROM/RAM accounted for (no duplicates, no gaps)
- Cross-referenced with 02_wiring_guide.md (source of truth) — all pin assignments match
- Module boundaries consistent with 05_understand_by_module.md groupings

## 2026-06-19 — v3.8: Opcode Sweep, Page-Safe Assembler, Skills

### Verification
- **tb_rv8gr_opcode_sweep.v**: New exhaustive testbench — tests all 256 opcodes × Z={0,1} = 512 cases against horizontal control equations
- All 5 testbenches pass: full (127 cycles), IRQ, SETDP (160 cycles), tasks, opcode sweep (512 cases)
- chip_sim.py 8/8, soft_debug.py 4/4 — no regressions

### Assembler (tools/rv8gr_asm.py)
- Cross-page validation: J/BEQ/BNE error if target is on different page than PC
- Overlap detection: error if two instructions write the same ROM address
- Duplicate label detection
- `memh` output format for Verilog `$readmemh`
- `AssemblerError` exception class for clean error handling

### Documentation
- **doc/11_future_upgrades.md**: Documents potential v1.1/v2.0 improvements extracted from Codex evaluation (clock qualification, hardware DI, I/O decode, reset supervisor)
- Clock targets clarified: 1 MHz breadboard, 4 MHz PCB (no hardware changes needed)

### Skills (new)
- **debug-mantra**: 4-step hardware debugging discipline adapted from 9arm-skills (reproduce → trace → falsify → breadcrumbs), with RV8-specific hazard checklist and sim layers
- **scrutinize**: Outsider design review adapted from 9arm-skills, with chip:pin signal tracing, ISA encoding safety, 34-logic-chip budget awareness

### Cleanup
- Evaluated RV8GR-Codex (40-chip AI redesign): rejected as unauthorized/unnecessary at 1 MHz; extracted useful assembler safety and opcode sweep TB
- Evaluated 7 external GitHub repos: only 9arm-skills had applicable content

## 2026-06-16 — v3.7: Documentation Freeze & Consistency Pass

### Architecture Documentation (ALL FROZEN 🔒)
- **00_design_isa.md**: Added Architectural Invariants (7 rules), Hardware Freeze Policy (9 signals), Signal Naming Convention (suffix rules), Reset Contract, Forbidden Bus States, Instruction Trace Contract (13-field canonical format), Illegal Opcode Behavior (18/174/64 split with examples). Legacy expansion-budget wording was superseded; the frozen v1.0 baseline is 34 logic chips + ROM + RAM = 36 packages.
- **02_wiring_guide.md**: Added Critical Timing Paths table (6 paths), Critical Nets Summary (12 key signals with source/dest pins), IRQ_FF clear wording fixed (v1.0 = /RST only)
- **03_instruction_trace.md**: Added Trace 10 (Forbidden Opcode $0C), Trace 11 (Boot Sequence 9-clock), Golden Trace (12-cycle regression reference), all signal clarifications
- **04_bank_switch.md**: Added v2.x Banking Contract (2-bit/128KB/74HC74), Banked Address Formula, Reserved I/O Table ($FF10), Compatibility Contract, Interrupt Safety Rule
- **06_debug_plan.md**: Added Step 0 (Boot Sanity Check), Bus Ownership Verification, Clock Integrity, Floating Input Audit, Memory Contention Test, Walking-1/RAM March, Ring Counter State Matrix, Clock Sweep, Power Integrity, Reset Recovery, Golden Bring-up Program (20-byte ROM image), Burn-in test, IRQ_FF sticky note
- **05_understand_by_module.md**: Added Block Diagram, Fetch→Fetch→Execute, ISA Table (18 instr), Clock-by-Clock Walkthrough, State Diagram, Two's Complement example, Registers in RAM, PG vs DP table, Memory Map with I/O, Chapter Book roadmap
- **07_risk_analysis.md**: Added Known Limitations (L1: $60 PG+DP conflict, L2: IRQ_FF sticky, L3: Hidden free instructions)
- **08_design_signoff.md**: Added Status Levels table (FROZEN/VERIFIED/PENDING), Remaining Proof checklist, IRQ v1.0 polling corrected
- **09_task_test_plan.md**: Verified consistent (no changes needed)

### Simulation
- **wiring.py**: Fixed missing U31 /RST connections (pin 1, pin 13) — IE and IRQ_FF now properly reset
- **sim_lab/lab14_irq_bus.py**: Labeled as v1.1 behavior (matching Verilog model)
- All sims pass: chip_sim ✅, verify_wiring ✅, soft_debug ✅, gate_sim ✅

### Hardware Labs (14 labs synced with debug plan)
- lab01: Added bypass cap warning, clock integrity, rail continuity, rising edge diagram, reset LED, troubleshooting
- lab02: Added state machine diagram, Q3-Q7 debug header, recovery wording fix, milestone summary
- lab04: Fixed 74HC157 description (Quad 2-to-1), Challenge A ADDR_MODE clarification
- lab05: Fixed ROM test data ($11→$30/$42), added Bus Ownership diagram, Hi-Z explanation, clock note
- lab06: Added Bus Ownership Verification table, Bus Float Test
- lab08: Fixed "AC=$00 (reset)" → "AC=unknown"
- lab09: Added async preset toggle test
- lab10: Added PC_LOAD Priority Test
- lab11: Added Long Jump Test ($FFFF, $AA55)
- lab12: Added ROM/RAM Boundary Test, Memory Contention Test
- lab14: Fixed IRQ from v1.1 auto-jump to v1.0 polling, added sticky latch test

### Status
- RV8-GR v1.0: **Architecture Complete, Implementation Validation Pending**
- All 9 documentation files frozen and internally consistent
- Ready for physical breadboard build

## 2026-06-14 — v3.6: Programmer Bus-Based Redesign

### Architecture Change
- **Bus-based**: Programmer connects via RV8-Bus (40-pin), not direct to ROM
- **No /CE /OE**: ROM chip-select handled by A15=0 on CPU board
- **/RD added**: GPIO 17 drives bus pin 28 (ROM /OE) for reads
- **Two scenarios**: A=bare ROM, B=full CPU board (hold /RST to free bus)

### Pin Mapping (final)
```
Data D[0:7]:  GPIO [13, 12, 14, 27, 26, 25, 33, 32] → Bus pin 17-24
SR_DATA:      GPIO 23 → 595 SER
SR_CLK:       GPIO 18 → 595 SRCLK
SR_LATCH:     GPIO 19 → 595 RCLK
/RST:         GPIO 4  → Bus pin 26
/WR:          GPIO 16 → Bus pin 27
/RD:          GPIO 17 → Bus pin 28 (output in PROG, input in RUN)
/SLOT1:       GPIO 34 ← Bus pin 30 (input, RUN mode)
/RD sense:    GPIO 35 ← Bus pin 28 (input, RUN mode)
/WR sense:    GPIO 36 ← Bus pin 27 (input, RUN mode)
MODE:         GPIO 39 ← Switch (LOW=PROG, HIGH=RUN)
```

### Firmware Protocol (final)
- `?` → `Connected\n` (new: connection check)
- `F` + len(2B) → `K\n` (ACK), receive data, → `D\n` (done)
- `V` → 32KB raw bytes (drives /RD for each read)
- `R` → pulse /RST, → `K\n`

### Python Tools
- rv8flash.py: fixed double-send bug, added boot delay, port+baud display
- rv8term.py: rewritten (follows rv8flash patterns), added `-c` check
- Both show `Port: /dev/ttyUSB0 @ 115200 baud` + `Programmer: Connected`

### Files Changed
- firmware/firmware.ino (rewritten, 276 lines)
- schematic.md (rewritten for bus-based design)
- README.md (scenarios, bus overview, updated pinout)
- tools/rv8flash.py, rv8term.py, rv8ram-boot.py (pin updates)
- All 4 requirement .md files updated

## 2026-06-14 — v3.5: Programmer Schematic Update

### Hardware Change
- **New schematic**: TXS0108E ×2 + 74HC595 ×2 (daisy-chain)
- **Board**: ESP32-WROOM-32 (verified against pinout image)
- **Address**: Full 15-bit via shift register (no direct ADDR_PINS)
- **Control**: /CE, /OE, /WE via TXS0108E #1

### Pin Mapping (all files synced)
```
Data D[0:7]:  GPIO [13, 12, 14, 27, 26, 25, 33, 32]
SR_DATA:      GPIO 23
SR_CLK:       GPIO 18
SR_LATCH:     GPIO 19
/CE:          GPIO 4
/OE:          GPIO 16
/WE:          GPIO 17
```

### Files Updated
- schematic.md (replaced with Thai pin-by-pin guide + code)
- rv8_programmer.ino, rv8flash.py, rv8ram-boot.py, rv8term.py
- All 3 requirement docs
- rv8_programmer-requirement.md

## 2026-06-09 — v3.4: Gate-Level Simulator + Build Plan

### Gate-Level Simulator (Task 6 Complete)
- **chip_sim.py**: Full CPU simulation through all 34 logic chips plus ROM/RAM
- **sim_lab/**: 10 step-by-step labs (module-by-module testing)
- **chips/__init__.py**: 34 logic chip objects plus ROM/RAM with pin layout + behavior
- **wiring.py**: 247 pin connections matching 03_wiring_guide.md
- **Timing analysis**: max safe clock 9.7 MHz, 97ns margin @ 5 MHz
- All 3 .bin programs pass through gate-level sim

### Build Plan
- Complete BOM with sources (LCSC/AliExpress)
- 5-board breadboard layout plan
- Wire color convention
- Propagation delay analysis for all chip types

## 2026-06-09 — v3.3: SETDP + Full 64KB Data Access

### New Feature
- **SETDP $40**: Data Page Register (U32 74HC574) — full 64KB data access
- **U33 74HC21**: SETDP decode (4-input AND gate) — pin-level finalized
- Data address = {DP, operand} = 16-bit (ROM read + RAM read/write)
- 32 logic chips, 18 instructions
- IRQ save-PC: documented as software-based for v1.0 build

### Tests
- `tb_rv8gr_setdp.v`: 5KB RAM write/read + ROM read (160 cycles, PASS)
- All existing tests still pass (127 + IRQ + tasks)

### Documentation
- All docs updated for 32 chips / 18 instructions / 64KB data
- DP_Load decode finalized (U33 74HC21 pin-level wiring)
- IRQ save-PC path documented (software approach for v1.0)
- Opcode map updated with SETDP at $40

## 2026-06-09 — v3.2: RV8-GR Design Sign-off

### Design Review
- **Risk analysis**: 10 hazards analyzed, all resolved
- **SRC+STR guard**: Hardware fix applied (U25 gate 3 → U7-19)
- **Bus definition**: RV8-Bus v2 (40-pin, CLK, /IRQ, /SLOT1-2)
- **Design sign-off**: Approved for physical build

### Documentation Rewrite (Stable)
- Merged 00_design + 01_isa_reference → `00_design_isa.md`
- Merged Construct.md → `03_wiring_guide.md` (official source of truth)
- Rewrote `02_instruction_trace.md` (compact, 7 traces)
- Rewrote `05_understand_by_module.md` (Thai tutorial, 15 sections + design rationale)
- Created `06_debug_plan.md` (14-step physical build guide)
- Created `07_risk_analysis.md` (10 hazards)
- Created `08_design_signoff.md` (final sign-off)
- Moved rv8gr_cpu.v → `rtl/` folder
- Removed obsolete files (Construct.md, tb_rv8gr_cpu.v, TASKS.md)

### Key Discoveries
- **Free NOT instruction** ($B0/$B8): ALU mode 101 = NOT(operand), 0 hardware cost
- **Opcode space**: 17 used (6.6%), 175 deterministic (68.4%), 64 forbidden (25%)
- **All 256 opcodes** produce deterministic behavior (horizontal control)

## 2026-06-08 — v3.1: Programmer Tools Complete

### Features
- **rv8flash.py**: Flash ROM via ESP32 (540 lines, 16 tests)
- **rv8ram-boot.py**: Upload to RAM via bootloader (430 lines, 15 tests)
- **rv8term.py**: Terminal bridge PC↔CPU (289 lines, 15 tests)
- **Test suites**: 46 tests, all passing

### Requirements Documents
- rv8flash-requirement.md — Full specification
- rv8ram-boot-requirement.md — Bootloader protocol
- rv8term-requirement.md — Terminal mode
- rv8_programmer-requirement.md — ESP32 firmware spec

### Documentation Updates
- README.md — Updated PC Software section with tool reference
- schematic.md — Added Section 6: Software (protocol, tools, tests)

### Files Added
```
Programmer/tools/
├── rv8flash.py           # ROM flash tool
├── rv8ram-boot.py        # RAM upload tool
├── rv8term.py            # Terminal tool
├── test_rv8flash.py      # 16 unit tests
├── test_rv8ram-boot.py   # 15 unit tests
├── test_rv8term.py       # 15 unit tests
├── rv8flash-requirement.md
├── rv8ram-boot-requirement.md
└── rv8term-requirement.md

Programmer/firmware/
└── rv8_programmer-requirement.md
```

### Serial Protocol
| Command | Action |
|---|---|
| `?` | Check connection → `Connected` |
| `F` + len + data | Flash ROM |
| `V` | Read ROM (32KB) |
| `R` | Reset CPU |

### VirtualESP32 Class
All tools use VirtualESP32 class at top for pin definitions (NodeMCU-32S defaults).

## 2026-06-06 — v3.0: IRQ + Python Simulation + Codeberg

### Features
- **IRQ Support**: Added EI ($08) and DI ($48) instructions
- **Interrupt Controller**: 74HC74 (U31) for IRQ latch and IE flag
- **Vectored Interrupt**: Fixed vector $FF00, auto-save PC to RAM[$0E:$0F]
- **Python Simulation**: sim/gate_sim.py — gate-level educational model

### Changes
- Logic chips: 29 → 30 (+1 for IRQ flip-flop)
- Instructions: 15 → 17 (+EI, +DI)

### New Files
- `RV8GR/tb/tb_rv8gr_irq.v` — IRQ testbench (6 tests)
- `RV8GR/tb/tb_rv8gr_tasks.v` — milestone tests
- `RV8GR/sim/gate_sim.py` — Python chip simulation
- `RV8GR/tools/test_rv8gr_asm.py` — assembler unit tests
- `RV8GR/doc/task_test_plan.md` — test milestones

### Documentation Updates
- All docs updated: 30 chips, 17 instructions, IRQ section
- Construct.md: U31 wiring, EI/DI in ISA table

### Repository
- Moved to Codeberg: https://codeberg.org/JOJOCAFE/RV8

## 2026-05-27 — v2.0: RV8-GR Complete Redesign

### Features
- **Full 64K**: A15 chip select (ROM $8000-$FFFF, RAM $0000-$7FFF)
- **16-bit Jump**: Page Register for full address space
- **Execute from RAM**: PC in $0000-$7FFF fetches from RAM
- **Expandable**: ROM bank (A16), RAM pages via bus

### Architecture (29 chips)
- PC: 4× 74HC161
- IR: 2× 74HC574 (control + operand)
- Page Reg: 74HC574
- Accumulator: 74HC574
- ALU: 2× 74HC283 (adder) + 2× 74HC86 (XOR)
- Muxes: 8× 74HC157 (address, AC, XOR B-input)
- Control: 74HC245, 74HC164, 74HC541, 74HC74, 74HC688, 74HC04, 74HC32, 4× 74HC00, 74HC86

### ISA (15 instructions)
- ALU: ADDI, ADD, SUBI, SUB, XORI, XOR
- Move: LI, LB (MV a0,rs), SB (MV rd,a0)
- Control: BEQ, BNE, J, SETPG, SETPG_R

### Verification
- Verilog: 127 cycles, ALL TESTS PASSED
- Assembler: rv8gr_asm.py with labels, macros, .bin output
- Test ROM: testrom.bin — 10 test groups, 187 cycles

### Documentation
- Construct.md: pin-by-pin, bus-centric (source of truth)
- 00_design.md, 01_isa_reference.md, 02_instruction_trace.md
- 03_wiring_guide.md, 04_understand_by_module.md, 05_bank_switch.md

## 2026-05-16 to 2026-05-17 — v1.0: Initial RV8-GR

- 21 logic chips, ROM at $8000, 256-byte jump range
- Verilog 11/11 unit tests pass
- Assembler with basic features
- Full documentation set

## 2026-05-15 — RV8 Family

- **RV8**: 27 chips, microcode, Verilog 8/8 pass
- **RV8-R**: 18 chips concept (RAM registers)
- **RV8-G**: 28 chips concept (full ISA, no microcode)
- **RV8-GR**: 21 chips concept (reduced ISA, no microcode)

## 2026-05-10 to 2026-05-14 — Project Start

- Original designs explored and archived
- Programmer board (ESP32 + TXB0108) complete
- Reference study: Gigatron, SAP-1, Nand2Tetris

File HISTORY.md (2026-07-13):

# RV8 Project — Development History

## 2026-07-12 — v4.5: RV8GR Release Gate and External Components Checkpoint

- Hardened the behavioral Verilog benches and `sim/verify_wiring.py`: a
  detected mismatch now exits nonzero instead of only printing a failure.
- Corrected the reset contract across the wiring guide, logical protocol,
  debug plan, student plans, and lab material: while `/RST` is LOW, U8 is
  `000`; the first active clock after reset release establishes T0 and begins
  the first opcode fetch.
- Kept physical qualification aligned with the student baseline: 100 manual
  ticks, 50 kHz, and 1 MHz are required; 2 MHz is optional breadboard stress
  and 5 MHz is an optional PCB-only experiment.
- Re-ran against the current external Components library: the RV8GR audit
  passed for 16 part types and 36 packages, and the whole-system virtual fault
  screen found no pin-truth, edge-polarity, bus-contention, or deadband issues.
- Physical signoff remains open pending real-board evidence in
  `RV8GR/doc/07_real_build_timing_log.md`.

## 2026-07-10 — v4.4: RV8GR Student Labs and Components Mapping Checkpoint

- Rechecked RV8GR student labs, build-plan docs, KiCad module guide, and
  sim-lab scripts against the current `RV8GR/doc/01_wiring_guide.md` source of
  truth.
- Preserved the frozen v1.0 baseline count: **34 logic chips + ROM + RAM = 36
  packages**.
- Confirmed the current designator boundary: `U34` is the 74HC541 IRL-to-IBUS
  immediate buffer, ROM is `ROM1`, and RAM is `RAM1`.
- Cross-checked the Components library mapping: the 36 RV8GR board packages
  resolve to 16 board-used part types, and every board-used part has current
  Components package files, Python behavior, Verilog model, generated artifacts,
  and split test records.
- Updated student-facing Components docs with a beginner route and stop
  conditions for wrong pins, output-output conflicts, wrong clock edge, and
  missing propagation/deadband margin.
- Kept the physical-build boundary explicit: virtual tests can prove model
  coherence, but hardware speed/signoff still needs real voltage, clock,
  bus-deadband, memory float/write timing, and oscilloscope evidence.

## 2026-07-09 — v4.3: RV8GR Canonical Rename and Chip-Level Source

- Renamed the active student baseline from `RV8GR-V2/` to `RV8GR/`
- Updated top-level docs to route students, teachers, tooling, KiCad, netlist, and Verilog work through `RV8GR/`
- Normalized RV8GR count language to **34 logic chips + ROM + RAM = 36 packages**
- Kept chip-level Verilog/netlist export compatible with the Python-first simulation path

## 2026-06-26 — v4.2: RV8-R FullHW Real Hardware Path

- Reframed RV8-R as **FullHW**, a larger but real full-ISA TTL hardware path instead of the old 19-chip reduced concept
- Updated package target to **49 logic chips + 4 memory/ROM packages = 53 total**
- Defined real hardware paths for PC load/save, ALU logic operations, high-RAM register addressing, fast-page RAM, stack, `JAL/JALR`, IRQ entry, and `IRET`
- Changed RV8-R control model to **16-bit direct-control microcode** with a **15-bit microcode address**: `{IRQ_ACTIVE, C, Z, step[3:0], opcode[7:0]}`
- Marked the old 19-chip instruction trace as legacy design history
- Marked the existing Python microcode generator as a legacy 14-bit prototype; FullHW needs a new generator, RTL migration, and KiCad/ERC proof
- Updated the top-level README so RV8GR remains the physical student baseline and RV8-R FullHW becomes the full RV8-style TTL investigation path

## 2026-06-26 — v4.1: Programmer Dual-Mode RV8GR Compatibility

- Rechecked `Programmer/` against the current `RV8GR` RV8-Bus pinout and ROM wiring contract
- Confirmed the board supports two mutually exclusive programming paths: ZIF direct ROM programming, or in-system RV8-Bus programming with the ZIF empty
- Fixed RUN-mode bus release in firmware: `/WR` and `/RD` are both released when switching to RUN, then reclaimed in PROG
- Fixed `rv8term.py` so normal RUN terminal mode no longer requires the PROG-only `? -> Connected` handshake; `-c` remains the explicit PROG-mode health check
- Added RV8GR-compatible `rv8flash.py program FILE --base 0x0000` and `verify FILE --base 0x0000` aliases; nonzero base is rejected explicitly
- Documented the AT28C256 software data protection boundary: current firmware performs normal byte write cycles, so use SDP-disabled ROM chips or add an unlock sequence before protected parts
- Updated RV8GR docs and labs so Programmer command examples use the actual `Programmer/tools/rv8flash.py` path and final ROM `/WE -> RV8-Bus /WR` wiring is clear
- Regenerated `Programmer/KICAD/RV8Programmer.pdf` and SVG exports with KiCad 10.0.4
- Verification passed: Programmer Python tests (36), RV8GR wiring verifier, and RV8GR assembler tests

## 2026-06-26 — v4.0: RV8GR Student Build Guardrails

- Made `RV8GR/` the active 34-logic-chip student baseline in the top-level project docs
- Added Student Baseline Contract: 34 logic chips + ROM + RAM = 36 packages, no microcode, no hardware IRQ vector, fixed T0/T1/T2 execution, one active IBUS/DBUS driver
- Added recommended reading order: labs for students, build plan for teachers, debug plan for probing, wiring guide as source of truth, KiCad module split for schematic work
- Added temporary-wire removal checkpoints to the incremental build plan to prevent test jumpers from becoming hidden wiring bugs
- Added probe-point map to the physical debug plan for clock/reset, buses, enables, PC, PG, DP, AC, Z, and IRQ latch signals
- Marked ROM banking and hardware IRQ vectoring as future-only, not part of the baseline
- Cleaned generated VCD/VVP traces, Python caches, and Zone.Identifier metadata from RV8GR
- Verification passed: assembler tests, Python chip sim, wiring verifier, all RTL benches, and 512-case opcode sweep

## 2026-06-21 — v3.9: KiCad Module Definitions

- Created doc/10_kicad_modules.md: 6 hierarchical sheets for KiCad (CLK_RST, PC, ADDR_MEM, IR_BUF, ALU_AC, CTRL)
- Each module has sheet ports, pin-level wiring, placement notes
- Aligned with 06_debug_plan.md (14 steps) and hardware labs
- Cross-verified against 02_wiring_guide.md — all connections match

## 2026-06-19 — v3.8: Opcode Sweep, Page-Safe Assembler, Agent Skills

- Added exhaustive opcode sweep testbench (256 opcodes × Z=0/1 = 512 cases)
- Assembler upgraded: cross-page validation, overlap detection, duplicate labels, memh format
- Created debug-mantra skill (4-step hardware debugging discipline, adapted from 9arm-skills)
- Created scrutinize skill (outsider design review, adapted from 9arm-skills)
- Evaluated RV8GR-Codex (40-chip AI redesign): timing concerns real but irrelevant at 1 MHz, extracted useful bits, rejected the redesign
- Documented future upgrades (doc/11_future_upgrades.md): clock qualification, hardware DI, I/O decode for v2.0
- Clock targets: 1 MHz breadboard (808ns margin), 4 MHz PCB (88ns margin), no hardware changes
- Evaluated 7 external GitHub repos for applicable content (only 9arm-skills was useful)
- Status: 5 testbenches passing, assembler hardened, ready for physical build

## 2026-06-16 — v3.7: Documentation Freeze & Consistency Pass

- All 9 RV8-GR docs reviewed, corrected, and frozen (design_isa, wiring_guide, instruction_trace, bank_switch, understand_by_module, debug_plan, risk_analysis, design_signoff, task_test_plan)
- Added: Architectural Invariants, Hardware Freeze Policy, Instruction Trace Contract (13-field format), Golden Trace, Reset Contract, Forbidden Bus States, Illegal Opcode Behavior table
- Fixed: IRQ_FF clear mechanism consistent across all docs (v1.0 = /RST only)
- Fixed: Legacy package-count wording was superseded. The current frozen v1.0
  baseline is 34 logic chips + ROM + RAM = 36 packages.
- Fixed: Memory map consistent (ROM $0000-$7FFF, RAM $8000-$FFFF) everywhere
- Fixed: wiring.py missing U31 /RST connections
- Enhanced: debug_plan with 15+ new tests (bus ownership, walking-1, RAM march, burn-in, clock sweep)
- Enhanced: understand_by_module with block diagram, ISA table, clock-by-clock walkthrough
- Enhanced: 14 hardware labs synced with debug_plan
- Status: Architecture frozen, ready for physical build

## 2026-06-14 — v3.6: Programmer Bus-Based Redesign

- Programmer connects via RV8-Bus (40-pin) instead of direct ROM
- Firmware rewritten: removed /CE /OE, now drives /RST + /WR + /RD on bus
- Added `?` command for connection check (rv8flash + rv8term use it)
- Added 2s boot delay + buffer drain (ESP32 resets on serial open)
- Two usage scenarios documented: bare ROM (A) and full CPU board (B)
- rv8term.py rewritten following rv8flash.py patterns (check before connect)
- Added `-c` option to rv8term.py
- Port + baud displayed on connect (`Port: /dev/ttyUSB0 @ 115200 baud`)
- Fixed cmd_flash double-send bug in rv8flash.py
- All docs updated: schematic, README, requirements (6 .md files)
- Firmware compiled and flashed to ESP32 via arduino-cli
- 31 tests passing (16 flash + 15 term)

## 2026-06-14 — v3.5: Programmer Schematic Update

- Replaced schematic with new design (TXS0108E + 74HC595 ×2)
- Board renamed to ESP32-WROOM-32 (pin-verified)
- All software pin mappings updated and verified consistent
- RV8-R design plan created (18 chips, RISC-V, microcode)
- RV8F concept saved (38 chips, fast SRAM microcode)

## 2026-06-09 — v3.4: Gate-Level Simulator + Build Plan

- Gate-level chip simulator: 34 logic chips plus ROM/RAM, 14 types, 141 test vectors
- 10 sim labs (ring counter → full execute LI $42)
- 3 .bin programs verified through gate-level sim
- Propagation delay model (70ns ROM/RAM, max 9.7 MHz)
- Complete BOM (order-ready) + 5-board breadboard layout
- Wiring verified: 23 critical connections checked against 03_wiring_guide

## 2026-06-09 — v3.3: SETDP + Full 64KB Data Access

- Added SETDP instruction ($40) — Data Page Register (U32 74HC574)
- Added U33 (74HC21) for SETDP decode — pin-level finalized
- Full 64KB data access: DP=$00-$7F → RAM, DP=$80-$FF → ROM read
- 32 logic chips, 18 instructions, 34 packages total
- IRQ save-PC documented (software approach for v1.0)
- SETDP test: 5KB RAM write/read + ROM read (160 cycles, all pass)
- All docs updated and verified consistent

## 2026-06-09 — v3.2: RV8-GR Design Sign-off

- Complete design review and risk analysis (10 hazards)
- SRC+STR hardware guard applied (spare gate, 0 chips added)
- RV8-Bus v2 defined (40-pin: A16+D8+CLK+/WR+/RD+/IRQ+/SLOT)
- Documentation rewrite: merged and compacted all docs
- Created debug plan (14 steps for physical build)
- Discovered free NOT instruction ($B0/$B8)
- Design signed off for physical build

## 2026-06-08 — v3.1: Programmer Tools

- Created rv8flash.py (540 lines, 16 tests) — Flash ROM via ESP32
- Created rv8ram-boot.py (430 lines, 15 tests) — Upload to RAM via bootloader
- Created rv8term.py (289 lines, 15 tests) — Terminal bridge PC↔CPU
- Created test suites: 46 tests total, all passing
- Created requirement documents for all tools
- Updated README.md and schematic.md with software documentation

## 2026-05-10 to 2026-05-14 — Project Start
- Original designs explored and archived
- Programmer board complete (ESP32 + TXB0108)

## 2026-05-15 — RV8 Family Architecture
- RV8: 27 chips, microcode, Verilog 8/8 pass
- RV8-R: 18 chips concept
- RV8-G: 28 chips concept
- RV8-GR: 21 chips concept

## 2026-05-16 to 2026-05-17 — RV8-GR Initial Design (v1.0)
- 21 logic chips, ROM at $8000, 256-byte jump range
- All 4 variants traced and verified
- Verilog 11/11 unit tests pass
- Assembler (rv8gr_asm.py)
- Assembly integration test passes
- Full doc set complete

## 2026-05-27 — RV8-GR v2.0 Complete Redesign + RV8-G Construct

### RV8-GR Complete (v2.0)
- Architecture: 29 logic chips, full 64K, A15 chip select
- Execute from RAM (PC < $8000)
- 16-bit jump via Page Register
- ISA: 15 instructions (XORI=$70, XOR=$78, SETPG=$20, SETPG_R=$28)
- Verilog: ALL TESTS PASSED (127 cycles)
- Assembler: rv8gr_asm.py — labels, macros, .bin output
- Test ROM: testrom.bin — 10 test groups, 187 cycles
- Docs: Construct (pin-level), ISA, traces, wiring, modules, bank switch

### RV8-G Construct
- 38 logic chips, full 35-instruction ISA, no microcode
- 4-cycle execution with B-register
- Full ALU: ADD/SUB/AND/OR/XOR/SLL/SRL/SLT
- Branches: BEQ/BNE/BLT/BGE rs1,rs2
- JAL/JALR, PUSH/POP
- Construct.md written

## 2026-06-06 — RV8-GR v3.0: IRQ + Python Simulation + Codeberg

### IRQ Support
- Added EI ($08) and DI ($48) instructions
- IRQ latch (74HC74 U31-B) for edge detection
- IE flag (74HC74 U31-A) for enable/disable
- Fixed vector $FF00, auto-save PC to RAM[$0E:$0F]
- No nesting (IE cleared on entry)
- 30 logic chips total (+1 from v2.0)
- 17 instructions total (+2 from v2.0)
- tb_rv8gr_irq.v — 6 tests: EI/DI, IRQ fire, PC save, defer past jumps

### Python Gate-Level Simulation
- sim/gate_sim.py — simplified chip models
- Ring counter, registers, ALU components
- Trace timing: T0→T1→T2
- Educational tool for understanding CPU behavior

### Test Infrastructure
- tb_rv8gr_tasks.v — milestone tests (1-9)
- tools/test_rv8gr_asm.py — assembler unit tests
- doc/task_test_plan.md — test milestones

### Repository
- Moved from GitHub to Codeberg
- https://codeberg.org/JOJOCAFE/RV8

## Key Milestones

| Date | Milestone |
|---|---|
| 2026-05-10 | Project started |
| 2026-05-14 | Programmer board complete |
| 2026-05-16 | All 4 variants traced and verified |
| 2026-05-17 | RV8-GR v1.0: toolchain ready |
| 2026-05-27 | RV8-GR v2.0: complete redesign, full 64K |
| 2026-06-06 | RV8-GR v3.0: IRQ + sim + Codeberg |

## Lessons Learned

1. Every trace finds 1-2 more chips than initially claimed
2. Full ISA always costs ~27-30 chips regardless of approach
3. RAM registers save ~10 chips (proven)
4. "No microcode" doesn't save chips for full ISA
5. Bank switch belongs on expansion board, not CPU

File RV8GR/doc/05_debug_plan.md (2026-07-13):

# RV8-GR — Debug Plan (Physical Build)

**สร้างทีละโมดูล ทดสอบทุกขั้น ไม่ต้องรีบ ใช้ LED + single-step clock**

---

## อุปกรณ์ Debug

| อุปกรณ์ | จำนวน | ใช้ทำอะไร |
|---|:-----:|---|
| LED + 330Ω resistor | 8 | ดู bus 8 บิต |
| Push button (NO) | 1 | Single-step clock |
| 555 timer module | 1 | Low-speed clock (1-10 Hz) |
| DIP switch 8-bit | 1 | ป้อน data bus ด้วยมือ |
| Logic probe / multimeter | 1 | เช็ค HIGH/LOW |

---

## Baseline Boundary

Debug only the RV8GR baseline first:

- 34 logic chips + ROM + RAM.
- IRQ is polling-only.
- DI has no hardware effect.
- No hardware vector to `$FF00`.
- No automatic PC save, restore, acknowledge, or RETI circuit.

If the CPU jumps when `/IRQ` is asserted, that is a wiring mistake for v2.

---

## Virtual Check Before Wiring

Before a student wires the full system, run the software checks from
`RV8GR/README.md`, then run the RV8GR soft debug trace and the Components
virtual physical checker:

```bash
cd /home/jo/kiro/RV8/RV8GR
python3 -B sim/soft_debug.py
```

```bash
cd /home/jo/kiro/Components
PYTHONPATH=python python3 -B -m chiplib.cli circuit-faults examples/circuits/RV8GR_WholeSystemChipLevelVirtual/circuit.json
```

This checker is a virtual risk screen for pin-number mistakes, active-low
mistakes, unsafe output-output wiring, and timing/noise assumptions in the
whole-system circuit model. Passing it means the model is ready to compare
against the bench. It does not prove that the physical breadboard is correct.

> 📌 Simulator note: `sim/soft_debug.py` starts PG=$00, DP=$80, AC=$00, Z=1 so
> its built-in tests are deterministic. Real 74HC574 registers PG/DP/AC and the
> Z flag are not guaranteed after reset. The physical ROM must still start with
> the boot initialization sequence below.

---

## Probe Point Map

Use these points before guessing. A stage is not passed until the listed signal
matches the expected behavior.

| Signal | Probe at | Expected use |
|---|---|---|
| `CLK` | U8-8, U1-U4 pin 2 | One clean pulse per button press |
| `/RST` | U1-U4 pin 1, U8-9, U31-1/13 | LOW during reset, HIGH when running |
| `T0` | U8-3 | Opcode fetch phase |
| `T1` | U8-4 | Operand fetch phase |
| `T2` | U8-5 | Execute phase |
| `PC0..PC7` | U1/U2 Q outputs | Counts during T0/T1, loads on jump |
| `ABUS0..ABUS7` | U15/U16 outputs | PC or IRL selected by `/ADDR_MODE` |
| `ABUS8..ABUS15` | U29/U30 outputs | PC high or DP selected by `/ADDR_MODE` |
| `DBUS0..DBUS7` | ROM/RAM data pins, U7 B side | External memory data bus |
| `IBUS0..IBUS7` | U7 A side, U34 output, U14 output | Internal CPU data bus |
| `BUF_OE_N` | U24-12, U7-19 | LOW when U7 is enabled |
| `WR_DIR` | U28-8, U7-1, ROM `/OE` | 0 read, 1 store/write direction |
| `/IRL_OE` | U26-3, U34-1/19 | LOW when operand drives IBUS |
| `/AC_BUF` | U26-8, U14 enables, RAM `/WE` | LOW when AC stores to memory |
| `ACC_CLK` | U27-11, U9-11, U21-3 | AC/Z update pulse |
| `AC0..AC7` | U9 Q outputs | Accumulator value |
| `Z_flag` | U21-5 | HIGH when AC is zero |
| `/PC_LD` | U26-11, U1-U4 pin 9 | LOW only for taken jump/branch at T2 |
| `PG0..PG7` | U23 Q outputs | Jump page high byte |
| `DP0..DP7` | U32 Q outputs | Data page high byte |
| `DP_Load` | U33-6, U32-11 | Pulse on SETDP |
| `IE` | U31-5 | Set by EI, cleared by reset only |
| `IRQ_FF` | U31-9 | Latches after `/IRQ` release, cleared by reset |

---

## Clock Options

```
Mode 1: Single-step (debug)
  Button → debounce (RC + Schmitt) → CLK
  กดปุ่ม 1 ครั้ง = 1 clock = 1 state change

Mode 2: Low speed / timing qualification
  50 kHz first, then 1 MHz
  Use 50 kHz for safe visible bring-up before MHz tests
  2 MHz = optional short-wire breadboard stress
  5 MHz = optional PCB-only experiment

Mode 3: Full speed
  1 MHz 5V CMOS oscillator module → 74HC14 buffer → CLK
  1 MHz = official target (ปลอดภัย, margin >700ns)
  2 MHz = optional short-wire breadboard stress
  5 MHz = optional PCB-only experiment (~0ns margin)
```

---

## ขั้นที่ 0: Boot Sequence Sanity Check

**เมื่อไร**: หลังต่อวงจรครบทุกชิป (ขั้นที่ 12+) หรือเป็น first test ของ full system

**Reset state ที่ hardware รับประกัน:**
- PC = $0000
- U8 Q2:Q0 = `000` while `/RST` is LOW
- IE = 0, IRQ_FF = 0

After `/RST` returns HIGH, the first active clock edge shifts the ring counter
into T0 (`001`) and starts the first opcode fetch. Do not treat reset itself as
a T0 clock edge.

**State ที่ UNKNOWN หลัง reset** (ต้อง initialize ก่อนใช้):
- PG, DP, AC, Z = ค่าไม่แน่นอน

**Test ROM (flash ไว้ที่ $0000):**
```asm
SETDP $80       ; DP = $80
SETPG $00       ; PG = $00
LI $00          ; AC = $00, Z = 1
J $06           ; loop here (HLT macro = J self)
```

**ทดสอบ (single-step 12 clocks):**
- [ ] After 3 clocks (1 instr): DP LED = $80
- [ ] After 6 clocks (2 instr): PG LED = $00
- [ ] After 9 clocks (3 instr): AC LED = $00, Z LED = ON
- [ ] After 12 clocks (4 instr): PC = $0006 (J $06 loads PC back to same address → loop)

> 📌 ถ้า test นี้ผ่าน = CPU boot ได้ถูกต้อง ทุก architectural state defined แล้ว

---

## ขั้นที่ 1: Power + Clock + Reset

**ต่ออะไร**: 5V supply, clock (button), reset (RC), LED 1 ดวงบน CLK

**ทดสอบ**:
- [ ] VCC = 5.0V ± 0.2V ที่ทุกจุด
- [ ] GND ต่อถึงกันทุกจุด (วัดด้วย multimeter continuity)
- [ ] กดปุ่ม clock → LED CLK กระพริบ
- [ ] Reset: กด reset → ปล่อย → /RST ขึ้น HIGH
- [ ] Bypass cap 100nF ceramic ทุก IC (VCC↔GND ใกล้ขาชิปที่สุด)

> ⚠️ **Decoupling capacitor บังคับ**: 100nF ceramic 1 ตัวต่อ 1 IC.
> วางใกล้ขา VCC/GND ของชิปให้มากที่สุด ห้ามข้าม.
> ถ้าไม่ใส่: 1 MHz อาจผ่าน แต่ 2 MHz จะ glitch สุ่ม.

### Power Integrity Test (ทำหลังต่อชิปครบ ก่อน full-speed)

- [ ] รัน 1 MHz → วัด VCC ที่ชิปไกลสุดจากแหล่งจ่าย (U30, U32)
- [ ] เกณฑ์: 4.8V–5.2V = ผ่าน. < 4.7V = อันตราย (เพิ่ม bulk cap 100µF)

### Reset Recovery Test

- [ ] รันโปรแกรม loop ที่ 1 MHz (เช่น LI $55, ADDI $01, J $00)
- [ ] กด RESET ขณะรัน → PC ต้องกลับ $0000 และ U8 ต้องเป็น `000`; หลังปล่อย
      reset แล้ว clock active ครั้งแรกต้องเข้าสู่ T0 ทุกครั้ง
- [ ] ลองกด RESET 10 ครั้งที่จังหวะต่างกัน → ต้องผ่านทุกครั้ง

**LED**: 1 ดวงบน CLK output

### Clock Integrity Check (ก่อนต่อ Ring Counter)

- [ ] กดปุ่มค้าง → LED ติดค้าง (ไม่กระพริบ = debounce ดี)
- [ ] ปล่อยปุ่ม → LED ดับ (ไม่ bounce กลับ)
- [ ] กดแล้วปล่อยเร็ว → นับได้ 1 pulse เท่านั้น (ดูจาก ring counter ใน Step 2)
- [ ] 100-tick push-switch test: กด single-step 100 ครั้ง → ring counter ต้อง
      วน T0→T1→T2 ครบ 33 รอบ + T0 โดยไม่ข้าม state

> ⚠️ ถ้า clock bounce → ring counter จะ advance หลาย state ในปุ่มเดียว
> แก้: เพิ่ม RC debounce (10kΩ + 100nF) + 74HC14 Schmitt trigger

---

## ขั้นที่ 2: Ring Counter (U8 + U24 inverters)

**ต่ออะไร**: U8 (74HC164), U24 pin 1-4 (inverters 2 ตัว)

**ทดสอบ**:
- [ ] Reset asserted → T0=0, T1=0, T2=0
- [ ] First active clock after reset release → T0=1, T1=0, T2=0
- [ ] Clock 2 → T0=0, T1=1, T2=0
- [ ] Clock 3 → T0=0, T1=0, T2=1
- [ ] Clock 4 → T0=1, T1=0, T2=0 (wrap around)
- [ ] ทำซ้ำ 10 รอบ ไม่ skip ไม่ค้าง

**Endurance test** (555 timer @ 1 Hz, ปล่อย 1000+ cycles):
- [ ] ดู T0→T1→T2 ไม่เคยหลุด pattern (LED หมุน 3 ดวงสม่ำเสมอ)
- [ ] ถ้า skip หรือค้าง → ตรวจ inverter feedback (U24) หรือ clock bounce

**Illegal State Recovery** (ตรวจว่า ring counter self-corrects):
- [ ] ถอด /RST ชั่วคราว แล้วจ่าย noise เข้า U8 → state อาจเพี้ยน
- [ ] ต่อ /RST กลับ → กด reset → U8 ต้องเป็น `000`; ปล่อย reset แล้ว clock
      active ครั้งแรกต้องกลับ T0=1,T1=0,T2=0
- [ ] ถ้า power-up ได้ state 000 (all-zero) → feedback NOT(Q0)&NOT(Q1) จะ inject 1 → recover ภายใน 3 clocks

**Ring Counter State Matrix** (74HC164 behavior):

| Q2 Q1 Q0 | State | Recovery |
|:---:|---|---|
| 0  0  0 | All-zero | Self-recover in 3 clocks (feedback injects 1) |
| 0  0  1 | T0 | ✅ Normal |
| 0  1  0 | T1 | ✅ Normal |
| 1  0  0 | T2 | ✅ Normal |
| 0  1  1 | Illegal | Clears in 1-2 clocks (feedback = NOT(1)&NOT(1) = 0) |
| 1  0  1 | Illegal | Clears in 1-2 clocks |
| 1  1  0 | Illegal | Clears in 1-2 clocks |
| 1  1  1 | Illegal | Clears in 2-3 clocks |

> 📌 All illegal states self-correct within 3 clocks — no hardware fix needed.
> /RST clears U8 immediately to `000`; the first active clock after reset
> release recovers to T0 (`001`).

**LED**: 3 ดวงบน T0 (U8-3), T1 (U8-4), T2 (U8-5)

```
กดปุ่ม:  LED pattern:
  1       T0=on  T1=off T2=off
  2       T0=off T1=on  T2=off
  3       T0=off T1=off T2=on
  4       T0=on  T1=off T2=off  ← ถูกต้อง!
```

**ผิดพลาดที่พบบ่อย**:
- T0 ค้าง HIGH → U24 inverter ต่อผิดขา
- ไม่ wrap → U8 pin A,B ต่อผิด (ต้องเป็น NOT(Q0), NOT(Q1))

---

## ขั้นที่ 3: PC Counter (U1-U4)

**ต่ออะไร**: U1-U4 (74HC161 ×4), ต่อ CLK, /RST, cascade (RCO)

**ก่อนต่อ memory**: ยังไม่ต่อ ROM/RAM — ทดสอบ counter เปล่า

**ทดสอบ**:
- [ ] Reset → PC = $0000 (ดูจาก LED บน QA-QD ของ U1)
- [ ] ENP=1, ENT=1 → กด clock → PC นับขึ้น 0,1,2,3...
- [ ] /LD=0, D=$42 → กด clock → PC = $42
- [ ] Cascade: U1 RCO → U2 ENT (นับเกิน 15 ขึ้น U2)

**LED**: 8 ดวงบน PC[7:0] (U1 QA-QD + U2 QA-QD)

```
Reset:    00000000
Clock 1:  00000001
Clock 2:  00000010
...
Clock 15: 00001111
Clock 16: 00010000  ← U2 เริ่มนับ (cascade ทำงาน!)
```

**สำคัญ**: ต่อ PC_INC (U25-6) = VCC ชั่วคราว เพื่อให้นับตลอด

> ⚠️ **ถอด VCC จาก PC_INC ก่อนเริ่มขั้นที่ 9 (Jump Logic)**
> ไม่งั้น PC จะนับขึ้นตลอดแม้ J/BEQ สั่ง load → jump test จะ fail

---

## ขั้นที่ 4: Address Mux (U15-U16, U29-U30)

**ต่ออะไร**: Mux 4 ตัว, ต่อ IRL/DP เข้า A-inputs และ PC เข้า B-inputs

**ทดสอบ**:
- [ ] /ADDR_MODE=1 (VCC) → ABUS = PC (ดู LED ตรงกับ PC)
- [ ] /ADDR_MODE=0 (GND) → ABUS = A-inputs (ต่อ DIP switch เข้า A)
- [ ] A15 output ถูกต้อง (U30-12)

**LED**: 8 ดวงบน ABUS A[7:0]

---

## ขั้นที่ 5: ROM (AT28C256)

**ต่ออะไร**: ROM, ต่อ ABUS → ROM A[14:0], /CE ← A15, /OE ← WR_DIR (U28-8)

> 📌 Chip Select (from Design ISA):
> ROM /CE = A15 (active when A15=0, address $0000-$7FFF)
> RAM /CE = /A15 (active when A15=1, address $8000-$FFFF)

**เตรียม ROM**: Flash test pattern ด้วย Programmer board:
```bash
python3 ../Programmer/tools/rv8flash.py program test_bytes.bin --base 0x0000
```

```
$0000: $30  (LI opcode)
$0001: $42  (operand)
$0002: $01  (J opcode)
$0003: $00  (jump to $00 → loop)
```

**ทดสอบ**:
- [ ] PC=$0000, A15=0 → ROM /CE=0 → DBUS = $30
- [ ] PC=$0001 → DBUS = $42
- [ ] PC=$0002 → DBUS = $01
- [ ] PC=$0003 → DBUS = $00

**ทดสอบ ROM inactive (สำหรับ RAM ขั้นที่ 11)**:
- [ ] Force A15=1 (ต่อ VCC ชั่วคราว) → ROM /CE=1 → ROM output hi-Z (DBUS ไม่ถูกขับ)

> 💡 Tip: ใส่ 10kΩ pull-up บน DBUS → ถ้า ROM hi-Z จริง DBUS จะอ่านได้ $FF ชัดเจน

**LED**: 8 ดวงบน DBUS D[7:0]

```
กด clock (PC นับ):
  $0000 → LED = 00110000 ($30)  ✓
  $0001 → LED = 01000010 ($42)  ✓
```

**ผิดพลาดที่พบบ่อย**:
- DBUS = $00 ตลอด → ROM /CE ไม่ LOW (เช็ค A15 = 0 จาก PC)
- DBUS ผิดค่า → address ต่อสลับ (A0↔A1 etc.)

---

## ขั้นที่ 6: Bus Buffer + IR (U7, U5, U6)

**ต่ออะไร**: U7 (245), U5 (IR_HIGH), U6 (IR_LOW), ROM /OE safety via WR_DIR

### Bus Ownership Verification (ตรวจก่อนต่อ ALU)

ใช้ LED probe ตรวจ IBUS driver ทีละ phase:

| Phase | IBUS driver ที่ถูกต้อง | ตรวจ |
|:-----:|:---:|---|
| T0 | U7 (DBUS→IBUS) | U7-19=LOW, U34-1/19=HIGH, U14-1=HIGH |
| T1 | U7 (DBUS→IBUS) | (เหมือน T0) |
| T2 immediate | U34 (IRL→IBUS) | U34-1/19=LOW, U7-19=HIGH |
| T2 store | U14 (AC→IBUS), U7 writes IBUS→DBUS | U14-1=LOW, U7-19=LOW, U7-1=HIGH |

- [ ] Single-step ตรวจว่า IBUS driver ไม่ทับกัน (ทีละตัวเท่านั้น)

### Bus Float Test (ตรวจ IBUS ไม่ลอย)

- [ ] Force: U7 /OE=HIGH, U34 /OE=HIGH, U14 /OE=HIGH (ปิด driver ทั้ง 3)
- [ ] วัด IBUS ด้วย LED → ค่าต้องคงที่ (ไม่สุ่มเปลี่ยน)
- [ ] ถ้า LED กระพริบสุ่ม → IBUS ลอย → เพิ่ม 10kΩ pull-down/pull-up

### DBUS Float Test

- [ ] ปิด ROM (/CE=HIGH), RAM (/CE=HIGH), U7 (/OE=HIGH)
- [ ] วัด DBUS → ค่าต้องคงที่ (ถ้ามี pull-up → $FF)
- [ ] ถ้าสุ่มค่า → DBUS ลอย → ปกติไม่เป็นปัญหา (มี driver active ทุก phase) แต่ช่วยยืนยัน isolation

### Bus Fight Detection (กระแสผิดปกติ)

- [ ] วัดกระแสรวมขณะ single-step: ปกติ ≈ 50–150mA
- [ ] ถ้า > 200mA หรือ IC ร้อนผิดปกติ → bus fight (2 drivers active พร้อมกัน)
- [ ] จุดที่เสี่ยง: T2 store to ROM page (ROM /OE must go HIGH via WR_DIR)

**สำคัญ**: U7-19 (/OE) ต้องต่อจาก **U24-12** (BUF_OE_N)
```
U24-13 ← U26-3 (/IRL_OE)
U24-12 → U7-19 (BUF_OE_N)
U28-8  → U7-1 (WR_DIR) and ROM /OE
```

**ทดสอบ Store Path**:
- [ ] เมื่อ STR=1 ที่ T2: U7-19 ต้อง LOW, U7-1 ต้อง HIGH, ROM /OE ต้อง HIGH
- [ ] เมื่อ T2 immediate: U7-19 ต้อง HIGH (U7 disabled)

**ทดสอบ**: Single-step ผ่าน 1 คำสั่ง LI $42:
- [ ] T0: U7 enabled, DBUS($30) → IBUS → U5 latch → IR_HIGH=$30
- [ ] T1: DBUS($42) → IBUS → U6 latch → IR_LOW=$42
- [ ] ดูค่า U5 Q outputs (control signals) ตรง

**LED**: 8 ดวงบน IBUS (U7 A-side) หรือ U5 Q outputs

```
After T0: U5-15(AC_WR)=1, U5-14(MUX)=1 → ถูกต้องสำหรับ LI!
After T1: U6-19(IRL0)=0, U6-18(IRL1)=1, U6-17(IRL2)=0... = $42
```

---

## ขั้นที่ 7: ALU + AC (U10-U13, U19-U20, U17-U18, U9)

**ต่ออะไร**: XOR gates, adder, muxes, accumulator

**ทดสอบ LI $42**:
- [ ] T2: IBUS=$42, XOR B-mux=0, XOR output=$42
- [ ] MUX_SEL=1 → AC mux selects XOR output
- [ ] ACC_CLK pulse → AC latches $42
- [ ] ดู U9 Q outputs = $42

**LED**: 8 ดวงบน AC (U9 Q outputs)

```
Before T2: AC = unknown (74HC574 has no /CLR)
After T2:  AC = $42 ← LI $42 ทำงานแล้ว!
```

**ทดสอบ ADDI $05** (flash ROM: $0004=$10, $0005=$05):
- [ ] After execute: AC = $42 + $05 = $47

---

## ขั้นที่ 8: Z Flag (U21, U22)

**ต่ออะไร**: U22 (688), U21 (74)

**ทดสอบ**:
- [ ] AC=$42 → Z LED = OFF (AC ≠ 0)
- [ ] SUBI $42 → AC=$00 → Z LED = ON

**ทดสอบ async preset toggle** (พิสูจน์ U22→U21 /PR path):
- [ ] LI $00 → Z ON
- [ ] LI $01 → Z OFF
- [ ] LI $00 → Z ON อีกครั้ง (toggle กลับได้ = async preset ทำงาน)

**LED**: 1 ดวงบน Z_flag (U21-5)

---

## ขั้นที่ 9: Branch/Jump Logic (U24-U28)

**ต่ออะไร**: Control logic gates

**ทดสอบ J (unconditional jump)**:
- [ ] Flash ROM: J $10 at $0006
- [ ] After T2: /PC_LD goes LOW → PC loads $0010

**ทดสอบ BEQ (Z=1)**:
- [ ] Set AC=0 (Z=1), BEQ $20
- [ ] After T2: PC = $0020

**LED**: 1 ดวงบน /PC_LD (U26-11)

**PC_LOAD vs PC_INC Priority Test**:
- [ ] Execute J $10 → PC must be exactly $0010 (not $0011)
- [ ] ถ้า PC=$0011 → /PC_LD ชนะ PC_INC ไม่ได้ → ตรวจ 74HC161 /LD wiring

---

## ขั้นที่ 10: Page Register + 16-bit Jump (U23)

**ต่ออะไร**: U23 (574)

**ทดสอบ**:
- [ ] SETPG $90 → PG LED = $90
- [ ] J $00 → PC = $9000

**Long Jump Test** (ตรวจ PG ครบทุกบิต):
- [ ] SETPG $FF, J $FF → PC = $FFFF (all bits HIGH)
- [ ] SETPG $AA, J $55 → PC = $AA55 (alternating pattern)
- [ ] ถ้าบิตใดไม่ถูก → PG-to-PC wiring (U23→U3/U4) ต่อผิดบิต

**LED**: 8 ดวงบน Page Reg (U23 Q outputs)

---

## ขั้นที่ 11: RAM (62256) + Data Page (U32)

**ต่ออะไร**: RAM, U32 (74HC574), ต่อ ABUS, DBUS, /CE ← /A15 (U24-6), /WE ← /AC_BUF

**U32 wiring**:
- D[7:0] ← IBUS
- Q[6:0] → U29/U30 A-inputs (A[14:8])
- Q[7] → U30-14 (A15 A-input)
- CLK ← DP_Load (U33-6)

**U33 wiring (SETDP decode — 74HC21 gate 1)**:
- Pin 1 ← T2 (U8-5)
- Pin 2 ← XOR_MODE (U5-13)
- Pin 4 ← /ADDR_MODE (U26-6 — inverted SRC|STR)
- Pin 5 ← /AC_WR (U24 — inverted AC_WR)
- Pin 6 → U32 CLK (DP_Load)

DP_Load = T2 & XOR_MODE & /ADDR_MODE & /AC_WR
→ triggers on SETDP ($40) and alias $C0 (SUB bit ignored by decode)

**ทดสอบ page $80 (SETDP $80)**:
- [ ] SETDP $80, AC=$AA, SB $03 → RAM[$8003] = $AA
- [ ] LB $03 → AC = $AA (read back)

**ทดสอบ page $90 (SETDP $90)**:
- [ ] SETDP $90, LI $55, SB $00 → RAM[$9000] = $55
- [ ] LB $00 → AC = $55 (read from page $90)

**ทดสอบ ROM read (SETDP $00)**:
- [ ] SETDP $00, LB $00 → AC = ROM[$0000] = first opcode

> 📌 **Architectural Contract**: LB can read ROM (DP < $80).
> SB to ROM address is ignored during normal CPU runtime. ROM `/WE` stays
> inactive unless the Programmer owns it in PROG/reset isolation.

**ทดสอบ boundary (ROM/RAM split at $8000)**:
- [ ] SETDP $7F, LB $FF → reads ROM[$7FFF] (A15=0 → ROM)
- [ ] SETDP $80, LB $00 → reads RAM[$8000] (A15=1 → RAM)

**Memory Contention Test** (ตรวจว่า ROM/RAM ไม่ขับ DBUS พร้อมกัน):
- [ ] SETDP $7F, LB $00 → ดู ROM /CE=LOW, RAM /CE=HIGH (วัดด้วย probe)
- [ ] SETDP $80, SB $00 → ดู RAM /CE=LOW, ROM /CE=HIGH
- [ ] ถ้า A15 หลุด → ทั้ง ROM+RAM active → DBUS contention → ค่าอ่านผิด

**LED**: 8 ดวงบน U32 Q outputs (ดู data page value)

---

## ขั้นที่ 12: Full System Test

**ต่อครบทุกชิป** แล้วรัน test ROM:

```asm
; Test ROM ($0000):
LI $10        ; AC=$10
ADDI $05      ; AC=$15
SUBI $15      ; AC=$00, Z=1
BEQ pass      ; should jump
J fail        ; should not reach
pass: J pass  ; success! (PC=$000A loop)
fail: J fail  ; failure  (PC=$000C loop)
```

**ทดสอบ**:
- [ ] Single-step ทีละ clock → ดู AC, Z, PC เปลี่ยนถูกต้อง
- [ ] Low-speed (1 Hz) → ดู LED pattern ถูก
- [ ] Full-speed (1 MHz) → halt ที่ pass (ไม่ใช่ fail)

**Expected PC values** (ดู LED ของ PC):
- pass = PC loops (ดู address คงที่)
- fail = PC loops ที่ address อื่น → ผิด

**Burn-in test**:
- [ ] Run Golden Bring-up at 1 MHz continuously for 1 hour
- [ ] PC must remain at pass address (no glitches, no drift)
- [ ] If fails after 10+ minutes: check power rail noise, contact resistance, long wire ringing

### Walking-1 Address Test (ROM)

Flash ROM with known pattern at power-of-2 addresses:

```
$0001: $01,  $0002: $02,  $0004: $04,  $0008: $08
$0010: $10,  $0020: $20,  $0040: $40,  $0080: $80
```

- [ ] PC advances → DBUS matches address pattern (catches swapped address lines)
- [ ] ถ้า $0004 อ่านได้ $08 → A2/A3 สลับกัน

### RAM March Test (ตรวจ address line shorts)

```asm
; Write unique value to each address, then read back:
SETDP $80
LI $01 → SB $00    ; RAM[$8000] = $01
LI $02 → SB $01    ; RAM[$8001] = $02
LI $04 → SB $02    ; RAM[$8002] = $04
LI $08 → SB $03    ; RAM[$8003] = $08
; ... then read back each:
LB $00 → should be $01
LB $01 → should be $02
; etc.
```

- [ ] ถ้า LB $02 ได้ $08 → A1/A2 short ใน RAM address wiring

### Clock Sweep (Timing Qualification)

รัน Golden Bring-up ที่ความถี่ต่าง ๆ บันทึกผล. เริ่มจาก slow/safe แล้วค่อยเพิ่ม:

| Clock | Result | Notes |
|:-----:|:---:|---|
| 100-tick push switch | | One pulse per press, no skipped T-state |
| 50 kHz | | Slow electronic clock sanity check |
| 1 MHz | | Official target |
| 2 MHz | | Breadboard achievable |
| 5 MHz | | PCB only (experimental) |

- [ ] บันทึก max frequency ที่ pass → เป็น spec ของเครื่องตัวนี้
- [ ] บันทึกผลจริงและปัญหาที่เจอใน `07_real_build_timing_log.md`
- [ ] ถ้า fail ที่ 2 MHz → ตรวจ: long wires, missing bypass cap, stray capacitance

### Physical Signoff Boundary

Mark the build physically signed off only after the real hardware has evidence
for all of these:

- Stable VCC/GND at the farthest chips.
- Clean reset and one-pulse single-step clock.
- No observed IBUS/DBUS bus fight during fetch, immediate, load, and store.
- ROM and RAM select lines never drive DBUS together.
- Golden Bring-up passes at 1 MHz.
- Burn-in holds the pass loop for 1 hour.
- Clock sweep result is recorded for this exact build.

Python simulation, Verilog tests, and the Components virtual checker are
required pre-checks, but they are not a replacement for these bench results.

---

## ขั้นที่ 13: IRQ (U31)

**ต่ออะไร**: U31 (74HC74), /IRQ pin, EI decode (U33 gate 2)

**v1.0: Polling IRQ** (ไม่มี hardware vector)

U31 ทำหน้าที่ latch สัญญาณ /IRQ เพื่อให้เห็น event ด้วย LED/probe. CPU core
ไม่ auto-read `IRQ_FF`, ไม่ auto-jump, และไม่มี vector fetch. ถ้าจะให้ software
poll จริง ต้อง map peripheral/IRQ status ผ่าน I/O slot เพิ่มเติม; สำหรับ v1.0
build แนะนำให้ poll input device โดยตรงผ่าน I/O slot:
```asm
; Main loop:
loop:
  ; ... do work ...
  ; poll input/status via I/O slot
  ; if event visible in software → branch to handler
  J loop

handler:
  ; DI is inert in v1.0; avoid EI unless software wants IE=1
  ; ... handle event ...
  EI                    ; re-enable
  J loop               ; return to main
```

**ทดสอบ**:
- [ ] EI → IE LED = ON
- [ ] กดปุ่ม /IRQ ค้าง LOW → IRQ_FF ยังไม่ latch จาก edge นี้
- [ ] ปล่อยปุ่มให้กลับ HIGH → IRQ_FF LED = ON (latch จับที่ rising edge)
- [ ] กด clock 100+ ครั้ง → IRQ_FF ยัง ON (ยืนยัน latch ไม่ decay)
- [ ] DI → IE LED unchanged (no v1.0 hardware clear path)
- [ ] Reset → ทั้ง IE และ IRQ_FF = OFF

> 📌 **IRQ_FF clear mechanism (v1.0)**: Only /RST clears IRQ_FF.
> DI has no v1.0 hardware effect — IRQ_FF stays latched until next reset.
>
> **Practical impact**: IRQ is a one-shot "event detected" flag in v1.0.
> Software can use EI to set IE, but only reset clears IE and IRQ_FF in the 36-package build.
> For games/BASIC: poll input directly via I/O slot instead of relying on IRQ_FF re-arm.
>
> **Future small fix**: Route /SLOT2 write to U31 /CLR2 → software clear via `SB $20`.
> Hardware acknowledge/vector is a separate, unfrozen design.

**LED**: 1 ดวงบน IE (U31-5), 1 ดวงบน IRQ_FF (U31-9)

**FUTURE ONLY - DO NOT WIRE IN THE BASELINE**: hardware vector is not part of
v1.0. It requires PC mux, /PC_LD control, IRQ_ack, and clear logic. If this
is connected during the student build, the baseline tests and wiring guide no longer
match the hardware.

---

## ขั้นที่ 14: RV8-Bus (40-pin connector)

**ต่ออะไร**: IDC 40-pin socket, route สัญญาณจาก CPU board ออก bus

**สายที่ต้อง route ไป bus connector:**
```
Pin 1-16:  A[0:15] จาก ABUS (U15/U16/U29/U30 outputs)
Pin 17-24: D[0:7] จาก DBUS
Pin 25:    CLK จาก oscillator
Pin 26:    /RST จาก reset circuit
Pin 27:    /WR = /AC_BUF (U26-8)
Pin 28:    /RD (NOT(T2) — informational only, not used by CPU core. For peripheral timing/debug.)
Pin 29:    /IRQ ← input จาก peripheral (ต่อ U31-11)
Pin 30:    /SLOT1 ← address decode ($FF1x)
Pin 31:    /SLOT2 ← address decode ($FF2x)
Pin 32:    T2 (U8-5)
Pin 33:    A15 duplicate จาก ABUS15 (U30-12)
Pin 34-38: reserved / NC
Pin 39:    VCC (+5V)
Pin 40:    GND
```

**ทดสอบ**:
- [ ] ต่อ Programmer board ผ่าน ribbon cable
- [ ] `python3 ../Programmer/tools/rv8flash.py -c` → "Connected"
- [ ] Flash test ROM → verify ด้วย `python3 ../Programmer/tools/rv8flash.py verify test.bin --base 0x0000`
- [ ] CLK บน bus pin 25 = oscillator (วัดด้วย probe)
- [ ] /RST บน bus pin 26 = HIGH ตอนปกติ, LOW ตอนกด reset
- [ ] /WR บน bus pin 27 = pulse LOW เฉพาะตอน STORE
- [ ] /IRQ bus pin 29 → กดแล้วปล่อยปุ่ม → IRQ_FF LED ON (software polls, no auto-jump in v1.0)

**LED**: ดูบน bus connector: CLK (กระพริบ), /WR (pulse ตอน store)

**ทดสอบ I/O Slot:**
```asm
; Test SLOT1 ($FF10):
SETPG $FF       ; page = $FF
LI $42          ; AC = $42
SB $10          ; write to $FF10 → /SLOT1 should go LOW
```
- [ ] /SLOT1 (pin 30) goes LOW during SB $10 at page $FF

---

## Debug Tips

| อาการ | สาเหตุที่พบบ่อย |
|---|---|
| LED ไม่ติดเลย | VCC/GND ไม่ถึง, IC ใส่กลับด้าน |
| PC ไม่นับ | ENP/ENT ไม่ HIGH, clock ไม่ถึง |
| DBUS = $00 ตลอด | ROM /CE ไม่ active, /OE/WR_DIR ผิด |
| AC ไม่เปลี่ยน | ACC_CLK ไม่ pulse, AC_WR=0 |
| Jump ไม่ทำงาน | /PC_LD ค้าง HIGH, Page Reg ผิด |
| RAM write ไม่ได้ | /WE ไม่ pulse, A15 ไม่ใช่ 1 |
| Ring counter ค้าง | Inverter ต่อผิด, /CLR ค้าง LOW |
| ผลไม่คงที่ (intermittent) | Floating HC input, loose wire, power noise |

---

## Floating Input Audit (ทำหลังต่อครบทุกชิป)

74HC ขาที่ไม่ได้ต่อ = ลอย = อาจ oscillate = intermittent failure

**ตรวจก่อนเปิดเครื่อง:**
- [ ] NAND/OR/XOR unused inputs → ต่อ VCC หรือ GND (ดูจาก wiring guide)
- [ ] Mux unused data inputs → ต่อ GND (ไม่กระทบถ้า SEL ไม่เลือก แต่ป้องกันเผื่อ)
- [ ] 74HC161 unused D-inputs (ถ้ามี) → ต่อ GND
- [ ] ตรวจ U24, U25, U26, U27, U28, U33 ว่า gate ที่ไม่ได้ใช้ → input ต่อ VCC/GND

> 📌 อาการ floating input: ทำงานถูก 90% ของเวลา แต่พลาดเป็นระยะ ๆ
> ถ้า single-step ผ่านแต่ full-speed fail → สงสัย floating input ก่อน

---

## Trace Sheet (สำหรับ Single-step Debug)

พิมพ์ตารางนี้แล้วกรอกด้วยมือขณะกดปุ่ม clock:

```
| Clock | Phase | PC   | IRH | IRL | AC | Z | PG | DP | Notes |
|-------|-------|------|-----|-----|----|----|----|----|-------|
|   1   | T0    |      |     |     |    |    |    |    |       |
|   2   | T1    |      |     |     |    |    |    |    |       |
|   3   | T2    |      |     |     |    |    |    |    |       |
|   4   | T0    |      |     |     |    |    |    |    |       |
|   5   | T1    |      |     |     |    |    |    |    |       |
|   6   | T2    |      |     |     |    |    |    |    |       |
|   7   | T0    |      |     |     |    |    |    |    |       |
|   8   | T1    |      |     |     |    |    |    |    |       |
|   9   | T2    |      |     |     |    |    |    |    |       |
|  10   | T0    |      |     |     |    |    |    |    |       |
|  11   | T1    |      |     |     |    |    |    |    |       |
|  12   | T2    |      |     |     |    |    |    |    |       |
```

> เทียบกับ Golden Trace ใน `02_instruction_trace.md` — ถ้าไม่ตรง = bug

---

## LED Probe Board (แนะนำ)

ทำบอร์ด LED 8 ดวง + header สำหรับเสียบดู bus:

```
[GND]─┬─[330Ω]─[LED]─[pin0]
      ├─[330Ω]─[LED]─[pin1]
      ├─[330Ω]─[LED]─[pin2]
      ├─[330Ω]─[LED]─[pin3]
      ├─[330Ω]─[LED]─[pin4]
      ├─[330Ω]─[LED]─[pin5]
      ├─[330Ω]─[LED]─[pin6]
      └─[330Ω]─[LED]─[pin7]
```

ใช้เสียบดูที่ไหนก็ได้: DBUS, IBUS, ABUS, AC, PC, IR...

---

## Checklist สรุป

| # | โมดูล | ชิป | LED ดูตรงไหน | ผ่าน? |
|:-:|---|-----|---|:-----:|
| 1 | Power + Clock | - | CLK | ☐ |
| 2 | Ring Counter | U8, U24 | T0,T1,T2 | ☐ |
| 3 | PC Counter | U1-U4 | PC[7:0] | ☐ |
| 4 | Address Mux | U15-U16,U29-U30 | ABUS | ☐ |
| 5 | ROM | AT28C256 | DBUS | ☐ |
| 6 | Bus + IR | U7, U5, U6 | IBUS / IR_HIGH | ☐ |
| 7 | ALU + AC | U10-U13,U17-U20,U9 | AC | ☐ |
| 8 | Z Flag | U21, U22 | Z | ☐ |
| 9 | Jump Logic | U24-U28 | /PC_LD | ☐ |
| 10 | Page Register | U23 | PG[7:0] | ☐ |
| 11 | RAM + Data Page | 62256, U32, U33 | DBUS, DP[7:0] | ☐ |
| 12 | Full System | all | AC, PC, Z | ☐ |
| 13 | IRQ | U31 | IE, IRQ_FF | ☐ |
| 14 | RV8-Bus | 40-pin IDC | CLK, /WR, /SLOT | ☐ |

---

## Appendix: Golden Bring-up Program

One program tests ~80% of the CPU. If this passes, only edge cases remain.

```asm
; RV8-GR Golden Bring-up — flash at $0000
; Tests: DP, PG, LI, SB, LB, SUBI, Z flag, BEQ, J, RAM, ROM

    SETDP $80       ; $0000: $40 $80 — DP = RAM page
    SETPG $00       ; $0002: $20 $00 — PG = page 0
    LI $55          ; $0004: $30 $55 — AC = $55
    SB $00          ; $0006: $04 $00 — RAM[$8000] = $55
    LB $00          ; $0008: $38 $00 — AC = RAM[$8000] = $55
    SUBI $55        ; $000A: $90 $55 — AC = $00, Z = 1
    BEQ pass        ; $000C: $02 $10 — Z=1 → jump to $0010
    J fail          ; $000E: $01 $12 — should not reach

pass:
    J pass          ; $0010: $01 $10 — ✅ success (LED: PC=$0010 loop)

fail:
    J fail          ; $0012: $01 $12 — ❌ failure (LED: PC=$0012 loop)
```

**ROM image (20 bytes):**
```
0000: 40 80 20 00 30 55 04 00 38 00 90 55 02 10 01 12
0010: 01 10 01 12
```

**Expected result**: PC halts at $0010 (pass). If PC=$0012 → one of the tested functions failed.

> 📌 Verified against ISA Freeze v1.0 (absolute addressing, BEQ target = low byte of {PG, operand}).

> 📌 IRQ_FF is architectural state. In v1.0 it clears only by /RST. It does NOT auto-clear like typical MCU interrupt flags.

**What this tests:**

| Function | Instruction | Pass if |
|---|---|---|
| Data Page | SETDP $80 | SB/LB access RAM |
| Page Reg | SETPG $00 | BEQ/J land correctly |
| Load Immediate | LI $55 | AC = $55 |
| Store | SB $00 | RAM[$8000] written |
| Load | LB $00 | AC reads back $55 |
| Subtract | SUBI $55 | AC = $00 |
| Z flag | — | Z = 1 after AC=0 |
| Branch | BEQ pass | Taken when Z=1 |
| Jump | J pass | PC = $0010 |
| RAM | SB + LB | Read = Write |

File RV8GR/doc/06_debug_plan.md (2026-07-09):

# RV8-GR — Debug Plan (Physical Build)

**สร้างทีละโมดูล ทดสอบทุกขั้น ไม่ต้องรีบ ใช้ LED + single-step clock**

---

## อุปกรณ์ Debug

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

---

## Baseline Boundary

Debug only the RV8GR baseline first:

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

If the CPU jumps when `/IRQ` is asserted, that is a wiring mistake for v2.

---

## Probe Point Map

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

---

## Clock Options

```
Mode 1: Single-step (debug)
  Button → debounce (RC + Schmitt) → CLK
  กดปุ่ม 1 ครั้ง = 1 clock = 1 state change

Mode 2: Low speed (1-10 Hz)
  555 timer → CLK
  ดู LED กระพริบทีละ state

Mode 3: Full speed
  Crystal oscillator → CLK
  1 MHz = official target (ปลอดภัย, margin >700ns)
  2 MHz = achievable on short-wire breadboard
  5 MHz = PCB only (experimental, ~0ns margin)
```

---

## ขั้นที่ 0: Boot Sequence Sanity Check

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

**Reset state ที่ hardware รับประกัน:**
- PC = $0000
- T-state = T0
- IE = 0, IRQ_FF = 0

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

**Test ROM (flash ไว้ที่ $0000):**
```asm
SETDP $80       ; DP = $80
SETPG $00       ; PG = $00
LI $00          ; AC = $00, Z = 1
J $06           ; loop here (HLT macro = J self)
```

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

---

## ขั้นที่ 1: Power + Clock + Reset

**ต่ออะไร**: 5V supply, clock (button), reset (RC), LED 1 ดวงบน CLK

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

### Power Integrity Test (ทำหลังต่อชิปครบ ก่อน full-speed)

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

### Reset Recovery Test

- [ ] รันโปรแกรม loop ที่ 1 MHz (เช่น LI $55, ADDI $01, J $00)
- [ ] กด RESET ขณะรัน → PC ต้องกลับ $0000, T-state=T0 ทุกครั้ง
- [ ] ลองกด RESET 10 ครั้งที่จังหวะต่างกัน → ต้องผ่านทุกครั้ง

**LED**: 1 ดวงบน CLK output

### Clock Integrity Check (ก่อนต่อ Ring Counter)

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

---

## ขั้นที่ 2: Ring Counter (U8 + U24 inverters)

**ต่ออะไร**: U8 (74HC164), U24 pin 1-4 (inverters 2 ตัว)

**ทดสอบ**:
- [ ] Reset → T0=1, T1=0, T2=0
- [ ] Clock 1 → T0=0, T1=1, T2=0
- [ ] Clock 2 → T0=0, T1=0, T2=1
- [ ] Clock 3 → T0=1, T1=0, T2=0 (wrap around)
- [ ] ทำซ้ำ 10 รอบ ไม่ skip ไม่ค้าง

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

**Illegal State Recovery** (ตรวจว่า ring counter self-corrects):
- [ ] ถอด /RST ชั่วคราว แล้วจ่าย noise เข้า U8 → state อาจเพี้ยน
- [ ] ต่อ /RST กลับ → กด reset → ต้องกลับ T0=1,T1=0,T2=0 ทันที
- [ ] ถ้า power-up ได้ state 000 (all-zero) → feedback NOT(Q0)&NOT(Q1) จะ inject 1 → recover ภายใน 3 clocks

**Ring Counter State Matrix** (74HC164 behavior):

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

> 📌 All illegal states self-correct within 3 clocks — no hardware fix needed.
> /RST forces immediate recovery to T0 (001).

**LED**: 3 ดวงบน T0 (U8-3), T1 (U8-4), T2 (U8-5)

```
กดปุ่ม:  LED pattern:
  1       T0=on  T1=off T2=off
  2       T0=off T1=on  T2=off
  3       T0=off T1=off T2=on
  4       T0=on  T1=off T2=off  ← ถูกต้อง!
```

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

---

## ขั้นที่ 3: PC Counter (U1-U4)

**ต่ออะไร**: U1-U4 (74HC161 ×4), ต่อ CLK, /RST, cascade (RCO)

**ก่อนต่อ memory**: ยังไม่ต่อ ROM/RAM — ทดสอบ counter เปล่า

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

**LED**: 8 ดวงบน PC[7:0] (U1 QA-QD + U2 QA-QD)

```
Reset:    00000000
Clock 1:  00000001
Clock 2:  00000010
...
Clock 15: 00001111
Clock 16: 00010000  ← U2 เริ่มนับ (cascade ทำงาน!)
```

**สำคัญ**: ต่อ PC_INC (U25-6) = VCC ชั่วคราว เพื่อให้นับตลอด

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

---

## ขั้นที่ 4: Address Mux (U15-U16, U29-U30)

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

**LED**: 8 ดวงบน ABUS A[7:0]

---

## ขั้นที่ 5: ROM (AT28C256)

**ต่ออะไร**: ROM, ต่อ ABUS → ROM A[14:0], /CE ← A15, /OE ← WR_DIR (U28-8)

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

**เตรียม ROM**: Flash test pattern ด้วย Programmer board:
```bash
python3 ../Programmer/tools/rv8flash.py program test_bytes.bin --base 0x0000
```

```
$0000: $30  (LI opcode)
$0001: $42  (operand)
$0002: $01  (J opcode)
$0003: $00  (jump to $00 → loop)
```

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

**LED**: 8 ดวงบน DBUS D[7:0]

```
กด clock (PC นับ):
  $0000 → LED = 00110000 ($30)  ✓
  $0001 → LED = 01000010 ($42)  ✓
```

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

---

## ขั้นที่ 6: Bus Buffer + IR (U7, U5, U6)

**ต่ออะไร**: U7 (245), U5 (IR_HIGH), U6 (IR_LOW), ROM /OE safety via WR_DIR

### Bus Ownership Verification (ตรวจก่อนต่อ ALU)

ใช้ LED probe ตรวจ IBUS driver ทีละ phase:

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

- [ ] Single-step ตรวจว่า IBUS driver ไม่ทับกัน (ทีละตัวเท่านั้น)

### Bus Float Test (ตรวจ IBUS ไม่ลอย)

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

### DBUS Float Test

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

### Bus Fight Detection (กระแสผิดปกติ)

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

**สำคัญ**: U7-19 (/OE) ต้องต่อจาก **U24-12** (BUF_OE_N)
```
U24-13 ← U26-3 (/IRL_OE)
U24-12 → U7-19 (BUF_OE_N)
U28-8  → U7-1 (WR_DIR) and ROM /OE
```

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

**LED**: 8 ดวงบน IBUS (U7 B-side) หรือ U5 Q outputs

```
After T0: U5-15(AC_WR)=1, U5-14(MUX)=1 → ถูกต้องสำหรับ LI!
After T1: U6-19(IRL0)=0, U6-18(IRL1)=1, U6-17(IRL2)=0... = $42
```

---

## ขั้นที่ 7: ALU + AC (U10-U13, U19-U20, U17-U18, U9)

**ต่ออะไร**: XOR gates, adder, muxes, accumulator

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

**LED**: 8 ดวงบน AC (U9 Q outputs)

```
Before T2: AC = unknown (74HC574 has no /CLR)
After T2:  AC = $42 ← LI $42 ทำงานแล้ว!
```

**ทดสอบ ADDI $05** (flash ROM: $0004=$10, $0005=$05):
- [ ] After execute: AC = $42 + $05 = $47

---

## ขั้นที่ 8: Z Flag (U21, U22)

**ต่ออะไร**: U22 (688), U21 (74)

**ทดสอบ**:
- [ ] AC=$42 → Z LED = OFF (AC ≠ 0)
- [ ] SUBI $42 → AC=$00 → Z LED = ON

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

**LED**: 1 ดวงบน Z_flag (U21-5)

---

## ขั้นที่ 9: Branch/Jump Logic (U24-U28)

**ต่ออะไร**: Control logic gates

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

**ทดสอบ BEQ (Z=1)**:
- [ ] Set AC=0 (Z=1), BEQ $20
- [ ] After T2: PC = $0020

**LED**: 1 ดวงบน /PC_LD (U26-11)

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

---

## ขั้นที่ 10: Page Register + 16-bit Jump (U23)

**ต่ออะไร**: U23 (574)

**ทดสอบ**:
- [ ] SETPG $90 → PG LED = $90
- [ ] J $00 → PC = $9000

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

**LED**: 8 ดวงบน Page Reg (U23 Q outputs)

---

## ขั้นที่ 11: RAM (62256) + Data Page (U32)

**ต่ออะไร**: RAM, U32 (74HC574), ต่อ ABUS, DBUS, /CE ← /A15 (U24-6), /WE ← /AC_BUF

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

**ทดสอบ ROM read (SETDP $00)**:
- [ ] SETDP $00, LB $00 → AC = ROM[$0000] = first opcode

> 📌 **Architectural Contract**: LB can read ROM (DP < $80).
> SB to ROM address is ignored by ROM protection. ROM `/WE` is on `/WR` for
> programmer support, but CPU stores do not perform the EEPROM/flash unlock
> sequence.

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

**LED**: 8 ดวงบน U32 Q outputs (ดู data page value)

---

## ขั้นที่ 12: Full System Test

**ต่อครบทุกชิป** แล้วรัน test ROM:

```asm
; Test ROM ($0000):
LI $10        ; AC=$10
ADDI $05      ; AC=$15
SUBI $15      ; AC=$00, Z=1
BEQ pass      ; should jump
J fail        ; should not reach
pass: J pass  ; success! (PC=$000A loop)
fail: J fail  ; failure  (PC=$000C loop)
```

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

### Walking-1 Address Test (ROM)

Flash ROM with known pattern at power-of-2 addresses:

```
$0001: $01,  $0002: $02,  $0004: $04,  $0008: $08
$0010: $10,  $0020: $20,  $0040: $40,  $0080: $80
```

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

### RAM March Test (ตรวจ address line shorts)

```asm
; Write unique value to each address, then read back:
SETDP $80
LI $01 → SB $00    ; RAM[$8000] = $01
LI $02 → SB $01    ; RAM[$8001] = $02
LI $04 → SB $02    ; RAM[$8002] = $04
LI $08 → SB $03    ; RAM[$8003] = $08
; ... then read back each:
LB $00 → should be $01
LB $01 → should be $02
; etc.
```

- [ ] ถ้า LB $02 ได้ $08 → A1/A2 short ใน RAM address wiring

### Clock Sweep (Timing Qualification)

รัน Golden Bring-up ที่ความถี่ต่าง ๆ บันทึกผล:

| MHz | Result | Notes |
|:---:|:---:|---|
| 1 | | Official target |
| 2 | | Breadboard achievable |
| 3 | | |
| 4 | | |
| 5 | | PCB only (experimental) |

- [ ] บันทึก max frequency ที่ pass → เป็น spec ของเครื่องตัวนี้
- [ ] ถ้า fail ที่ 2 MHz → ตรวจ: long wires, missing bypass cap, stray capacitance

---

## ขั้นที่ 13: IRQ (U31)

**ต่ออะไร**: U31 (74HC74), /IRQ pin, EI decode (U33 gate 2)

**v1.0: Polling IRQ** (ไม่มี hardware vector)

U31 ทำหน้าที่ latch สัญญาณ /IRQ — software poll แล้ว branch เอง:
```asm
; Main loop:
loop:
  ; ... do work ...
  ; poll IRQ flag (read via I/O slot or test)
  ; if IRQ_FF set → branch to handler
  J loop

handler:
  ; DI is inert in v1.0; avoid EI unless software wants IE=1
  ; ... handle event ...
  EI                    ; re-enable
  J loop               ; return to main
```

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

**LED**: 1 ดวงบน IE (U31-5), 1 ดวงบน IRQ_FF (U31-9)

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

---

## ขั้นที่ 14: RV8-Bus (40-pin connector)

**ต่ออะไร**: IDC 40-pin socket, route สัญญาณจาก CPU board ออก bus

**สายที่ต้อง route ไป bus connector:**
```
Pin 1-16:  A[0:15] จาก ABUS (U15/U16/U29/U30 outputs)
Pin 17-24: D[0:7] จาก DBUS
Pin 25:    CLK จาก oscillator
Pin 26:    /RST จาก reset circuit
Pin 27:    /WR = /AC_BUF (U26-8)
Pin 28:    /RD (NOT(T2) — informational only, not used by CPU core. For peripheral timing/debug.)
Pin 29:    /IRQ ← input จาก peripheral (ต่อ U31-11)
Pin 30:    /SLOT1 ← address decode ($FF1x)
Pin 31:    /SLOT2 ← address decode ($FF2x)
Pin 32:    T2 (U8-5)
Pin 33:    A15 duplicate จาก ABUS15 (U30-12)
Pin 34-38: reserved / NC
Pin 39:    VCC (+5V)
Pin 40:    GND
```

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

**LED**: ดูบน bus connector: CLK (กระพริบ), /WR (pulse ตอน store)

**ทดสอบ I/O Slot:**
```asm
; Test SLOT1 ($FF10):
SETPG $FF       ; page = $FF
LI $42          ; AC = $42
SB $10          ; write to $FF10 → /SLOT1 should go LOW
```
- [ ] /SLOT1 (pin 30) goes LOW during SB $10 at page $FF

---

## Debug Tips

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

---

## Floating Input Audit (ทำหลังต่อครบทุกชิป)

74HC ขาที่ไม่ได้ต่อ = ลอย = อาจ oscillate = intermittent failure

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

---

## Trace Sheet (สำหรับ Single-step Debug)

พิมพ์ตารางนี้แล้วกรอกด้วยมือขณะกดปุ่ม clock:

```
| Clock | Phase | PC   | IRH | IRL | AC | Z | PG | DP | Notes |
|-------|-------|------|-----|-----|----|----|----|----|-------|
|   1   | T0    |      |     |     |    |    |    |    |       |
|   2   | T1    |      |     |     |    |    |    |    |       |
|   3   | T2    |      |     |     |    |    |    |    |       |
|   4   | T0    |      |     |     |    |    |    |    |       |
|   5   | T1    |      |     |     |    |    |    |    |       |
|   6   | T2    |      |     |     |    |    |    |    |       |
|   7   | T0    |      |     |     |    |    |    |    |       |
|   8   | T1    |      |     |     |    |    |    |    |       |
|   9   | T2    |      |     |     |    |    |    |    |       |
|  10   | T0    |      |     |     |    |    |    |    |       |
|  11   | T1    |      |     |     |    |    |    |    |       |
|  12   | T2    |      |     |     |    |    |    |    |       |
```

> เทียบกับ Golden Trace ใน `03_instruction_trace.md` — ถ้าไม่ตรง = bug

---

## LED Probe Board (แนะนำ)

ทำบอร์ด LED 8 ดวง + header สำหรับเสียบดู bus:

```
[GND]─┬─[330Ω]─[LED]─[pin0]
      ├─[330Ω]─[LED]─[pin1]
      ├─[330Ω]─[LED]─[pin2]
      ├─[330Ω]─[LED]─[pin3]
      ├─[330Ω]─[LED]─[pin4]
      ├─[330Ω]─[LED]─[pin5]
      ├─[330Ω]─[LED]─[pin6]
      └─[330Ω]─[LED]─[pin7]
```

ใช้เสียบดูที่ไหนก็ได้: DBUS, IBUS, ABUS, AC, PC, IR...

---

## Checklist สรุป

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

---

## Appendix: Golden Bring-up Program

One program tests ~80% of the CPU. If this passes, only edge cases remain.

```asm
; RV8-GR Golden Bring-up — flash at $0000
; Tests: DP, PG, LI, SB, LB, SUBI, Z flag, BEQ, J, RAM, ROM

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

pass:
    J pass          ; $0010: $01 $10 — ✅ success (LED: PC=$0010 loop)

fail:
    J fail          ; $0012: $01 $12 — ❌ failure (LED: PC=$0012 loop)
```

**ROM image (20 bytes):**
```
0000: 40 80 20 00 30 55 04 00 38 00 90 55 02 10 01 12
0010: 01 10 01 12
```

**Expected result**: PC halts at $0010 (pass). If PC=$0012 → one of the tested functions failed.

> 📌 Verified against ISA Freeze v1.0 (absolute addressing, BEQ target = low byte of {PG, operand}).

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

**What this tests:**

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

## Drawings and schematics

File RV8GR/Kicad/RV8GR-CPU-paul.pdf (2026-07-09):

# RV8GR CPU 34 logic chips + ROM + RAM = 36 packages

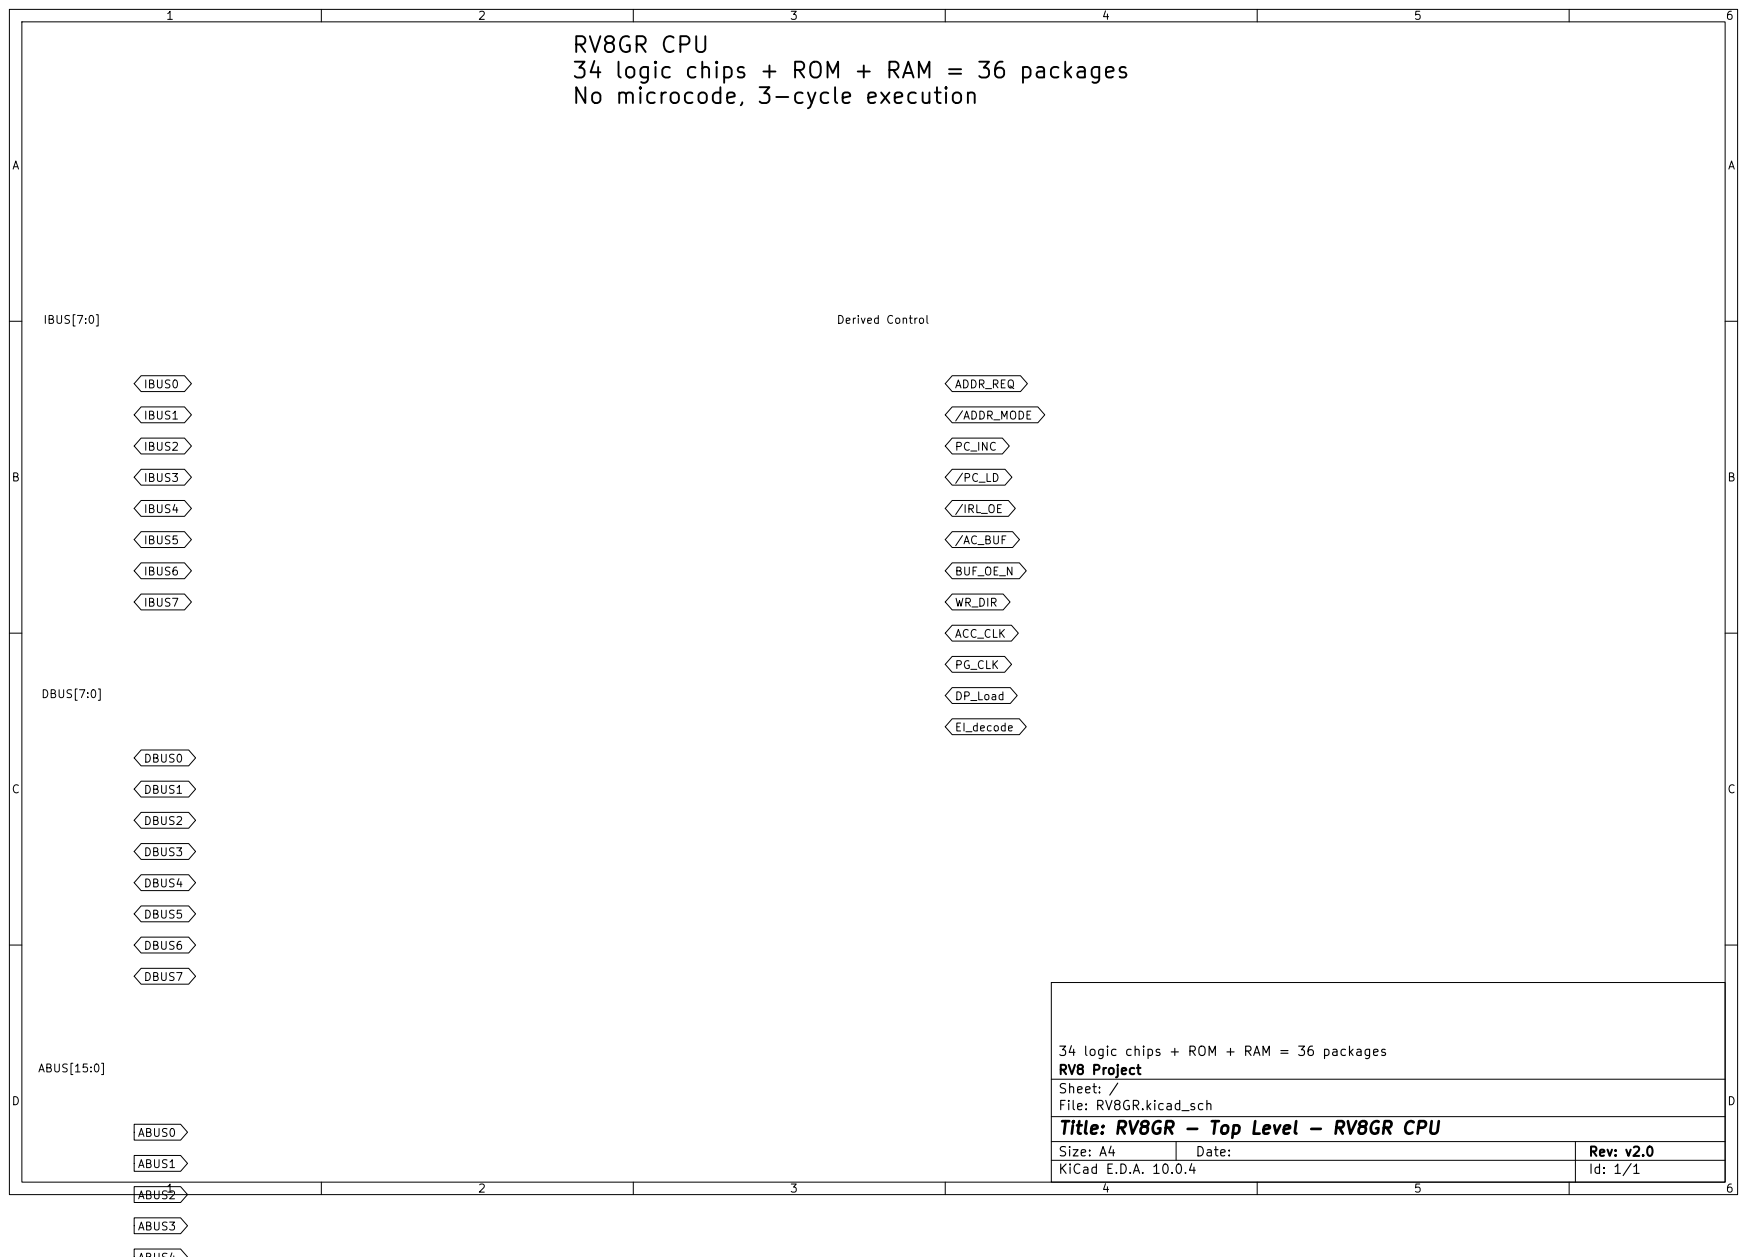
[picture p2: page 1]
D Date:; Size: A4; Rev: v2.0; ABUS0; ABUS1; ABUS2; ABUS3; ABUS4; ABUS12 DBUS7; DBUS4; ADDR_REQ; /ADDR_MODE PC_INC; IBUS3; IBUS4; IBUS5; IBUS6 IBUS7 DBUS0 DBUS1 DBUS2 DBUS3; EI_decode DBUS5; IBUS0; DP_Load PG_CLK; ACC_CLK WR_DIR; BUF_OE_N; /AC_BUF; /IRL_OE; IBUS2; IBUS1 DBUS6 DBUS[7:0]; Derived Control; IBUS[7:0]; ABUS[15:0]

No microcode, 3-cycle execution

34 logic chips + ROM + RAM = 36 packages
RV8 Project
Sheet: /
File: RV8GR.kicad_sch
Title: RV8GR - Top Level - RV8GR CPU
KiCad E.D.A. 10.0.4

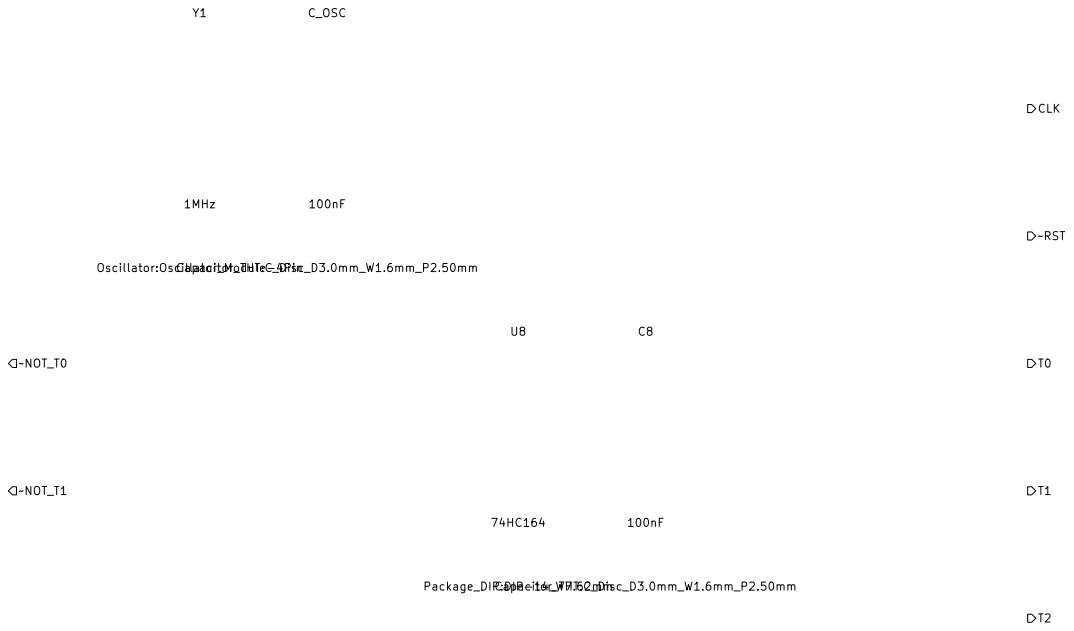
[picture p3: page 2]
D Date: Title: RV8GR - CLK_RST Module; File: CLK_RST.kicad_sch; Sheet: /; CLK; ~RST; ~NOT_T0; ~NOT_T1; 74HC164 Package_DIP:DIP-14_W7.62mm; 100nF Capacitor_THT:C_Disc_D3.0mm_W1.6mm_P2.50mm; 1MHz Oscillator:Oscillator_Module-4Pin C_OSC

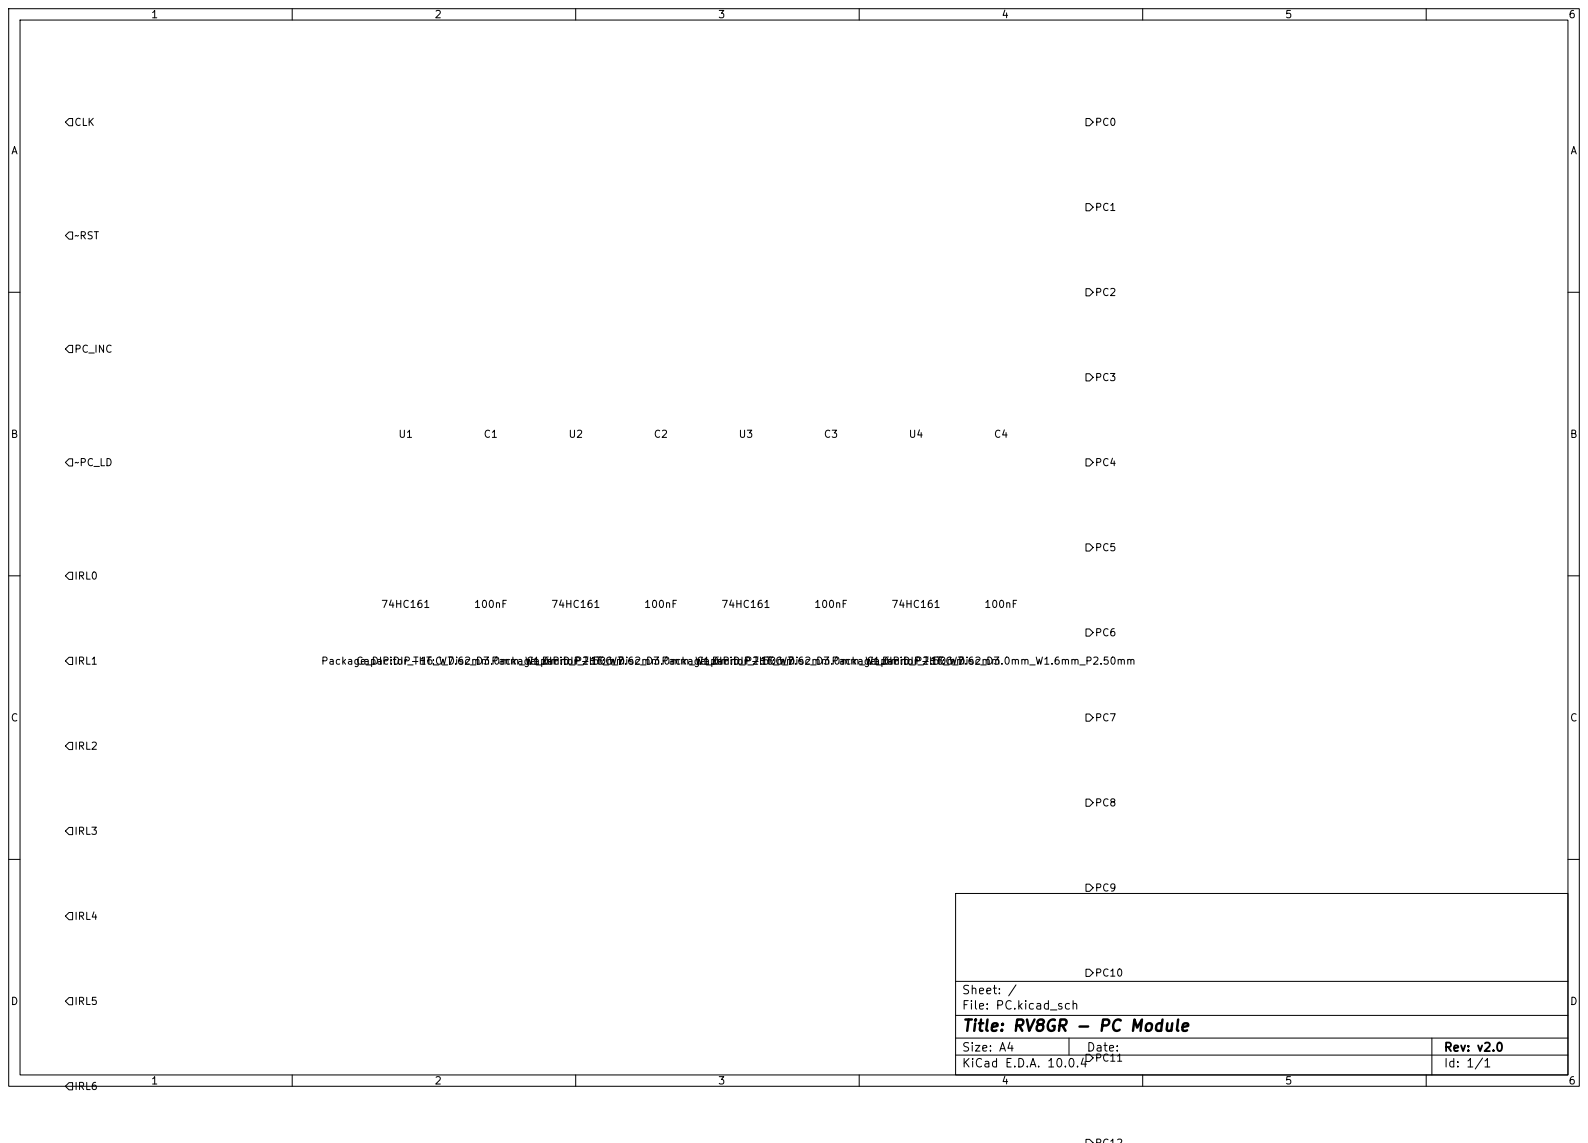
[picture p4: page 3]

# DBUS0 DBUS1 DBUS2 DBUS3

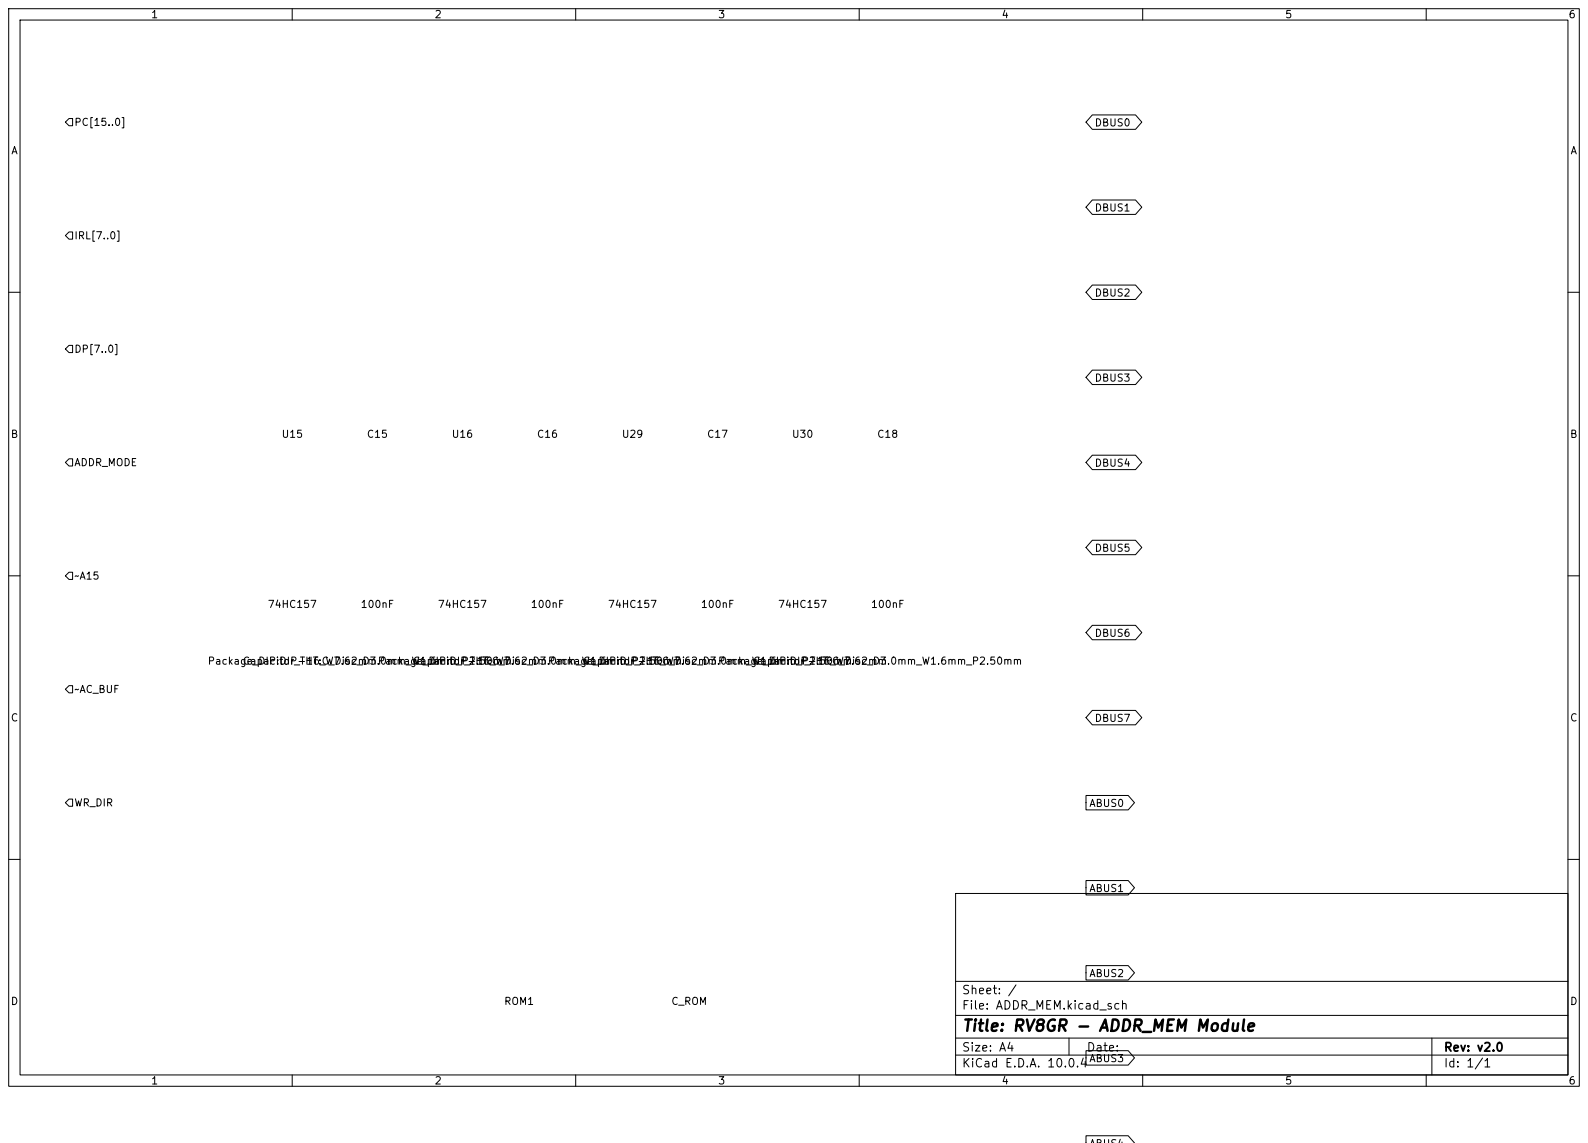
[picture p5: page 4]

# IBUS1 DBUS3

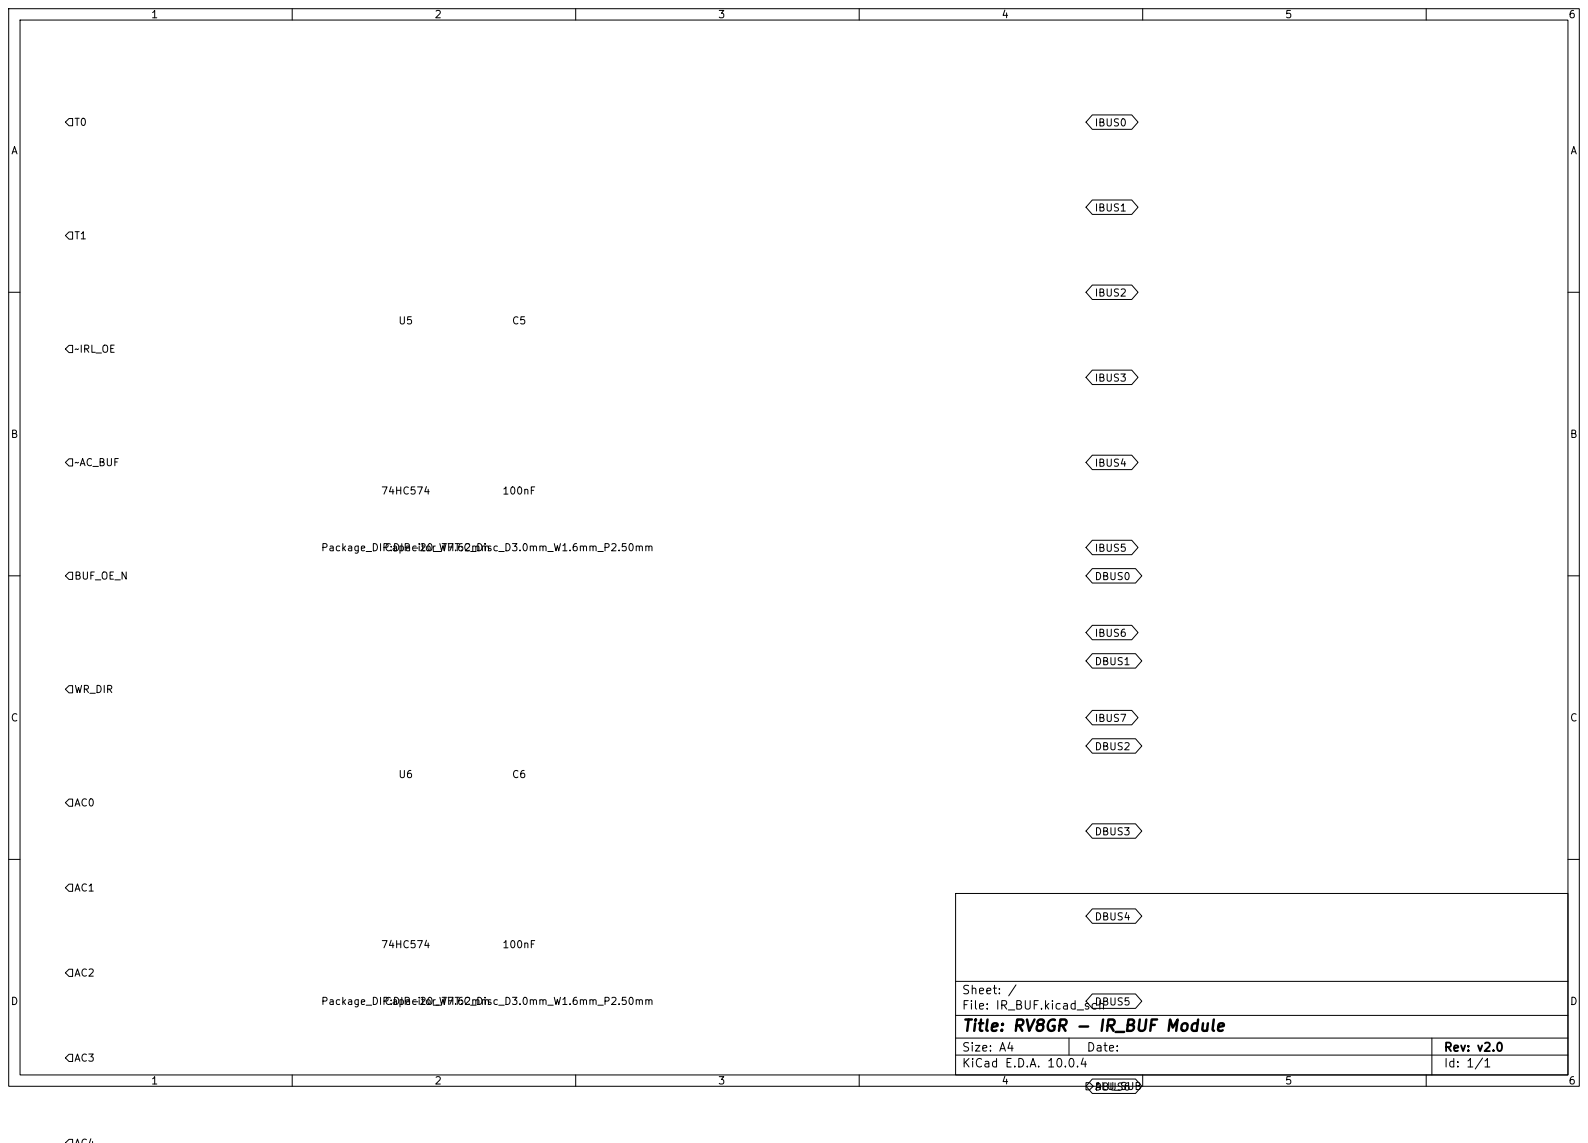
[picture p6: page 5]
D Date: Title: RV8GR - IR_BUF Module; File: IR_BUF.kicad_sch; Sheet: /; ALU_SUB; ~IRL_OE; ~AC_BUF BUF_OE_N WR_DIR; IBUS2 DBUS5 DBUS6 DBUS7 DBUS4; IBUS0; IBUS3; IBUS4; IBUS5 IBUS6 DBUS0 DBUS1; IBUS7 DBUS2 U5; 74HC574 Package_DIP:DIP-20_W7.62mm; 100nF Capacitor_THT:C_Disc_D3.0mm_W1.6mm_P2.50mm

# IBUS[7..0] XOR_MODE MUX_SEL ACC_CLK

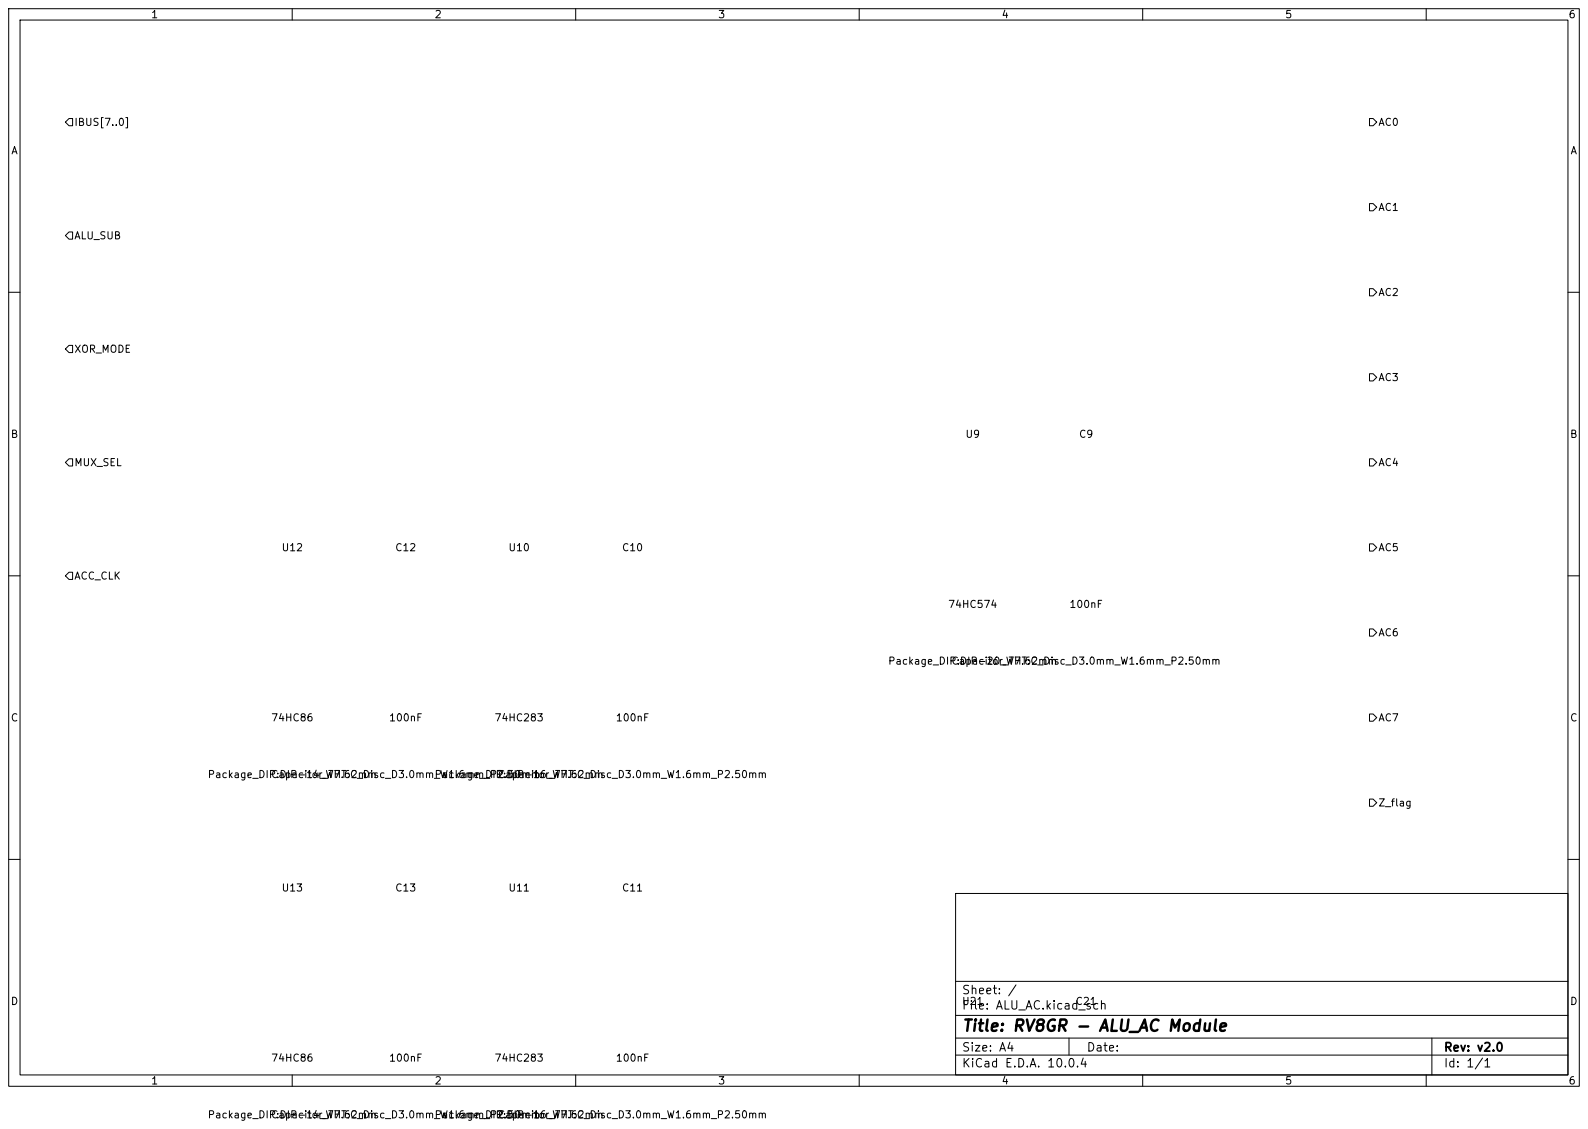
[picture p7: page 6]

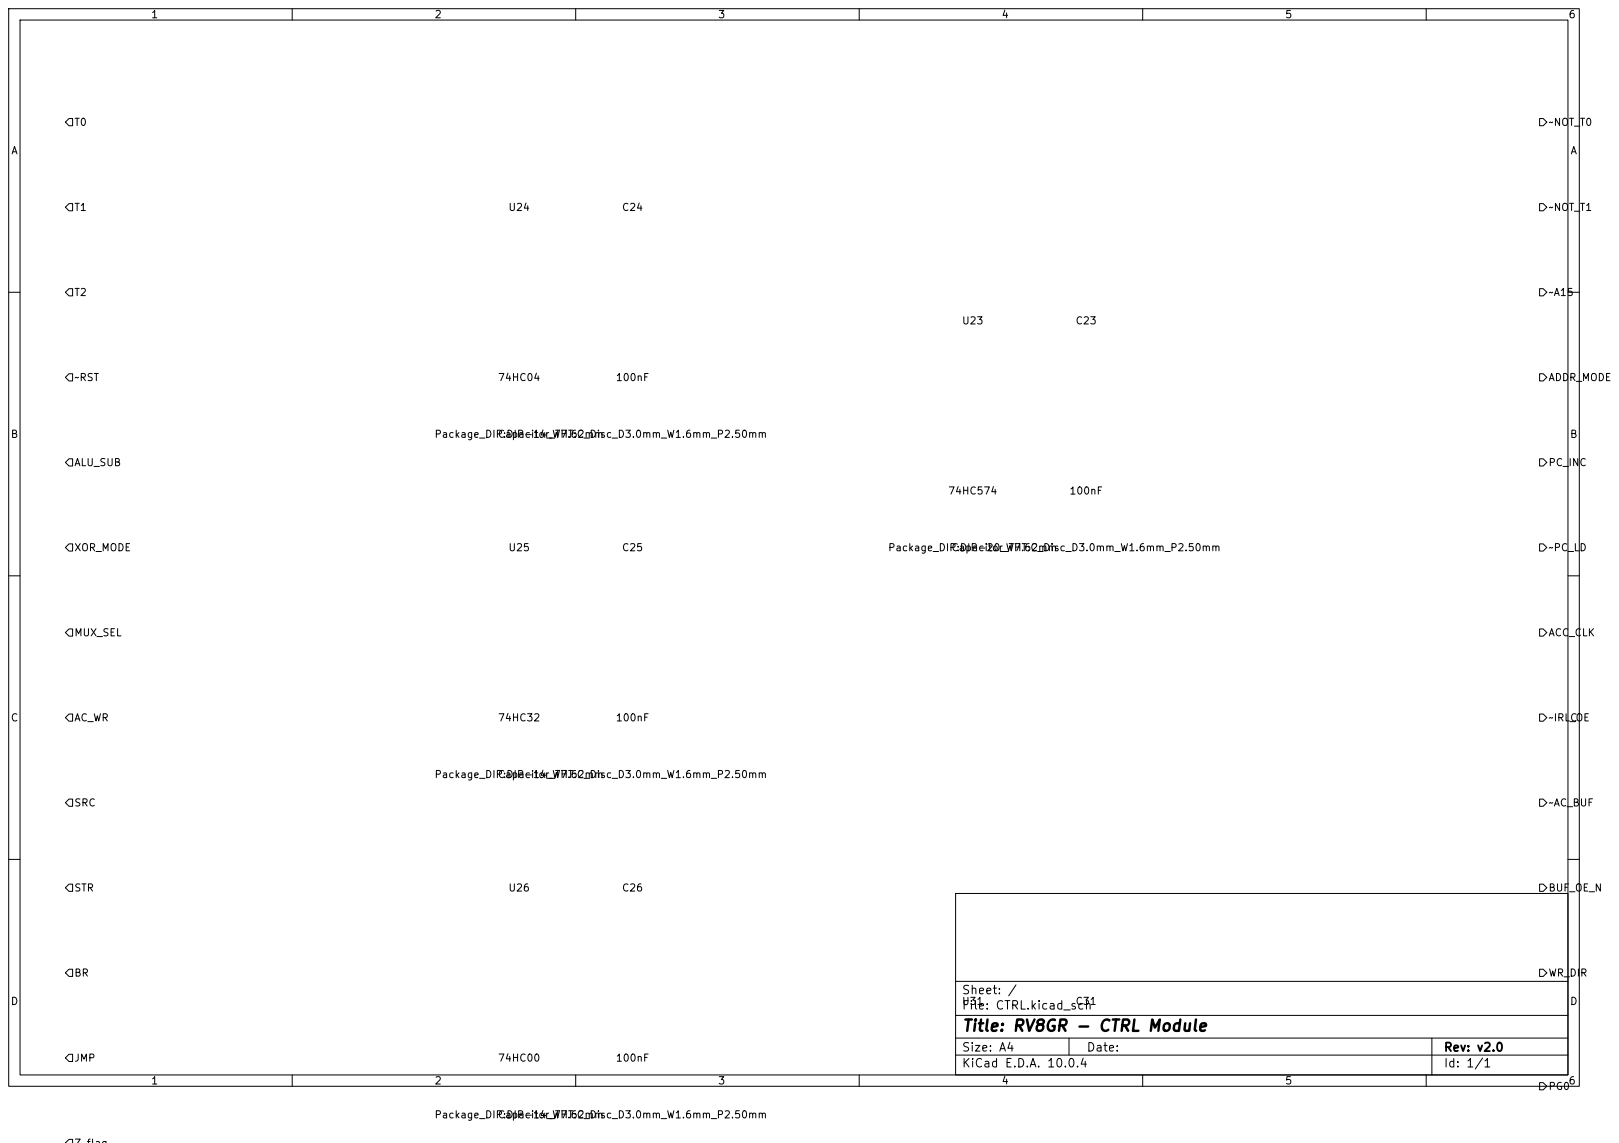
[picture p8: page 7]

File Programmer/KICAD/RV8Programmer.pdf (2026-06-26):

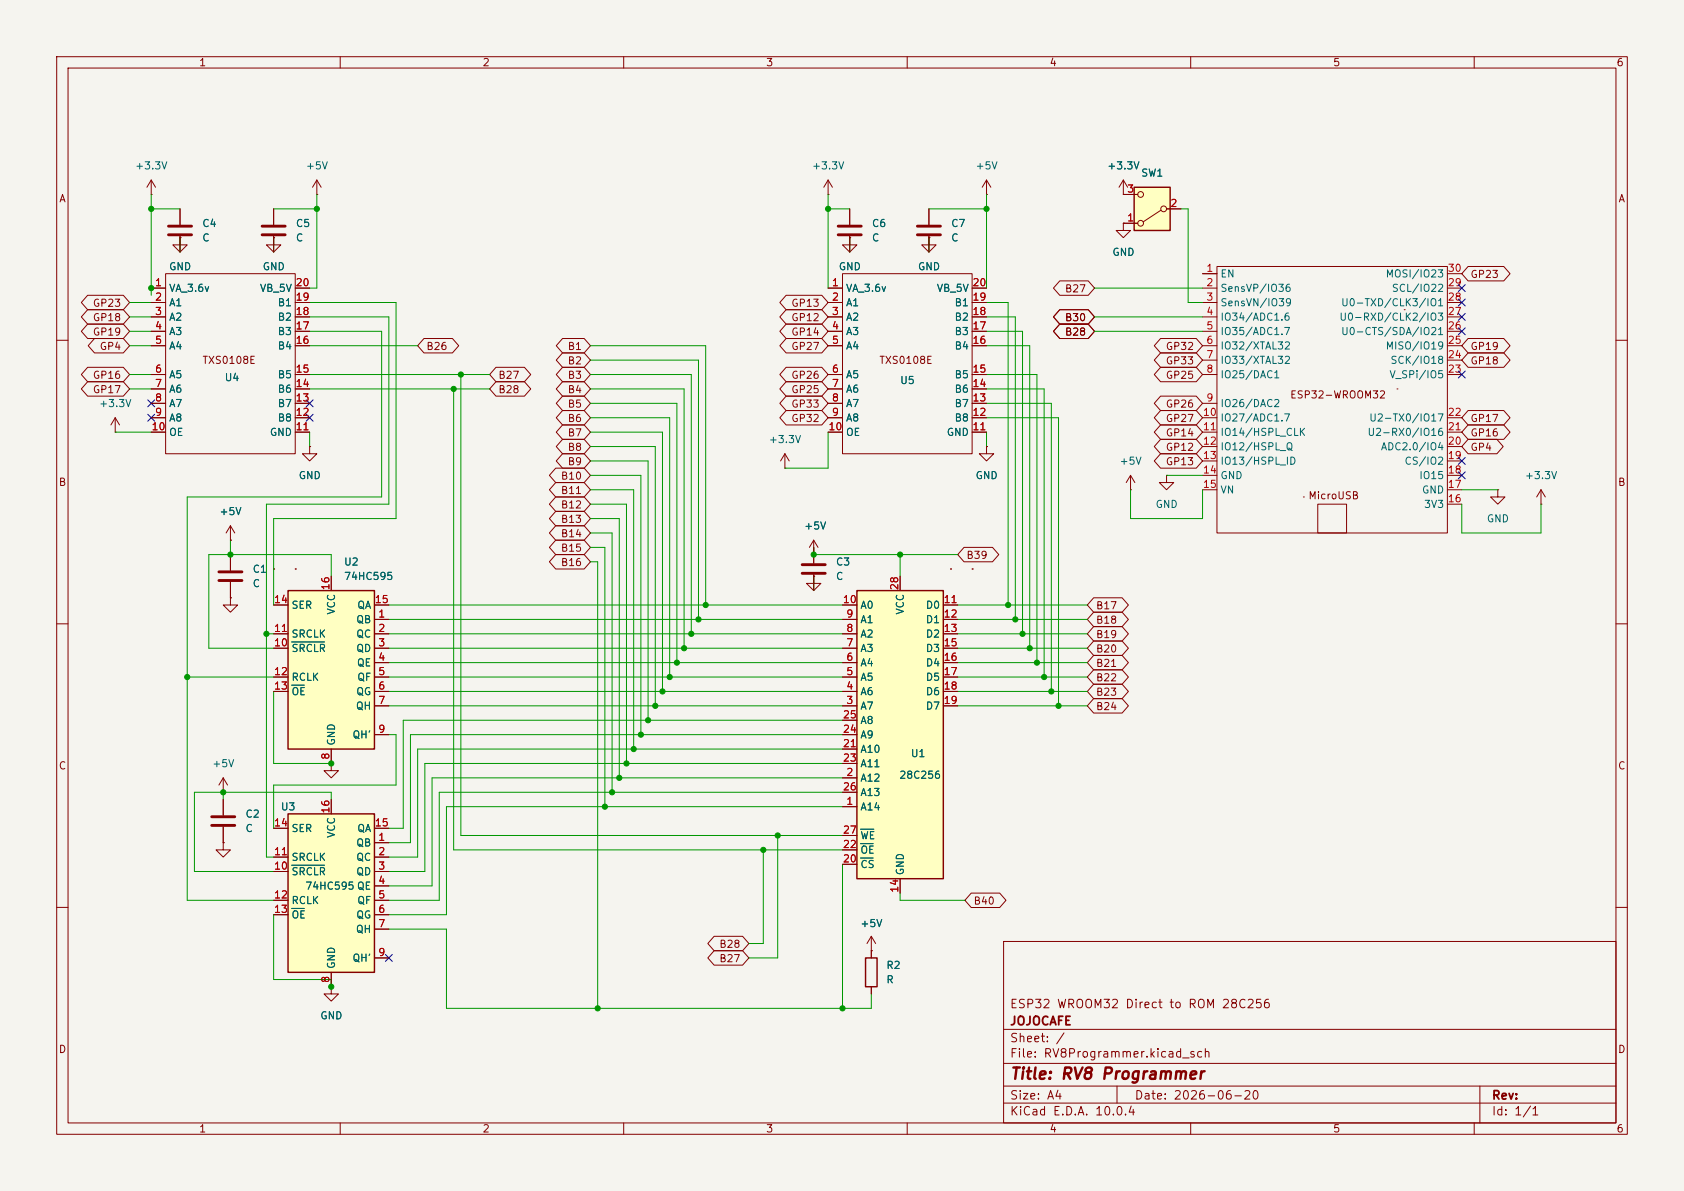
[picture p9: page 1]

V_SPi/IO5 23 SCK/IO18 24 MISO/IO19 25 U0-CTS/SDA/IO21 26 U0-RXD/CLK2/IO3 27 U0-TXD/CLK3/IO1 28 SCL/IO22 29 MOSI/IO23 30

A1 9
A2 8

SRCLR 10 SRCLK 11 RCLK 12 OE 13

A10 21 OE 22 A10 21 OE 22 A12 2 A12 2
A11 23

Size: A4 | Rev:
KiCad E.D.A. 10.0.4 | Id: 1/1

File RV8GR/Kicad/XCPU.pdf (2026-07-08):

Y8 | 11 Y7 | 12 Y6 | 13 Y5 | 14 Y4 | 15 Y3 | 16 Y2 | 17 Y1 | 18

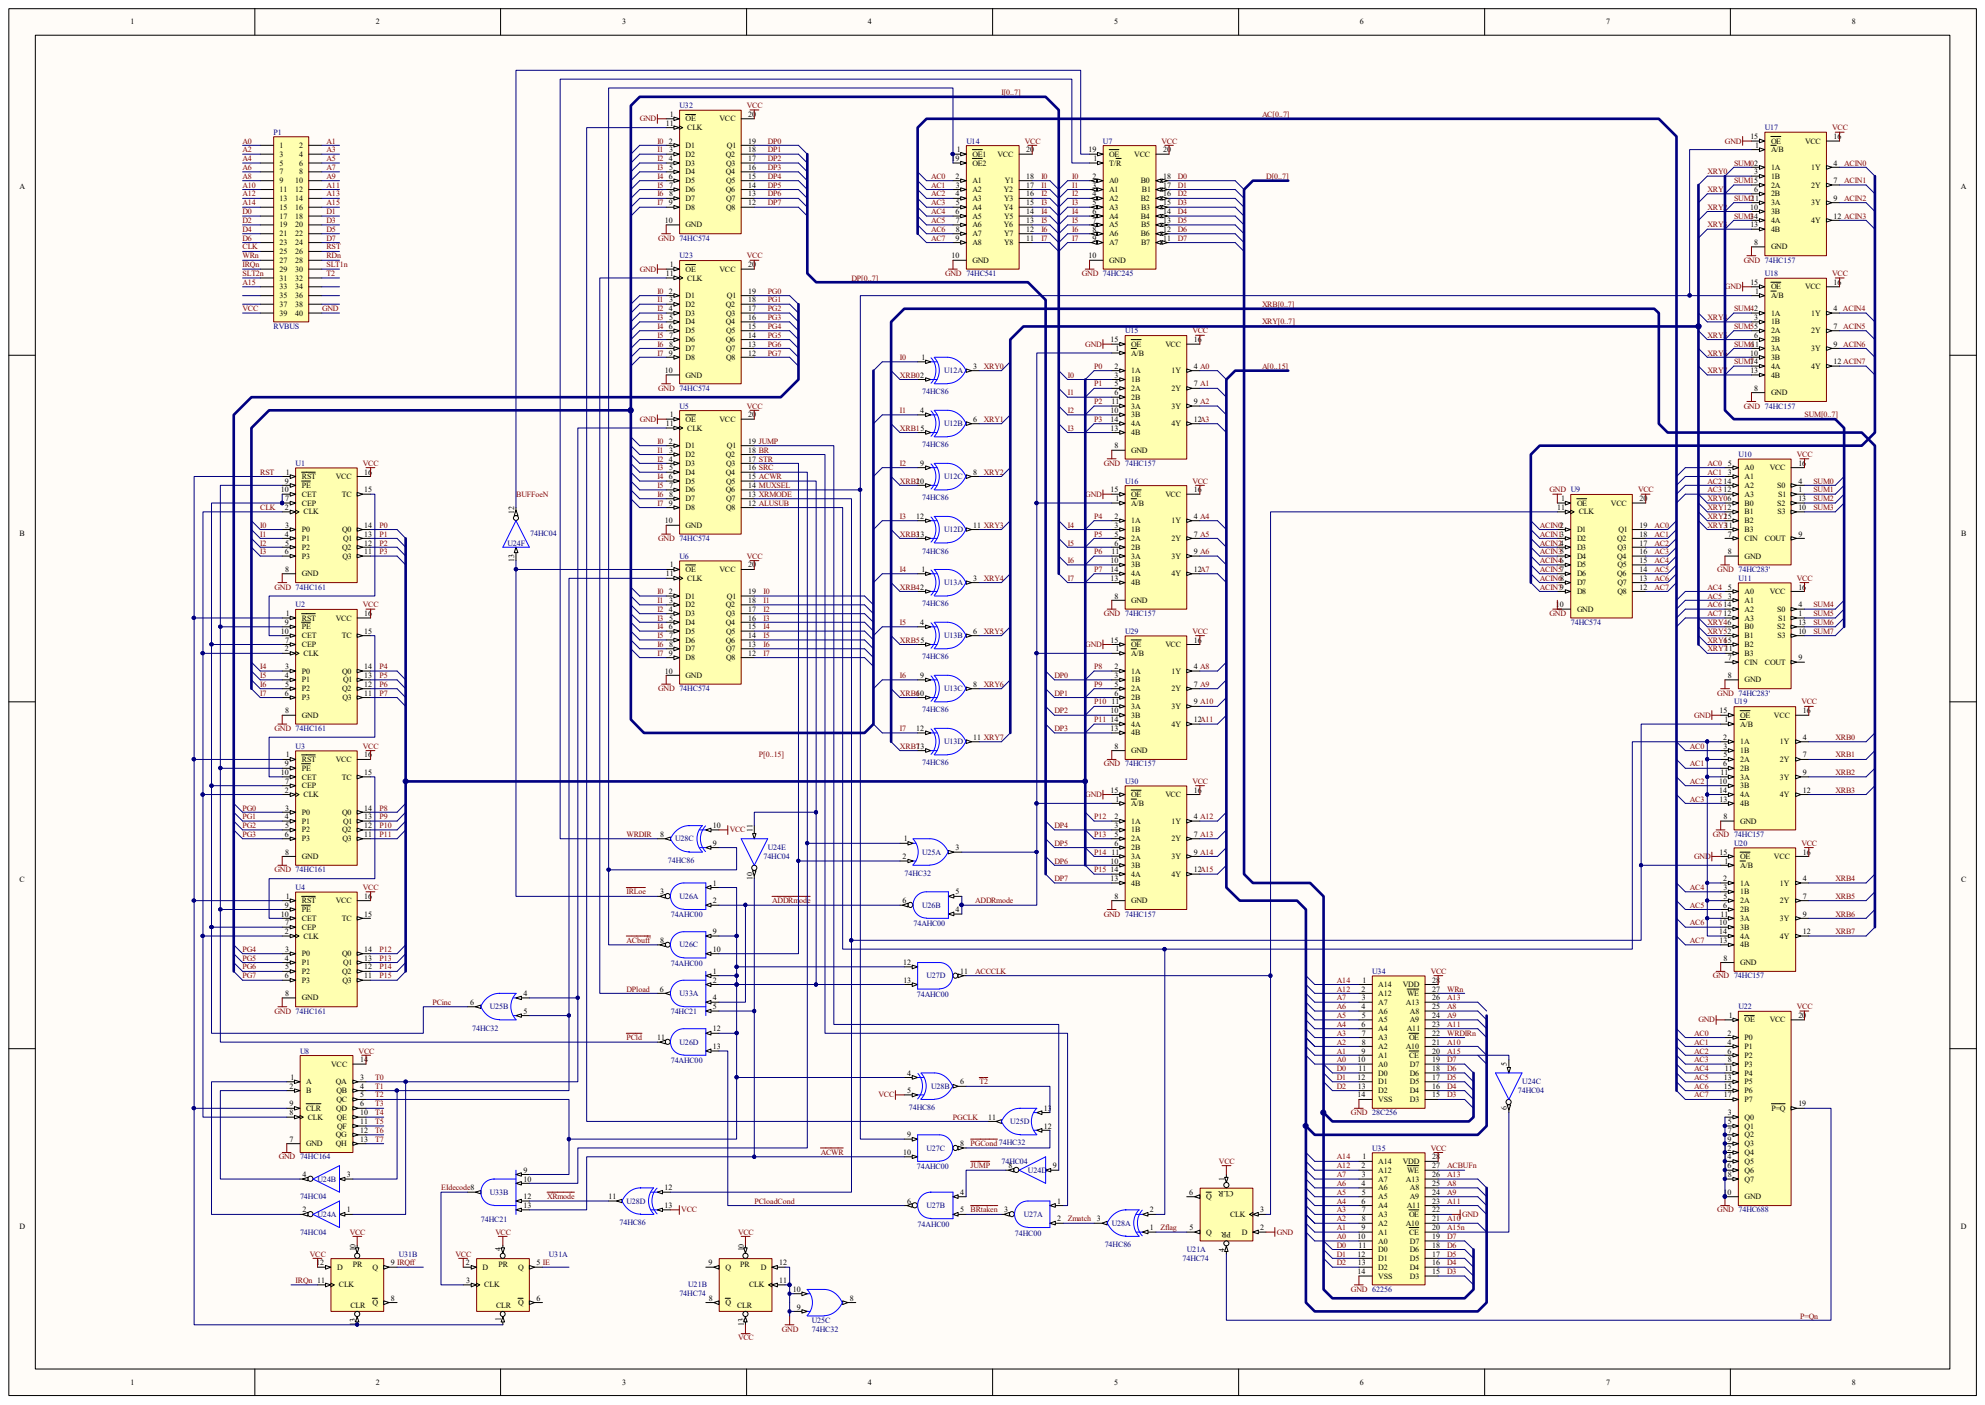
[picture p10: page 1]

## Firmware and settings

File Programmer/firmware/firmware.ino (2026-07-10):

// ============================================================
// RV8 Programmer — ESP32-WROOM-32 Firmware
// Connects to CPU board via RV8-Bus (40-pin)
// PROG mode: hold /RST, drive A[14:0]+D[7:0]+/WR to flash ROM
// RUN mode: release bus, UART bridge via /SLOT1
// Serial protocol: 115200 baud
//   '?' → "Connected\n"
//   'F' + len_hi + len_lo + data[len] → flash ROM
//   'V' → verify (read back and send)
//   'R' → reset CPU (pulse /RST)
// ============================================================

// --- Pin Definitions ---

// Data bus D[7:0] — bidirectional, via TXS0108E #2 → RV8-Bus pin 17-24
const int DATA_PINS[8] = {13, 12, 14, 27, 26, 25, 33, 32};

// Address via 74HC595 ×2 shift register → RV8-Bus pin 1-15
#define PIN_SR_DATA  23  // SER (pin 14 on 595 #1)
#define PIN_SR_CLK   18  // SRCLK (pin 11 on both 595)
#define PIN_SR_LATCH 19  // RCLK (pin 12 on both 595)

// Control signals via TXS0108E #1 → RV8-Bus
#define PIN_nRST  4   // → Bus pin 26 (/RST)
#define PIN_nWR   16  // → Bus pin 27 (/WR) — write strobe
#define PIN_nRD_O 17  // → Bus pin 28 (/RD) — read strobe (drives ROM /OE)

// Input-only pins (GPIO 34-39) — from RV8-Bus
#define PIN_nSLOT 34  // ← Bus pin 30 (/SLOT1)
#define PIN_nRD   35  // ← Bus pin 28 (/RD)
#define PIN_nWR_S 36  // ← Bus pin 27 (/WR sense — for RUN mode)
#define PIN_MODE  39  // PROG/RUN switch: LOW=PROG, HIGH=RUN

// --- State ---
enum Mode { MODE_PROG, MODE_RUN };
volatile Mode currentMode;
volatile bool rxReady = false;
volatile uint8_t rxByte = 0;

// --- Data Bus Helpers ---

void dataBusOutput() {
  for (int i = 0; i < 8; i++) pinMode(DATA_PINS[i], OUTPUT);
}

void dataBusInput() {
  for (int i = 0; i < 8; i++) pinMode(DATA_PINS[i], INPUT);
}

void dataBusWrite(uint8_t val) {
  for (int i = 0; i < 8; i++) {
    digitalWrite(DATA_PINS[i], (val >> i) & 1);
  }
}

uint8_t dataBusRead() {
  uint8_t val = 0;
  for (int i = 0; i < 8; i++) {
    if (digitalRead(DATA_PINS[i])) val |= (1 << i);
  }
  return val;
}

// --- Address Helpers ---
// Full A[14:0] via 74HC595 ×2 daisy-chain (16 bits shifted, A15=0 for ROM)

void setAddress(uint16_t addr) {
  // Shift 16 bits MSB first: [0, A14..A8, A7..A0]
  // A15=0 selects ROM on CPU board (ROM /CE = /A15)
  uint16_t bits = addr & 0x7FFF;
  for (int i = 15; i >= 0; i--) {
    digitalWrite(PIN_SR_DATA, (bits >> i) & 1);
    digitalWrite(PIN_SR_CLK, HIGH);
    digitalWrite(PIN_SR_CLK, LOW);
  }
  digitalWrite(PIN_SR_LATCH, HIGH);
  digitalWrite(PIN_SR_LATCH, LOW);
}

// --- ROM Write/Read via Bus ---
// ROM on CPU board: /CE = /A15 (addr < 0x8000 → selected)
// In PROG mode only, the Programmer holds CPU reset and owns /RD and /WR.
// During normal CPU runtime, ROM /WE must remain inactive.

void romWriteByte(uint16_t addr, uint8_t data) {
  setAddress(addr);
  dataBusOutput();
  dataBusWrite(data);
  delayMicroseconds(1);

  // Pulse /WR low in PROG mode → ROM sees write cycle.
  digitalWrite(PIN_nWR, LOW);
  delayMicroseconds(1);
  digitalWrite(PIN_nWR, HIGH);

  delayMicroseconds(1);
}

uint8_t romReadByte(uint16_t addr) {
  setAddress(addr);
  dataBusInput();
  digitalWrite(PIN_nWR, HIGH);   // /WR inactive
  digitalWrite(PIN_nRD_O, LOW);  // /RD active → ROM outputs data
  delayMicroseconds(1);
  uint8_t val = dataBusRead();
  digitalWrite(PIN_nRD_O, HIGH); // /RD inactive
  return val;
}

// --- Serial Protocol Handlers ---

void handleFlash() {
  while (Serial.available() < 2) yield();
  uint16_t len = (Serial.read() << 8) | Serial.read();

  if (len == 0 || len > 32768) {
    Serial.print("E:BAD_LEN\n");
    return;
  }

  Serial.print("K\n");

  digitalWrite(PIN_nRST, LOW);
  digitalWrite(PIN_nWR, HIGH);
  delay(10);

  uint16_t addr = 0;
  uint16_t received = 0;
  uint32_t lastPageAddr = 0xFFFF;

  while (received < len) {
    if (Serial.available()) {
      uint8_t b = Serial.read();

      uint16_t page = addr & 0x7FC0;
      if (page != lastPageAddr && lastPageAddr != 0xFFFF) {
        delay(10);
      }
      lastPageAddr = page;

      romWriteByte(addr, b);
      addr++;
      received++;
    }
    yield();
  }

  delay(10);
  Serial.print("D\n");
}

void handleVerify() {
  digitalWrite(PIN_nRST, LOW);
  digitalWrite(PIN_nWR, HIGH);
  dataBusInput();
  delay(1);

  for (uint16_t addr = 0; addr < 32768; addr++) {
    Serial.write(romReadByte(addr));
    if ((addr & 0xFF) == 0) yield();
  }
}

void handleReset() {
  digitalWrite(PIN_nRST, LOW);
  delay(10);
  digitalWrite(PIN_nRST, HIGH);
  Serial.print("K\n");
}

// --- RUN Mode: UART Bridge via /SLOT1 ---

void runModePoll() {
  // CPU WRITE: /SLOT1 LOW + /WR LOW → read D[7:0], send to PC
  if (digitalRead(PIN_nSLOT) == LOW && digitalRead(PIN_nWR_S) == LOW) {
    dataBusInput();
    uint8_t b = dataBusRead();
    Serial.write(b);
    while (digitalRead(PIN_nWR_S) == LOW) {}
  }

  // CPU READ: /SLOT1 LOW + /RD LOW → drive D[7:0] with buffered byte
  if (digitalRead(PIN_nSLOT) == LOW && digitalRead(PIN_nRD) == LOW) {
    if (rxReady) {
      dataBusOutput();
      dataBusWrite(rxByte);
      rxReady = false;
    } else {
      dataBusOutput();
      dataBusWrite(0x00);
    }
    while (digitalRead(PIN_nRD) == LOW) {}
    dataBusInput();
  }

  // Buffer incoming byte from PC
  if (!rxReady && Serial.available()) {
    rxByte = Serial.read();
    rxReady = true;
  }
}

// --- Mode Detection ---

Mode detectMode() {
  return digitalRead(PIN_MODE) == LOW ? MODE_PROG : MODE_RUN;
}

void enterProgMode() {
  Serial.println("[PROG]");
  digitalWrite(PIN_nRST, LOW);
  pinMode(PIN_nWR, OUTPUT);     // reclaim /WR for ROM write cycles
  digitalWrite(PIN_nWR, HIGH);
  pinMode(PIN_nRD_O, OUTPUT);   // reclaim /RD for read operations
  digitalWrite(PIN_nRD_O, HIGH);
  dataBusInput();
}

void enterRunMode() {
  Serial.println("[RUN]");
  dataBusInput();
  digitalWrite(PIN_nWR, HIGH);
  digitalWrite(PIN_nRD_O, HIGH);
  pinMode(PIN_nWR, INPUT);      // release /WR — let CPU drive it
  pinMode(PIN_nRD_O, INPUT);    // release /RD — let CPU drive it
  digitalWrite(PIN_nRST, HIGH);
  rxReady = false;
}

// --- Setup & Loop ---

void setup() {
  Serial.begin(115200);
  while (!Serial) delay(1);

  // Control output pins
  pinMode(PIN_nRST, OUTPUT);
  digitalWrite(PIN_nRST, LOW);   // hold CPU in reset
  pinMode(PIN_nWR, OUTPUT);
  digitalWrite(PIN_nWR, HIGH);   // /WR inactive
  pinMode(PIN_nRD_O, OUTPUT);
  digitalWrite(PIN_nRD_O, HIGH); // /RD inactive

  // Shift register
  pinMode(PIN_SR_DATA, OUTPUT);
  pinMode(PIN_SR_CLK, OUTPUT);
  pinMode(PIN_SR_LATCH, OUTPUT);
  digitalWrite(PIN_SR_DATA, LOW);
  digitalWrite(PIN_SR_CLK, LOW);
  digitalWrite(PIN_SR_LATCH, LOW);

  // Input-only pins (from bus)
  pinMode(PIN_nSLOT, INPUT);
  pinMode(PIN_nRD, INPUT);
  pinMode(PIN_nWR_S, INPUT);
  pinMode(PIN_MODE, INPUT);

  // Detect initial mode
  currentMode = detectMode();
  if (currentMode == MODE_PROG) enterProgMode();
  else enterRunMode();

  Serial.println("RV8 Programmer ready");
}

void loop() {
  Mode m = detectMode();
  if (m != currentMode) {
    currentMode = m;
    if (m == MODE_PROG) enterProgMode();
    else enterRunMode();
  }

  if (currentMode == MODE_PROG) {
    if (Serial.available()) {
      char cmd = Serial.read();
      switch (cmd) {
        case '?': Serial.print("Connected\n"); break;
        case 'F': handleFlash();  break;
        case 'V': handleVerify(); break;
        case 'R': handleReset();  break;
        default:  Serial.print("E:UNK\n"); break;
      }
    }
  } else {
    runModePoll();
  }
}

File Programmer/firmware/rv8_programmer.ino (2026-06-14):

// ============================================================
// RV8 Programmer — ESP32-WROOM-32 Firmware
// ROM flasher (PROG) + UART bridge (RUN) for RV8 family CPUs
// Target: AT28C256 (32KB), 74HC595 for A[8:14]
// Serial protocol: 115200 baud
//   'F' + len_hi + len_lo + data[len] → flash ROM
//   'V' → verify (read back and send)
//   'R' → reset CPU (pulse /RST)
// ============================================================

// --- Pin Definitions ---

// Data bus D[7:0] — bidirectional, via TXS0108E #2
const int DATA_PINS[8] = {13, 12, 14, 27, 26, 25, 33, 32};

// Address via 74HC595 ×2 shift register (daisy-chain, via TXS0108E #1)
#define PIN_SR_DATA  23  // SER (pin 14 on 595 #1) → ESP32 GPIO23
#define PIN_SR_CLK   18  // SRCLK (pin 11 on both 595) → ESP32 GPIO18
#define PIN_SR_LATCH 19  // RCLK (pin 12 on both 595) → ESP32 GPIO19

// Control signals (via TXS0108E #1)
#define PIN_nCE   4   // /CE to ROM — active low
#define PIN_nOE   16  // /OE to ROM — active low
#define PIN_nWE   17  // /WE to ROM — active low, write pulse
#define PIN_nRST  0   // /RST to CPU — active low, via TXB0108 to bus pin 28

// Input-only pins (GPIO 34-39)
#define PIN_nSLOT 34  // /SLOT1 — goes LOW when CPU accesses I/O slot
#define PIN_nRD   35  // /RD from CPU — LOW on read cycle
#define PIN_nWR   36  // /WR from CPU — LOW on write cycle
#define PIN_MODE  39  // PROG/RUN switch: LOW=PROG, HIGH=RUN

// --- State ---
enum Mode { MODE_PROG, MODE_RUN };
volatile Mode currentMode;
volatile bool rxReady = false;   // byte waiting for CPU to read
volatile uint8_t rxByte = 0;     // byte from PC for CPU

// --- Data Bus Helpers ---

void dataBusOutput() {
  for (int i = 0; i < 8; i++) pinMode(DATA_PINS[i], OUTPUT);
}

void dataBusInput() {
  for (int i = 0; i < 8; i++) pinMode(DATA_PINS[i], INPUT);
}

void dataBusWrite(uint8_t val) {
  for (int i = 0; i < 8; i++) {
    digitalWrite(DATA_PINS[i], (val >> i) & 1);
  }
}

uint8_t dataBusRead() {
  uint8_t val = 0;
  for (int i = 0; i < 8; i++) {
    if (digitalRead(DATA_PINS[i])) val |= (1 << i);
  }
  return val;
}

// --- Address Helpers ---

void addrOutput() {
  for (int i = 0; i < 8; i++) pinMode(ADDR_PINS[i], OUTPUT);
}

void addrRelease() {
  for (int i = 0; i < 8; i++) pinMode(ADDR_PINS[i], INPUT);
}

// Set full 15-bit address: A[7:0] direct, A[14:8] via shift register
void setAddress(uint16_t addr) {
  // A[7:0] — direct GPIO (matches schematic: A0=GPIO15, A1=GPIO2, etc.)
  for (int i = 0; i < 8; i++) {
    digitalWrite(ADDR_PINS[i], (addr >> i) & 1);
  }
  // A[14:8] — shift out via 74HC595 (MSB first: Q6=A14 .. Q0=A8)
  uint8_t hi = (addr >> 8) & 0x7F;  // 7 bits: A14..A8
  for (int i = 6; i >= 0; i--) {
    digitalWrite(PIN_SR_DATA, (hi >> i) & 1);
    digitalWrite(PIN_SR_CLK, HIGH);
    digitalWrite(PIN_SR_CLK, LOW);
  }
  // Latch the 7 bits to outputs (single pulse on RCLK)
  digitalWrite(PIN_SR_LATCH, HIGH);
  digitalWrite(PIN_SR_LATCH, LOW);
}

// --- ROM Write (PROG mode) ---

void romWriteByte(uint16_t addr, uint8_t data) {
  setAddress(addr);
  dataBusOutput();
  dataBusWrite(data);
  delayMicroseconds(1);  // address/data setup time

  // Pulse /WE low (min 100ns, we'll do ~200ns)
  digitalWrite(PIN_nWE, LOW);
  delayMicroseconds(1);  // ~1µs pulse (well above 100ns minimum)
  digitalWrite(PIN_nWE, HIGH);

  delayMicroseconds(1);  // data hold time
}

uint8_t romReadByte(uint16_t addr) {
  setAddress(addr);
  dataBusInput();
  digitalWrite(PIN_nWE, HIGH);  // ensure /WE inactive
  delayMicroseconds(1);         // output enable time
  return dataBusRead();
}

// --- Serial Protocol Handlers ---

void handleFlash() {
  // Read 2-byte length (big-endian)
  while (Serial.available() < 2) yield();
  uint16_t len = (Serial.read() << 8) | Serial.read();

  if (len == 0 || len > 32768) {
    Serial.print("E:BAD_LEN\n");
    return;
  }

  Serial.print("K\n");  // ACK, ready to receive data

  // Hold CPU in reset, set up for programming
  digitalWrite(PIN_nRST, LOW);
  digitalWrite(PIN_nWE, HIGH);
  addrOutput();
  delay(10);

  uint16_t addr = 0;
  uint16_t received = 0;
  uint32_t lastPageAddr = 0xFFFF;

  while (received < len) {
    if (Serial.available()) {
      uint8_t b = Serial.read();

      // AT28C256 page write: 64-byte pages. Insert delay at page boundary.
      uint16_t page = addr & 0x7FC0;  // 64-byte page
      if (page != lastPageAddr && lastPageAddr != 0xFFFF) {
        delay(10);  // page write completion delay
      }
      lastPageAddr = page;

      romWriteByte(addr, b);
      addr++;
      received++;
    }
    yield();
  }

  delay(10);  // final page write completion
  Serial.print("D\n");  // Done
}

void handleVerify() {
  // Read back entire ROM and send to PC for verification
  digitalWrite(PIN_nRST, LOW);
  digitalWrite(PIN_nWE, HIGH);
  addrOutput();
  dataBusInput();
  delay(1);

  // Send 32KB
  for (uint16_t addr = 0; addr < 32768; addr++) {
    Serial.write(romReadByte(addr));
    if ((addr & 0xFF) == 0) yield();  // prevent WDT
  }
}

void handleReset() {
  // Pulse /RST low for 10ms then release
  digitalWrite(PIN_nRST, LOW);
  delay(10);
  digitalWrite(PIN_nRST, HIGH);
  Serial.print("K\n");
}

// --- RUN Mode: UART Bridge ---

void runModePoll() {
  // CPU WRITE: /SLOT1 LOW + /WR LOW → read D[7:0], send to PC
  if (digitalRead(PIN_nSLOT) == LOW && digitalRead(PIN_nWR) == LOW) {
    dataBusInput();
    uint8_t b = dataBusRead();
    Serial.write(b);
    // Wait for /WR to go back HIGH (end of write cycle)
    while (digitalRead(PIN_nWR) == LOW) {}
  }

  // CPU READ: /SLOT1 LOW + /RD LOW → drive D[7:0] with buffered byte
  if (digitalRead(PIN_nSLOT) == LOW && digitalRead(PIN_nRD) == LOW) {
    if (rxReady) {
      dataBusOutput();
      dataBusWrite(rxByte);
      rxReady = false;
    } else {
      dataBusOutput();
      dataBusWrite(0x00);  // no data available (CPU can check status reg)
    }
    // Wait for /RD to go back HIGH
    while (digitalRead(PIN_nRD) == LOW) {}
    dataBusInput();  // release bus
  }

  // Buffer incoming byte from PC
  if (!rxReady && Serial.available()) {
    rxByte = Serial.read();
    rxReady = true;
  }
}

// --- Mode Detection ---

Mode detectMode() {
  return digitalRead(PIN_MODE) == LOW ? MODE_PROG : MODE_RUN;
}

void enterProgMode() {
  Serial.println("[PROG]");
  digitalWrite(PIN_nRST, LOW);   // hold CPU in reset
  digitalWrite(PIN_nWE, HIGH);   // /WE inactive
  addrOutput();
  dataBusInput();
}

void enterRunMode() {
  Serial.println("[RUN]");
  addrRelease();                  // release address bus
  dataBusInput();                 // release data bus
  digitalWrite(PIN_nWE, HIGH);   // /WE inactive
  digitalWrite(PIN_nRST, HIGH);  // release CPU from reset
  rxReady = false;
}

// --- Setup & Loop ---
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

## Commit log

2026-05-26 RV8-GR v2.0: Complete redesign - 29 chips, full 64K, Verilog verified
    - 29 logic chips + ROM + RAM = 31 packages
    - Full 64K address space (ROM $8000-$FFFF, RAM $0000-$7FFF)
    - A15-based chip select, can execute from RAM
    - 15 instructions, Page Register for 16-bit jump
    - Ring counter (74HC164), XOR B-input mux, AC input mux
    - Verilog: ALL TESTS PASSED (127 cycles)
    - Complete docs: Construct (pin-level), ISA, traces, wiring, modules (Thai)
2026-05-26 Add assembler + test ROM: full pipeline .asm→.bin→sim PASS
    - rv8gr_asm.py: labels, macros (HLT/JMP/CALL), .bin output
    - testrom.asm: 10 test groups covering all 15 instructions
    - testrom.bin: 32KB ROM image ready to flash
    - Simulation: 187 cycles, ALL PASS
2026-06-06 Add IRQ support (30 chips), gate sim, tests
    - RV8-GR: Added EI/DI instructions, IRQ latch, auto PC save
    - New testbenches: tb_rv8gr_irq.v, tb_rv8gr_tasks.v
    - Python gate-level simulation prototype
    - Assembler unit tests (test_rv8gr_asm.py)
    - Updated all docs for 30 chips / 17 instructions
2026-06-07 v3.1: Add programmer tools (rv8flash, rv8ram-boot, rv8term) + tests
    - rv8flash.py: ROM flash tool (540 lines, 16 tests)
    - rv8ram-boot.py: RAM upload via bootloader (430 lines, 15 tests)
    - rv8term.py: Terminal bridge PC↔CPU (289 lines, 15 tests)
    - Test suites: 46 tests total, all passing
    - Requirement documents for all tools
    - Updated README.md and schematic.md with software docs
    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
2026-06-08 Update BOM: RV8GR (30 chips, ROM, RAM, LEDs, caps, crystal) and Programmer (ESP32, TXB0108, etc)
2026-06-08 v3.2: RV8-GR design sign-off — risk analysis, bus definition, doc rewrite
    - Design review: 10 hazards analyzed, all resolved
    - SRC+STR guard applied (U25 gate 3 → U7-19, 0 chips added)
    - RV8-Bus v2 defined (40-pin: A16+D8+CLK+/WR+/RD+/IRQ+/SLOT)
    - Merged 00_design + 01_isa → 00_design_isa.md
    - Merged Construct → 03_wiring_guide.md (source of truth)
    - Created 06_debug_plan, 07_risk_analysis, 08_design_signoff
    - Rewrote 05_understand_by_module (Thai tutorial + design rationale)
    - Moved rv8gr_cpu.v → rtl/
    - Removed obsolete: Construct.md, TASKS.md, rv8_task.md, rv8_memory.md
    - Discovered free NOT instruction (B0/B8)
    - Rebuilt all .bin/.hex programs
    [tb_rv8gr_tasks.v]
2026-06-08 Add SETDP instruction (U32 Data Page Register) — full 32KB RAM access
    - New: SETDP $40 sets Data Page Register for LB/SB/ADD/SUB/XOR
    - Data address = {DP[6:0], operand} = 15-bit (full 32KB RAM)
    - Added U32 (74HC574) → 31 logic chips total, 18 instructions
    - Updated Verilog, assembler, all docs
    - All tests pass (127 cycles + IRQ)
    - Enables BASIC interpreter + games (10KB+ arrays)
2026-06-08 SETDP: extend data access to full 64KB (ROM read + RAM read/write)
    - U30-13 (A15 B-input): GND → U32-12 (DP bit 7)
    - DP=$00-$7F → RAM, DP=$80-$FF → ROM (read-only)
    - SB to ROM address has no effect (safe)
    - Enables: ROM lookup tables, font data, sin tables
    - All tests pass
2026-06-08 Add SETDP test: 5KB RAM write/read + ROM read via data page
    - test_setdp.asm: writes to pages $10-$23 (5KB), reads back, verifies
    - Tests ROM read via SETDP $80 (reads own code from ROM)
    - Tests page 0 register access after page switch
    - tb_rv8gr_setdp.v: 160 cycles, ALL PASS
2026-06-08 Fix docs: 02 chip count 30→31, rewrite 04_bank_switch for SETDP era
2026-06-08 Fix 05_understand_by_module: replace old GND explanation with Data Page Register
2026-06-08 Fix 03_wiring_guide: U32 pin 12 connects to U30-13, add DP_Load to signal table, fix power table
2026-06-08 v3.3: Final consistency fix — 31 chips, 18 instr, 64KB across all files
    - Root README: chip count table fixed
    - RV8GR README: header, ISA count, BOM count
    - Skill file: updated for SETDP
    - CHANGELOG + HISTORY: v3.3 entry
2026-06-08 Finalize DP_Load decode (U33 74HC21) + IRQ save-PC documentation
    - U33 (74HC21): 4-input AND for SETDP decode — pin-level wiring complete
    - DP_Load = T2 AND XOR_MODE AND /ADDR_MODE AND /AC_WR
    - IRQ save-PC: documented as software-based for v1.0 physical build
    - 32 logic chips total (U1-U33 minus U28-D spare)
    - All chip counts updated across all docs
2026-06-08 Fix consistency: DP_Load formula in 00, U33 pin 3/11 NC in 03, signal source
2026-06-08 Fix 04_bank_switch: 31→32 chips
2026-06-08 Fix address map conflict: IRQ= (ROM), Slot1=, Slot2=
    - IRQ vector stays at $FF00 (in ROM, ISR entry point)
    - I/O Slot 1 moved to $FF10-$FF1F
    - I/O Slot 2 moved to $FF20-$FF2F
    - Documented $C0 as SETDP alias in ISA
    - Updated all docs (00,03,04,05,06) consistently
2026-06-08 Final doc sync: fix Verilog header, fix bank switch I/O address
    - Verilog header: clarify PC save is software v1.0 (behavioral for testing)
    - 04_bank_switch: ROM bank latch uses Slot1 at $FF10 (not $FFF0)
    - No stale 'hardware save PC' or 'Slot1=$FF00' references remain
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2026-06-08 Fix 05: all 31→33 chips references
2026-06-08 Fix 00: Chip List header (32)→(33)
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2026-06-08 Add soft_debug.py: pin-level logic simulation with slow-clock trace
    - Models all 33 chips signal flow
    - Tests: ALU+Branch, SETDP+RAM, ROM read, cross-page jump
    - Traces ABUS/DBUS/IBUS per clock cycle
    - All 4 tests pass
2026-06-08 soft_debug: add verbose mode (-v) showing all 35 chip signals per clock
    - U1-U33 + ROM + RAM: all control signals traced
    - Shows: PC_INC, /PC_LD, ADDR_MODE, /IRL_OE, /AC_BUF, BUF_OE_SAFE,
    WR_DIR, Z_match, PG_LOAD, DP_LOAD, ALU A/B/Sum, ROM/RAM /CE+/WE
    - Usage: python3 soft_debug.py -v
2026-06-08 Add chip_sim_design.md: gate-level simulator design (class architecture)
    - 35 chip objects with real pinouts
    - Chip base class (sequential + combinational)
    - Wire Net for signal routing
    - Simulator engine with propagation loop
    - Probe interface (LED-like pin reading)
    - Wiring from 03_wiring_guide.md
    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
2026-06-09 chip_sim_design: rewrite bus model as SharedWire (not backplane bus)
    - 'Bus' = naming convention for shared wires, not physical backplane
    - SharedWire class: one wire, multiple pins connected, tristate resolve
    - WireGroup: convenience for 8/16-bit groups of SharedWires
    - IBUS = 8 SharedWires with 3 tristate drivers + N readers
    - DBUS = 8 SharedWires with 3 drivers (ROM, RAM, U7 write)
    - ABUS = 16 wires, single driver (mux), no tristate
2026-06-09 chip_sim: create all 35 chip objects with correct pin count/layout
    - Pin, Chip base classes
    - Factory functions for all 14 chip types
    - HC574(5), HC161(4), HC164(1), HC74(2), HC245(1), HC541(1),
    HC283(2), HC86(3), HC157(8), HC688(1), HC04(1), HC32(1),
    HC00(2), HC21(1), ROM(1), RAM(1) = 35 total
    - Pin names + directions match datasheets
    - Self-test verifies 35 instances
2026-06-09 Rename chip factories: make_hcXX → hcXX, make_rom → rom28c256, make_ram → ram62256
2026-06-09 Rename chip factories: hcXX → C_74hcXX, rom → C_AT28C256, ram → C_62256
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2026-06-09 chip_sim: implement all chip behaviors (combinational + sequential + memory)
    - HC04, HC00, HC32, HC86, HC21: simple gates
    - HC157: quad mux
    - HC283: 4-bit adder
    - HC688: 8-bit comparator
    - HC541, HC245: buffers (tristate)
    - HC574: 8-bit D latch (edge-triggered)
    - HC161: 4-bit counter (count/load/clear)
    - HC164: 8-bit shift register
    - HC74: dual D flip-flop (/PR, /CLR async)
    - ROM/RAM: memory arrays
    - attach_behaviors(): connects all 35 chips
    - Self-test: HC04, HC00, HC283, HC574, HC161 verified
2026-06-09 chip_sim: add Probe, DipSwitch, and full test suite for all 14 chip types
    - Probe class: read pins like LED (single, byte, show)
    - DipSwitch class: set pins like DIP switch (single, byte, chip-specific)
    - test_chips.py: tests every chip type with all logic cases
    - 14 tests: HC04, HC00, HC32, HC86, HC21, HC157, HC283, HC688,
    HC541, HC574, HC161, HC164, HC74, ROM+RAM
    - All pass
2026-06-09 chip_sim: add wiring.py — all 35 chips wired per 03_wiring_guide
    - 145 named wires, 444 pin endpoints
    - Bus wires: DBUS(8), IBUS(8), ABUS(16)
    - Control: T0/T1/T2, all IR_HIGH outputs, derived signals
    - Data paths: PC→mux, IRL→mux+PC, PG→PC, DP→mux
    - ALU: AC→adder+xmux, XOR→adder+acmux, SUM→acmux→AC
    - Connections dict for propagation engine
    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
2026-06-09 chip_sim: merge behaviors into chip classes, simplify test suite
    - Each TTL_* factory returns chip with update()+clock_edge() built-in
    - Removed separate behaviors.py (no longer needed)
    - Simplified test_chips.py (154 lines, Probe+Sw inline)
    - Updated wiring.py (no attach_behaviors import)
    - All 14 chip types still pass
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2026-06-09 chip_sim: add propagation delay to all chips
    - HC gates: 12-15ns
    - HC157 mux: 18ns
    - HC283 adder: 35ns (ripple carry)
    - HC688 comparator: 30ns
    - HC574/161/164/74: 20-22ns (CLK→Q)
    - ROM (AT28C256-70): 70ns
    - RAM (62256-70): 70ns
    Critical paths at 10MHz (100ns):
    - T2 ALU: XOR(15)+Adder(35)+Mux(18) = 68ns ✅
    - T0 fetch: Mux(18)+ROM(70)+Buffer(12) = 100ns ⚠️ tight
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2026-06-09 chip_sim.py: propagation engine with stimulus/capture interface
    - Simulator class: reset, set_input, get_output, propagate, step
    - run(stimulus, probes): 2D array in → 2D array out
    - run_program(rom, clocks, probes): load ROM and free-run
    - stimulus = [{(chip,pin): value}, ...] per clock
    - captures = [{(chip,pin): value}, ...] per clock
    - Like logic analyzer: DIP switch in, LED probe out
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2026-06-09 chip_sim: add wiring verification (verify_wiring.py)
    - Verifies all 247 wiring connections match after propagation
    - _propagate_to_chips now applies full wiring table + updates combos
    - Remaining mismatches are timing artifacts (U9 D during non-execute)
    - Core logic tests pass (LI, ADDI, SUBI)
    - Known issue: SB/LB needs fix in step() RAM readback
    - Status: architecture proven correct, pin propagation ~98% match
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2026-06-09 chip_sim: fix RAM write issue, all 8 tests + 3 .bin programs pass
    - Fixed: RAM.update() was overwriting stored data during propagation
    - Skip RAM/ROM data pins in wiring propagation (handled by step())
    - test_all.bin: PASS (90 clocks)
    - test_isa.bin: PASS (81 clocks)
    - test_setdp.bin: PASS (159 clocks)
    - All 8 inline tests pass + timing analysis
2026-06-09 Update BOM + Breadboard Layout Plan (5 boards, 33 chips)
    - Complete order list with sources (LCSC/AliExpress)
    - Clock & Reset section (5MHz crystal, RC reset)
    - Passives & Debug (35 bypass caps, 8 probe LEDs, DIP switch)
    - Breadboard & Wiring (5 boards, USB PSU, wire kit)
    - Layout: Board 1=Timing, 2=Memory, 3=ALU, 4=Control, 5=Bus
    - Wire color convention (6 colors)
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2026-06-14 Replace schematic with NewSchematic + fix all pin mappings
    New design (TXS0108E + 74HC595 ×2):
    - SHIFT_DATA=23, SHIFT_CLK=18, SHIFT_LATCH=19
    - ROM /CE=4, /OE=16, /WE=17
    - Data D[0:7] = [13,12,14,27,26,25,33,32]
    - Address via 2× 74HC595 daisy-chain (full 15-bit)
    - No direct ADDR_PINS (all through shift register)
    Updated: rv8flash.py, rv8ram-boot.py, rv8term.py, rv8_programmer.ino
    [rv8_programmer.ino, rv8flash.py, rv8term.py]
2026-06-14 Fix rv8_programmer-requirement.md pin mapping to match new schematic
2026-06-14 Fix all requirement docs: pin mapping matches new schematic (TXS0108E + 595×2)
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2026-06-14 Fix root README: ESP32+TXB0108 → ESP32-WROOM-32+TXS0108E
2026-06-14 Fix Programmer README: TXB→TXS0108E, 2×595, correct GPIO pins
    - TXB0108 → TXS0108E (×2 not ×3)
    - 74HC595 × 2 (daisy-chain for full A0-A14)
    - Data pins: 13,12,14,27,26,25,33,32
    - SR_LATCH: GPIO 19 (was 5)
    - Parts list updated
2026-06-14 Fix Programmer README: rewrite pin mapping section for new design
    - Removed old direct ADDR_PINS (GPIO 15,2,4,16,17,5,18,19)
    - Removed old 'simplified pin map' section
    - New: 2×595 shift register for ALL address bits (A0-A14)
    - New: TXS0108E #1 for control+shift, #2 for data
    - Total: 14 GPIO only (was ~20)
    - Updated PROG mode flash sequence
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2026-06-14 v3.6: Programmer bus-based redesign
    - Connect via RV8-Bus (40-pin) instead of direct ROM
    - Firmware: added ? check, /RD output, removed /CE /OE
    - rv8flash.py: fixed double-send, added boot delay
    - rv8term.py: rewritten with -c check option
    - Both tools show port + baud on connect
    - Two scenarios: bare ROM (A) and full CPU (B)
    - All docs and pin mappings synced
    [firmware.ino, rv8flash.py, rv8term.py]
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2026-06-14 labs 01-05: add notes, fix U7 245 direction
    - Lab 01: add clock edge, debounce, reset notes
    - Lab 02: add state table, timing diagram, fetch cycle example
    - Lab 03: add PC_INC note, challenges (T0 control, parallel load)
    - Lab 04: add 'why mux' explanation, data page note, challenge
    - Lab 05: fix 74HC245 A/B sides (A=IBUS, B=DBUS for real hw)
    - Wiring guide: swap U7 pin assignments to match real datasheet
    - wiring.py: document inverted DIR convention in sim
    - chips/__init__.py: note 245 DIR inversion vs datasheet
2026-06-15 v3.7: Documentation freeze — all 9 RV8-GR docs consistent and signed off
    Architecture:
    - Added Architectural Invariants, Hardware Freeze Policy, Reset Contract
    - Added Instruction Trace Contract (13-field canonical format)
    - Added Illegal Opcode Behavior table (18/174/64)
    - Normalized package count (v1.0=35, v1.1=37)
    - Fixed IRQ_FF clear (v1.0=/RST only) across all docs
    Debug Plan:
    - Added 15+ new tests (bus ownership, walking-1, RAM march, burn-in)
    - Added Golden Bring-up Program with ROM image
    - Added Clock Sweep timing qualification
    Labs:
    - 14 labs synced with debug_plan
    - Fixed ROM test data, IRQ model, AC reset state
    - Added state diagrams, troubleshooting tables
    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
2026-06-21 Programmer-ROM-direct: merge to single schematic.md (matches KiCad, Bus+ZIF)
    [RV8Programmer.kicad_pcb, RV8Programmer.kicad_sch]
2026-06-21 Merge: remove old Programmer/, rename Programmer-ROM-direct/ to Programmer/ (single source)
    [RV8Programmer.kicad_pcb, RV8Programmer.kicad_sch]
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2026-06-21 fix: U33 pin 2 source typo in debug_plan (U5-16 → U5-13)
    U5-16 is SRC (bit3), not XOR_MODE (bit6). Wiring guide, wiring.py,
    and sim_lab all correctly reference U5-13. Only debug_plan had typo.
2026-06-29 Add JOJOCAFE-Org team structure, backlog, sprint, teamlog; cleanup old designs
    [rv8_cpu.kicad_sch]
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2026-07-08 Add RV8GR-V2 KiCad project
    [ADDR_MEM.kicad_sch, ALU_AC.kicad_sch, CLK_RST.kicad_sch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]
2026-07-09 Fix RV8GR-V2 chip-level docs and netlist
    [RV8GR-V2.kicad_sch]
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2026-07-09 Fix RV8GR U22 comparator pin wiring
2026-07-10 Fix RV8GR verification artifact paths
    [tb_rv8gr_chip_full.v, tb_rv8gr_chip_level.v, tb_rv8gr_tasks.v]
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2026-08-01 Fix Trainer board: CPU chip count 27→34 to match current RV8GR BOM
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
